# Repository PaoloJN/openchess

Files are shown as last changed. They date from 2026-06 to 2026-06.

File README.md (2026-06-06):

# OpenChess

A physical chess board with magnetic piece detection and corner-LED move
feedback. Plays online via Lichess and offline against Stockfish. ESP32-
powered, LiPo-battery / USB-C, with an SSD1306 OLED + 3 panel-mount
buttons for local UI.

**This is a one-off personal learning project, not a product.** The goal
is to learn through hands-on PCB design and build **one** chess board
that works first try. When it works on Paolo's desk, the project is done
— no v2, no scaling, no support burden. Design choices optimize for
first-build reliability and learning value over BOM cost, ergonomics for
volume, or production manufacturability.

This file is the project-level source of truth and entry point. For the
authoritative hardware design see [`hardware/DESIGN_NOTES.md`](hardware/DESIGN_NOTES.md);
for current progress see [`STATUS.md`](STATUS.md).

Last meaningful revision: **2026-06-06**.

---

## 1. What it does

| Capability | How |
|---|---|
| Detect pieces | 64× A3144 Hall sensors in an 8×8 grid under the playing surface; every piece carries a magnet |
| Indicate moves | 81× WS2812B RGB LEDs at the corners of the squares (9×9 grid) |
| Online play | Lichess Board API over WiFi |
| Offline play | Stockfish bot running on the ESP32 |
| Local UI | SSD1306 0.96" 128×64 OLED + 3 panel-mount buttons (POWER, MODE, SELECT) |
| Web UI | Captive-portal WiFi setup + web admin from the ESP32 (firmware feature) |
| Power | 1S LiPo (1500 mAh, protected) with USB-C charging via Seeed Lipo Rider Plus module |

---

## 2. System architecture

```
┌──────────────────────────────────────────────────────────────────┐
│                       MATRIX PCB (chessboard)                    │
│                                                                  │
│   front face:   64× A3144 Hall  +  81× WS2812B corner LEDs       │
│   back face:    J_CTRL (2×13 keyed socket)                       │
│                                                                  │
│                              ▲                                   │
│         board-to-board stack │  (no ribbon cable)                │
│                              ▼                                   │
│                                                                  │
│   ┌─────────────────────────────────────────────────────────┐    │
│   │                   CONTROLLER PCB                        │    │
│   │                                                         │    │
│   │   J_MAIN (2×13 keyed header)                            │    │
│   │   ESP32-DevKitC v4 socket                               │    │
│   │   M1 Seeed Lipo Rider Plus (USB-C + LiPo + 5V + 3V3)    │    │
│   │   U3 74AHCT125 level shifter                            │    │
│   │   U6 TBD62783A 8-ch column driver                       │    │
│   │   D2 SS14 Schottky (ESP32 power path)                   │    │
│   │   R1..R8 row pullups · R14/R15/C12 VBAT_MON divider     │    │
│   │   J3 (J_PANEL, JST XH 10-pin)                           │    │
│   └────────────────┬────────────────────────────┬───────────┘    │
│                    │                            │                │
│                    │ JST PH                     │ JST XH 10      │
│                    ▼                            ▼                │
│              ┌──────────┐         ┌─────────────────────────┐    │
│              │ LiPo 1S  │         │   PANEL COMPONENTS      │    │
│              │ 1500 mAh │         │   (flying leads, no PCB)│    │
│              │ protected│         │   OLED · POWER · MODE · │    │
│              └──────────┘         │   SELECT · USB-C        │    │
│                                   └─────────────────────────┘    │
│                                                                  │
└──────────────────────────────────────────────────────────────────┘
```

Two PCBs + one cable-mounted component group. The controller PCB
stacks directly underneath the matrix PCB via mating 2×13 connectors
(no ribbon cable); 4× M3 corner standoffs hold the stack at ~11 mm
spacing. The LiPo battery sits alongside the controller in the space
between the matrix back and the enclosure floor. Panel components are
panel-mount parts on flying leads, mounted in the enclosure side wall.

A visual rendering of the assembly lives at
[`docs/images/system-overview.html`](docs/images/system-overview.html).

---

## 3. Hardware

| Subsystem | Path | Summary |
|---|---|---|
| Matrix PCB | [`hardware/hardware-board/`](hardware/hardware-board/) | Passive: 64× A3144 + 81× WS2812B + per-LED caps + row bulk caps + entry cap + J_CTRL. 236 components. **Script-generated** schematic. |
| Controller PCB | [`hardware/hardware-controller/`](hardware/hardware-controller/) | Active: ESP32 socket, Lipo Rider Plus power module, 74AHCT125 level shifter, TBD62783A column driver, Schottky power-path diode, pullups, divider, connectors. **Hand-drawn** in KiCad GUI. |
| Panel components | (no PCB) | SSD1306 OLED module + 3× 12 mm panel-mount pushbuttons + USB-C panel-mount extension cable, on a flying-lead harness to the controller's J_PANEL. |

The **authoritative hardware design** lives in
[`hardware/DESIGN_NOTES.md`](hardware/DESIGN_NOTES.md). Highlights:

- **Connector contracts**: 2×13 keyed IDC for matrix↔controller, JST XH
  10-pin for controller↔panel — pin-by-pin tables in DESIGN_NOTES §3.
- **Power**: single Seeed Lipo Rider Plus module ($4) handles USB-C
  charging, 5V/2.4A boost, and 3V3/250mA — see DESIGN_NOTES §7.
- **GPIO map**: full table in [`docs/gpio-map.md`](docs/gpio-map.md).
- **BOM**: high-level in DESIGN_NOTES §9, prototype shopping list in
  [`docs/bom.md`](docs/bom.md).

---

## 4. Firmware

Forked from [joojoooo/OpenChess](https://github.com/joojoooo/OpenChess),
adapted for this board's 9×9 corner-LED layout and split-board IO. Runs
on the ESP32-DevKitC via PlatformIO.

What works unchanged upstream:

- Hall sensor matrix scan (rewired to our row/column nets)
- Lichess Board API client
- Stockfish bot
- WiFi captive portal + web admin
- OTA firmware updates
- Move history persistence to flash

What we adapt:

- LED count: 64 (squares) → 81 (corners), `board_driver.cpp`
- LED chain mapping: square-centered → corner-grid
- GPIO assignments: match [`docs/gpio-map.md`](docs/gpio-map.md)
- Display layer: 3 status LEDs → SSD1306 OLED via I²C
- Buttons: re-mapped to POWER / MODE / SELECT semantics
- Battery state-of-charge: ADC read on GPIO34 via the R14/R15 divider

See [`firmware/README.md`](firmware/README.md) for setup, build, and
adaptation notes.

---

## 5. Mechanical / enclosure

Enclosure CAD has not started — see [`mechanical/README.md`](mechanical/README.md)
for current state. Constraints from the hardware design:

- 4× M3 mounting holes per PCB; ~11 mm standoffs between matrix and
  controller.
- Side-wall cutouts: 1× transparent window for the OLED (~27×27 mm),
  3× 12 mm holes for the panel buttons, 1× rectangular cutout for a
  USB-C panel-mount jack (~10×8 mm), 1× pinhole or recessed access to
  the DevKitC's EN reset button, 1× cutout or removable panel for the
  DevKitC's micro-USB programming port.
- LiPo pouch (~50×35×6 mm for 1500 mAh) sits in the gap between the
  matrix back and the enclosure floor.

Magnet selection + chess piece assembly are open questions — to be
resolved with a 4×4 mini-matrix prototype before committing the full 8×8
fab.

---

## 6. Repository layout

```text
openchess/
├── README.md                  ← this file
├── STATUS.md                  ← current phase + next actions
├── CLAUDE.md                  ← durable project context for agents
├── WORKSPACE.md               ← workspace conventions
│
├── hardware/
│   ├── DESIGN_NOTES.md        ← authoritative hardware design
│   ├── README.md
│   ├── hardware-board/        ← matrix PCB (script-generated)
│   │   ├── SCHEMATIC_GUIDE.md
│   │   └── scripts/sch/
│   └── hardware-controller/   ← controller PCB (hand-drawn)
│       └── SCHEMATIC_GUIDE.md
│
├── firmware/
│   ├── README.md
│   ├── platformio.ini
│   └── src/
│
├── mechanical/
│   ├── README.md
│   ├── case/
│   ├── pieces/
│   └── fab/
│
├── docs/
│   ├── README.md
│   ├── assembly.md
│   ├── bom.md
│   ├── design-decisions.md
│   ├── gpio-map.md
│   ├── inter-board-connector.md
│   ├── kicad-routing-playbook.md
│   ├── images/
│   │   └── system-overview.html
│   └── archive/
│
└── references/                ← upstream projects + datasheets
```

---

## 7. Where to look

| If you want to… | Read this |
|---|---|
| See current progress + next actions | [`STATUS.md`](STATUS.md) |
| Understand the hardware design | [`hardware/DESIGN_NOTES.md`](hardware/DESIGN_NOTES.md) |
| Build the controller schematic | [`hardware/hardware-controller/SCHEMATIC_GUIDE.md`](hardware/hardware-controller/SCHEMATIC_GUIDE.md) |
| Reference matrix board components | [`hardware/hardware-board/SCHEMATIC_GUIDE.md`](hardware/hardware-board/SCHEMATIC_GUIDE.md) |
| Check connector pinouts | [`docs/inter-board-connector.md`](docs/inter-board-connector.md) |
| Check ESP32 pin assignments | [`docs/gpio-map.md`](docs/gpio-map.md) |
| Buy prototype parts | [`docs/bom.md`](docs/bom.md) |
| Read fixed design decisions | [`docs/design-decisions.md`](docs/design-decisions.md) |
| Layout / routing playbook | [`docs/kicad-routing-playbook.md`](docs/kicad-routing-playbook.md) |
| Build + assembly walkthrough | [`docs/assembly.md`](docs/assembly.md) |
| Visualize the assembly | [`docs/images/system-overview.html`](docs/images/system-overview.html) |
| Set up firmware build | [`firmware/README.md`](firmware/README.md) |
| Brief an agent session | [`CLAUDE.md`](CLAUDE.md) |

---

## 8. Build & assembly workflow

High level — full per-step instructions live in
[`docs/assembly.md`](docs/assembly.md).

1. **Source parts** — see DESIGN_NOTES §9. Long-lead items: Seeed Lipo
   Rider Plus, protected 1S LiPo, ESP32-DevKitC v4, A3144 (×64),
   WS2812B (×81), TBD62783A.
2. **Verify schematics ERC-clean** — matrix board via its scripts;
   controller hand-drawn in KiCad GUI.
3. **Lay out PCBs** — see [`docs/kicad-routing-playbook.md`](docs/kicad-routing-playbook.md).
   Consider panelizing the two PCBs onto one JLCPCB order to share fab
   cost.
4. **Fab + assemble** — JLCPCB SMD assembly for matrix components; hand-
   solder the Lipo Rider Plus module and DevKitC sockets on the
   controller (JLC doesn't assemble modules).
5. **Bring-up** — power the controller alone first, verify rails, then
   stack with the matrix. Smoke-test one matrix column before scanning
   the full 8×8.
6. **Flash firmware** — see [`firmware/README.md`](firmware/README.md).
   Adapt LED count + GPIO map.
7. **Validate** — 4×4 mini-matrix prototype first (open question, see
   STATUS.md) before committing the full 8×8 if magnet selection or
   scan timing is uncertain.

---

## 9. Status

For current phase, in-progress work, and next concrete actions, see
[`STATUS.md`](STATUS.md). For the design-affecting change log with
dates, see [`hardware/DESIGN_NOTES.md`](hardware/DESIGN_NOTES.md) §15.

---

## 10. Inspiration

- [Olivier Mercier's chessboard project](https://omerc.github.io/) — the
  physical smart-board concept this is loosely modeled on.
- [joojoooo/OpenChess](https://github.com/joojoooo/OpenChess) — firmware
  ancestor.

This redesign keeps the physical smart-board idea while using Hall
sensors, addressable LEDs, and a modular hardware split (matrix +
controller + flying-lead panel) to reduce PCB risk and make per-
subsystem testing easier.

---

## 11. License

Mixed license:
- Hardware (KiCad projects, schematics, board files): **CERN-OHL-S v2**
- Firmware: upstream's license (initially MIT from joojoooo/OpenChess)
- Documentation: **CC-BY-4.0**

See the `LICENSE-*` files at the repository root.

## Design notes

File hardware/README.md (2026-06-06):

# OpenChess Hardware

Clean split-board hardware workspace.

```text
hardware-board/      matrix board: Hall sensors, WS2812 LEDs, connector
hardware-controller/ controller board: ESP32, power, drivers, panel connector
hardware-control-panel/ physical side panel: buttons + status LEDs
```

The old top-level hardware projects were archived to
`../delete/old-hardware-2026-06-04/`.

Start with [DESIGN_NOTES.md](DESIGN_NOTES.md), then use each board's
`scripts/README.md` for generation steps.

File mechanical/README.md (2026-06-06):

# Mechanical

Mechanical work for the enclosure and magnetic chess pieces.

Current hardware is split into three boards:

- matrix board under the playing surface
- controller board in a serviceable enclosure area
- control panel mounted on the side by cable

Detailed CAD has not started. Use `hardware/DESIGN_NOTES.md` and the final PCB
layouts once available as the mechanical source of truth.

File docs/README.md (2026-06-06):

# OpenChess Docs

Active docs are for the current split-board hardware under `hardware/`.
Historical rev0.1 integrated-board notes live under `docs/archive/`.

## Active Docs

| File | Purpose |
|---|---|
| `../STATUS.md` | Current project state and next steps |
| `../hardware/DESIGN_NOTES.md` | Hardware decisions and board contracts |
| `inter-board-connector.md` | Matrix and control-panel connector pinouts |
| `gpio-map.md` | Provisional ESP32 GPIO plan |
| `bom.md` | Prototype BOM by board |
| `assembly.md` | Current expected build order |
| `design-decisions.md` | Why the design uses this architecture |
| `kicad-routing-playbook.md` | PCB layout/routing notes for the split boards |

## Archived Docs

`archive/rev0.1/` contains old single/integrated-board reviews and walkthroughs.
`archive/superpowers/` contains old generated plans and specs from prior directions.
Keep archived docs for history, but do not treat them as active implementation guidance.

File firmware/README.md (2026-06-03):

# Firmware

This directory will hold a fork of [joojoooo/OpenChess](https://github.com/joojoooo/OpenChess) adapted for the openchess PCB.

## Status

Not yet populated. See top-level `STATUS.md` for current project phase.

## Setup (when ready)

```bash
cd firmware/
git clone https://github.com/joojoooo/OpenChess.git .
# or, once forked:
# git submodule add https://github.com/<your-user>/OpenChess.git
```

## What needs adapting from upstream

joojoooo's `BoardDriver` assumes **64 LEDs under squares** (8×8). This board has **81 LEDs at corners** (9×9). Modify in `src/board_driver.h` and `src/board_driver.cpp`:

- `LED_PIN` → GPIO 32 (see `docs/gpio-map.md`)
- `NUM_ROWS`, `NUM_COLS` → 9, 9
- `LED_COUNT` → 81
- `ledIndexMap` / `DefaultRowColToLEDindexMap` → corner-grid mapping

Pin assignments are runtime-configurable via the web UI, so the GPIO map can be set after first boot rather than at compile time.

## What works upstream with no changes

- Hall sensor matrix scan via 74HC595 + PNP transistors
- Lichess Board API client (`chess_lichess.cpp`)
- Stockfish bot (`chess_bot.cpp`)
- ChessConnect for chess.com
- Move history persistence to flash (`move_history.cpp`)
- OTA firmware updates (`ota_updater.cpp`)
- WiFi captive portal + web UI (`wifi_manager_esp32.cpp` + `src/web/*.html`)

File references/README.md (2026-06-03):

# References

Read-only clones of upstream projects this build is derived from or compared against. Useful when working offline or for keeping the project self-contained.

**These are gitignored** — each clone has its own upstream remote and tracks its own history. They are not part of `chessboard-v2`'s git history.

## What's here

### `chessboard-v1-omercier/`

Olivier Mercier's original `Chessboard` project — the v1 design that inspired this rebuild. Reed switches + multiplexed LED matrix + separate controller box + touchscreen.

- Upstream: <https://github.com/omercier01/Chessboard>
- Useful for: the proven Lichess client firmware, the CAD reference (`Cad/circuit_ESP32.svg`, `Cad/notes.txt`), and understanding the design tradeoffs we changed in v2.

### `openchess-joojoooo/`

joojoooo's OpenChess — the firmware foundation that `firmware/` will fork from. Modern C++ codebase with persistence, OTA, web UI, full chess engine, Stockfish, ChessConnect.

- Upstream: <https://github.com/joojoooo/OpenChess>
- Useful for: reading current source while planning the 9×9 LED adaptation; cross-referencing pin assignments; checking what's runtime-configurable vs compile-time.

## Re-cloning

If `references/` is missing (fresh checkout) and you want it populated:

```bash
mkdir -p references && cd references
git clone https://github.com/omercier01/Chessboard.git chessboard-v1-omercier
git clone https://github.com/joojoooo/OpenChess.git  openchess-joojoooo
```

## Updating

These are static snapshots. To pull upstream changes:

```bash
cd references/openchess-joojoooo && git pull
cd references/chessboard-v1-omercier && git pull
```

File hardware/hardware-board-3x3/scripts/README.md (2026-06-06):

# hardware-board scripts

Scripted generators for the OpenChess **matrix board**.

This folder is also the template style for the later controller and control-panel
boards: keep board decisions in a small `config.py`, keep grid coordinates in
`geometry.py`, and put repeated KiCad S-expression mechanics in `parts.py`.

## Schematic generation

Run the schematic chunks in order:

```bash
for s in scripts/sch/[0-9][0-9]_*.py; do python3 "$s"; done
```

Each script writes one chunk to `build/sch/` and reassembles
`openchess-board.kicad_sch`.

| Script | Places |
|---|---|
| `01_skeleton.py` | Page setup, embedded symbols, functional boxes |
| `02_halls.py` | 64x A3144 Hall sensors, `U1..U64` |
| `03_leds.py` | 81x WS2812B LEDs, `D1..D81`, plus `C10..C90` decoupling |
| `04_bulks.py` | 9x row bulk caps, `C1..C9` |
| `05_j_ctrl.py` | Matrix/controller connector, `J1` |
| `06_led_decoup.py` | LED rail entry capacitor, `C91` |
| `07_test_mech.py` | Test pads, mounting holes, fiducials |
| `99_assemble.py` | Assembles existing chunks into the final schematic |

Matrix-board scope:

- Hall sensors
- Chess-square/corner LEDs
- LED decoupling and row bulk capacitance
- Matrix connector
- Test pads, mounting holes, fiducials

Not on this board:

- ESP32/controller logic
- Battery, charger, boost, switches, or controller-rail PWR_FLAGs
- Row pullups
- Status LEDs or user buttons

Those belong on the controller board or cable-mounted control-panel board.

## Shared modules

- `sch/config.py` is the electrical contract: nets, footprints, values, and
  `JCTRL_PIN_NETS`.
- `sch/geometry.py` is placement math only.
- `sch/parts.py` has reusable helpers for repeated schematic parts.
- `sch/_lib.py` is the low-level KiCad S-expression writer.

For a 4x4 prototype, make a variant by changing the matrix constants and
geometry in a copy of this structure. Do not edit generated `.sexp` chunks by
hand; change the scripts and regenerate.

## Conventions

- Close KiCad before running scripts.
- Reference designators are firmware/mechanical contracts.
- Nets connect by labels, not long schematic wires.
- Keep `+5V_LED` separate from controller logic rails.
- Matrix ERC uses schematic-only PWR_FLAGs on external `+5V_LED` and GND.
- Keep connector pinout changes in `config.JCTRL_PIN_NETS` first, then update
  controller-board scripts to match.

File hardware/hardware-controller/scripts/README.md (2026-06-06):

# hardware-controller scripts

Scripted schematic generator for the OpenChess controller board.

Run from `hardware/`:

```bash
for s in hardware-controller/scripts/sch/[0-9][0-9]_*.py; do python3 "$s"; done
```

Current generated chunks:

| Script | Places |
|---|---|
| `01_skeleton.py` | Page setup, embedded symbols, functional boxes |
| `02_j_main.py` | `J_MAIN` connector matching matrix `J_CTRL` |
| `03_row_pullups.py` | `R1..R8` 10k pullups from `S0..S7` to `+3V3` |
| `04_power_flags.py` | Schematic-only ERC flags for `+3V3`, `+5V_LED`, `GND` |
| `05_test_mech.py` | Testpoints, M3 holes, fiducials |

Pending chunks after part decisions:

- power input / charger / boost
- ESP32 module/devkit
- column drivers for `CA_PWR..CH_PWR`
- WS2812 data level shifter to `LED_DATA_5V`
- control-panel cable connector

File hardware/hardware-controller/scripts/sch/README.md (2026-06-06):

# DO NOT USE THIS DIRECTORY

These scripts are **archived and dangerous**. They use `99_assemble.py`
which **OVERWRITES** the hand-drawn `openchess-controller.kicad_sch`
file. Running any chunk script in here destroys your KiCad work.

The actual scripts are now under `../sch.DO_NOT_RUN.archived/` —
kept for reference but should never be executed.

For test-point/mounting-hole generation, use the **snippet generator**
under `../snippets/gen_test_mech.py` instead. That one generates a
separate `.kicad_sch` file you copy-paste from — it does NOT touch
the main controller schematic.

If you ever accidentally run an old chunk script:
1. The schematic is overwritten with just the chunk content
2. A backup is automatically saved to
   `openchess-controller.kicad_sch.backup_before_assemble`
3. Recover by:
   ```bash
   cp openchess-controller.kicad_sch.backup_before_assemble \
      openchess-controller.kicad_sch
   ```

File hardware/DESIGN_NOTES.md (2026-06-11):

# OpenChess Hardware Design Notes

**Source of truth.** This document captures the current, agreed-upon
design for the OpenChess hardware. Per-board build sheets live in each
board's `SCHEMATIC_GUIDE.md`; pin-level assignments live in
`docs/gpio-map.md`; cross-board cable contracts live in
`docs/inter-board-connector.md`. This file is the index and the
authoritative reference for the *design itself*.

Last meaningful revision: **2026-06-09** (paper-fit test surfaced three
issues that need addressing: 8×8 board oversized vs enclosure inner
frame, J_MAIN/J_CTRL pin-1 mirroring under board-flip, and ESP32
footprint mismatch — see §11 items 12–14).

---

## 1. What we're building

A physical chess board with magnetic piece detection and visual
feedback. Plays online via Lichess and offline against Stockfish.
Magnetic Hall sensors detect pieces; corner WS2812B LEDs indicate
moves. UI is an SSD1306 OLED + 3 panel-mount buttons. Powered by a
LiPo battery with USB-C charging.

**This is a one-off personal project**, not a product. The goal is:

- Learn through hands-on PCB design.
- Build **one** board that works first try.
- Optimize for first-build reliability over BOM cost.
- When it works on Paolo's desk, the project is done.

Design choices reflect this: we prefer well-tested daughterboard
modules over discrete switching regulators, accept higher unit cost in
exchange for lower risk, and skip "production" concerns like
manufacturability for volume, certification, or supply-chain
resilience.

**Core sensing**: 8×8 grid of DRV5032FC Hall-effect switches
(SOT-23, omnipolar) detects which squares have a magnet under them
(every chess piece carries one).

**Core display**: 9×9 grid of WS2812B RGB LEDs at the corners of the
squares; firmware lights them to indicate legal moves, threats, last
move, etc.

**Compute**: an ESP32-DevKitC v4 module (the off-the-shelf dev board)
plugged into the controller PCB via headers, runs WiFi/Bluetooth +
chess logic + UI.

---

## 2. Hardware split

**Two PCBs** + one cable-mounted component group:

```text
hardware/
├── hardware-board/         # passive matrix: 64 Halls + 81 WS2812 LEDs
└── hardware-controller/    # ESP32 socket, power, scan/driver ICs

(Panel components, no PCB)  # OLED + 3 panel-mount buttons on flying
                             # leads, mounted on the side of the enclosure
```

**Assembly layout** (decided 2026-06-05 from the user's mockup):

- Matrix PCB is the entire chessboard. Halls + LEDs on the **top face**;
  the back face is clean except for the J_CTRL stacking socket.
- Controller PCB **mounts inverted directly underneath the matrix board**
  via board-to-board stacking pin headers (J_MAIN ↔ J_CTRL). The
  controller's components (M1, U2 DevKit, U3, U6, etc.) face the
  enclosure floor; its **bare B.Cu back face faces up toward the
  matrix's B.Cu back face**. J_MAIN sits on the controller's B.Cu so
  its pins point up into the matrix's J_CTRL socket. No ribbon cable
  between them, and **no corner standoffs** — the controller hangs from
  the J_MAIN/J_CTRL mating alone, and the matrix's own mounting to the
  enclosure top frame carries the assembled weight.
- The LiPo battery sits **alongside the controller**, in the space
  between the matrix PCB's back and the enclosure floor.
- The panel components (OLED + 3 buttons + panel-mount USB-C) mount on
  **one side wall of the enclosure** via flying leads from J3 on the
  controller PCB.

**Why this split**:
- **Matrix board** is large (chess board sized) and has only passive
  parts → cheap 2-layer fab, optimized for sensor placement.
- **Controller board** has the active ICs (Lipo Rider Plus power module,
  level shifter, column driver IC, ESP32 socket) → small dense PCB.
- **Panel components live in the enclosure on flying leads** — the
  OLED module is mounted via standoffs or a 3D-printed bezel; the 3
  buttons are panel-mount pushbuttons through enclosure holes. All
  wired back to the controller's `J3` (J_PANEL) connector. No separate
  PCB.

The boards talk through two cable contracts (§3): a 26-wire ribbon
between matrix and controller, and a 10-wire harness from the
controller to the panel-mount components.

The original `hardware-control-panel/` PCB design was dropped on
2026-06-05 (panel components moved to flying leads) and archived to
`delete/hardware-control-panel-2026-06-05/`.

The older monolithic single-PCB design was archived to
`delete/old-hardware-2026-06-04/`. Do not reference that work.

---

## 3. Cross-board connector contracts

### 3.1 Matrix ↔ Controller — `J_CTRL` (matrix) ↔ `J_MAIN` (controller)

**Board-to-board stacking, 2×13 at 2.54 mm pitch. No ribbon cable.**
The controller PCB mounts **inverted** below the matrix PCB (components
facing the enclosure floor, bare B.Cu facing up). J_MAIN sits on the
controller's B.Cu, J_CTRL on the matrix's B.Cu, and they mate back-
to-back:

- **Controller side (`J_MAIN`)**: 2×13 **male pin header** on the
  controller PCB's **B.Cu (back)** face. When the controller is mounted
  upside-down under the matrix, those pins point up toward the matrix.
  Footprint: `Connector_PinHeader_2.54mm:PinHeader_2x13_P2.54mm_Vertical`
- **Matrix side (`J_CTRL`)**: 2×13 **female socket** on the matrix
  PCB's back face (B.Cu), pointing down toward the controller.
  Footprint: `Connector_PinSocket_2.54mm:PinSocket_2x13_P2.54mm_Vertical`

The two connectors mate naturally — different connector types prevent
mis-orientation. Still mark pin 1 with a silkscreen dot on both boards
for assembly clarity.

> **Matrix-side J1 pin numbering is mirrored relative to the controller's
> J1 contract.** The controller mounts **inverted** under the matrix
> (B.Cu-to-B.Cu mating), which mirrors each board's coordinate frame
> relative to the other. To keep electrical mating correct, the matrix's
> J1 footprint was manually mirrored in KiCad's PCB editor after the
> 3×3 layout script placed it (right-click J1 → Mirror → Mirror Around
> X Axis). The result: matrix J1's *pad numbers* are swapped within
> each odd-even pair vs the contract table below — e.g. matrix pin 2
> physically carries `+5V_LED`, matrix pin 1 carries `GND`, etc. The
> **nets at each physical pad position still mate correctly** with the
> controller's pin contract (controller pin 1 = `+5V_LED` after the
> flip lands on matrix pin 2 = `+5V_LED`, etc.).
>
> When reading the contract below, treat pin numbers as the controller's
> J_MAIN numbering. The matrix's J_CTRL pads carry the same nets but
> under swapped pin numbers; verify against the physical net at each
> pad in KiCad, not the pin number printed on the silkscreen.

Mechanical: **no mounting holes on either PCB and no corner standoffs**.
The board-to-board connector pair carries both signal and mechanical
load — the controller hangs from J_MAIN/J_CTRL alone. The matrix PCB
is what's actually bolted to the enclosure top frame; it supports the
controller's weight through the connector. This is acceptable because
the board pair is mated once and never unplugged in normal use, and
the controller weighs essentially nothing once the LiPo is moved
alongside it.

| Pin | Net | Direction |
|----:|-----|---|
| 1 | `+5V_LED` | controller → matrix |
| 2 | `GND` | both |
| 3 | `+5V_LED` | controller → matrix |
| 4 | `GND` | both |
| 5 | `+5V_LED` | controller → matrix |
| 6 | `GND` | both |
| 7 | `LED_DATA_5V` | controller → matrix |
| 8 | `GND` | both |
| 9 | `S0` | matrix → controller |
| 10 | `S1` | matrix → controller |
| 11 | `S2` | matrix → controller |
| 12 | `S3` | matrix → controller |
| 13 | `S4` | matrix → controller |
| 14 | `S5` | matrix → controller |
| 15 | `S6` | matrix → controller |
| 16 | `S7` | matrix → controller |
| 17 | `CA_PWR` | controller → matrix |
| 18 | `CB_PWR` | controller → matrix |
| 19 | `CC_PWR` | controller → matrix |
| 20 | `CD_PWR` | controller → matrix |
| 21 | `CE_PWR` | controller → matrix |
| 22 | `CF_PWR` | controller → matrix |
| 23 | `CG_PWR` | controller → matrix |
| 24 | `CH_PWR` | controller → matrix |
| 25 | `+5V_LED` | controller → matrix |
| 26 | `GND` | both |

Counts: 4× `+5V_LED`, 5× `GND`, 1× `LED_DATA_5V`, 8× row-sense,
8× column-power. Cable: 26-wire IDC ribbon, ≤ 20 cm preferred to limit
IR drop on `+5V_LED` and edge degradation on `LED_DATA_5V`.

### 3.2 Controller ↔ Panel components — `J_PANEL`

**1×10 polarized connector on the controller side** (recommended:
**JST XH 10-pin**). The other end of the cable terminates at the
discrete panel components (OLED module 4-wire pigtail, 3× panel-mount
button leads). There is no PCB on the panel side — see §6.

JST XH is the right pick because:
- Polarized (mechanically can't be plugged in backwards)
- Latching (won't pop out from cable flex)
- Crimp terminals for individual wires (flexible cable harness)
- Cheap (~$0.30 for the receptacle on the controller PCB)

| Pin | Net | Direction |
|----:|-----|---|
| 1 | `+3V3` | controller → panel (OLED + button pullup supply) |
| 2 | `GND` | both |
| 3 | `I2C_SDA` | bidirectional (ESP32 GPIO1 ↔ OLED) |
| 4 | `I2C_SCL` | controller → panel (ESP32 GPIO3) |
| 5 | `BTN_SELECT` | panel → controller (GPIO2, internal pullup) |
| 6 | `BTN_POWER` | panel → controller (GPIO36, external pullup on controller) |
| 7 | `BTN_MODE` | panel → controller (GPIO39, external pullup on controller) |
| 8 | `PANEL_SPARE` | reserved (was BTN_RESET — dropped) |
| 9 | `PANEL_SPARE2` | reserved |
| 10 | `GND` | both |

Buttons short their signal net to GND when pressed. `PANEL_SPARE*` pins
terminate at a single pin on the panel side — ERC will flag them as
single-pin nets; that's intentional (reserved for future expansion).

Reset is via the DevKitC's onboard EN button — no panel reset.

---

## 4. Matrix board (`hardware-board/`)

### 4.1 Scope (244 components total — 8×8; smaller scaled variant is 3×3)

| Group | Refdes range (8×8) | Refdes range (3×3) | Notes |
|---|---|---|---|
| Hall sensors | `U1..U64` | `U1..U9` | **DRV5032FC SOT-23** (TI, JLC Basic C527532). File-major: U1=A1, U_max=top-right corner. |
| WS2812B LEDs | `D1..D81` | `D1..D16` | Row-major top-down: D1=top-left, D_max=bottom-right |
| Per-LED decoupling caps (100 nF) | `C10..C90` | `C10..C25` | Number-matched to LEDs (D1↔C10, etc.) |
| Row bulk caps (47 µF) | `C1..C9` | `C1..C4` | One per row of LEDs, placed in **left margin** Y-aligned with each LED row |
| Matrix connector | `J1` (= J_CTRL) | `J1` | 2×13 female socket, board-to-board stacking on B.Cu; pin contract in §3.1 |
| Test points | `TP1..TP4` | `TP1..TP4` | `+5V_LED`, `GND`, `LED_DATA_5V`, `LED_DOUT_END` (manually placed) |
| Mounting holes | `MH1..MH4` | `MH1..MH4` | M3, four corners (manually placed) |
| Fiducials | `FID1..FID3` | `FID1..FID3` | Manually placed |

**C91 entry cap (470 µF) dropped 2026-06-08.** Row bulks provide enough capacitance — no more THT parts on the matrix board.

### 4.2 Board dimensions

`SQUARE_SIZE = 32 mm` (matches Paolo's folding chess board model — the
inner-frame cavity has 32 mm wood squares). `BOARD_MARGIN = 18 mm` from
the outermost chess-square corner to the PCB edge, intentionally 2 mm
under the model's 20 mm inner-frame margin so the PCB slides freely
inside the cavity with ~2 mm wiggle per side.

| Variant | Chess area | + 2× 18 mm margin | **Total PCB outline** | JLC tier |
|---|---|---|---|---|
| 3×3 test | 96 mm | + 36 mm | **132 × 132 mm** | ≤150×150 (~$10) |
| 8×8 full | 254 mm | + 28 mm | **282 × 282 mm** | ≤300×300 (~$30) |

The 10 mm outer fold/decorative edge of the folding board model is NOT
part of the PCB — the PCB sits inside the inner frame only.

### 4.3 Key decisions

- **DRV5032FC Hall switches** (TI, SOT-23, omnipolar, **open-drain**, 1.65–5.5 V):
  selected over the originally-planned A3144 because (a) omnipolar means
  the magnet orientation in chess pieces doesn't matter — either pole
  triggers the sensor; (b) SOT-23 is small and JLCPCBA-assembleable
  whereas A3144 in TO-92 is through-hole; (c) the pinout
  (1=VDD, 2=GND, 3=OUT) is identical to A3144, so the rest of the
  matrix routing is unchanged. The open-drain output mates correctly
  with the controller's R1..R8 pull-ups to +3V3 — sensor's 1 mA sink
  rating handles 3.3 V / 10 kΩ = 330 µA load.
- **WS2812B 5050 in row-major chain**: standard part, well-supported
  firmware libraries. Spec the exact variant (`WS2812B-2020` etc.)
  in the BOM — color order varies between sub-types (most are GRB).
- **Matrix board kept passive**: no power management, no logic. Every
  active part lives on the controller. Makes this PCB simple, robust,
  and unlikely to need revisions independent of the controller.
- **Mechanical mounting**: 4× M3 holes for chassis attach; 3× fiducials
  for assembly machine alignment if going JLCPCBA.

### 4.4 Layout conventions (PCB)

Set by `scripts/01_chess_grid.py`:

- **Hall sensors** (DRV5032FC SOT-23): at chess square centers (file × rank × 32 mm)
- **LEDs** (WS2812B): at the corners of the chess squares (LED_COLS × LED_ROWS grid)
- **LED decoupling caps** (100 nF 0805): 6 mm to the RIGHT of each LED's center (no overlap with the 5×5 mm WS2812B body)
- **Row bulks** (47 µF 1206): in the **LEFT margin**, 8 mm left of the chess area, Y-aligned with each LED row
- **J1 (J_CTRL)**: on **B.Cu** (back face), center of the bottom edge, rotated 90° (~33 mm wide × 5 mm tall), anchor shifted left by 15.24 mm so the BODY's geometric center lands at the board's X centerline

### 4.5 Maintenance approach

The matrix board's schematic is **script-generated** for halls + LEDs
+ LED decoupling caps only (see `hardware-board/scripts/sch/02_halls.py`
and `03_leds.py`). The `99_assemble.py` is a **merger** that preserves
manual additions (J1 connector, MH, FID, TP, PWR_FLAGs, row bulks) by
UUID prefix — so running scripts after editing in KiCad GUI is safe.
The PCB layout (`scripts/01_chess_grid.py`) positions halls, LEDs,
LED decoupling caps, row bulks, and J1; everything else stays where
the user dragged it.

The 3×3 test board (`hardware-board-3x3/`) is a parameterised clone
of the 8×8 with `MATRIX_COLS = MATRIX_ROWS = 3`. Use it as the
first-fab validation board before committing to the 8×8.

---

## 5. Controller board (`hardware-controller/`)

### 5.1 Scope

| Group | Refdes | Notes |
|---|---|---|
| ESP32 socket | `U2` | `Espressif_Official:ESP32-DevKitC` module symbol; mates to the 38-pin DevKitC v4 plugged into female headers |
| Matrix connector | `J1` (= J_MAIN) | 2×13 keyed IDC, mirrors J_CTRL |
| Row pullups (10 k) | `R1..R8` | `S0..S7` to `+3V3` |
| LED data series resistor (33 Ω) | `R11` | Damping on `LED_DATA_5V` output |
| Level shifter | `U3` | 74AHCT125 SOIC-14; gate A active, B/C/D tied off |
| 74AHCT125 decoupling | `C5` | 100 nF |
| Column driver IC | `U6` | **TBD62783A** 8-channel high-side P-MOSFET array, DIP-18 or SOIC-18W |
| Column driver bypass | `C11` | 100 nF |
| **Power module** | **M1** | **Seeed Lipo Rider Plus (Charger/Booster) — product 106990290** ($4 on DigiKey/Mouser). USB-C input, charges 1S LiPo, outputs 5V/2.4A and 3.3V/250mA simultaneously. Mounted as a daughterboard via 1×8 pin header on the controller PCB. Symbol: stock `Connector_Generic:Conn_01x08` with manually-labeled pin nets per the silkscreen (1=3V3, 2=EN, 3=GND, 4=5V, 5=GND, 6=BAT, 7=GND, 8=USB). Footprint: `LipoRiderPlus:MODULE_106990290` (SnapEDA model installed locally at `hardware-controller/lib/LipoRiderPlus.pretty/`). The SnapEDA symbol file is intentionally NOT installed because its pin-number-to-name mapping is reversed from the silkscreen. LiPo plugs into M1's onboard JST 2.0; USB-C charges via M1's USB-C jack. |
| ESP32 power path | `D2` | **Schottky diode (SS14)** in `D_SMA` between `+5V_LED` and DevKit pin 19 — lets the battery power the DevKit's onboard AMS1117 → ESP32 internal 3V3. Pad 2 (anode) on `+5V_LED`, pad 1 (cathode, stripe) on DevKit pin 19 (forward direction). Protects against backfeed when both USB-C and DevKit USB are plugged in simultaneously. |
| Battery monitor | `R14` (220 k), `R15` (100 k), `C12` (100 nF) | Voltage divider on M1 pin 6 (`BAT` raw battery pad). Junction at ~0.94 V (empty) to 1.31 V (full) → `VBAT_MON` → ESP32 GPIO34 (ADC1_CH6). |
| +5V_LED bulk caps | `C1, C2` | 10 µF each — at M1's 5V output entering our `+5V_LED` rail |
| Panel connector | `J3` (= J_PANEL) | 1×10 JST XH |
| Panel button pullups | `R36, R37` | 10 k for BTN_POWER, BTN_MODE (input-only GPIOs) |
| Test points | _(none placed)_ | Probe the controller's component pads or pin headers directly for bringup. M1 itself exposes 3V3/5V/GND/BAT/USB/EN on its silkscreen-labeled pads. |
| Fiducials | `FID1..FID3` | For JLCPCBA. **No mounting holes** — controller is held by J_MAIN/J_CTRL mating + matrix's enclosure mount; see §3.1 and §10.3. |

**Parts dropped** from earlier discrete power designs (BQ24074, TPS63060,
F1/D1/Q1, USB-C connector, LiPo connector, all their passives) AND from
the brief PowerBoost 1000C plan (M1 + the AP2112K LDO + C3 + C4): now
all consolidated into M1 (Lipo Rider Plus) + D2 (Schottky). Lipo Rider
Plus's 3V3 output replaces the AP2112K LDO entirely.

### 5.2 Maintenance approach

The controller schematic is being **hand-drawn in KiCad GUI**. Scripts
are archived under `scripts/sch.archived/`. Every component is
documented in `hardware-controller/SCHEMATIC_GUIDE.md` with exact
pin-by-pin connections.

---

## 6. Panel components (no PCB — flying leads)

The panel is **not a PCB**. It's three discrete components wired
directly back to the controller via the `J3` (J_PANEL) connector.
Each component is physically mounted in the enclosure wherever the
user-facing layout requires.

### 6.1 Bill of components (≈ 5 items)

| Component | Quantity | What | Mounting |
|---|---:|---|---|
| SSD1306 0.96" 128×64 I²C OLED module | 1 | Display (mode, battery, game state, menu) | M2 standoffs through the module's 4 mounting holes, OR a 3D-printed bezel with snap-fit, OR double-sided tape behind a transparent enclosure window |
| Panel-mount momentary pushbutton (12 mm tactile, e.g. PBS-110) | 3 | POWER, MODE/NAV, SELECT | Threaded shaft through a 12 mm hole in the enclosure; nut on the back. Solder leads to the two terminals on each. |
| 10-conductor stranded wire harness | 1 length (~30 cm) | Connects all panel components back to controller `J3` | Crimped JST XH receptacle on the controller end; bare leads tinned and soldered to OLED pads + button terminals on the panel end |
| JST XH 2.54 mm 10-pin housing + crimp pins | 1 set | Connector to plug into controller's `J3` | Already on hand — crimp tool not needed to buy |
| Optional: 4.7 kΩ I²C pullup resistors | 2 | If the OLED module's onboard pullups aren't enough for the 30 cm cable | Solder inline on the harness OR on the OLED's solder pads to `+3V3` |

### 6.2 Wiring map

| `J3` pin | Net | Wire goes to |
|---:|---|---|
| 1 | `+3V3` | OLED VCC pin |
| 2 | `GND` | OLED GND pin + button COM lead (if buttons share a common ground line) |
| 3 | `I2C_SDA` | OLED SDA pin |
| 4 | `I2C_SCL` | OLED SCL pin |
| 5 | `BTN_SELECT` | SW3 (SELECT) — one terminal |
| 6 | `BTN_POWER` | SW1 (POWER) — one terminal |
| 7 | `BTN_MODE` | SW2 (MODE) — one terminal |
| 8 | `PANEL_SPARE` | _(unused; leave wire unterminated or omit)_ |
| 9 | `PANEL_SPARE2` | _(unused; leave wire unterminated or omit)_ |
| 10 | `GND` | Button common (other terminal of each button shorts to this) |

In practice, each button is wired with one lead to its signal pin
(`BTN_*` on the harness) and the other lead to GND. You can chain
the GND lead between buttons or use individual GND wires; either
works.

### 6.3 UX direction

Three buttons + the OLED. The OLED shows:
- Current mode (Lichess / Stockfish / Solo / Demo)
- Game state (whose move, opponent name, clock if applicable)
- Battery state-of-charge percentage (from `VBAT_MON` ADC reading via M1 pin 6 → R14/R15 divider → GPIO34)
- WiFi / connection status
- Last move notation, menu items during navigation

Buttons:
- **POWER**: long-press toggles power state (firmware-defined)
- **MODE/NAV**: short-press cycles modes, long-press = back/cancel
- **SELECT**: confirms a menu choice

Reset is via the DevKitC's onboard EN button. The enclosure can expose
this as a recessed pinhole if needed.

### 6.4 Assembly notes

- The wire harness is the most labor-intensive part of the build —
  ~30 min to crimp 10 JST XH terminals, solder OLED pigtail, solder
  button leads. Worth it: no panel PCB to design or fab.
- Use **panel-mount buttons** (PBS-110 or similar 12 mm tactile with
  threaded shaft + nut), not SMD/THT tactile buttons. They're designed
  to mount through an enclosure hole with screw retention.
- The OLED module has a fixed pin order on its 4-pin header. **Verify
  the module's pin order before wiring** — cheap modules ship as
  `VCC/GND/SCL/SDA` or `GND/VCC/SCL/SDA`. A 1-minute multimeter check
  saves a debugging session.
- The two `PANEL_SPARE*` wires can be omitted from the harness if you
  want fewer wires; they were reserved for future expansion (rotary
  encoder, buzzer, haptic motor).

---

## 7. Power architecture

### 7.1 Block diagram

```
                                 ┌──────────────────────────────────────┐
USB-C  ──────→                    │                                      │
                                  │   Seeed Lipo Rider Plus (M1)         │
LiPo (JST 2.0) ←───→              │   ──────────────────────────────────  │
                                  │   - USB-C charger (up to 2 A)         │
                                  │   - 5V/2.4A boost out (USB-A + pad)   │
                                  │   - 3.3V/250 mA always-on rail        │
                                  │   - Slide switch: OFF / 5V / ON       │
                                  └─┬────────┬────────┬────────┬────────┬──────┘
                                    │        │        │        │        │
                                    ▼        ▼        ▼        ▼        ▼
                                 5V (4)  3V3 (1)   GND      BAT (6)  (other pads NC)
                                                              │
                                                              ▼
                                                         R14 (220k) ── R15 (100k) ── GND
                                                                    │
                                                                    └─→ VBAT_MON → ESP32 GPIO34 (ADC1_CH6)
                                    │        │
                                    │        ▼
                                    │      +3V3 → ESP32 (via DevKit), panel rail, pullups, OLED via cable
                                    │
                                    ▼
                                +5V_LED  (regulated ~5.1 V)
                                    │
              ┌─────────────────────┼─────────────────────┬───────────────┐
              │                     │                     │               │
              ▼                     ▼                     ▼               ▼
           C1, C2                D2 Schottky            TBD62783A      74AHCT125
         (10µF bulk)         (anode at +5V_LED,         (U6) VCC      (U3) VCC
                              cathode to DevKit pin 19)
                                    │
                                    ▼
                              DevKit pin 19 (5V input)
                                    │
                                    └─→ DevKit's onboard AMS1117 → ESP32 +3V3 (DevKit-internal only)
```

### 7.2 Behavior

- **USB-C plugged in**: M1 charges the LiPo (up to 2 A) AND sources the 5V/3V3 outputs simultaneously. Our `+5V_LED` rail sees ~5.1 V; `+3V3` net sees 3.3 V from M1's internal LDO.
- **USB-C unplugged**: M1 sources 5V and 3V3 from the LiPo via internal boost + LDO. Board runs from battery until M1's UVLO or the LiPo's BMS cuts off.
- **Battery dead, USB-C plugged in**: M1 powers all rails from USB while charging the battery in parallel. Board boots immediately.
- **5V output enable**: M1 has a physical OFF / 5V / ON slide switch + an EN pin in the header. We use the slide switch in the "ON" position and leave the EN pin floating. The 5V rail is on whenever the module has power (USB or battery).
- **ESP32 powering**: D2 (Schottky) connects `+5V_LED` to the DevKit's pin 19 (5V input). The DevKit's onboard AMS1117 regulator then produces 3V3 internally for the ESP32. D2 blocks backfeed when the DevKit's own USB micro-B is also plugged in (e.g. during programming).
- **Battery state-of-charge monitoring**: a 220 k / 100 k voltage divider taps M1's pin 6 (raw battery `BAT`) and feeds the scaled voltage to ESP32 GPIO34 (ADC1_CH6) as `VBAT_MON`. Firmware reads this with `esp_adc_cal_*` for accurate SOC and shows battery % on the OLED. (M1 also has a 4-segment LED indicator on the daughterboard itself for at-a-glance status, though it requires an enclosure cutout.)
- **Battery polarity**: M1's JST 2.0 connector is mechanically polarized; a reputable LiPo's pre-attached JST 2.0 cable will plug in correctly.

### 7.3 Current budget (estimated)

| Load | Typical | Peak |
|---|---:|---:|
| ESP32 with WiFi | 80 mA | 300 mA |
| 81 WS2812B LEDs (firmware-limited brightness) | 100–500 mA | 5 A (white-flood) — **do not allow in firmware** |
| 8 active Hall sensors per scan column | 50 mA | 80 mA |
| 74AHCT125 + TBD62783A logic | 10 mA | 30 mA |
| OLED panel | 15 mA | 25 mA |
| **Total** | **~250–700 mA** | **bounded by M1's 2.4 A boost output + USB-C input current** |

Firmware MUST cap simultaneous LED brightness. The Lipo Rider Plus is
rated for **5V/2.4A** continuous on its 5V output, which sets the
ceiling — comfortably above our worst case.

### 7.4 Protected battery requirement

The LiPo cell should be a **protected cell** (built-in BMS PCB attached
to the cell) for safety:

- The Lipo Rider Plus has internal UVLO that cuts off below ~3.0 V —
  this prevents over-discharge during normal operation.
- But a *protected* cell adds a hard BMS that also catches short-
  circuit conditions, over-charge if the module fails, and
  over-discharge below the module's UVLO if the cell self-discharges
  while disconnected.
- Cheap unprotected cells from AliExpress will work but carry a small
  risk of thermal runaway under fault. Pay the $2 extra for a
  protected pack.

**Battery format**: 1S LiPo, 1000–2000 mAh, with JST PH 2-pin cable
pre-attached. Available from Adafruit, SparkFun, Pimoroni, Pololu,
and reputable AliExpress sellers.

---

## 8. GPIO map (summary)

Full table is in `docs/gpio-map.md` — that file is also a source of
truth for pin assignments. Highlights:

| Function | ESP32 GPIO | DevKitC pin |
|---|---:|---:|
| WS2812 data (3V3, pre-level-shift) | 32 | 7 |
| Row sense `S0..S7` | 4, 16, 17, 18, 19, 21, 22, 23 | 26..37 |
| Column drive `COL_DRV_A..H` (to TBD62783A) | 13, 14, 27, 26, 25, 33, 5, 15 | 15..29 |
| I²C SDA (to OLED) | 1 (TX0 repurposed) | 35 |
| I²C SCL (to OLED) | 3 (RX0 repurposed) | 34 |
| BTN_SELECT | 2 | 24 |
| BTN_POWER (input-only) | 36 (SVP) | 3 |
| BTN_MODE (input-only) | 39 (SVN) | 4 |
| `VBAT_MON` (analog) | 34 (input-only, ADC1_CH6) | 5 |
| EN (reset, DevKit onboard button) | EN | 2 |
| Reserved | 35 (input-only, = PANEL_SPARE) | 6 |

> Note: `VBAT_MON` is the analog battery monitor signal. A voltage
> divider (R14 220k + R15 100k + C12 100nF filter) on M1's pin 6
> (raw `BAT` pad) feeds GPIO34. Firmware uses `esp_adc_cal_*` for
> accurate readings — multiply the calibrated ADC mV by 3.2 to recover
> battery voltage.

**Pin usage notes:**

- Flash pins (GPIO 6–11) are explicit `no_connect`.
- DevKitC pins 1 (3V3 out) and 19 (5V out) are `no_connect` to avoid
  LDO contention with our AP2112K.
- UART0 (GPIO1/3) is **sacrificed** for the I²C bus — no serial debug
  on the DevKitC's onboard USB-UART during normal operation. Flashing
  still works because the bootloader uses UART0 only during reset.
- Boot-strap pins in use: GPIO5, GPIO15 (column drives — must be HIGH
  at boot; brief boot HIGH harmlessly turns columns G/H on for ~10 ms
  before firmware runs), GPIO2 (BTN_SELECT — must be LOW or floating
  at boot; button released = floating high through internal pullup is
  fine), GPIO12 NC (must be LOW at boot — NC satisfies this).

---

## 9. Key BOM (controller-side highlights)

| Part | Purpose | Approx unit cost |
|---|---|---:|
| **Seeed Lipo Rider Plus (Charger/Booster)** | USB-C charging + 5V boost + 3V3 rail, all-in-one daughterboard | $4 (DigiKey) |
| Schottky diode (SS14 or BAT60A) | D2 — DevKit pin 19 ← +5V_LED protection | $0.10 |
| 74AHCT125 (SOIC-14) | WS2812 level shifter | $0.50 |
| TBD62783A (DIP-18 or SOIC-18W) | 8-ch column driver | $1.00 |
| SSD1306 0.96" OLED module | Panel display | $2.00 |
| Protected LiPo 1500 mAh | Battery | $6.00 |
| ESP32-DevKitC v4 | Main compute | $8.00 |
| DRV5032FC Hall × 64 (SOT-23, omnipolar) | Matrix sensing | $0.50 each, ~$32 total |
| WS2812B × 81 | Matrix display | $0.05 each, $4 total |
| Female headers (controller sockets + module sockets) | Module + DevKit mounting | ~$3 total |
| **USB-C panel-mount extension cable** | Routes M1's onboard USB-C jack to the enclosure wall — plug into M1, screw the panel-mount end into the enclosure | $3–8 (AliExpress/Amazon) |

The Lipo Rider Plus is hand-soldered onto the controller PCB via
through-hole headers — JLCPCB does NOT assemble modules, only
individual components. The controller PCB itself can still be
JLC-assembled for the components around the module.

Per-board fab on JLCPCB: ~$5/board × 3 designs × min 5 boards each =
~$75. Consider **panelizing the three designs onto one panel** to cut
fab cost.

---

## 10. Mechanical and cabling

### 10.1 Connectors

| Connector | Function | Pick |
|---|---|---|
| J1 (controller J_MAIN) | Board-to-board to matrix (placed on controller B.Cu; mating face points up because the controller mounts inverted) | 2×13 **male pin header**, vertical (`PinHeader_2x13_P2.54mm_Vertical`) |
| J1 (matrix J_CTRL) | Board-to-board to controller (back side of matrix, mating face down) | 2×13 **female socket**, vertical (`PinSocket_2x13_P2.54mm_Vertical`) |
| J3 (controller J_PANEL) | 10-wire harness to panel components | **JST XH 10-pin** receptacle |
| M1 (Lipo Rider Plus module header on controller) | Mounts the Seeed Lipo Rider Plus | 1×8 female header, 2.54 mm pitch (matches module's edge pads) |
| Battery → Lipo Rider Plus | LiPo cable | JST 2.0 2-pin (on the module itself; not on controller PCB) |
| USB-C charging access | Routes M1's onboard USB-C to enclosure wall | Panel-mount USB-C extension cable (~$5) |
| DevKitC sockets (controller) | ESP32 plug-in | 2× 1×19 female header, 25.4 mm row pitch |

USB-C, the LiPo JST 2.0 connector, and the 4-segment battery LED
indicator all live on the Lipo Rider Plus daughterboard (M1), not on
the controller PCB itself. The USB-C is routed to the enclosure wall
via the panel-mount extension cable.

### 10.2 Cables

- **No ribbon cable between matrix and controller** — they stack
  directly via mating pin header + socket. Zero IR drop on `+5V_LED`,
  zero signal-integrity issues on `LED_DATA_5V`.
- **Panel harness**: 10-wire stranded multi-conductor (24 AWG, ribbon
  or just bundled), ~15–20 cm. Twist the I²C pair with GND for noise
  immunity. The cable is the weak link for I²C reliability — keep
  speed at 100 kHz, not 400 kHz. Crimp JST XH receptacle on the
  controller end; bare leads solder to OLED + buttons on the panel
  end.
- **Battery cable**: pre-attached on protected LiPo packs; plugs into
  the Lipo Rider Plus module's JST 2.0 socket.
- **USB-C panel-mount cable**: ~15–30 cm internal, with male USB-C on
  one end (into M1's onboard USB-C jack) and panel-mount female USB-C
  on the other (into the enclosure wall).

### 10.3 Enclosure considerations

**Internal layout** (from the user's mockup, locked 2026-06-05):

- The matrix PCB is the chessboard top surface. The enclosure has a
  frame around the matrix PCB edges; the matrix PCB itself is exposed
  on the top face for the chess pieces to sit on.
- The controller PCB mounts **inverted** directly underneath the matrix
  (components facing the enclosure floor; bare B.Cu facing up toward
  the matrix's B.Cu), offset toward one edge (the same edge as the
  side panel). It is held in place **only** by the J_MAIN/J_CTRL
  stacking connector — no standoffs, no mounting holes. The matrix's
  enclosure-frame mount carries the assembled weight.
- The LiPo battery sits **alongside the controller** in the empty
  space between the matrix PCB's back and the enclosure floor. Reserve
  ~50 × 50 mm × 8 mm floor area, attached via double-sided tape or a
  3D-printed battery cradle. **Don't sandwich it between the matrix
  and controller PCBs** — heat dissipation + swelling-safety reasons.
- The user-facing panel mounts on one side wall of the enclosure (the
  same side as the controller's offset). The panel contains: OLED
  window, 3 button holes, USB-C panel-mount port.

**Enclosure cutouts and access**:

- DevKitC's onboard EN (reset) button needs to be accessible — leave
  a pinhole in the bottom of the enclosure aligned with the button.
- DevKitC's onboard USB micro-B is used for programming — needs a
  cutout or removable bottom panel. Easiest for a one-off build: a
  removable bottom plate so you can plug in for programming.
- **USB-C charging port**: routed from M1's onboard USB-C jack via
  the panel-mount extension cable to the side panel. Plan a ~10 mm ×
  8 mm rectangular cutout on the side panel for the cable's flange +
  2 small screw holes (~M2) to mount it.
- **OLED window**: module is ~27 × 27 mm; needs a transparent (or
  open) cutout in the side panel. Module mounts behind the cutout via
  M2 standoffs or a 3D-printed bezel.
- **3 button holes**: 12 mm clearance each (for the panel-mount
  pushbuttons' threaded shafts), evenly spaced on the side panel
  alongside the OLED.
- **Matrix PCB**: planned 4 M3 mounting holes at its corners attach to
  enclosure standoffs holding it flush with the enclosure top frame.
  _(Not yet present on the 3×3 prototype PCB; required on the full 8×8.)_
- **Controller PCB**: **no mounting holes by design**. It hangs from
  J_MAIN/J_CTRL onto the matrix's B.Cu side. The matrix is what's
  bolted to the enclosure; the controller comes along for the ride.

**Vertical stack from bottom to top of enclosure**:

```
Enclosure floor
    ↑ (any vertical space for cable routing)
LiPo battery (8 mm thick, alongside controller)
                                                       Controller PCB (inverted)
                                                       components face DOWN
                                                       bare B.Cu face UP
                                                            ↑
                                                       J_MAIN ↔ J_CTRL mating
                                                       (only point of contact)
                                                            ↑
                                                       Matrix PCB (chessboard)
                                                       components face UP
                                                            ↑
                                                       Enclosure top frame
                                                       (matrix bolts here)
```

---

## 11. Known issues and verification items

These are things we know about but haven't fully resolved. None block
fab, but they need attention during bring-up:

1. **DRV5032FC Hall settling delay**: After a column is energized, the
   sensor output needs a few µs to stabilize. Firmware must wait between
   "set column HIGH" and "read row" — ~10 µs is safe (DRV5032FC's
   typical output response time is ≤ 1 µs at 5 V; 10 µs gives slack
   for column-rail charging through the TBD62783A).
2. ~~A3144 unidirectional sensitivity~~ — **no longer an issue.**
   DRV5032FC is omnipolar, so chess pieces can carry either magnet
   pole and they trigger the same way. No need to spec piece magnet
   orientation.
3. **WS2812B variant**: BOM must say `WS2812B-2020` (or whichever
   exact part). Color order varies (most are GRB). Firmware must
   match.
4. **ESP32 ADC nonlinearity** at low voltages: battery monitor at 3.0 V
   gives 0.94 V at ADC — near the noisy end. Use `esp_adc_cal_*` APIs
   for calibrated readings (~50 mV accuracy instead of 200 mV).
5. **PowerBoost switching EMI**: the PowerBoost 1000C contains a
   synchronous boost converter (TPS61090) that switches at ~700 kHz.
   Generally well-filtered on the module itself, but if WiFi RX
   sensitivity is poor in testing, add a ferrite bead + cap on the
   `+5V_LED` line where it leaves the module.
6. **I²C over panel cable**: 30 cm flying lead with default 4.7 kΩ
   pullups may be slow. If OLED writes are unreliable, drop pullups
   to 2.2 kΩ on the panel board.
7. **SSD1306 module pinout variability**: cheap modules ship as
   `VCC/GND/SCL/SDA`, `GND/VCC/SCL/SDA`, or with SDA/SCL swapped.
   Buy 5 from one seller; verify with a multimeter before committing
   PCB.
8. **Inter-board cable IR drop**: at peak LED current the 26-wire
   ribbon to the matrix can drop 100–500 mV on the +5V_LED rail.
   Mitigation: short cable, firmware brightness limit. Already designed
   in but worth checking with the scope.
9. **BTN_SELECT held during reset**: GPIO2 must be LOW/floating at
   boot. Pressing SELECT during DevKitC EN-button reset could confuse
   the bootloader. Workaround: just don't hold SELECT during reset.
   Not a hardware fix.
10. **Lipo Rider Plus single-point-of-failure**: if M1 dies, charging,
    +5V_LED, and +3V3 all go away — board is dead. Mitigation: M1
    is a separate daughterboard, so replacing it is easy (desolder
    headers, swap in a new $4 board). Cheaper than diagnosing a
    discrete power chain.
11. **Boot-time column glitch**: GPIO5 and GPIO15 must be HIGH at boot
    (strapping). They drive `COL_DRV_G` / `COL_DRV_H` into TBD62783A
    → columns G/H are briefly powered ~10 ms during boot. Electrically
    harmless (no firmware scanning yet). Plan for a ~50 mA boot blip.

### Paper-fit test findings (2026-06-09)

Discovered when printing the controller, 3×3, and 8×8 PCBs at 1:1 on
paper and physically checking fit + alignment against real parts and
the target folding chess board.

12. ~~8×8 matrix doesn't fit the chess board's inner frame.~~
    **Resolved 2026-06-10.** Original `SQUARE_SIZE = 32 mm` +
    `BOARD_MARGIN = 18 mm` gave a 292 × 292 mm board that
    overhung the cavity. Paolo then measured the folding board's
    actual playing area: **10 in × 10 in = 254 × 254 mm**, so the
    chess squares are exactly **1.25 in = 31.75 mm** each.
    Updated to `SQUARE_SIZE = 31.75 mm` (matches the wood) and
    `BOARD_MARGIN = 14 mm` (trimmed from 18 to fit the inner-frame
    cavity with wiggle room). New 8×8 size: **282 × 282 mm**.
    Synced in `scripts/01_chess_grid.py` and `scripts/02_route.py`
    (constants are duplicated; both must stay at 31.75/14). 3×3 not
    changed — already fabricated.

13. ~~J_MAIN/J_CTRL pin-1 mirroring under board-flip.~~ **Resolved
    2026-06-09.** When the controller mounts inverted (B.Cu facing up)
    to mate with the matrix's B.Cu, each board's coordinate frame is
    mirrored relative to the other — pin 1 of the controller J1 lands
    on the opposite corner from pin 1 of the matrix J1, scrambling
    net assignments per physical pad. **Fix applied:** the matrix's
    J1 footprint was manually mirrored in KiCad PCB editor (select J1
    → right-click → Mirror → Mirror Around X Axis). This swaps the
    row assignment so each net flows to the physically-correct pad
    after the controller flip. Side effect: matrix J1 pad numbering
    is now swapped within each odd-even pair vs the contract in §3.1
    (matrix pin 1 = GND, matrix pin 2 = +5V_LED, etc.) — but nets at
    each physical pad position match the controller correctly.
    Documented in §3.1. Same fix must be re-applied to the 8×8 matrix
    after its layout script runs (the script doesn't auto-mirror J1).

14. **ESP32 footprint doesn't match the physical DevKitC on hand.**
    The `Espressif:ESP32-DevKitC` footprint used on the controller
    PCB does not line up with the actual ESP32 module Paolo bought.
    Two paths forward, neither great:
    - **(a) Buy a different ESP32-DevKitC** whose pinout/dimensions
      match the existing footprint. Cheap (~$8), no PCB rework.
    - **(b) Swap the footprint** in KiCad to one matching the
      module Paolo has. Free in BOM but **requires re-routing every
      trace into U2** — a lot of unwanted rework.
    **Preferred:** path (a). Document the exact DevKitC variant
    (manufacturer + version) that fits the current footprint in the
    controller's `SCHEMATIC_GUIDE.md` so a future order can't get it
    wrong again. Re-verify against the printed footprint before
    ordering.

15. **DRV5032FC SOT-23 package looks tiny — is that a problem?**
    Short answer: **no, not for sensing.** Hall-sensitivity is set
    by the silicon die's specified Bop/Brp thresholds (per the
    DRV5032FC datasheet), **not by the physical package size**. A
    SOT-23 with the same die as a larger package detects magnets
    the same way over the same range. The bigger A3144 TO-92 we
    originally specced wasn't more sensitive — just more
    hand-handleable.
    What the small package **does** mean in practice:
    - **Easy to lose / hard to place by hand.** Buy 2× the quantity
      you need (~$10 extra on AliExpress) so a dropped part isn't a
      blocker. Already on the 3×3 PCBA so JLC handles placement —
      this only matters for any future hand-builds.
    - **Tighter placement tolerance.** The sensor's active area is
      smaller than the chess square. If JLC's pick-and-place drifts
      by 1–2 mm relative to the silkscreen, the sensor still ends
      up well inside the square's footprint. Not a concern.
    - **The real sensing question** is whether the magnet you pick
      generates enough field at the board-to-piece distance to clear
      the DRV5032FC threshold. This is the open question in §13 —
      will be answered empirically once the 3×3 is in hand and Paolo
      can test magnets against actual sensors. **Don't pre-commit to
      a magnet size before that test.**

---

## 12. Firmware-side caveats (heads-up for the firmware author)

- **No serial debug on DevKitC USB**: UART0 (GPIO1/3) is now the I²C
  bus. Use JTAG, or pick alternative GPIOs for a separate UART, if
  you need printf-style debug.
- **Matrix scan timing**: ~5 µs Hall settling between column energize
  and row read. Don't scan faster than ~1 kHz.
- **Limit LED brightness**: at full white, 81 WS2812Bs draw ~5 A,
  blow the polyfuse, brown out the system. Hard-cap brightness in
  firmware (e.g., max 30% white or rate-limit total Watts).
- **Battery state-of-charge** is an analog ADC reading on GPIO34
  (`VBAT_MON` net). The R14/R15 divider scales raw battery voltage
  (3.0–4.2 V) to 0.94–1.31 V at the ADC. Use `esp_adc_cal_*` APIs
  to calibrate (eFuse-stored values give ~50 mV accuracy). Multiply
  the calibrated mV reading by 3.2 to recover battery voltage.
  Suggested firmware thresholds: warn at 3.5 V, force shutdown at 3.2 V.
  M1's internal UVLO catches things at ~3.0 V as a hardware backstop.
- **WS2812 color order**: spec the exact part variant in BOM; configure
  firmware accordingly (most likely GRB for WS2812B).
- **Boot strap awareness**: don't drive GPIO12 HIGH at boot; don't
  hold BTN_SELECT during reset; GPIO5/15 boot HIGH is expected and
  fine.
- **Battery low cut-off**: even though the protected LiPo's BMS will
  ultimately cut at ~3.0 V, firmware should warn the user via OLED
  at ~3.4 V and force a safe shutdown at ~3.2 V.

---

## 13. Open questions / future work

- **Production connectors**: 2.54 mm pin headers are rated for ~200
  mating cycles. Locking connectors (Molex Pico-Lock, JST GH) are
  better for a finished product.
- **Panelize the 3 board designs** on one JLCPCB panel to cut fab cost
  ~3×.
- **Replacing DevKitC with a bare ESP32-WROOM**: smaller board, no
  redundant USB connectors, but adds USB-UART + boot-button circuit
  to our PCB. Defer to a v2 revision.
- **Wireless firmware update**: OTA over WiFi after first flash. Frees
  us from needing DevKitC USB access in the final enclosure.
- **EMI testing**: scope WiFi RSSI vs LED activity. May need ferrite
  on `+5V_LED` cable.
- **Magnet selection**: pick a magnet strength that triggers DRV5032FC
  reliably across the full 8 mm board-to-piece distance. DRV5032FC
  typ. BOP ≈ 4.9 mT — neodymium discs in 3–6 mm dia × 1–2 mm thick
  range should comfortably clear that. Omnipolar means either pole
  works, so press-fit doesn't need orientation control. Test with the
  3×3 (or a small bench rig) before committing the full 8×8.
- **Chess piece assembly**: how do magnets attach to standard pieces?
  Drill, press-fit, glue? Affects the magnet form factor we should
  spec.
- **4×4 mini matrix prototype**: a smaller PCB that uses the same
  controller / panel / firmware to validate the scan + LED + sensor
  approach before paying for the full 8×8 fab.

---

## 14. Per-board guides and detailed references

- `hardware/hardware-board/SCHEMATIC_GUIDE.md` — matrix board build/reference
- `hardware/hardware-controller/SCHEMATIC_GUIDE.md` — controller hand-draw build sheet
- (No panel guide — panel components are off-the-shelf modules wired to the controller's `J3`. See §6 above for the wiring table.)
- `docs/inter-board-connector.md` — formal cable contracts
- `docs/gpio-map.md` — ESP32 pin assignments
- `STATUS.md` — chronological project status

---

## 15. Change log (design-affecting decisions)

| Date | Change |
|---|---|
| 2026-06-04 | Old single-PCB design archived. Split into 3 boards. |
| 2026-06-05 (early) | Locked initial controller decisions: USB-C only, AP2112K LDO, ESP32-DevKitC on sockets, 74AHCT125 level shifter, AO3401A+MMBT3904 column drivers, finalized GPIO map. |
| 2026-06-05 (mid) | Switched to battery-backed power: BQ24074 power-path + MT3608 boost + 1S LiPo via JST PH. Consolidated column drivers into a single TBD62783A 8-channel IC. Added `VBAT_MON` ADC monitor on GPIO34. Hand-drawing the controller in KiCad GUI; scripts archived. |
| 2026-06-05 (mid) | Redesigned control panel: SSD1306 OLED replaces 3 status LEDs. BTN_SELECT replaces BTN_RESET. J_PANEL pin contract reassigned (I²C on pins 3/4, BTN_SELECT on pin 5). GPIO1/3 (UART0) repurposed as I²C bus. |
| 2026-06-05 (late) | Pre-fab protection block added: F1 polyfuse on USB VBUS, D1 PRTR5V0U2X ESD array, Q1 reverse-polarity P-MOSFET on battery +. Swapped MT3608 pure-boost → TPS63060 buck-boost (handles 3–5 V SYS cleanly). Specced protected LiPo cell. Switched J_MAIN/J_CTRL footprint to shrouded/keyed IDC. |
| 2026-06-05 (latest) | **Power section consolidated to a daughterboard module.** Replaced the entire discrete power chain (BQ24074 + TPS63060 + F1/D1/Q1 + J2 USB-C + J4 LiPo + ~25 components) with one **Adafruit PowerBoost 1000 Charger** module (M1). M1 handles USB charging, LiPo management, and 5 V boost internally. Battery monitor changed from analog `VBAT_MON` divider (GPIO34 ADC) to digital `BATT_LOW` signal from M1's open-drain `LBO` output (still GPIO34, now digital). Rationale: one-shot build with no iteration; minimize risk and complexity by trusting a known-good $20 module instead of designing two new switchers from scratch. |
| 2026-06-05 (final) | **Dropped the control panel PCB.** Moved to discrete panel-mount components (OLED module + 3 panel-mount buttons) on flying leads. The `J3` connector on the controller stays (same 10-pin contract) but now plugs into a wire harness, not a panel PCB. `hardware-control-panel/` archived to `delete/hardware-control-panel-2026-06-05/`. Recommended controller-side connector changed from plain 1×10 pin header to **JST XH 10-pin** for polarity + latching. Rebrandled project intent in `CLAUDE.md` and §1 to reflect that this is a one-off learning project, not for sale. |
| 2026-06-05 (really final) | **Power module switched from Adafruit PowerBoost 1000C ($20, micro-USB) to Seeed Lipo Rider Plus ($4 on DigiKey, USB-C).** Also dropped the AP2112K LDO + C3 + C4 (–3 components) since the Lipo Rider Plus's 3V3/250mA pin header output covers our +3V3 load directly. Added D2 (SS14 Schottky) between `+5V_LED` and DevKit pin 19 to let the battery power the ESP32 via the DevKit's onboard AMS1117 (this also fixes a previously-missed bug where the ESP32 had no battery power path). |
| 2026-06-05 (post-cleanup) | Added analog battery monitor: R14 (220 k) + R15 (100 k) + C12 (100 nF) voltage divider on M1's pin 6 (raw `BAT` pad) → `VBAT_MON` → ESP32 GPIO34 (ADC1_CH6). Firmware reads battery voltage with `esp_adc_cal_*` and shows percentage on the OLED. Wired to M1 pin 6 instead of DevKit pin 19 because DevKit pin 19 is downstream of M1's boost (always ~5 V regardless of battery state) — only the raw battery pin gives real SOC. Cleaned up unused PowerBoost 1000C lib files from `hardware-controller/lib/` and removed the corresponding `sym-lib-table`/`fp-lib-table` entries. |
| 2026-06-05 (lib install) | Installed SnapEDA's Lipo Rider Plus **footprint only** at `hardware-controller/lib/LipoRiderPlus.pretty/MODULE_106990290.kicad_mod`. Created `fp-lib-table` registering the new library. **Intentionally did NOT install SnapEDA's symbol** (`106990290.kicad_sym`) — its pin-number-to-name mapping is reversed from the module's silkscreen, which would cause the wrong nets to be routed to the wrong physical pads. Schematic uses generic `Connector_Generic:Conn_01x08` with manually-labeled pin nets per the silkscreen instead. |
| 2026-06-05 (assembly layout) | **Switched J_MAIN ↔ J_CTRL from shrouded IDC + ribbon to board-to-board stacking** based on the user's enclosure mockup. Controller PCB now stacks directly underneath the matrix PCB via mating 2×13 pin header (controller J_MAIN, male, vertical) + 2×13 socket (matrix J_CTRL, female, vertical), with 4× M3 corner standoffs (~11 mm tall) for mechanical support. No ribbon cable. Battery sits alongside the controller PCB in the space between the matrix's back and the enclosure floor. Panel components (OLED + 3 buttons + USB-C panel-mount) mount on one side wall of the enclosure. Updated DESIGN_NOTES §2, §3.1, §10.1, §10.2, §10.3. |
| 2026-06-07 (Hall sensor swap) | **Replaced A3144 (TO-92, unipolar, open-collector) with DRV5032FC (SOT-23, omnipolar, push-pull).** Identical pinout (1=VDD, 2=GND, 3=OUT), so matrix routing is unchanged. Drivers: (a) omnipolar removes the magnet-orientation constraint in chess pieces; (b) SOT-23 is JLCPCBA-assembleable, A3144 TO-92 isn't. Controller-side row pullups (R1–R8) are now electrically redundant but kept as-is. The 3×3 prototype PCB is built around this part. Updated §4.1, §4.2, §9, §11, §13. |
| 2026-06-07 (inverted controller) | **Controller PCB mounts inverted under the matrix.** J_MAIN is on the controller's **B.Cu** face, not F.Cu — components (M1, U2, U3, U6, J3, etc.) face the enclosure floor, the bare B.Cu face mates with the matrix's B.Cu. No mounting holes on the controller and no corner standoffs: the J_MAIN/J_CTRL connector pair is the only mechanical join, with the matrix's enclosure-frame mount carrying the assembled weight. Test points on the controller schematic were also dropped (probe component pads/pin headers directly during bringup). Updated §2, §3.1, §5.1, §10.1, §10.3. |
| 2026-06-09 (paper-fit test) | Printed all three PCBs at 1:1 and physically checked fit. Four observations logged in §11 items 12–15: **(12)** 8×8 outline at 292 × 292 mm overhangs Paolo's folding board's inner cavity — needs SQUARE_SIZE / BOARD_MARGIN re-derivation before fab. 3×3 (132 × 132 mm) is unaffected. **(13)** J_MAIN/J_CTRL pin-1 mirrors across the board-flip — pins line up mechanically but nets don't match per-pin between the two boards as soldered. Fix by rotating/renumbering J1 on one side before the 8×8 fab. **(14)** ESP32 footprint on the controller PCB doesn't match Paolo's physical DevKitC — preferred fix is to buy a matching DevKitC variant rather than re-route U2. **(15)** DRV5032FC SOT-23 visually small — verified not a sensing concern (die threshold sets sensitivity, not package), only a handling concern. None of the four blocks the **3×3 + controller** order that's already in flight. |
| 2026-06-09 (J1 mirror fix) | **Resolved §11 item 13** (J_MAIN/J_CTRL pin-1 mirror under board-flip). The matrix's J1 footprint was manually mirrored in KiCad's PCB editor (select J1 → right-click → Mirror → Mirror Around X Axis). Rows swap, nets at each physical pad position now match the controller's flipped pin contract. Side effect: matrix J1 pad numbering is now swapped within each odd-even pair vs the §3.1 contract table (matrix pin 1 = GND, pin 2 = +5V_LED, etc.) — see the callout in §3.1 explaining how to read the contract correctly. Same mirror needs to be re-applied to the 8×8 matrix J1 after its layout script runs. |
| 2026-06-10 (8×8 dimensions trimmed) | **Resolved §11 item 12** (8×8 doesn't fit folding board cavity). Paolo measured the folding board's playing area at **10 × 10 in = 254 × 254 mm** → squares are exactly **1.25 in = 31.75 mm** each. Updated `SQUARE_SIZE = 32 → 31.75 mm` and `BOARD_MARGIN = 18 → 14 mm`. New 8×8 size: **282 × 282 mm** (was 292). Synced in both `hardware-board/scripts/01_chess_grid.py` and `02_route.py`. 8×8 still fits the ≤300 mm JLC pricing tier and tiles cleanly onto 2 A4 sheets (with a 285 mm KiCad drawing-sheet setting). 3×3 not changed — already at JLC. |
| 2026-06-08 (matrix board dimensions) | **Matrix board outline sized to fit Paolo's folding chess board model.** `SQUARE_SIZE = 32 mm` (matches the model's chess squares); `BOARD_MARGIN = 18 mm` from outermost chess square corner to PCB edge. Total PCB outlines: **3×3 = 132×132 mm**, **8×8 = 292×292 mm**. The physical model has a 20 mm inner-frame margin (the notation A–H / 1–8 strip), so 18 mm leaves ~2 mm wiggle per side for the PCB to slide inside the cavity. Both PCBs sit INSIDE the folding board's inner frame (not replacing the wood); the model's 10 mm outer fold/decorative edge is not part of the PCB. 8×8 stays comfortably in JLC's ≤300 mm pricing tier. |
| 2026-06-08 (DRV5032FC swap finalized) | **Swapped A3144 (TO-92, hand-solder) → DRV5032FC (SOT-23, JLC Basic Part C527532) in both matrix boards' schematic generators.** Open-drain output (compatible with controller R1..R8 pull-ups to +3V3 — sensor's 1 mA sink rating handles 3.3 V / 10 kΩ = 330 µA), omnipolar (no magnet orientation worries), VCC 1.65–5.5 V (works at 5 V or 3.3 V), B_OP threshold ±4.8 mT (proven safe for 32 mm chess pitch with N35 magnets). `openchess:A3144` symbol kept by name for backwards compatibility (pin 1=VCC, 2=GND, 3=OUT is identical between A3144 and DRV5032FC). 64× hall instances in 8×8 and 9× in 3×3 now use the SMD footprint — both boards fully JLC-PCBA-assemblable. Controller schematic unchanged (R1..R8 pull-ups still match the new sensor's open-drain output). |
| 2026-06-08 (C91 entry cap dropped) | **Removed C91 (470 µF THT polarized electrolytic).** Distributed row bulks (9× 47 µF in 8×8, 4× 47 µF in 3×3) provide 423 µF and 188 µF respectively — comfortably enough for the +5V_LED rail. C91 was the only through-hole part on the matrix board; removing it makes both boards fully JLC-SMT-assemblable. |
| 2026-06-08 (3×3 test board created) | **New `hardware-board-3x3/` directory** with full schematic + PCB layout pipeline, cloned from `hardware-board/` and parameterised for `MATRIX_COLS = MATRIX_ROWS = 3`. Identical design to the 8×8 (DRV5032FC, WS2812B, same connectors/bulks/decoupling); only the matrix dimensions are scaled. Purpose: validate the entire design — power flow, level shifter, column driver, hall scan, LED chain, J_CTRL/J_MAIN mating — on a cheap 132×132 mm board (~$15 JLC fab) before paying for the 292×292 mm 8×8 fab + PCBA. Supersedes the previously-planned 4×4 prototype. |
| 2026-06-08 (script architecture: merger not replacer) | **`scripts/sch/99_assemble.py` rewritten as a MERGER, not a REPLACER.** It now reads the existing `.kicad_sch`, removes only top-level items whose UUID prefix matches a script-owned prefix (`ba11` halls, `1ed0` LEDs, `1ed5` LED decoupling caps), then inserts fresh chunk content. Everything else — user-added components (J1 connector, MH, FID, TP, row bulks, PWR_FLAGs), manual wires/labels, decorative items — is preserved untouched. Previously the assembler overwrote the whole schematic on every run and wiped manual edits. Side effect: the chunk set was trimmed to only `02_halls.py` + `03_leds.py`; `01_skeleton.py` and `04_bulks.py` were archived under `scripts/sch/_archived/` because the user prefers to add the skeleton box and row bulks by hand in KiCad. |
| 2026-06-08 (matrix PCB layout: bulks left, J1 bottom) | **Updated `scripts/01_chess_grid.py` placement rules** to match user's chosen topology: row bulk caps (47 µF) live in the **LEFT margin**, Y-aligned with each LED row (so each bulk physically sits next to the row it decouples) — 8 mm left of `CHESS_X_LEFT`, all at the same X. The **J_CTRL connector (J1)** is placed at the **center of the bottom edge on B.Cu**, rotated 90° (long axis along X, ~33 mm wide × 5 mm tall), with the anchor shifted left by half the body length (15.24 mm) so the geometric center of the connector body — not pin 1 — sits at the board's X centerline. Both placements are mirrored between the 3×3 and 8×8 scripts so the design stays test→production identical. |

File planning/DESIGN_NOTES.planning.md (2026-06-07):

# OpenChess Hardware Design — Spec Sheet

Authoritative current-state spec for the OpenChess hardware. Per-board
build sheets are in each board's `SCHEMATIC_GUIDE.md`; cross-board cable
contracts in §3.

---

## 1. What the system is

Physical chess board with magnetic piece detection and visual feedback.
Plays online via Lichess and offline against Stockfish.

- **Sensing**: 8×8 grid of A3144 Hall sensors (each chess piece carries a magnet)
- **Display**: 9×9 grid of WS2812B RGB LEDs at square corners
- **Compute**: ESP32-DevKitC v4 module on socketed headers
- **UI**: SSD1306 0.96" I²C OLED + 3 panel-mount pushbuttons
- **Power**: 1S protected LiPo, USB-C charging, all via Seeed Lipo Rider Plus daughterboard

One-off, hand-soldered + JLC SMT-assembled, no v2 planned.

---

## 2. Hardware split

```
hardware/
├── hardware-board/         Matrix PCB: 64 Halls + 81 WS2812 LEDs (passive only)
└── hardware-controller/    Controller PCB: ESP32 socket, power module, ICs

(No panel PCB — OLED + 3 buttons on a flying-lead harness from controller J3)
```

**Assembly stack** (top → bottom):

```
   Matrix PCB              ← chessboard top surface, halls + LEDs on F.Cu
   J_CTRL female socket    ← back face of matrix, 2×13 vertical
       ↕ mates
   J_MAIN male pin header  ← top face of controller, 2×13 vertical
   Controller PCB
   4× M3 corner standoffs (~11 mm tall)
   LiPo battery (alongside controller)
   Enclosure floor
```

- No ribbon cable between matrix and controller.
- Battery sits **alongside** the controller, not sandwiched between PCBs.
- Panel components (OLED + buttons + USB-C) mount on one side wall of the enclosure on flying leads from controller J3.

---

## 3. Cross-board connector contracts

### 3.1 J_MAIN (controller) ↔ J_CTRL (matrix) — 2×13 board-to-board

| Side | Ref | Footprint |
|---|---|---|
| Controller | `J1` (J_MAIN) | `Connector_PinHeader_2.54mm:PinHeader_2x13_P2.54mm_Vertical` (male, top face) |
| Matrix | `J1` (J_CTRL) | `Connector_PinSocket_2.54mm:PinSocket_2x13_P2.54mm_Vertical` (female, back face) |

Pin 1 marked with silkscreen dot on both sides.

**Pinout (both sides identical by pin number):**

| Pin | Net | Direction |
|----:|-----|---|
| 1 | `+5V_LED` | controller → matrix |
| 2 | `GND` | both |
| 3 | `+5V_LED` | controller → matrix |
| 4 | `GND` | both |
| 5 | `+5V_LED` | controller → matrix |
| 6 | `GND` | both |
| 7 | `LED_DATA_5V` | controller → matrix |
| 8 | `GND` | both |
| 9 | `S0` | matrix → controller |
| 10 | `S1` | matrix → controller |
| 11 | `S2` | matrix → controller |
| 12 | `S3` | matrix → controller |
| 13 | `S4` | matrix → controller |
| 14 | `S5` | matrix → controller |
| 15 | `S6` | matrix → controller |
| 16 | `S7` | matrix → controller |
| 17 | `CA_PWR` | controller → matrix |
| 18 | `CB_PWR` | controller → matrix |
| 19 | `CC_PWR` | controller → matrix |
| 20 | `CD_PWR` | controller → matrix |
| 21 | `CE_PWR` | controller → matrix |
| 22 | `CF_PWR` | controller → matrix |
| 23 | `CG_PWR` | controller → matrix |
| 24 | `CH_PWR` | controller → matrix |
| 25 | `+5V_LED` | controller → matrix |
| 26 | `GND` | both |

Counts: 4× `+5V_LED`, 5× `GND`, 1× `LED_DATA_5V`, 8× row-sense, 8× column-power.

### 3.2 J_PANEL — JST XH 10-pin (controller J3 → panel harness)

Ref `J3` on the controller. Footprint: `Connector_JST:JST_XH_B10B-XH-A_1x10_P2.50mm_Vertical`.

| Pin | Net | Direction |
|----:|-----|---|
| 1 | `+3V3` | controller → panel (OLED VCC + button-pullup supply) |
| 2 | `GND` | both |
| 3 | `I2C_SDA` | bidirectional (ESP32 GPIO1 ↔ OLED) |
| 4 | `I2C_SCL` | controller → panel (ESP32 GPIO3) |
| 5 | `BTN_SELECT` | panel → controller (GPIO2, internal pullup) |
| 6 | `BTN_POWER` | panel → controller (GPIO36, external pullup `R36` on controller) |
| 7 | `BTN_MODE` | panel → controller (GPIO39, external pullup `R37` on controller) |
| 8 | `PANEL_SPARE` | reserved (single-pin net) |
| 9 | `PANEL_SPARE2` | reserved (single-pin net) |
| 10 | `GND` | both |

Buttons short their signal net to GND when pressed. `PANEL_SPARE*` are intentionally single-pin nets — ERC warning expected.

Reset is the DevKitC's onboard EN button. No panel reset.

---

## 4. Matrix board BOM (`hardware-board/`)

**236 components total, all passive. F.Cu has halls + LEDs. B.Cu has J_CTRL socket + GND pour.**

| Group | Refdes range | Count | Symbol | Footprint | Value |
|---|---|---:|---|---|---|
| Hall sensors | `U1..U64` | 64 | `openchess:A3144` | `Package_TO_SOT_THT:TO-92_Inline` | A3144 |
| WS2812B LEDs | `D1..D81` | 81 | `LED:WS2812B` | `LED_SMD:LED_WS2812B_PLCC4_5.0x5.0mm_P3.2mm` | WS2812B |
| Per-LED decoupling | `C10..C90` | 81 | `Device:C` | `Capacitor_SMD:C_0805_2012Metric_Pad1.18x1.45mm_HandSolder` | 100nF |
| Row bulk caps | `C1..C9` | 9 | `Device:C` | `Capacitor_SMD:C_1206_3216Metric` | 47µF |
| Entry cap | `C91` | 1 | `Device:C_Polarized` | `Capacitor_THT:CP_Radial_D10.0mm_P5.00mm` | 470µF |
| Matrix connector | `J1` (J_CTRL) | 1 | `Connector_Generic:Conn_02x13_Odd_Even` | `Connector_PinSocket_2.54mm:PinSocket_2x13_P2.54mm_Vertical` | — |
| Test points | `TP1..TP4` | 4 | `Connector:TestPoint` | `TestPoint:TestPoint_Pad_D1.5mm` | rails + data nets |
| Mounting holes | `MH1..MH4` | 4 | `Mechanical:MountingHole` | `MountingHole:MountingHole_3.2mm_M3` | M3 |
| Fiducials | `FID1..FID3` | 3 | `Mechanical:Fiducial` | `Fiducial:Fiducial_1mm_Mask2mm` | — |

**Ref mapping rules** (firmware contract):
- Hall: `U{1 + file_idx * 8 + rank_idx}`. `U1 = A1`, `U64 = H8`. File 0..7 = A..H, rank 0..7 = 1..8.
- LED: row-major. `D1 = top-left`, `D9 = top-right`, `D10..D18 = row 2`, …, `D81 = bottom-right`.
- Per-LED cap: `C{led_idx + 9}`. `C10` pairs with `D1`, `C90` pairs with `D81`.

**Nets used (every label):** `+5V_LED`, `GND`, `LED_DATA_5V`, `LED_DOUT_END` (TP only), `S0..S7`, `CA_PWR..CH_PWR`.

**Per-component pin → net rules:**
- A3144 Pin 1 (VCC) → `C{file}_PWR`; Pin 2 (GND) → `GND`; Pin 3 (OUT) → `S{rank}`.
- WS2812B Pin 1 (VDD) → `+5V_LED`; Pin 2 (DOUT) → next LED Pin 4 (DIN), or `LED_DOUT_END` for D81; Pin 3 (VSS) → `GND`; Pin 4 (DIN) → previous LED Pin 2 (DOUT), or `LED_DATA_5V` for D1.
- 100nF/47µF/470µF caps → Pin 1 to `+5V_LED`, Pin 2 to `GND`. C91 is polarized: Pin 1 = + (anode).

PWR_FLAG required on `+5V_LED` and `GND` (this board only consumes; ERC needs the source flag).

---

## 5. Controller board BOM (`hardware-controller/`)

| Group | Refdes | Symbol | Footprint | Value |
|---|---|---|---|---|
| ESP32 socket (left strip) | `J3` | `Connector_Generic:Conn_01x19` | `Connector_PinSocket_2.54mm:PinSocket_1x19_P2.54mm_Vertical` | DevKitC left |
| ESP32 socket (right strip) | `J4` | `Connector_Generic:Conn_01x19` | `Connector_PinSocket_2.54mm:PinSocket_1x19_P2.54mm_Vertical` | DevKitC right |
| Matrix connector | `J1` (J_MAIN) | `Connector_Generic:Conn_02x13_Odd_Even` | `PinHeader_2x13_P2.54mm_Vertical` | 2×13 male, top face |
| Panel connector | `J3` (J_PANEL — *separate from DevKit J3*, distinct net) | `Connector_Generic:Conn_01x10` | `JST_XH_B10B-XH-A_1x10_P2.50mm_Vertical` | JST XH 10-pin |
| Power module | `M1` | `Connector_Generic:Conn_01x08` | `LipoRiderPlus:MODULE_106990290` | Seeed Lipo Rider Plus |
| Schottky diode | `D2` | `Device:D_Schottky` | `Diode_SMD:D_SMA` | SS14 or BAT60A |
| Level shifter | `U3` | `74xx:74AHCT125` | `Package_SO:SOIC-14_3.9x8.7mm_P1.27mm` | 74AHCT125 |
| Column driver | `U6` | `Transistor_Array:TBD62783A` | `Package_DIP:DIP-18_W7.62mm` *or* `Package_SO:SOIC-18W_7.5x11.55mm_P1.27mm` | TBD62783A |
| Row pullups | `R1..R8` | `Device:R` | `Resistor_SMD:R_0805_2012Metric` | 10k |
| LED data series | `R11` | `Device:R` | `Resistor_SMD:R_0603_1608Metric` | 33Ω |
| Battery monitor (top) | `R14` | `Device:R` | `Resistor_SMD:R_0603_1608Metric` | 220k |
| Battery monitor (bottom) | `R15` | `Device:R` | `Resistor_SMD:R_0603_1608Metric` | 100k |
| Button pullups | `R36, R37` | `Device:R` | `Resistor_SMD:R_0603_1608Metric` | 10k |
| +5V_LED bulk | `C1, C2` | `Device:C` | `Capacitor_SMD:C_0805_2012Metric` | 10µF |
| U3 decoupling | `C5` | `Device:C` | `Capacitor_SMD:C_0603_1608Metric` | 100nF |
| U6 decoupling | `C11` | `Device:C` | `Capacitor_SMD:C_0603_1608Metric` | 100nF |
| ADC filter | `C12` | `Device:C` | `Capacitor_SMD:C_0603_1608Metric` | 100nF |
| Test points | `TP1..TP3` | `Connector:TestPoint` | `TestPoint:TestPoint_Pad_D1.5mm` | rails only |
| Mounting holes | `MH1..MH4` | `Mechanical:MountingHole` | `MountingHole_3.2mm_M3` | M3 corners |
| Fiducials | `FID1, FID2` | `Mechanical:Fiducial` | `Fiducial_1mm_Mask2mm` | — |

**Notes on M1 (Lipo Rider Plus):**
- Footprint installed locally at `lib/LipoRiderPlus.pretty/MODULE_106990290.kicad_mod` (SnapEDA model).
- **Symbol uses generic `Conn_01x08`, NOT SnapEDA's `106990290.kicad_sym`** — SnapEDA's symbol has reversed pin-number-to-name mapping vs. the module silkscreen. Using the generic connector with manual pin labels matches the silkscreen.
- M1 pin mapping (matches silkscreen, left-to-right with JST side first): 1=`3V3` out, 2=`EN` (NC), 3=`GND`, 4=`5V` out, 5=`GND`, 6=`BAT` raw, 7=`GND`, 8=`USB` VBUS test pad (NC).

**No on-PCB LDO.** `+3V3` comes directly from M1 pin 1.

---

## 6. Panel components (no PCB)

| Component | Qty | Notes |
|---|---:|---|
| SSD1306 0.96" 128×64 I²C OLED module | 1 | Pinout varies by vendor — verify with multimeter before wiring. |
| Panel-mount 12 mm tactile pushbutton | 3 | POWER, MODE/NAV, SELECT. Threaded shaft + nut. |
| 10-conductor stranded harness (~30 cm) | 1 | JST XH receptacle on controller end, bare leads on panel end |
| 4.7 kΩ I²C pullups (optional) | 2 | Add inline if OLED's onboard pullups don't reach across the 30 cm cable |

Wiring per J_PANEL pinout in §3.2. Buttons short signal-pin → GND when pressed.

---

## 7. Power architecture

```
USB-C   ────────→ ┌──────────────────────┐
                  │  M1 Lipo Rider Plus  │
LiPo ────────→ ───┤                      │
                  │  - USB-C charger     │
                  │  - 5V/2.4A boost     │
                  │  - 3.3V/250mA LDO    │
                  │  - OFF/5V/ON switch  │
                  └─┬───┬───┬───┬───┬────┘
                    │   │   │   │   │
                Pin 4   1   3,5,7  6 (8=NC)
                  5V  3V3  GND   BAT-raw
                    │   │         │
                    │   │      R14(220k)
                    │   │         │
                    │   │      ┌──┴──┐
                    │   │      R15  C12   → VBAT_MON → GPIO34 (ADC1_CH6)
                    │   │      (100k)(100nF)
                    │   │         │
                    │   │        GND
                    │   │
                    │   └→ +3V3 rail → ESP32, R1..R8, R36, R37, OLED via J_PANEL
                    │
                    └→ +5V_LED rail
                        ├→ C1, C2 (10µF bulk)
                        ├→ U3 VCC (74AHCT125)
                        ├→ U6 VCC (TBD62783A)
                        ├→ J1 pins 1, 3, 5, 25 → matrix
                        └→ D2 anode → DevKit pin 19 (ESP32 5V in)
                                       │
                                       └→ DevKit's onboard AMS1117 → ESP32 internal 3V3
```

**Behavior:**
- USB-C plugged: M1 charges LiPo (up to 2A) AND powers both rails.
- USB-C unplugged: M1 boosts from LiPo until UVLO (~3.0V) or BMS cuts.
- DevKit's USB micro-B also plugged: D2 blocks backfeed between USB sources.
- M1's slide switch MUST be set to "ON" (5V output enabled).

**Current budget:**

| Load | Typical | Peak |
|---|---:|---:|
| ESP32 + WiFi | 80 mA | 300 mA |
| 81 WS2812B (firmware-limited) | 100–500 mA | 5 A unbounded — **firmware MUST cap** |
| 8 active Hall sensors per scan column | 50 mA | 80 mA |
| U3 + U6 logic | 10 mA | 30 mA |
| OLED | 15 mA | 25 mA |
| **Total** | **~250–700 mA** | bounded by M1's **2.4 A** ceiling |

**Battery monitor math:** VBAT_MON = BAT × 100k / (220k + 100k) = BAT × 0.3125. At 4.2V → 1.31V at ADC. At 3.0V → 0.94V at ADC. Firmware multiplies calibrated ADC mV by 3.2 to recover BAT voltage.

---

## 8. GPIO map

Full table in `docs/gpio-map.md`. Key assignments:

| Function | ESP32 GPIO | DevKitC pin | Net |
|---|---:|---:|---|
| WS2812 data (3V3 pre-shift) | 32 | 7 | `LED_DATA` |
| Row sense | 4, 16, 17, 18, 19, 21, 22, 23 | 26..37 | `S0..S7` |
| Column drive | 13, 14, 27, 26, 25, 33, 5, 15 | 15..29 | `COL_DRV_A..H` |
| I²C SDA | 1 (TX0 repurposed) | 35 | `I2C_SDA` |
| I²C SCL | 3 (RX0 repurposed) | 34 | `I2C_SCL` |
| BTN_SELECT | 2 | 24 | `BTN_SELECT` |
| BTN_POWER | 36 (input-only) | 3 | `BTN_POWER` |
| BTN_MODE | 39 (input-only) | 4 | `BTN_MODE` |
| VBAT_MON (analog) | 34 (input-only, ADC1_CH6) | 5 | `VBAT_MON` |
| Reserved | 35 (input-only) | 6 | `PANEL_SPARE` |

**Pin constraints:**
- Flash pins (GPIO 6–11) → no-connect on DevKit socket.
- DevKit pin 1 (3V3) → no-connect (M1 sources 3V3).
- DevKit pin 19 (5V) → cathode of D2.
- UART0 (GPIO1/3) repurposed as I²C → no serial debug on DevKit USB during normal operation.
- Boot-strap pins: GPIO5/15 driven HIGH at boot (acceptable: columns G/H briefly on); GPIO2 floating/LOW at boot; GPIO12 NC at boot.

---

## 9. Mechanical & enclosure constraints

### 9.1 Stack

- Matrix PCB mounting holes (MH1..MH4) align with controller PCB mounting holes (MH1..MH4) — when the boards stack, M3 standoffs thread through both.
- Standoff height: **~11 mm** (matches the mating depth of the 2×13 pin header + socket combo).
- M1 (Lipo Rider Plus) is the tallest component on the controller. **Confirm M1 + 1.6 mm PCB thickness ≤ 11 mm headroom** before locking standoff length.

### 9.2 Controller PCB layout zones

| Zone | What |
|---|---|
| Top edge | M1 (USB-C jack + slide switch face the enclosure side wall) |
| Bottom edge | J1 (J_MAIN) — top face male pin header for stacking |
| One side edge | J3 (J_PANEL) — JST XH facing the panel side of the enclosure |
| Center | U2 (ESP32 socket) |
| Between U2 and J1 | U3 (level shifter), U6 (column driver), R11 (LED series), C5, C11 |
| Near M1 | C1, C2 (bulk), R14, R15, C12 (battery monitor) |
| Near U2 GPIOs | R1..R8 (row pullups), R36, R37 (button pullups), D2 (Schottky) |
| All 4 corners | MH1..MH4 (M3 mounting, must align with matrix MH1..MH4) |

### 9.3 Enclosure cutouts

| Cutout | Location | Size |
|---|---|---|
| OLED window | Side panel | ~27 × 27 mm |
| 3× button holes | Side panel (alongside OLED) | 12 mm diameter each |
| USB-C panel-mount | Side panel | ~10 × 8 mm rectangular + 2× M2 screw holes |
| DevKit EN button pinhole | Bottom | ~3 mm |
| DevKit micro-B access | Bottom (removable plate ideal) | enough to reach USB-B |

USB-C from M1 is routed to the side panel via a USB-C panel-mount extension cable (~$5, hand-soldered). The M1 module itself sits inside the enclosure, not at the wall.

### 9.4 Cables

- **No ribbon** between matrix and controller (board-to-board stack).
- **Panel harness**: 10-wire, ~15–20 cm. Twist I²C pair with GND if possible. Use 100 kHz I²C, not 400 kHz.
- **Battery**: pre-attached on a protected LiPo with JST 2.0 — plugs into M1's onboard JST.
- **USB-C panel cable**: ~15–30 cm, male USB-C into M1, female panel-mount on the enclosure wall.

---

## 10. First-build verification checklist

These are the things most likely to brick the build. Verify before fab.

1. **DevKitC socket pitch**: `Conn_01x19` × 2 strips at 25.4 mm row pitch. Most DevKitC modules are 2×15, not 2×19 — confirm the exact module variant before locking footprint.
2. **M1 footprint vs module**: 8 pads at 2.54 mm pitch + 4 corner M2 mounting holes (3 mm drill). Verify against the actual Seeed Lipo Rider Plus you'll receive.
3. **TBD62783A package**: pick DIP-18 *or* SOIC-18W *before* fab — both share the same KiCad symbol.
4. **WS2812B variant**: BOM must say `WS2812B-2020` or equivalent 5050 PLCC4. Color order varies (most are GRB) — firmware must match.
5. **A3144 pinout**: Pin 1 = VCC, Pin 2 = GND, Pin 3 = OUT. Order varies between datasheet sources — verify against the specific part you'll buy.
6. **J_MAIN ↔ J_CTRL alignment**: when the boards stack, controller pin 1 must mate with matrix pin 1. Mark with silkscreen dots on both.
7. **11 mm standoff clearance**: M1 height + 1.6 mm PCB ≤ 11 mm.
8. **Polarity**: C91 (+) toward `+5V_LED`; D2 anode = `+5V_LED`, cathode = DevKit pin 19; LiPo JST 2.0 (mechanically keyed).
9. **M1 slide switch in ON position** when board is assembled.
10. **3V3 budget**: M1 supplies only 250 mA on 3V3. Sum ESP32 (~150 mA burst) + OLED (~20 mA) + R1..R8 + R36/R37 pullups → fits but verify.
11. **No serial debug on DevKit USB during normal op** — UART0 is the I²C bus. Plan bring-up around the OLED first.

---

## 11. Known issues to confirm during bring-up

1. **A3144 settling**: ~5 µs after column energize before reading rows. Firmware must wait. Scan ≤ 1 kHz.
2. **A3144 polarity sensitivity**: senses one magnet polarity only. Spec piece magnet orientation.
3. **ESP32 ADC nonlinearity at low V**: VBAT_MON @ 3.0V → 0.94V ADC = noisy end. Use `esp_adc_cal_*` APIs.
4. **I²C over 30 cm panel cable**: stay at 100 kHz; if writes unreliable, drop pullups to 2.2 kΩ.
5. **Stacking-connector IR drop on +5V_LED**: at peak LED current the 2×13 stack can drop 100–500 mV. Mitigation: firmware brightness cap. Already designed in.
6. **Boot-time column glitch**: GPIO5/15 (`COL_DRV_G/H`) HIGH at boot strap → columns G/H briefly on for ~10 ms. Electrically harmless.
7. **BTN_SELECT held during reset**: GPIO2 must be LOW/floating at boot. Don't hold SELECT during EN-reset.
8. **M1 single-point-of-failure**: if M1 dies, all rails dead. Mitigation: M1 is a swappable $4 daughterboard.

---

## 12. Per-board guides

- `hardware-board/SCHEMATIC_GUIDE.md` — matrix board build sheet
- `hardware-controller/SCHEMATIC_GUIDE.md` — controller build sheet
- `hardware-controller/PCB_LAYOUT_GUIDE.md` — controller layout spec
- `docs/inter-board-connector.md` — cable contracts (matches §3 above)
- `docs/gpio-map.md` — full ESP32 pin assignments

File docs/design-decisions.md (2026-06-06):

# Design Decisions

Why the current OpenChess hardware looks this way.

## Split The Hardware Into Three Boards

The old integrated-board direction put the matrix, controller, power, status
LEDs, and controls onto one large PCB. The current design separates them:

- `hardware-board`: passive matrix with Hall sensors and LEDs
- `hardware-controller`: ESP32, power, scan drivers, connector logic
- `hardware-control-panel`: side-mounted buttons and status LEDs

This reduces layout risk, makes testing cheaper, and lets the control panel be
mounted wherever the enclosure needs it.

## Keep A3144 TO-92 Hall Sensors For The First Prototype

A3144 sensors are cheap, available in bulk, hand-solderable, and known to work
in similar chess-board projects. SMD Hall sensors may be cleaner later, but TO-92
is lower risk for the first physical prototype.

## Keep WS2812B 5050 LEDs

WS2812B LEDs reduce LED wiring to one data chain and give per-corner RGB state.
The 9x9 corner layout is part of the desired visual style. The schematic now
uses 81 LEDs, 100nF per LED, row bulk caps, and a `+5V_LED` entry cap.

## Move Row Pullups To The Controller

A3144 outputs are open-collector. Pulling `S0..S7` up to `+3V3` on the
controller keeps ESP32 GPIOs safe and keeps the matrix board passive.

## Use A Dedicated Control Panel Board

Status LEDs and buttons should not live on the matrix board. A small cable panel
is easier to mount on the enclosure side and can change mechanically without
forcing a matrix-board respin.

## Keep Schematic Generation Scripted

Repetitive schematic content is generated by scripts. Each board follows the
same pattern: `config.py`, `geometry.py`, `parts.py`, chunk scripts, and
`99_assemble.py`. This makes the design easier to regenerate, review, and later
variant for a 4x4 prototype.

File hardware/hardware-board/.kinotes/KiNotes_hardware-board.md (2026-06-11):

# **hardware-board - Design Notes**

## **Overview**
<!-- Brief description of the PCB project -->

## **Schematic Notes**
<!-- Key circuit blocks, design rationale -->

## **Layout Considerations**
<!-- Layer stackup, impedance, keep-outs -->

## **Component Notes**
<!-- Click on designators like R1, C5, U3 to highlight on PCB -->

## **Power Distribution**
<!-- Power rails, decoupling strategy -->

## **Signal Integrity**
<!-- Critical nets, routing constraints -->

## **References**
<!-- Datasheets, application notes, calculations -->

---
*KiNotes - PCBtools.xyz*

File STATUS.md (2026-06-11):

# Project Status

A snapshot of where the project is right now. **For design details,
the source of truth is `hardware/DESIGN_NOTES.md`.** This file tracks
progress, not decisions.

This is a **one-off personal learning project**, not for sale. Goal:
build one board that works first try. When it works on Paolo's desk,
the project is done.

Last updated: 2026-06-08

## Canonical references

| Document | What lives there |
|---|---|
| `hardware/DESIGN_NOTES.md` | **Source of truth** — full design, connector contracts, BOM, known issues, change log |
| `hardware/hardware-board/SCHEMATIC_GUIDE.md` | Matrix board build sheet (8×8) |
| `hardware/hardware-board-3x3/` | 3×3 test board (cloned from 8×8 with `MATRIX_COLS=MATRIX_ROWS=3`) |
| `hardware/hardware-controller/SCHEMATIC_GUIDE.md` | Controller hand-draw build sheet |
| `docs/gpio-map.md` | ESP32 GPIO assignments |
| `docs/inter-board-connector.md` | Formal cable contracts |
| `CLAUDE.md` | Project intent + durable context |

## Current state

| Subsystem | Schematic | PCB layout | Notes |
|---|---|---|---|
| `hardware-board-3x3` (3×3 test) | Script-generated halls + LEDs + caps; J1/MH/FID/TP manual | **132×132 mm**, layout script run | DRV5032FC SOT-23, fully JLC-assemblable. Built to validate before ordering 8×8. |
| `hardware-board` (8×8 full matrix) | Script-generated halls + LEDs + caps; J1/MH/FID/TP manual | **282×282 mm**, layout script ready | DRV5032FC SOT-23, fully JLC-assemblable. Order AFTER 3×3 validates. |
| `hardware-controller` | Hand-drawn, complete | Hand-routed power; autoroute + GND pour done | DRC clean (only cosmetic silk warnings). PCBA BOM (`assembly/openchess-controller-jlc-*.csv`) ready for JLC. |
| Panel components (no PCB) | N/A — discrete OLED + 3 panel-mount buttons on flying leads | N/A | Plugged into controller `J3` via JST XH 10-pin harness. See DESIGN_NOTES §6. |

## Matrix board dimensions (matches Paolo's folding chess board model)

- **`SQUARE_SIZE = 32 mm`** (matches model's wood squares)
- **`BOARD_MARGIN = 18 mm`** (model has 20 mm inner-frame cavity; 18 mm leaves ~2 mm wiggle per side)
- **3×3 = 132×132 mm** (≤150 mm tier at JLC, ~$10 fab)
- **8×8 = 282×282 mm** (≤300 mm tier at JLC, ~$30 fab)
- The folding board's 10 mm outer fold/decorative edge is NOT part of the PCB

## Next actions

1. **Order the 3×3 test board first** — JLC PCBA on `hardware-board-3x3`,
   ~$15-25, validates the entire design (DRV5032FC sensing, WS2812 chain,
   J_CTRL stack mating with controller) before paying for the 8×8 fab.
2. **Order the controller PCB** alongside the 3×3 (same JLC order, one
   shipping fee). PCBA includes everything except the modules (M1, ESP32-DevKitC).
3. **Source the modules from DigiKey** (minimum verification list):
   - Seeed Lipo Rider Plus (M1)
   - ESP32-DevKitC v4 (U2)
   - 2× 1×19 female sockets for ESP32 mount
   - 5 N35 magnets for sensor testing
   - Total ~$20.
4. **Bench-test the 3×3 + controller**: power-up, OLED hello, WS2812 chain,
   magnet detection on a single Hall, full matrix scan. If clean → order
   the 8×8 fab. If broken → spin a controller v2 without losing the 8×8
   fab cost.
5. **Build the panel harness** (OLED + 3 buttons + USB-C extension cable)
   once the 3×3 validates the controller.

## Schematic script architecture (matrix boards)

Updated 2026-06-08 to be a **merger, not a replacer** — the assembler
preserves anything the user adds in KiCad GUI:

- Active chunk scripts: `02_halls.py`, `03_leds.py`
- Archived (user does these by hand): `01_skeleton.py`, `04_bulks.py` → `scripts/sch/_archived/`
- `99_assemble.py` reads the existing `.kicad_sch`, removes only items
  whose UUID prefix matches a script-owned prefix (`ba11` halls, `1ed0`
  LEDs, `1ed5` LED decoupling), then inserts fresh chunk content.
  Manual additions (J1 connector, MH, FID, TP, row bulks, PWR_FLAGs)
  are preserved untouched.
- PCB layout script (`01_chess_grid.py`) positions halls, LEDs, LED caps,
  row bulks, AND J1 on B.Cu at the center of the bottom edge (with
  anchor offset for body centering).

## Firmware status

Firmware Phase A foundations exist from earlier work, but pin
assignments and LED indexing need to be re-verified against the
current `docs/gpio-map.md` and the matrix board chain order before any
real-board validation.

Firmware-author heads-up items (no UART debug, Hall settling timing,
LED brightness limits, battery-state visual indicator on the Lipo Rider
Plus, etc.) are documented in `hardware/DESIGN_NOTES.md` §12.

## Open questions

- Magnet form factor and orientation for chess pieces (need to test on
  the 4×4 prototype before committing).
- Panelize the matrix + controller PCBs into one JLCPCB order to save
  fab cost?
- Enclosure design — material (3D printed vs laser cut vs CNC),
  cable routing for the matrix ribbon, OLED window, button hole
  positions.

## Recent activity

For the full change log (design-affecting decisions with dates), see
`hardware/DESIGN_NOTES.md` §15.

### 2026-06-08 (matrix boards finalised for fab)

- **Board dimensions locked to Paolo's folding chess board model**:
  SQUARE_SIZE = 32 mm, BOARD_MARGIN = 18 mm. 3×3 = 132×132 mm, 8×8 = 292×292 mm.
- **DRV5032FC SOT-23** confirmed as the Hall sensor across both matrix
  schematics — JLC Basic Part C527532, omnipolar, open-drain, compatible
  with the controller's R1..R8 pull-ups. A3144 (TO-92) fully retired.
- **C91 (470 µF entry cap) dropped.** Row bulks (47 µF × N) cover the rail.
  Matrix boards are now fully JLC-SMT-assemblable — no through-hole parts.
- **3×3 test board** (`hardware-board-3x3/`) created with full schematic +
  PCB pipeline. Identical design to 8×8, just scaled. Purpose: fab the
  3×3 first (~$15) to validate before committing to the 8×8 (~$30+).
- **Script architecture overhaul**: `99_assemble.py` is now a merger —
  preserves user-added components by UUID prefix instead of overwriting
  the whole schematic on every run. `01_skeleton.py` and `04_bulks.py`
  archived; only halls + LEDs regenerated by scripts now.
- **PCB layout script updated**: row bulks placed in the LEFT margin
  Y-aligned with each LED row; J1 (J_CTRL) placed at center bottom edge
  on B.Cu, rotated 90°, with anchor shifted left 15.24 mm so the
  connector BODY (not pin 1) is centered.

### 2026-06-05

The TL;DR of 2026-06-05:

- Switched from monolithic single-PCB to a 2-PCB + flying-leads layout
  (matrix board + controller; panel components in the enclosure).
- Consolidated 40 discrete column-driver parts into one TBD62783A.
- Replaced 3 panel status LEDs with an SSD1306 I²C OLED.
- Replaced the entire discrete power chain (~25 parts: BQ24074 +
  TPS63060 + protection block) with one daughterboard module —
  initially the Adafruit PowerBoost 1000C, later switched to the
  **Seeed Lipo Rider Plus** ($4 on DigiKey, USB-C, 5V/2.4A boost +
  3V3/250mA output) because it's cheaper, USB-C, and lets us drop
  the AP2112K LDO too. Added a Schottky diode (SS14) between +5V_LED
  and DevKit pin 19 so the ESP32 can run on battery.
- Added analog battery state-of-charge monitor: R14/R15 voltage divider
  on M1's raw BAT pad (pin 6) → VBAT_MON → ESP32 GPIO34 ADC. Firmware
  shows battery percentage on the OLED. Cleaned up the leftover
  PowerBoost 1000C lib files from `hardware-controller/lib/`.
- **Locked the assembly layout** based on the user's enclosure mockup:
  controller PCB mounts **inverted** directly underneath the matrix PCB
  (components face the enclosure floor, bare B.Cu face up). J_MAIN
  (controller B.Cu, male) mates back-to-back with J_CTRL (matrix B.Cu,
  female). **No standoffs, no controller-side mounting holes, no ribbon
  cable** — the connector pair is the only mechanical join, and the
  matrix's bolting to the enclosure top frame carries the weight.
  LiPo battery sits alongside the controller PCB in the space between
  the matrix back and the enclosure floor. Side-mounted panel (OLED +
  3 buttons + USB-C panel-mount) on one wall of the enclosure.
- **Dropped the panel PCB entirely** — OLED + 3 panel-mount buttons
  on flying leads to the controller's `J3` (JST XH 10-pin).
- Kept the shrouded/keyed IDC footprint for the matrix cable.
- Rebrandled the project intent: this is a one-off learning project,
  not a product.

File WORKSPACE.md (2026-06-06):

# Workspace Guide

How to work on OpenChess without mixing old and new hardware assumptions.

## Active Sessions

| Session | cwd | Purpose |
|---|---|---|
| Hardware | `hardware/` | KiCad projects, schematic scripts, PCB layout planning |
| Planning | repo root | Design decisions, docs, task planning |
| Firmware | `firmware/` | ESP32 firmware and web UI |
| Mechanical | `mechanical/` | Case, panel mounting, pieces |

## Hardware Projects

Open these KiCad projects directly:

- `hardware/hardware-board/openchess-board.kicad_pro`
- `hardware/hardware-controller/openchess-controller.kicad_pro`
- `hardware/hardware-control-panel/openchess-control-panel.kicad_pro`

Close KiCad before running schematic scripts. KiCad lock files are real; stale
locks may remain after crashes, but check with `lsof` before removing them.

## Scripted Schematic Workflow

From `hardware/`:

```bash
for s in hardware-board/scripts/sch/[0-9][0-9]_*.py; do python3 "$s"; done
for s in hardware-controller/scripts/sch/[0-9][0-9]_*.py; do python3 "$s"; done
for s in hardware-control-panel/scripts/sch/[0-9][0-9]_*.py; do python3 "$s"; done
```

Run ERC after generation:

```bash
/Applications/KiCad/KiCad.app/Contents/MacOS/kicad-cli sch erc --severity-all hardware-board/openchess-board.kicad_sch
/Applications/KiCad/KiCad.app/Contents/MacOS/kicad-cli sch erc --severity-all hardware-controller/openchess-controller.kicad_sch
/Applications/KiCad/KiCad.app/Contents/MacOS/kicad-cli sch erc --severity-all hardware-control-panel/openchess-control-panel.kicad_sch
```

## Current Hardware Priorities

1. Keep pinout contracts in `docs/inter-board-connector.md` and `hardware/DESIGN_NOTES.md` aligned with script `config.py` files.
2. Finish controller schematic chunks before PCB layout.
3. Build a 4x4 matrix prototype before ordering a full 8x8 matrix board.
4. Treat archived rev0.1 docs as historical only.

## KiCad Shortcuts

### Schematic

| Key | Action |
|---|---|
| `A` | Add symbol |
| `P` | Add power port |
| `L` | Add label |
| `W` | Draw wire |
| `Q` | Add no-connect flag |
| `M` | Move |
| `G` | Drag while preserving connections |
| `R` | Rotate |
| `E` | Edit properties |
| `Cmd+F` | Find reference |

### PCB

| Key | Action |
|---|---|
| `M` | Move |
| `G` | Drag |
| `R` | Rotate |
| `F` | Flip side |
| `X` | Route track |
| `B` | Refill zones |
| `Home` | Zoom to fit |

## Do Not Use As Active Guidance

These are historical or stale unless explicitly re-reviewed:

- `docs/archive/rev0.1/`
- old integrated-board files in `delete/old-hardware-2026-06-04/`
- old references to `hardware/openchess.kicad_sch` or `led_chain.kicad_sch`

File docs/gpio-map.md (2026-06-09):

# ESP32 GPIO Map

This is a provisional controller-board GPIO plan. It must be finalized when the
ESP32 footprint and column-driver approach are chosen, then kept in sync with
firmware and controller schematic scripts.

Last updated: 2026-06-07.

## Current Nets To Support

| Group | Nets | Notes |
|---|---|---|
| Matrix row sense | `S0..S7` | ESP32 inputs. Row pullups (R1–R8, 10 k to `+3.3V`) on the controller are kept for safety, but DRV5032FC Halls have push-pull outputs so the pullups are electrically redundant. |
| Column drive (internal) | `COL_DRV_A..COL_DRV_H` | ESP32 active-high inputs to TBD62783A 8-ch high-side driver IC |
| Matrix columns (connector) | `CA_PWR..CH_PWR` | TBD62783A outputs — switched 5V column rails |
| LEDs | `LED_DATA` (3V3), `LED_DATA_5V` (post-shift) | ESP32 data level-shifted to 5V via 74AHCT125 |
| Control panel display | `I2C_SDA`, `I2C_SCL` | SSD1306 OLED on panel (replaces status LEDs) |
| Control panel buttons | `BTN_POWER`, `BTN_MODE`, `BTN_SELECT` | POWER + MODE (input-only, ext pullups); SELECT on GPIO2 (internal pullup) |
| Battery monitor | `VBAT_MON` (analog) | R14/R15 voltage divider on Lipo Rider Plus M1 pin 6 (raw BAT pad) → GPIO34 (ADC1_CH6). Firmware reads battery voltage via `esp_adc_cal_*`. |
| Spare panel GPIO | `PANEL_SPARE`, `PANEL_SPARE2` | Reserved at J_PANEL pins 8 and 9 |
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

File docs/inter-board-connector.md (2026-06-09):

# Board Connector Contracts

Current hardware has three boards:

- `hardware-board`: matrix board
- `hardware-controller`: controller/power/driver board
- `hardware-control-panel`: cable-mounted controls/status board

## Matrix Connector: `J_CTRL` / `J_MAIN`

The matrix board connector is `J_CTRL`; the controller-side mate is `J_MAIN`.
Both share the same 2×13 pinout below, but use different **footprints**
because the boards stack directly (no ribbon cable). The controller
mounts **inverted** under the matrix — components face the enclosure
floor and the bare B.Cu side faces up toward the matrix's B.Cu, so
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

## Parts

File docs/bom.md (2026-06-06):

# Prototype BOM

This is a human-readable planning BOM for the current split-board prototype.
The schematic remains the source of truth for exact refs and machine exports.

Last refreshed: 2026-06-05.

## Matrix Board (`hardware-board`)

| Part | Qty | Refs / Notes |
|---|---:|---|
| A3144 Hall sensor, TO-92 | 64 | `U1..U64`; cheap prototype choice |
| WS2812B 5050 LED | 81 | `D1..D81`; PCBA strongly preferred |
| 100nF capacitor, 0805 | 81 | `C10..C90`; one per WS2812B |
| 47uF capacitor, 1206 | 9 | `C1..C9`; one per LED row |
| 470uF electrolytic, 10V | 1 | `C91`; `+5V_LED` entry cap |
| 2x13 connector | 1 | `J_CTRL`; mates to controller `J_MAIN` |
| Test pads, fiducials, M3 holes | as scripted | For bring-up, assembly, mounting |

## Controller Board (`hardware-controller`)

Already scripted:

| Part | Qty | Refs / Notes |
|---|---:|---|
| 2x13 connector | 1 | `J_MAIN`; matrix connector |
| 10k resistor, 0805 | 8 | `R1..R8`; row pullups to `+3V3` |
| Test pads, fiducials, M3 holes | as scripted | Current schematic chunk |

Still to decide/script:

| Block | Likely Parts |
|---|---|
| ESP32 | Devkit/socket for prototype, or bare ESP32-WROOM module |
| Power | USB/5V input first, or LiPo charger/boost immediately |
| Column drivers | Direct GPIOs if possible, or 74HC595 + transistor switches |
| LED data level shifter | Single-channel 3.3V -> 5V shifter preferred |
| Control-panel connector | Matching `J_PANEL` connector |

## Control Panel (`hardware-control-panel`)

| Part | Qty | Refs / Notes |
|---|---:|---|
| 1x10 connector | 1 | `J_PANEL`; cable to controller |
| Normal LED, 0805 | 3 | `D1..D3`: PWR, CONN, BATT |
| 1k resistor, 0805 | 3 | `R1..R3`; LED current limit |
| Momentary pushbutton | 3 | `SW1..SW3`: POWER, MODE, RESET |
| Test pads, fiducials, M3 holes | as scripted | Bring-up and mounting |

## Buying Notes

- Buy 100 A3144 sensors if using AliExpress; test a sample before soldering all 64.
- Buy WS2812B from LCSC/Worldsemi or another reputable source for the real board.
- Use JLCPCB/LCSC basic passives where possible for PCBA.
- Keep through-hole A3144 hand-soldered for the first prototype.
- Use PCBA for WS2812B LEDs, LED caps, and small passives where practical.

## Not Current

Old BOM lines for `BATT_LED1`, `D2..D82`, `led_chain.kicad_sch`, TP4056/MT3608
module headers, and one integrated PCB belong to the archived rev0.1 design and
should not be used as current ordering guidance.

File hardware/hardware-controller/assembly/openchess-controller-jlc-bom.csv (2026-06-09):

Comment | Designator | Footprint | JLCPCB Part #
10uF | C1,C2 | 0805
100nF | C5 | 0805
100nF | C11,C12 | 0603
SS14 | D2 | SMA
10k | R1,R2,R3,R4,R5,R6,R7,R8 | 0805
33R | R11 | 0603
220k | R14 | 0603
100k | R15 | 0603
10k | R36,R37 | 0603
74AHCT125 | U3 | SOIC-14_3.9x8.7mm_P1.27mm

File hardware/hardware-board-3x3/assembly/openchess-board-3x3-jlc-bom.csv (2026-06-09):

Comment | Designator | Footprint | JLCPCB Part #
47uF | C1,C2,C3,C4 | 1206
100nF | C10,C11,C12,C13,C14,C15,C16,C17,C18,C19,C20,C21,C22,C23,C24,C25 | 0805
WS2812B | D1,D2,D3,D4,D5,D6,D7,D8,D9,D10,D11,D12,D13,D14,D15,D16 | LED-WS2812B_5050
DRV5032FC | U1,U2,U3,U4,U5,U6,U7,U8,U9 | SOT-23

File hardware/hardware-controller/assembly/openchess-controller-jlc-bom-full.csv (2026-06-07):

Comment | Designator | Footprint | JLCPCB Part #
10uF | C1,C2 | 0805
100nF | C5 | 0805
100nF | C11,C12 | 0603
SS14 | D2 | SMA
10k | R1,R2,R3,R4,R5,R6,R7,R8 | 0805
33 | R11 | 0603
220k | R14 | 0603
100k | R15 | 0603
10k | R36,R37 | 0603
74AHCT125 | U3 | SOIC-14
TBD62783APG | U6 | DIP-18
Header-Female-1x8-2.54mm | M1 | Header-Female-1x8-2.54mm-Vertical
Header-Male-2x13-2.54mm | J1 | Header-Male-2x13-2.54mm-Vertical
JST-XH-1x10-2.5mm | J3 | JST-XH-B10B-XH-A

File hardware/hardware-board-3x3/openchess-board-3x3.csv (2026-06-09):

Id | Designator | Footprint | Quantity | Designation | Supplier and ref
1 | C1, C2, C3, C4 | C_1206_3216Metric | 4 | 47uF
2 | C10, C11, C12, C13, C14, C15, C16, C17, C18, C19, C20, C21, C22, C23, C24, C25 | C_0805_2012Metric_Pad1.18x1.45mm_HandSolder | 16 | 100nF
3 | D1, D2, D3, D4, D5, D6, D7, D8, D9, D10, D11, D12, D13, D14, D15, D16 | LED_WS2812B_PLCC4_5.0x5.0mm_P3.2mm | 16 | WS2812B
4 | J1 | PinSocket_2x13_P2.54mm_Vertical | 1 | Conn_02x13
5 | U1, U2, U3, U4, U5, U6, U7, U8, U9 | SOT-23 | 9 | DRV5032FC

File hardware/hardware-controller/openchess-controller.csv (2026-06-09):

Id | Designator | Footprint | Quantity | Designation | Supplier and ref
1 | C1, C2 | C_0805_2012Metric | 2 | 10µF
2 | C5 | C_0805_2012Metric | 1 | 100nF
3 | C11, C12 | C_0603_1608Metric | 2 | 100nF
4 | D2 | D_SMA | 1 | SS14 (or BAT60A)
5 | FID1, FID2, FID3 | Fiducial_1mm_Mask2mm | 3 | Fiducial
6 | J1 | PinHeader_2x13_P2.54mm_Vertical | 1 | Conn_02x13
7 | J3 | PinHeader_1x10_P2.54mm_Vertical | 1 | J_PANEL XH-10
8 | M1 | PinSocket_1x08_P2.54mm_Vertical | 1 | Lipo Rider Plus
9 | R1, R2, R3, R4, R5, R6, R7, R8 | R_0805_2012Metric | 8 | 10k
10 | R11 | R_0603_1608Metric | 1 | 33Ω
11 | R14 | R_0603_1608Metric | 1 | 220k
12 | R15 | R_0603_1608Metric | 1 | 100k
13 | R36, R37 | R_0603_1608Metric | 2 | 10k
14 | U2 | ESP32-DevKitC | 1 | ESP32-DevKitC
15 | U3 | SOIC-14_3.9x8.7mm_P1.27mm | 1 | 74AHCT125
16 | U6 | DIP-18_W7.62mm | 1 | TBD62783A

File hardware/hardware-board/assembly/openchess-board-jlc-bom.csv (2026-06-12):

Comment | Designator | Footprint | JLCPCB Part #
47uF | C1,C2,C3,C4,C5,C6,C7,C8,C9 | 1206 | C96123
100nF | C10,C11,C12,C13,C14,C15,C16,C17,C18,C19,C20,C21,C22,C23,C24,C25,C26,C27,C28,C29,C30,C31,C32,C33,C34,C35,C36,C37,C38,C39,C40,C41,C42,C43,C44,C45,C46,C47,C48,C49,C50,C51,C52,C53,C54,C55,C56,C57,C58,C59,C60,C61,C62,C63,C64,C65,C66,C67,C68,C69,C70,C71,C72,C73,C74,C75,C76,C77,C78,C79,C80,C81,C82,C83,C84,C85,C86,C87,C88,C89,C90 | 0805 | C49678
WS2812B | D1,D2,D3,D4,D5,D6,D7,D8,D9,D10,D11,D12,D13,D14,D15,D16,D17,D18,D19,D20,D21,D22,D23,D24,D25,D26,D27,D28,D29,D30,D31,D32,D33,D34,D35,D36,D37,D38,D39,D40,D41,D42,D43,D44,D45,D46,D47,D48,D49,D50,D51,D52,D53,D54,D55,D56,D57,D58,D59,D60,D61,D62,D63,D64,D65,D66,D67,D68,D69,D70,D71,D72,D73,D74,D75,D76,D77,D78,D79,D80,D81 | LED-WS2812B_5050 | C2761795
DRV5032FC | U1,U2,U3,U4,U5,U6,U7,U8,U9,U10,U11,U12,U13,U14,U15,U16,U17,U18,U19,U20,U21,U22,U23,U24,U25,U26,U27,U28,U29,U30,U31,U32,U33,U34,U35,U36,U37,U38,U39,U40,U41,U42,U43,U44,U45,U46,U47,U48,U49,U50,U51,U52,U53,U54,U55,U56,U57,U58,U59,U60,U61,U62,U63,U64 | SOT-23 | C527532

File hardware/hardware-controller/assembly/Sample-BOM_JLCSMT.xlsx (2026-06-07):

Comment | Designator | Footprint | JLCPCB Part #（optional）
100uF | C1 | CAP-SMD_L3.5-W2.8 | C16133
15K | R5,R6 | R0603 | C22809
DC-005-20A_C136744 | DC1 | DC-IN-TH_DC-005-20A | C136744
Header-Female-2.54_1x8 | P2,P3 | HDR-TH_8P-P2.54-V | C27438
K2-1102DP-C4SW-04 | SW1 | KEY-TH_4P-L6.0-W6.0-P4.50-LS6.5 | C110153
ATMEGA328P-PU | U1 | DIP-28_L34.6-W7.3-P2.54-LS10.2-BL | C33901
670688000 | USB1 | USB-B-TH_67068-8000 | C114097

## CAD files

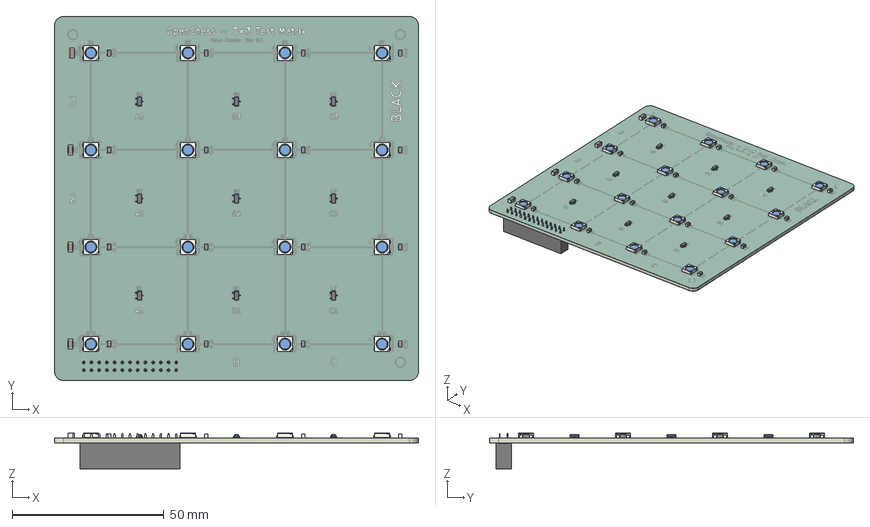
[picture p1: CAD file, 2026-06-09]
hardware/hardware-board-3x3/openchess-board-3x3.step
120.0 x 120.0 x 11.8 mm
LED_WS2812B_PLCC4_50x50mm_P32mm x 16
C_0805_2012Metric x 16
SOT-23 x 9
C_1206_3216Metric x 4
PinSocket_2x13_P2.54mm_Vertical
openchess-board-3x3_silkscreen x 2
openchess-board-3x3_soldermask x 2
openchess-board-3x3_PCB

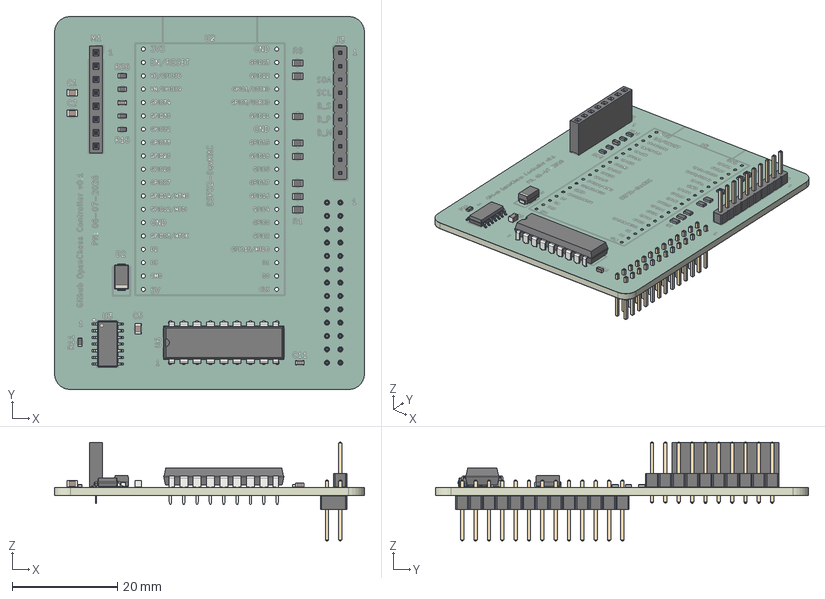
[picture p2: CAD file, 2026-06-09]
hardware/hardware-controller/openchess-board-3x3.step
59.0 x 71.0 x 18.8 mm
R_0603_1608Metric x 5
PinSocket_1x08_P2.54mm_Vertical
R_0805_2012Metric x 8
D_SMA
C_0805_2012Metric x 3
DIP-18_W7.62mm
PinHeader_1x10_P254mm_Vertical
C_0603_1608Metric x 2
SOIC-14_3.9x8.7mm_P1.27mm
PinHeader_2x13_P254mm_Vertical
openchess-controller_silkscreen x 2
openchess-controller_soldermask x 2
openchess-controller_PCB

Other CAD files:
hardware/hardware-controller/openchess-controller.step

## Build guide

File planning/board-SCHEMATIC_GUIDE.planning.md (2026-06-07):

# Matrix Board Schematic — Spec

Build sheet for the OpenChess matrix PCB. Documents every component, every pin, and every net.

236 components total, all passive:
- 64× A3144 Hall sensors
- 81× WS2812B LEDs (daisy-chained, row-major)
- 81× 100 nF per-LED decoupling caps
- 9× 47 µF row bulk caps
- 1× 470 µF entry cap
- 1× J_CTRL 2×13 stacking socket
- 4× test points, 4× M3 mounting holes, 3× fiducials

The schematic is **script-generated** at `scripts/sch/` (ERC clean).

---

## 1. Net list (every label on this board)

**Power & data:**
- `+5V_LED` — 5 V supplied by controller through J1 (consume only — needs PWR_FLAG)
- `GND` — ground (consume only — needs PWR_FLAG)
- `LED_DATA_5V` — WS2812 chain input at D1 (from controller, level-shifted)
- `LED_DOUT_END` — last WS2812 DOUT, exposed as TP4

**Matrix interface (to J_CTRL):**
- `S0..S7` — row sense, one per chess rank
- `CA_PWR..CH_PWR` — column power, one per chess file

Any other label is a typo.

---

## 2. Custom symbol

| lib_id | Description | Location |
|---|---|---|
| `openchess:A3144` | A3144 Hall sensor (TO-92, 3-pin) | `hardware-board/lib/openchess.kicad_sym` |

Other symbols are stock KiCad: `LED:WS2812B`, `Device:C`, `Device:C_Polarized`, `Connector_Generic:Conn_02x13_Odd_Even`, `Connector:TestPoint`, `Mechanical:MountingHole`, `Mechanical:Fiducial`, `power:PWR_FLAG`.

---

## 3. Section A — Hall sensor grid (`U1..U64`)

### A.1 Component template

| Field | Value |
|---|---|
| Symbol | `openchess:A3144` |
| Value | `A3144` |
| Footprint | `Package_TO_SOT_THT:TO-92_Inline` |

Pin map: 1=VCC, 2=GND, 3=OUT (open-collector).

### A.2 Ref scheme

```
ref(file_idx, rank_idx) = U{1 + file_idx * 8 + rank_idx}
   file_idx = 0..7 (files A..H)
   rank_idx = 0..7 (ranks 1..8)

U1=A1, U2=A2, …, U8=A8, U9=B1, U10=B2, …, U64=H8
```

### A.3 Per-sensor wiring

For Hall at file `F` (A..H) and rank `R` (1..8):

| Pin | Net |
|---|---|
| 1 (VCC) | Net label `C{F}_PWR` (e.g. `CA_PWR` for file A) |
| 2 (GND) | `GND` |
| 3 (OUT) | Net label `S{R-1}` (e.g. `S0` for rank 1) |

All 8 sensors in file A share `CA_PWR`. All 8 sensors in rank 1 share `S0`. Open-collector pull-down — pullups live on the controller (`R1..R8`).

---

## 4. Section B — WS2812B LED grid (`D1..D81`)

### B.1 Component template

| Field | Value |
|---|---|
| Symbol | `LED:WS2812B` |
| Value | `WS2812B` |
| Footprint | `LED_SMD:LED_WS2812B_PLCC4_5.0x5.0mm_P3.2mm` |

Pin map: 1=VDD, 2=DOUT, 3=VSS, 4=DIN.

### B.2 Ref scheme (row-major)

`D1` = top-left corner. `D9` = top-right of row 1. `D10..D18` = row 2 (left to right). … `D81` = bottom-right.

```
D1  D2  D3  D4  D5  D6  D7  D8  D9
D10 D11 D12 D13 D14 D15 D16 D17 D18
...
D73 D74 D75 D76 D77 D78 D79 D80 D81
```

### B.3 Chain wiring

| Pin | Net |
|---|---|
| 1 (VDD) | `+5V_LED` |
| 2 (DOUT) | Wire to next LED's Pin 4 (DIN); for `D81` → `LED_DOUT_END` |
| 3 (VSS) | `GND` |
| 4 (DIN) | Wire from previous LED's Pin 2 (DOUT); for `D1` → `LED_DATA_5V` |

Chain entry: `D1` Pin 4 = `LED_DATA_5V`.
Chain exit: `D81` Pin 2 = `LED_DOUT_END` (TP only).

The actual chain order between row-major and serpentine doesn't affect electrical correctness — only firmware indexing. Schematic chain follows raster row-major (D1→D2→…→D81 in linear order).

---

## 5. Section C — Per-LED decoupling (`C10..C90`)

One 100 nF cap per WS2812, placed adjacent on the PCB.

### C.1 Component template

| Field | Value |
|---|---|
| Symbol | `Device:C` |
| Value | `100nF` |
| Footprint | `Capacitor_SMD:C_0805_2012Metric_Pad1.18x1.45mm_HandSolder` |

### C.2 Ref pairing

`C{k+9}` pairs with `D{k}`. So `C10 ↔ D1`, `C11 ↔ D2`, …, `C90 ↔ D81`.

### C.3 Wiring (all 81 identical)

| Pin | Net |
|---|---|
| 1 | `+5V_LED` |
| 2 | `GND` |

PCB placement: within 3 mm of the paired LED's VDD pin.

---

## 6. Section D — Row bulk caps (`C1..C9`)

One bulk cap per row of the LED grid.

### D.1 Component template

| Field | Value |
|---|---|
| Symbol | `Device:C` |
| Value | `47uF` |
| Footprint | `Capacitor_SMD:C_1206_3216Metric` |

### D.2 Ref → row pairing

| Ref | LED row |
|---|---|
| C1 | D1..D9 (row 1) |
| C2 | D10..D18 (row 2) |
| C3 | D19..D27 |
| C4 | D28..D36 |
| C5 | D37..D45 |
| C6 | D46..D54 |
| C7 | D55..D63 |
| C8 | D64..D72 |
| C9 | D73..D81 (row 9) |

### D.3 Wiring (all 9 identical)

| Pin | Net |
|---|---|
| 1 | `+5V_LED` |
| 2 | `GND` |

---

## 7. Section E — Entry cap (`C91`)

Single 470 µF electrolytic at the J_CTRL entry to smooth the rail at its board entry point.

### E.1 Component

| Ref | Symbol | Value | Footprint |
|---|---|---|---|
| C91 | `Device:C_Polarized` | `470uF` | `Capacitor_THT:CP_Radial_D10.0mm_P5.00mm` |

### E.2 Wiring (polarity matters)

| Pin | Net |
|---|---|
| 1 (+, anode) | `+5V_LED` |
| 2 (−, cathode) | `GND` |

PCB placement: within ~10 mm of J1.

---

## 8. Section F — Matrix connector (`J1` = J_CTRL)

### F.1 Component

| Ref | Symbol | Value | Footprint |
|---|---|---|---|
| J1 | `Connector_Generic:Conn_02x13_Odd_Even` | `J_CTRL 2x13` | `Connector_PinSocket_2.54mm:PinSocket_2x13_P2.54mm_Vertical` |

**Female socket on the matrix PCB's BACK face.** Mates with controller J_MAIN's 2×13 male pin header on the controller's top face when the boards stack.

Mark Pin 1 with silkscreen dot.

### F.2 Pin-by-pin

| Pin | Net |
|----:|-----|
| 1 | `+5V_LED` |
| 2 | `GND` |
| 3 | `+5V_LED` |
| 4 | `GND` |
| 5 | `+5V_LED` |
| 6 | `GND` |
| 7 | `LED_DATA_5V` |
| 8 | `GND` |
| 9 | `S0` |
| 10 | `S1` |
| 11 | `S2` |
| 12 | `S3` |
| 13 | `S4` |
| 14 | `S5` |
| 15 | `S6` |
| 16 | `S7` |
| 17 | `CA_PWR` |
| 18 | `CB_PWR` |
| 19 | `CC_PWR` |
| 20 | `CD_PWR` |
| 21 | `CE_PWR` |
| 22 | `CF_PWR` |
| 23 | `CG_PWR` |
| 24 | `CH_PWR` |
| 25 | `+5V_LED` |
| 26 | `GND` |

Must mirror the controller's J_MAIN pinout exactly.

---

## 9. Section G — Test points, mounting, fiducials

### G.1 Test points

| Ref | Net |
|---|---|
| TP1 | `+5V_LED` |
| TP2 | `GND` |
| TP3 | `LED_DATA_5V` |
| TP4 | `LED_DOUT_END` |

Symbol `Connector:TestPoint`, footprint `TestPoint:TestPoint_Pad_D1.5mm`.

### G.2 Mechanical (no electrical connection)

| Ref | Symbol | Footprint |
|---|---|---|
| MH1..MH4 | `Mechanical:MountingHole` | `MountingHole:MountingHole_3.2mm_M3` |
| FID1..FID3 | `Mechanical:Fiducial` | `Fiducial:Fiducial_1mm_Mask2mm` |

MH1..MH4 must align with the controller PCB's MH1..MH4 so M3 standoffs thread through both boards.

### G.3 PWR_FLAGs

The matrix board only **consumes** `+5V_LED` and `GND`. Add `power:PWR_FLAG` symbols on both rails to satisfy ERC:

- One `PWR_FLAG` on `+5V_LED`
- One `PWR_FLAG` on `GND`

---

## 10. Validation rules

- Every Hall sensor `U{1 + file*8 + rank}` has VCC = `C{file_letter}_PWR` matching its file.
- Every Hall sensor has OUT = `S{rank}` matching its rank.
- Every WS2812 except `D1` has its DIN wired from the previous LED's DOUT.
- Every WS2812 except `D81` has its DOUT wired to the next LED's DIN.
- `D1` DIN = `LED_DATA_5V`. `D81` DOUT = `LED_DOUT_END`.
- Every `C{k+9}` pairs with `D{k}` — both on `+5V_LED` / `GND`.
- Every `C1..C9` on `+5V_LED` / `GND`.
- `C91` Pin 1 (+) on `+5V_LED`, Pin 2 (−) on `GND`.
- J1 pinout matches §8.2 exactly.
- PWR_FLAGs on `+5V_LED` and `GND`.

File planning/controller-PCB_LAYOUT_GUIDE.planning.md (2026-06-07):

# Controller PCB Layout — Spec

PCB layout constraints for the OpenChess controller. Companion to `controller-SCHEMATIC_GUIDE.planning.md`.

---

## 1. Board outline

- **Outline**: 2-layer rectangle, ~80 × 90 mm starting size (shrink to fit after placement).
- **Layer stack**: F.Cu (top) + B.Cu (bottom). Standard FR-4, 1.6 mm thick.
- **Edge.Cuts**: clean rectangle, drill origin at one corner.
- **Component side**: F.Cu (all SMD + module pads on top). B.Cu reserved for the GND pour and a few escape traces.

---

## 2. Mounting holes

| Ref | Position | Drill | Required |
|---|---|---|---|
| MH1 | Top-left corner, ~5 mm inset | 3.2 mm M3 | Yes |
| MH2 | Top-right corner, ~5 mm inset | 3.2 mm M3 | Yes |
| MH3 | Bottom-left corner, ~5 mm inset | 3.2 mm M3 | Yes |
| MH4 | Bottom-right corner, ~5 mm inset | 3.2 mm M3 | Yes |

**Critical constraint:** MH1..MH4 must align with the matrix PCB's MH1..MH4 so M3 standoffs (~11 mm tall) thread through both boards. Coordinate exact X/Y positions with the matrix PCB outline.

---

## 3. Component placement zones

Zones are arranged so the natural signal flow is **left → right → bottom**, with the connector edge at the bottom for clean stacking with the matrix.

| Zone | Components | Edge / position |
|---|---|---|
| **Top edge** | `M1` (Lipo Rider Plus), oriented so its USB-C jack and slide switch face the side wall of the enclosure | Top of board |
| **Near M1 (top area)** | `C1`, `C2` (10 µF bulk on `+5V_LED`) within 5 mm of M1 pin 4; `R14`, `R15` within 15 mm of M1 pin 6 | Adjacent to M1 |
| **Left half (center)** | `U2` ESP32-DevKitC socket (drawn as `J3` left + `J4` right sockets, 25.4 mm row pitch). Orient so USB-B faces the enclosure access edge (typically top or bottom). | Left center |
| **Right edge of U2** | `R1..R8` (row pullups), stacked vertically next to the matrix-scan GPIO pins (S0..S7 on the J4-side socket) | Right side of U2 |
| **Above U2 pin 19** | `D2` Schottky; anode toward M1's `+5V_LED` zone, cathode at DevKit pin 19 | Adjacent to U2 right side |
| **Near U2 GPIO34** | `C12` (ADC filter, 100 nF), within 5 mm of DevKit pin 5 (GPIO34) | Right side of U2 |
| **Between U2 and J1 (center-bottom)** | `U6` TBD62783A, rotated so outputs (O1..O8 / `CA_PWR..CH_PWR`) face J1. `C11` (100 nF) within 3 mm of U6 VCC pin. | Center-bottom |
| **Between U2 and J1 (next to U6)** | `U3` 74AHCT125 with `C5` (100 nF) within 3 mm of U3 pin 14. `R11` (33 Ω) immediately at U3 pin 3 output, in series toward J1 pin 7. | Center-bottom |
| **Bottom edge** | `J1` (J_MAIN), 2×13 male pin header, horizontal across the bottom edge; pin 1 marked with silkscreen dot | Bottom edge |
| **Side edge** | `J3` (J_PANEL JST XH 10-pin), polarized notch facing the enclosure panel side | One side edge |
| **Near J_PANEL pins 6, 7** | `R36`, `R37` (button pullups), within 10 mm of J_PANEL pins 6 and 7 *or* alternatively within 5 mm of DevKit GPIO36/39 pins — pick the location with the shorter signal trace | Near J_PANEL or U2 |
| **Anywhere on F.SilkS** | `TP1` (+5V_LED), `TP2` (+3V3), `TP3` (GND); `FID1`, `FID2` non-collinear on F.Cu, ≥5 mm from edge | Free placement |

### 3.1 Orientation rules

- **M1**: USB-C jack and slide switch must face the **enclosure side wall** (so they're accessible without disassembly). The 8-pin header points away from the wall.
- **U6**: rotate so its **output pins (O1..O8) face J1**, not away. This puts `CA_PWR..CH_PWR` on the J1 side of the chip and removes the rats-nest crossing.
- **U3**: input (pin 2 = `LED_DATA`) faces U2 (ESP32); output (pin 3) faces J1 with R11 inline.
- **J1**: pin 1 should be at the end closest to `U6` output O1 (`CA_PWR`) — minimizes the column bus length.

---

## 4. Net classes

| Net class | Members | Track width | Clearance |
|---|---|---|---|
| `Power_5V` | `+5V_LED` | **1.0 mm** | 0.15 mm |
| `Power_3V3` | `+3V3` | **0.5 mm** | 0.15 mm |
| `GND` | `GND` | **1.0 mm** for any trace (mostly a B.Cu pour) | 0.15 mm |
| `Default` | All signals (`S0..S7`, `CA_PWR..CH_PWR`, `LED_DATA`, `LED_DATA_5V`, `COL_DRV_*`, `BTN_*`, `I2C_*`, `VBAT_MON`, `BAT`) | 0.25 mm | 0.15 mm |

JLCPCB minimums (do not violate):
- Minimum track width: 0.15 mm
- Minimum clearance: 0.15 mm
- Minimum annular ring: 0.15 mm
- Minimum hole: 0.3 mm

---

## 5. Routing priority (hand-route in this order)

Hand-route the critical nets first. Auto-route everything else.

### 5.1 Power (route first, on F.Cu, fat traces)

1. **`+5V_LED`** trunk: M1 pin 4 → C1 → C2 → branch to U6 pin 9, U3 pin 14, D2 anode, J1 pins 1/3/5/25. Star from M1 if possible; 1.0 mm width.
2. **`+3V3`** trunk: M1 pin 1 → DevKit 3V3-consuming pin (NOT DevKit pin 1, which is NC) → branch to R1..R8 top pins, R36, R37, J_PANEL pin 1. 0.5 mm width.

### 5.2 High-speed signal integrity

3. **`LED_DATA`**: DevKit GPIO32 → U3 pin 2 (short, direct, no vias if possible).
4. **`LED_DATA_5V`**: U3 pin 3 → R11 → J1 pin 7 (short, no GND-plane breaks under this trace).

### 5.3 Sensitive analog

5. **`BAT` + `VBAT_MON`**: M1 pin 6 → R14 → junction (R15, C12, GPIO34). Keep `VBAT_MON` away from `LED_DATA*` and U6 outputs. Place `C12` next to GPIO34.

### 5.4 D2 path

6. **`+5V_LED` → D2 → DevKit pin 19**: 0.5 mm trace; carries ~150 mA when running on battery.

### 5.5 Column drive bus (8 parallel)

7. **`COL_DRV_A..H`**: 8 parallel traces from DevKit GPIOs to U6 inputs (I1..I8). Route as a horizontal bus.
8. **`CA_PWR..CH_PWR`**: 8 parallel traces from U6 outputs (O1..O8) to J1 column pins. Short and direct since U6 was rotated to face J1.

### 5.6 Row scan + panel

9. **`S0..S7`**: 8 traces from J1 row pins → R1..R8 pin 2 → DevKit GPIOs (R1..R8 each act as a tap point).
10. **`I2C_SDA`, `I2C_SCL`**: DevKit GPIO1/3 → J_PANEL pins 3/4. Route **around** M1 (do not pass under the module).
11. **`BTN_SELECT`, `BTN_POWER`, `BTN_MODE`**: J_PANEL pins 5/6/7 → DevKit GPIOs.

### 5.7 GND pour (last)

12. Fill `GND` zone on **B.Cu** covering the entire board outline. Thermal-relief connections to all GND pads. Verify continuity at every GND pad after fill.

---

## 6. GND pour spec

- **Layer**: B.Cu only (don't pour `GND` on F.Cu — leaves room for top-side signal escape).
- **Net**: `GND`.
- **Pad connection**: Thermal reliefs on all GND-net pads.
- **Outline**: follows the board's Edge.Cuts outline at 0.5 mm clearance.
- **Re-fill** after any move/route change.

If a GND pad shows an unrouted ratsnest line after pouring, place a via from F.Cu to B.Cu near that pad to bridge.

---

## 7. Silkscreen

| Item | Layer | Notes |
|---|---|---|
| Component refs | F.SilkS | Auto-placed, then nudged off pads. Keep readable orientation. |
| Pin 1 dot on J1 | F.SilkS | Required for assembly + matrix-board mating verification |
| Pin 1 indicator on M1 | F.SilkS | Required (matches module silkscreen) |
| Pin 1 indicator on U3, U6 | F.SilkS | Standard IC pin 1 marker |
| `+5V_LED`, `+3V3`, `GND` labels at TP1..TP3 | F.SilkS | Required for probing |
| Project title + rev | F.SilkS | "OpenChess Controller rev 0.1" in a corner |
| Net labels on key traces | F.SilkS (optional) | Useful if Flux is shown a render |

---

## 8. DRC rules

- **0 errors required** before fab.
- **Warnings acceptable** if intentional (e.g. single-pin `PANEL_SPARE*` nets that touch J_PANEL only — won't pass an "unconnected" check but is by design).

Common violations to expect during iteration:
- `Unconnected items` — net has unrouted ratsnest, finish the trace.
- `Clearance violation` — move two features apart.
- `Silkscreen overlapping pad` — reposition the silk text.

---

## 9. Mechanical verification

After placement and routing:

1. **3D view** check: M1 + 1.6 mm PCB ≤ 11 mm headroom (matches standoff height to matrix).
2. M1's USB-C jack faces a board edge (so the panel-mount USB-C extension cable can reach).
3. J1 (J_MAIN) and the matrix's J_CTRL pin-1 positions align when boards stack.
4. All 4 MH align with matrix MH positions.
5. J_PANEL connector points outward toward the panel edge of the enclosure.
6. No components extend past the board outline.

---

## 10. Fab output checklist

| File | Layer / contents |
|---|---|
| F.Cu, B.Cu | Copper |
| F.Mask, B.Mask | Solder mask |
| F.Silks, B.Silks | Silkscreen |
| Edge.Cuts | Board outline |
| `.drl` | Drill file (mm units, drill/place origin) |
| `BOM.csv` | Reference, value, footprint, LCSC part number (if JLC assembly) |
| `CPL.csv` | Component placement, mm, separate front/back |

JLCPCB defaults: FR-4, 2 layers, 1.6 mm thick, HASL or ENIG, green or matte black mask.

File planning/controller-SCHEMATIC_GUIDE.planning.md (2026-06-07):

# Controller Schematic — Spec

Build sheet for the OpenChess controller PCB. Every component, every pin, every net.

The cross-board contracts (J_MAIN ↔ matrix J_CTRL, J_PANEL → harness) live in `DESIGN_NOTES.planning.md` §3 and `docs/inter-board-connector.md`.

---

## 1. Reference designator map

| Ref | What |
|---|---|
| `M1` | Seeed Lipo Rider Plus (USB-C charging + 5V/2.4A boost + 3V3/250mA) |
| `D2` | Schottky diode (SS14 or BAT60A) — `+5V_LED` → DevKit pin 19 |
| `U2` | ESP32-DevKitC v4 module (drawn as two 1×19 sockets, `J3` left + `J4` right) |
| `U3` | 74AHCT125 LED data level shifter (3.3V→5V) |
| `U6` | TBD62783A 8-channel high-side column driver |
| `J1` | J_MAIN — 2×13 male pin header, board-to-board stacking to matrix (mates with matrix J_CTRL female socket on the matrix's back face) |
| `J3` (panel) | J_PANEL — JST XH 10-pin, plugs into the panel flying-lead harness *(separate from DevKit socket `J3` — distinct refs that must be deconflicted at annotation)* |
| `R1..R8` | Matrix row pullups (10 kΩ, `S0..S7` → `+3V3`) |
| `R11` | LED data series resistor (33 Ω, U3 output → J1) |
| `R14, R15` | Battery monitor divider (220 k top / 100 k bottom) |
| `R36, R37` | Panel button pullups (10 kΩ on `BTN_POWER`, `BTN_MODE`) |
| `C1, C2` | `+5V_LED` bulk caps (10 µF each, at M1's 5V output) |
| `C5` | 74AHCT125 decoupling (100 nF) |
| `C11` | TBD62783A decoupling (100 nF) |
| `C12` | VBAT_MON ADC filter (100 nF) |
| `BT1` | LiPo cell — documentation symbol only, `(in_bom no)` |
| `TP1..TP3` | Test points: `+5V_LED`, `+3V3`, `GND` |
| `MH1..MH4` | M3 mounting holes (4 corners; must align with matrix MH1..MH4) |
| `FID1, FID2` | Fiducials |

---

## 2. Net list (every label on this board)

**Power rails:**
- `+5V_LED` — 5V from M1 pin 4; powers WS2812 chain (via J1), U3 VCC, U6 VCC, D2 anode
- `+3V3` — direct from M1 pin 1 (no LDO on this PCB); powers ESP32 (DevKit), pullups, OLED via J_PANEL
- `GND` — ground
- `BAT` — raw battery from M1 pin 6, only goes to R14 (battery monitor)

**Matrix interface (to J1 = J_MAIN):**
- `S0..S7` — row sense, ESP32 inputs (pulled up by R1..R8)
- `CA_PWR..CH_PWR` — column power, from U6 outputs
- `LED_DATA_5V` — WS2812 chain data input (post U3 + R11)

**Controller-internal:**
- `LED_DATA` — 3.3V WS2812 data from ESP32 GPIO32 to U3 input
- `COL_DRV_A..COL_DRV_H` — 3.3V column-drive signals from ESP32 to U6 inputs
- `VBAT_MON` — analog battery voltage at the R14/R15/C12 junction → ESP32 GPIO34 ADC

**Panel interface (to J_PANEL):**
- `I2C_SDA` — ESP32 GPIO1 ↔ OLED
- `I2C_SCL` — ESP32 GPIO3 → OLED
- `BTN_SELECT` — ESP32 GPIO2 ← panel SELECT button
- `BTN_POWER` — ESP32 GPIO36 ← panel POWER button (pullup R36)
- `BTN_MODE` — ESP32 GPIO39 ← panel MODE button (pullup R37)
- `PANEL_SPARE`, `PANEL_SPARE2` — reserved (single-pin nets, ERC warning expected)

Any other label is a typo.

---

## 3. Section A — Power

### A.1 Components

| Ref | Symbol | Value | Footprint |
|---|---|---|---|
| M1 | `Connector_Generic:Conn_01x08` | Lipo Rider Plus | `LipoRiderPlus:MODULE_106990290` |
| D2 | `Device:D_Schottky` | SS14 or BAT60A | `Diode_SMD:D_SMA` |
| C1 | `Device:C` | 10µF | `Capacitor_SMD:C_0805_2012Metric` |
| C2 | `Device:C` | 10µF | `Capacitor_SMD:C_0805_2012Metric` |
| R14 | `Device:R` | 220k | `Resistor_SMD:R_0603_1608Metric` |
| R15 | `Device:R` | 100k | `Resistor_SMD:R_0603_1608Metric` |
| C12 | `Device:C` | 100nF | `Capacitor_SMD:C_0603_1608Metric` |
| BT1 | `Device:Battery_Cell` | LiPo 1S 3.7V (protected) | — *(off-board, `(in_bom no)`)* |

**Important M1 footprint/symbol note:** the symbol is a **generic** `Conn_01x08`, **not** SnapEDA's `106990290.kicad_sym`. SnapEDA's symbol has reversed pin-number-to-name mapping vs. the silkscreen; using the generic with manual pin labels is required to keep the schematic and PCB matched to the physical module.

### A.2 M1 pin-by-pin

M1 has 8 labeled solder pads in a single row. Pin numbers match the silkscreen (left-to-right, JST side first).

| M1 pin | Module pad | Net | Notes |
|---:|---|---|---|
| 1 | `3V3` | `+3V3` | Always-on 250 mA; this is the board's `+3V3` source. |
| 2 | `EN` | NC | We use M1's onboard slide switch instead; leave EN floating with a no-connect flag. |
| 3 | `GND` | `GND` | |
| 4 | `5V` | `+5V_LED` | Regulated 5V/2.4A boost output. |
| 5 | `GND` | `GND` | |
| 6 | `BAT` | wire to R14 pin 1 | Raw battery (3.0–4.2 V). Goes only to the battery monitor divider. |
| 7 | `GND` | `GND` | |
| 8 | `USB` | NC | Raw USB-C VBUS test pad. No-connect flag. |

M1's onboard slide switch must be in the **ON** position during assembly.

### A.3 D2 — Schottky for ESP32 power path

| Pin | Net |
|---|---|
| Anode | `+5V_LED` |
| Cathode | Wire to DevKit pin 19 (U2 module pin labeled `5V`) |

Allows current `+5V_LED → DevKit pin 19` (forward, ~0.3 V drop → ~4.8 V → DevKit's AMS1117 → ESP32 internal 3V3). Blocks backfeed when DevKit USB and M1 USB-C are both plugged.

### A.4 Battery monitor (R14, R15, C12)

| Component | Pin 1 | Pin 2 |
|---|---|---|
| R14 (220k) | wire from M1 pin 6 (`BAT`) | junction `VBAT_MON` |
| R15 (100k) | junction `VBAT_MON` | `GND` |
| C12 (100nF) | junction `VBAT_MON` | `GND` |

Net label `VBAT_MON` at the 3-way junction → ESP32 module pin 5 (DevKit physical pin 5 = GPIO34, ADC1_CH6).

Divider math: `VBAT_MON = BAT × 0.3125`. Range: 0.94 V (empty) to 1.31 V (full).

**Place C12 physically next to GPIO34** (the ADC input), not next to R14/R15 — C12 is the filter at the ADC, not at the divider.

### A.5 +5V_LED bulk caps (C1, C2)

| Pin | Net |
|---|---|
| 1 | `+5V_LED` |
| 2 | `GND` |

Place C1 within 5 mm of M1 pin 4. Place C2 downstream where `+5V_LED` enters the U3/U6/J1 zone.

---

## 4. Section B — J_MAIN (`J1`) — to matrix

### B.1 Component

| Ref | Symbol | Value | Footprint |
|---|---|---|---|
| J1 | `Connector_Generic:Conn_02x13_Odd_Even` | J_MAIN 2x13 | `Connector_PinHeader_2.54mm:PinHeader_2x13_P2.54mm_Vertical` |

**2×13 male pin header on the controller PCB's top face, board-to-board stacking.** Mates with the matrix board's 2×13 female socket (J_CTRL) on the matrix's back face. No ribbon cable. Mark Pin 1 with silkscreen dot.

The mating depth of the pin+socket combo sets the standoff height (~11 mm).

### B.2 Pin-by-pin

| Pin | Net |
|----:|-----|
| 1 | `+5V_LED` |
| 2 | `GND` |
| 3 | `+5V_LED` |
| 4 | `GND` |
| 5 | `+5V_LED` |
| 6 | `GND` |
| 7 | `LED_DATA_5V` |
| 8 | `GND` |
| 9 | `S0` |
| 10 | `S1` |
| 11 | `S2` |
| 12 | `S3` |
| 13 | `S4` |
| 14 | `S5` |
| 15 | `S6` |
| 16 | `S7` |
| 17 | `CA_PWR` |
| 18 | `CB_PWR` |
| 19 | `CC_PWR` |
| 20 | `CD_PWR` |
| 21 | `CE_PWR` |
| 22 | `CF_PWR` |
| 23 | `CG_PWR` |
| 24 | `CH_PWR` |
| 25 | `+5V_LED` |
| 26 | `GND` |

Must mirror the matrix's J_CTRL pinout exactly (matrix PCB documents the same table in its own guide).

---

## 5. Section C — Row pullups (`R1..R8`)

### C.1 Components (all 8 identical)

| Ref | Symbol | Value | Footprint |
|---|---|---|---|
| R1..R8 | `Device:R` | 10k | `Resistor_SMD:R_0805_2012Metric` |

### C.2 Wiring

For each `R{k}` (k = 1..8):

| Pin | Net |
|---|---|
| 1 | `+3V3` |
| 2 | `S{k-1}` (so R1→S0, R2→S1, …, R8→S7) |

These hold the open-collector matrix row outputs HIGH by default.

PCB placement: within ~5 mm of the corresponding ESP32 GPIO that reads `S0..S7`.

---

## 6. Section D — ESP32-DevKitC sockets (`J3`, `J4`)

U2 represents the ESP32-DevKitC v4 module plugged into two 1×19 female sockets at 25.4 mm row pitch. The schematic draws them as two separate symbols.

### D.1 Components

| Ref | Symbol | Value | Footprint |
|---|---|---|---|
| J3 (DevKit left) | `Connector_Generic:Conn_01x19` | DevKit left strip | `Connector_PinSocket_2.54mm:PinSocket_1x19_P2.54mm_Vertical` |
| J4 (DevKit right) | `Connector_Generic:Conn_01x19` | DevKit right strip | `Connector_PinSocket_2.54mm:PinSocket_1x19_P2.54mm_Vertical` |

J3 pins 1..19 correspond to DevKit physical pins 1..19. J4 pins 1..19 correspond to DevKit physical pins 20..38.

> Note: this `J3` (DevKit left socket) and the **panel `J3` (J_PANEL)** in §8 are two distinct components that happen to share the same human-facing name during the hand-draw. Annotate uniquely (e.g. rename DevKit socket to `J5`) before generating netlist.

### D.2 J3 (left strip, DevKit pins 1–19)

| J3 pin | DevKit | GPIO / function | Net or flag |
|---:|---:|---|---|
| 1 | 1 | 3V3 out (DevKit onboard LDO) | **NC** (we source +3V3 from M1, not from here) |
| 2 | 2 | EN / CHIP_PU | NC |
| 3 | 3 | GPIO36 / SVP (input-only) | `BTN_POWER` |
| 4 | 4 | GPIO39 / SVN (input-only) | `BTN_MODE` |
| 5 | 5 | GPIO34 / ADC1_CH6 (input-only) | `VBAT_MON` |
| 6 | 6 | GPIO35 (input-only) | `PANEL_SPARE` |
| 7 | 7 | GPIO32 | `LED_DATA` |
| 8 | 8 | GPIO33 | `COL_DRV_F` |
| 9 | 9 | GPIO25 | `COL_DRV_E` |
| 10 | 10 | GPIO26 | `COL_DRV_D` |
| 11 | 11 | GPIO27 | `COL_DRV_C` |
| 12 | 12 | GPIO14 | `COL_DRV_B` |
| 13 | 13 | GPIO12 (MTDI strap — avoid HIGH at boot) | NC |
| 14 | 14 | GND | `GND` |
| 15 | 15 | GPIO13 | `COL_DRV_A` |
| 16 | 16 | GPIO9 / SD2 (flash) | NC |
| 17 | 17 | GPIO10 / SD3 (flash) | NC |
| 18 | 18 | GPIO11 / CMD (flash) | NC |
| 19 | 19 | 5V (DevKit USB VBUS input) | **D2 cathode** (from `+5V_LED` via D2) |

### D.3 J4 (right strip, DevKit pins 20–38)

| J4 pin | DevKit | GPIO / function | Net or flag |
|---:|---:|---|---|
| 1 | 20 | GPIO6 / CLK (flash) | NC |
| 2 | 21 | GPIO7 / SD0 (flash) | NC |
| 3 | 22 | GPIO8 / SD1 (flash) | NC |
| 4 | 23 | GPIO15 (boot strap HIGH) | `COL_DRV_H` |
| 5 | 24 | GPIO2 (boot strap LOW) | `BTN_SELECT` |
| 6 | 25 | GPIO0 (boot strap HIGH) | NC |
| 7 | 26 | GPIO4 | `S0` |
| 8 | 27 | GPIO16 | `S1` |
| 9 | 28 | GPIO17 | `S2` |
| 10 | 29 | GPIO5 (boot strap HIGH) | `COL_DRV_G` |
| 11 | 30 | GPIO18 | `S3` |
| 12 | 31 | GPIO19 | `S4` |
| 13 | 32 | GND | `GND` |
| 14 | 33 | GPIO21 | `S5` |
| 15 | 34 | GPIO3 / RXD0 (repurposed) | `I2C_SCL` |
| 16 | 35 | GPIO1 / TXD0 (repurposed) | `I2C_SDA` |
| 17 | 36 | GPIO22 | `S6` |
| 18 | 37 | GPIO23 | `S7` |
| 19 | 38 | GND | `GND` |

**UART0 (GPIO1/3) is repurposed as the I²C bus.** No serial debug on DevKit USB during normal operation.

---

## 7. Section E — LED level shifter (`U3` 74AHCT125)

74AHCT125 is a quad bus buffer. KiCad represents it as **5 units** (4 gates + 1 power unit) — all part of one physical chip.

### E.1 Components

| Ref | Symbol | Value | Footprint |
|---|---|---|---|
| U3 | `74xx:74AHCT125` | 74AHCT125 | `Package_SO:SOIC-14_3.9x8.7mm_P1.27mm` |
| R11 | `Device:R` | 33Ω | `Resistor_SMD:R_0603_1608Metric` |
| C5 | `Device:C` | 100nF | `Capacitor_SMD:C_0603_1608Metric` |

### E.2 U3 unit-by-unit

| Unit | Pin | Function | Net or flag |
|---|---:|---|---|
| A (live) | 1 | ~OE | `GND` (enable always on) |
| A (live) | 2 | A (input) | `LED_DATA` |
| A (live) | 3 | Y (output) | wire to R11 pin 1 |
| B (unused) | 4 | ~OE | `GND` |
| B (unused) | 5 | A | `GND` |
| B (unused) | 6 | Y | NC |
| C (unused) | 8 | Y | NC |
| C (unused) | 9 | A | `GND` |
| C (unused) | 10 | ~OE | `GND` |
| D (unused) | 11 | Y | NC |
| D (unused) | 12 | A | `GND` |
| D (unused) | 13 | ~OE | `GND` |
| E (power) | 7 | GND | `GND` |
| E (power) | 14 | VCC | `+5V_LED` |

### E.3 R11 (series damping)

| Pin | Net |
|---|---|
| 1 | wire from U3 pin 3 |
| 2 | `LED_DATA_5V` |

Place R11 immediately at U3's output pin.

### E.4 C5 (decoupling)

| Pin | Net |
|---|---|
| 1 | `+5V_LED` |
| 2 | `GND` |

Place within 3 mm of U3 pin 14 (VCC).

---

## 8. Section F — Column driver (`U6` TBD62783A)

8-channel high-side switch. Active-high inputs: ESP32 drives `COL_DRV_X` HIGH → internal PMOS connects output `CX_PWR` to `+5V_LED`.

### F.1 Components

| Ref | Symbol | Value | Footprint |
|---|---|---|---|
| U6 | `Transistor_Array:TBD62783A` | TBD62783A | `Package_DIP:DIP-18_W7.62mm` *or* `Package_SO:SOIC-18W_7.5x11.55mm_P1.27mm` |
| C11 | `Device:C` | 100nF | `Capacitor_SMD:C_0603_1608Metric` |

Pick DIP or SOIC variant before fab; same KiCad symbol works for both.

### F.2 U6 pin-by-pin (DIP-18 numbering)

| Pin | Name | Net |
|---:|---|---|
| 1 | I1 | `COL_DRV_A` |
| 2 | I2 | `COL_DRV_B` |
| 3 | I3 | `COL_DRV_C` |
| 4 | I4 | `COL_DRV_D` |
| 5 | I5 | `COL_DRV_E` |
| 6 | I6 | `COL_DRV_F` |
| 7 | I7 | `COL_DRV_G` |
| 8 | I8 | `COL_DRV_H` |
| 9 | VCC | `+5V_LED` |
| 10 | GND | `GND` |
| 11 | O8 | `CH_PWR` |
| 12 | O7 | `CG_PWR` |
| 13 | O6 | `CF_PWR` |
| 14 | O5 | `CE_PWR` |
| 15 | O4 | `CD_PWR` |
| 16 | O3 | `CC_PWR` |
| 17 | O2 | `CB_PWR` |
| 18 | O1 | `CA_PWR` |

### F.3 C11 (decoupling)

| Pin | Net |
|---|---|
| 1 | `+5V_LED` |
| 2 | `GND` |

Place within 3 mm of U6 pin 9 (VCC).

---

## 9. Section G — J_PANEL + button pullups

### G.1 Components

| Ref | Symbol | Value | Footprint |
|---|---|---|---|
| J3 (panel) | `Connector_Generic:Conn_01x10` | J_PANEL XH-10 | `Connector_JST:JST_XH_B10B-XH-A_1x10_P2.50mm_Vertical` |
| R36 | `Device:R` | 10k | `Resistor_SMD:R_0603_1608Metric` |
| R37 | `Device:R` | 10k | `Resistor_SMD:R_0603_1608Metric` |

(Disambiguate from DevKit socket `J3` during annotation.)

### G.2 J_PANEL pin-by-pin

| Pin | Net | ESP32 GPIO |
|---:|---|---|
| 1 | `+3V3` | — (powers OLED + R36/R37) |
| 2 | `GND` | — |
| 3 | `I2C_SDA` | GPIO1 |
| 4 | `I2C_SCL` | GPIO3 |
| 5 | `BTN_SELECT` | GPIO2 |
| 6 | `BTN_POWER` | GPIO36 (input-only) |
| 7 | `BTN_MODE` | GPIO39 (input-only) |
| 8 | `PANEL_SPARE` | (reserved, GPIO35) |
| 9 | `PANEL_SPARE2` | (reserved) |
| 10 | `GND` | — |

`PANEL_SPARE` / `PANEL_SPARE2` terminate at a single pin here → ERC single-pin-net warning is intentional.

### G.3 R36, R37 (button pullups)

| Ref | Pin 1 | Pin 2 |
|---|---|---|
| R36 | `+3V3` | `BTN_POWER` |
| R37 | `+3V3` | `BTN_MODE` |

`BTN_SELECT` is on GPIO2 which has an internal pullup (firmware-enabled); no external pullup needed.

PCB placement: R36/R37 within ~5 mm of the ESP32 GPIO36/39 pins on the DevKit socket.

---

## 10. Section H — Test points, mounting, fiducials

### H.1 Test points (rails only — minimum useful set)

| Ref | Net |
|---|---|
| TP1 | `+5V_LED` |
| TP2 | `+3V3` |
| TP3 | `GND` |

Symbol `Connector:TestPoint`, footprint `TestPoint:TestPoint_Pad_D1.5mm`. Other signals are accessible at chip pads or connector pins.

### H.2 Mechanical (no electrical connection)

| Ref | Symbol | Footprint |
|---|---|---|
| MH1..MH4 | `Mechanical:MountingHole` | `MountingHole:MountingHole_3.2mm_M3` |
| FID1, FID2 | `Mechanical:Fiducial` | `Fiducial:Fiducial_1mm_Mask2mm` |

MH1..MH4 must align with the matrix PCB's MH1..MH4 — M3 standoffs thread through both boards.

### H.3 PWR_FLAGs

Add `power:PWR_FLAG` on these nets so ERC sees a driver:
- `+5V_LED` (sourced externally by M1's boost — PWR_FLAG required)
- `+3V3` (sourced externally by M1's LDO — PWR_FLAG required)
- `GND`

---

## 11. Schematic validation rules

These should all hold after wiring. Useful for review.

1. Every `+3V3` consumer (R1..R8, R36, R37, J_PANEL pin 1, ESP32 socket 3V3 pin) is on the net sourced **only** from M1 pin 1. **DevKit's own 3V3 out (J3 pin 1) is NC**.
2. Every `+5V_LED` consumer (U3 VCC, U6 VCC, D2 anode, C1/C2, J1 pins 1/3/5/25) is on the net sourced **only** from M1 pin 4.
3. `BAT` net touches **only** M1 pin 6 and R14 pin 1. No other consumer.
4. `VBAT_MON` is a 3-way junction: R14 pin 2 + R15 pin 1 + C12 pin 1 + (wire to) DevKit pin 5 (GPIO34).
5. `LED_DATA` (3.3V) touches ESP32 GPIO32 and U3 unit A pin 2 (only).
6. `LED_DATA_5V` touches R11 pin 2 and J1 pin 7 (only).
7. `R11` sits in series between U3 unit A pin 3 (output) and J1 pin 7.
8. `D2` anode is on `+5V_LED`; cathode is wired **directly** to DevKit pin 19 (no shared net beyond that one wire).
9. Each `COL_DRV_X` net touches **exactly** one ESP32 GPIO pin and **exactly** one U6 input pin (I1..I8).
10. Each `CX_PWR` net touches **exactly** one U6 output pin (O1..O8) and **exactly** one J1 column-power pin.
11. Each `S0..S7` net touches **exactly** one ESP32 GPIO, **exactly** one row pullup (R1..R8) pin 2, and **exactly** one J1 row pin.
12. `BTN_POWER`, `BTN_MODE` each touch their ESP32 GPIO, their pullup (R36 or R37) pin 2, and J_PANEL pin 6 or 7.
13. `BTN_SELECT` touches DevKit GPIO2 pin and J_PANEL pin 5 only — no external pullup.
14. `I2C_SDA` touches DevKit GPIO1 pin and J_PANEL pin 3 only.
15. `I2C_SCL` touches DevKit GPIO3 pin and J_PANEL pin 4 only.
16. All flash pins (DevKit pins 16, 17, 18 on J3-left and pins 1, 2, 3 on J4-right) carry no-connect flags.
17. Both DevKit J3-left pin 1 (3V3 out) and pin 2 (EN) carry no-connect flags.
18. `PWR_FLAG` symbols exist on `+5V_LED`, `+3V3`, `GND`.
19. Two separate connectors share the human-name "J3" — DevKit socket and panel JST. Annotation must rename one (recommend DevKit socket → `J5`).

If any of the above fails, the schematic has an error.

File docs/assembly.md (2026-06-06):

# Assembly Guide

Status: early prototype guide. Update after the 4x4 and full-board prototypes
are physically built.

## Build Order

1. Generate and review schematics for all active boards.
2. Build a 4x4 matrix prototype variant before ordering the full 8x8 matrix.
3. Confirm Hall sensor orientation, magnet strength, LED chain behavior, and
   connector pinout on the small prototype.
4. Layout/order the full matrix board.
5. Layout/order the controller board.
6. Layout/order or hand-build the control panel.
7. Integrate firmware against real hardware.
8. Design the enclosure around the boards and cable exits.

## Matrix Board Notes

- Hand-solder A3144 TO-92 sensors for prototype boards.
- Prefer PCBA for WS2812B LEDs and their 100nF caps.
- Test LED continuity by row; one bad WS2812B can break all downstream LEDs.
- Confirm `+5V_LED`, `GND`, `LED_DATA_5V`, `S0..S7`, and `CA_PWR..CH_PWR` at
  `J_CTRL` before connecting the controller.

## Controller Board Notes

- Do not connect to the matrix until `J_MAIN` pinout has been checked against
  `docs/inter-board-connector.md`.
- Verify row pullups are to `+3V3`, not `+5V_LED`.
- Verify LED data is level-shifted before it leaves the controller.
- Power approach is still pending, so power-on steps must be updated once that
  circuit is chosen.

## Control Panel Notes

- LEDs are active-low: controller sinks `LED_*_N` nets.
- Buttons short `BTN_*` nets to `GND`; controller provides pullups.
- Cable orientation matters; mark pin 1 clearly on PCB and enclosure.

## Firmware Bring-Up

1. Flash ESP32 with a minimal board-test firmware.
2. Verify control-panel buttons and LEDs first.
3. Verify row sense pullups and column drive sequencing without the full matrix.
4. Connect the 4x4 matrix prototype.
5. Only then test the full 8x8 matrix.

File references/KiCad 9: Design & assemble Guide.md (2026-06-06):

---
title: "KiCad 9: Design & assemble an ESP32 IoT 4-layer PCB loaded with goodies **A Complete Guide**"
source: "https://www.youtube.com/watch?v=LO9AO0XTX3M"
author:
  - "[[Tech Explorations]]"
published: 2025-02-21
created: 2026-06-03
description: "In this comprehensive video, Peter from Tech Explorations takes you through the entire process of designing a custom IoT PCB using KiCad 9. From schematic cr..."
tags:
  - "clippings"
---


## Transcript

### Introduction

**0:00** · P here from Tech Explorations and welcome to this video where I'll guide you through the design of a custom PCP using Kad 9 I'll start by showing you what the final PCB of this work is going to look like and I um using the 3D

### Overview of the IoT PCB Design

**0:17** · viewer here in kick up 9 to show you I've already exported and sent this PCB out to next PCB uh the manufacturer that I've selected for this project who is also the sponsor of this video and I thank them for that so I'm expecting to get this manufactured PCB from next PCB

**0:36** · very soon so I can just do some Hands-On testing but until that happens I can show you what the 3D representation of this PCB looks like and just have a look at the various components that are on the PCB so let's say that this is a medium complexity PCB it's four layers in it it's got a bunch of integrated circuits on it it's powered by an ESP 32

**1:03** · uh C3 S2 as you can see up here the location of the components matters of course the location of things such as capacitors and connectors and so on is also important this is one of the things that I'll be going through in this video so this is what the PCB looks like eventually as you can see it's packed with a bunch of great features it's an iot development board designed from

**1:28** · scratch and I'm going to show you you how to design this from the very beginning which has to do for example with selecting appropriate components here's the bill of materials for the components a number of components here that are I guess non-trivial to include into a PCB like this we need to go through data sheets and figure out how to do the connections what kind of circuitry is required to provide Power grounding um this Thal concerns to look

**2:00** · into as well signal Integrity all those very interesting bits and pieces that are required to consider when you're designing a non-trivial PCB so we're going to do all that we're going to continue then with the schematic design going to go into a little bit more detail about what's happening here in the next segment of this video so there schematic design and then there is the layout here now one thing that I should

**2:26** · point out is that designing a board like this in real time takes time so I designed like this and assuming that I know what I'm doing but I don't have full knowledge of all the components that I'm working with some of those components I might be working for the first time ever meaning that I would have to do a bit of research about them read the data sheet understand how they work and then make them work with the rest of the components I'd say would take about 1 to two days for an experienced engineer of course don't

**2:56** · worry because in this video I have com pressed the entire process to make it fastpaced and engaging for you without skipping though any of the important steps that matter for learning how to design a medium complexity PCB like this one another thing to point out is that I am recording this video in kiab 9 rc1 so

**3:19** · that's release candidate one that became available in early January 2025 I'm expecting to see Ki out Version 9 the version published sometime in late February to early March but I don't expect any significant or even small changes really between the uh final version of kick at 9 the release version and the release candidate that I'm using

**3:47** · for this recording so you don't have to worry about any differences or changes between what you see in this video and what you will be seeing in kickout 9 okay so having said that let's have a look at at what this board contains just to get an idea of the complexity that's involved so I'll start from the right side and then move to the left so on the right side you see here the esp32 C3 S2

### Component Placement and Design Challenges

**4:13** · system on a chip just below it I've got an SD card this is remember an iot development board so you may want to use an SD card to do things such as data logging then I've got a flash memory also that can be used to store data from the various environmental measurements up here I've got the BME 280 environment

**4:37** · sensor you can use the sensor to capture temperature humidity and atmospheric pressure right here is an ambient light sensor so you can capture information about the light intensity up here there's a microphone for capturing sound

**4:58** · intensity right here I've got a USBC connector we'll be using this USBC connector for power and for data there's a couple of buttons on the right side enable and boot just to operate with the esp32 I've got integrated circuits here for the serial Communications so this chip here helps to manage the USB and the serial Communications of the board in this block here I've Got The Power regulator circuitry down here I've got

**5:29** · the battery management circuitry this a battery connector for a lipo battery plus its integrated circuit for managing charging of the battery and then finally I've got a couple of headers here you can connect those headers to things such as an O LED display or external components so this is a four layer PCB again kind of have a look inside see what's going on in the 3D representation

**6:00** · so four layer PCB I'm going to talk more about the details of the design of the PCB in the next segment of this video will cover everything from the design guidelines and the parts selection to creating the schematic routing the PCB and preparing it for manufacturing and I'll also show you how to order your board and get it assembled through next BCB who as I said earlier is the PCB

### Design Guidelines and Workflow Overview

**6:24** · manufacturer and assembler that are partnered with for this project and again I want to thank them for sponsoring this video now the goal here is to show you the complete workflow in a way that's both educational and fun and by the end of this video you'll have a better understanding of how to design your own intermediate level pcbs using

**6:45** · kick at 9 and then how to bring your designs to life with a manufacturer so grab your coffee or other beverage of choice fire up your copy of kiad and let's get started let's take a closer look at the I to develop a board with a better design I want to give you a sense of the high level design challenges and the decisions I've made along the way to ensure that this board meets its performance goals and is ready for manufacturing as you already know the board is powered by an esp32

### Operational Requirements and Component Selection

**7:17** · c302 system on a chip right here and of course there's a bunch of other components around it such as sensors and power circuitry Etc all these have to work together so one of the key decisions involved is signal conditioning to ensure clean and stable signals AED things such as decoupling capacitors as you can see right here this is one example at the input a power

**7:43** · input of the esp32 we place those capacitors near the power pins of each integrated circuit and these capacitors help to filter out noise and stabilized power supply additionally there are things such as pull up and pull down is this let me just find an example I'm just going to go to let's go to sensors where I know that

**8:07** · I had to use one of those yep so here's the um sensor for the BME 280 integrated circuit and there's a couple of pullup resistors for the and the SDA lines the I quid C interface so these ensure reliable communication and startup Behavior as well I've also included multiple capacitor sizes of course uh again the Capac sizes here's one example

**8:32** · here's another example this is for the SD card module there's a variation of values and we'll find the actual values in data sheets for the various devices but these capacitors both ceramic and talom are used to handle high frequency noise as well as low frequency fluctuations and the placement of these capacitors is critical especially near components like the esp32 uh an example

**8:59** · of this just going to make some room show you the two windows side by side you can see here is the capacitor just clicked on this is C8 which is very very close to the esp32 right on top of it

**9:16** · pretty much because that's what the specification and the data sheet requires and the role of this capacitor requires its position to be this close to the esp32 another thing that is important is finding appropriate components and just to manage my project

**9:35** · better I've sourced most of the components through Snap magic so here's one example for the buttons that I use and here's another example for the USBC connector so to save time and maintain accuracy even though some of those components are available from the KY out Library I decided at least for the most important ones not so much for the simple components such as the resistance but for the most important ones I decided to have a look at snap magic or

**10:06** · some other online distributor of Parts because the point here is not simply to design the board but also to ensure that it can be manufactured by a manufacturer such as next PCB so I've done my research mostly in snap magic and you can see here that this particular component that I've chosen is in stock which means that next PCB or your own manufacturer of choice will be able to also find it and include it in the bom you can see that in my bom this is

**10:39** · component let's go back to okay so here is the USB component you can see it's a click on it Kat uh PCB editor focuses to on the component and here is the component this is component J1 I go back to the bill of materials you can see the J1 is right here this is the information that I have included for the manufacturer and I also include information about the sourcing

**11:12** · of that material so that they can find it and order it and assemble the board although this is not strictly required I also decided to include reasonably representative 3D models for all of the components on the board and usually I can get those 3D models from the same

**11:30** · place where I Source my parts from again in this case is snap magic but there's many other places as well so for example when I look at the J1 USBC receptable which is this one here you can see if I double click on it I just need to actually get the filter to allow me to select a component you can see in the 3D models I've set the 3D model for this particular component to this so that when I bring up the 3D representation or

**12:03** · the model of the PCB that particular component is model I can see how it's placed on the board so aside from the satisfaction of visualizing and aesthetically pleasing PCB I can also visually confirm that there are no physical fit issues so now let's have a

**12:25** · look at some of the other details that I want to show you is just as we getting warmed up up for this project the first thing is in the schematic editor I've got a multi-page design approach because there quite a lot of components that are involved I didn't want to put them in the same page they would end up the project having a gigantic single page that would be very difficult to follow so I opted for a multi-page approach so

**12:53** · I've got the root page here uh which contains power management and battery charging circuits then I've got the second page down which contains the esp32 and uh SD card module USB module here in the flash memory another page is dedicated to the sensors and then finally the user interface where I've got things such as the OLED display connector break out for

**13:21** · a few unused gpios just so they not wasted I can connect them to external devices if I want to and then the reset and the boot buttons that's pretty much what you have in in this last user interface page when it comes to the layout let's have a look at the layout editor here I've opted for a four layer

**13:43** · PCB so you can see I've got four copper layers the top copper layer is used for signals so most of the signals and the signal routes are routed on the top side you can see additional signal routes in the bottom and then the first inner copper layer I've used it mostly for ground so I've got a a large ground Zone

**14:06** · you can see it here this border line you can see going around the board represents a ground Zone just going to double click on it so you can take a closer look so this one is ground and then I've got a bunch of other zones in the second inner copper layer which is uh the 3.3 volt layer I've got a actually in here you can see this one is 3.3 but Ki 9 also has a Zone

**14:38** · Manager which allows you to quickly inspect the various zones that have been created and you can see where they are as well in the various layers and you can quickly edit the

**14:53** · various characteristics and even give them a name so you can search for them later so I'll show you how to do all that as well last thing to comment before we move on to the next segment is that another thing that I've taken a lot of care to do is to select the appropriate widths for the various tracks and the V and those decisions are governed by the use of that particular track so for example you can see here this track uh is quite wide because it

**15:22** · conveys power essentially it feeds power to the entire board where other traces like this one here much smaller because they convey signals not power so they don't need to be as wide and something similar happens with things such as vs and also the decision to create things such as copper zones like this one here for example in order to enable better power transfer and improve the thermal

**15:51** · aspects of the design so that's an overview of the project and some of the key decisions that went into the design and it's really worth the time spent at the start of the project to plan and choose appropriate and available components reading the data sheets to

**16:07** · understand the signal conditioning and placement requirements and other requirements and managing the layout with proper use of layers and copper zones and all this will help to build a high quality PCB that will be economical to manufacture and of course fit for purpose designing an iot board involves balancing technical capabilities with real world constraint so in this segment of the video I'll talk a little bit about the operational requirements that guided the development of this custom esp32 board these are the things that I want to achieve by designing the board

**16:40** · and influence me in the various decisions that I had to make so after that I'll show you some of the sources that are used for things such as data sheets the actual physical components that will end up on the manufactured board and sources for the symbols Footprints and 3D models because I like to do all that as much as possible for

**16:59** · starting the actual design work in kiat there are two plus one top level requirements at gued my decision- making process the first one is that I wanted to create a board that would give me the opportunity to record this video the topic of the video as you know is to demonstrate the use of K at 9 in the design of a medium complexity PCB with

**17:21** · that in mind the second top level requirement was that this board should contain a modern microcontroller with wireless capabilities and lots of processing power that is connected to a reasonably complete array of components that would require the employment of at least four layers on this particular PCB

**17:44** · and the use of typical design techniques for epcp of this complexity and capabilities and the plus one top level requirement following the previous two is that at the end of the process I'd be able to manufacture this board in a modern manufacturing facility and in my

### Researching and Sourcing Components

**18:02** · case that's next PCP who is also sponsoring the video and you can see that the PCB right now is being manufactured so I should have it maybe in one or two weeks we'll see how that goes and I'll report on that later in this video with all that in mind you already know that the PCB that uh I'm designing in this video is built around the esp32 and I selected this MCU due to

**18:27** · its high processing power and integrated wireless communication it's got a dual core architecture and this ensures lots of available data processing power making it suitable for handling multiple sensor inputs and Performing realtime data analysis and I I also want to use this board once it's ready and manufactured to play around with esp32

**18:52** · artificial intelligence capabilities of course being familiar with his MCU is an added bonus this is hardware that I am familiar with I also wanted this board to be a fully fidget iot board Internet of Things board which would be a good PCB design example for this video so I've added a bunch of sensors as you already know there is the BME 280

**19:16** · there's a microphone sensor and there is a light sensor as well and these sensors are supported by their own dedicated support circuitry the board also has power management so I've designed the board to support two power sources one is directly through the usb3 port and another one is through a battery that can connect via this connector here and they both have their own supporting circuitry then since this is an iot board I wanted to offer a couple of

**19:50** · different ways for recording data the first one is through the SD card right here so the SD card RM module is uh used for local data storage and it allows a system to log large amounts of data independently without the need for the esp32 to be connected to the cloud and

**20:10** · this is particularly useful in remote or offline scenarios so when you want to use the data stored on the SD card simply remove it from the module and copy the files on the computer and to complement the SD card module this board also includes a flash memory integral

**20:28** · circuit right here it's onboard flash memory chip which provides fast nonvolatile storage for data and firmware and that ensures that any important data remains intact even after a power cycle the flash memory can store

**20:44** · things such as configuration files and sensor calibration data and even firmware updates where the SD card can store data from the sensors that you may want to be able to quickly copy across to a computer uh so that the two are complementary of each other the other thing to mention here has to do with the

**21:04** · dimensions and the layout of the PCB so designed the layout to keep the board compact while ensuring that any recommendations from the component manufacturers are adhere to so the most important component on the board is the esp32 Chip And that's mostly because of

**21:20** · the integrated antenna and essentially I started the design of the project as you'll see later when we get to the layout part of the video around this component especially if have a look at the documentation for the data sheet you see that what I'm looking at here is the data sheet for the esp32 from Express if systems you can see that the data sheet offers a few positioning ideas or

**21:47** · locations that are approved and correct by the manufacturer so I studied this document and I concluded that probably the best way to put the as32 on the board would be to combine something like

**22:03** · this so position number three in this positioning example with something like this so I ended up with a design that combines the two I didn't like the idea of having the antenna poking out too much because I didn't want it to be damaged I envisioned this PCB eventually

**22:21** · going inside a project box I didn't want this antenna to be out too far but I also needed to make sure that any components around that would not interfere with the radio capabilities of the board so I looked at the documentation and came up with this positioning again I'm going to talk more about this later on in this video when we start working on the layout aside from the esp32 my positioning uh choices

**22:48** · had to do with the user interface requirements so you can see for example the buttons here the connectors tend to be around the edges of the board and another consideration would be to keep components that are part of the same group together so you can see the components that have to do with the enable and the boot Button are together close in proximity the components that are used to implement the flash memory and it supporting bits and pieces are all together and so on again we'll talk

**23:20** · more about all these later in this video as much as possible I tried to collect all the bits and pieces that I need for the project ahead of time so that my actual design work is as smooth as possible what that means is that I do

**23:38** · quite a bit of research and spend a bit of time on this to find the components that I need and then collect all these components both the sources of the actual physical components that will end up on the board plus information such as data sheets and the library that I will need to import into kard having said

**23:59** · that there's always times where I make a decision of a particular component that ends up being the wrong decision and then I have to just fix the problem on the Fly that happened in a couple of times with the USB connector uh I'm made

**24:14** · choices about the USB connector a couple of times prior to settling to this particular connector that after going through with a design pretty much completing the board I realized that the original decisions were incorrect for whatever reason usually it has to do with things such as the availability of the components of being out of stock or some other technical issue like for example making it fit on the board alongside the other components so these are a few things to keep in mind so what

**24:45** · I want to show you here in this segment are some of the sources that I used to do my research to find the components that are needed so again I started with the main comp component the esp32 and then I worked my way down to other components such as integrated circuits connectors USB plugs buttons the SD card

**25:10** · module and things of that sort and I used online resources such as snap magic and snap.com most of the components that I found come from snap magic and I also used snap magic to collect the majority of the footprints symbols and 3D models

**25:33** · I'm going to show you more about this in a moment aside from snap magic there's also lots of other places and just as an indication just for your information I'll just mention component search engine right here I used that for a few of the components there is uh ket.com dig key bu views usb.

**25:51** · RG I use this site to better understand how the USB module Works uh there's on semi for some of the components spark fun Texas Instruments silicon labs std.com and a few more as I'm going through this research I always make sure that I record everything in

**26:18** · Kad itself because I see kiad as the center of my project so in kads schematic editor you can go to simple Fields table and you can see here that each one of the components have made some notes so for example I'm just going to move over so you can see here for example I've just enabled comments so you can see that I've made a note of the

**26:46** · source of the particular component here so this would be the LED so you can see I click on it in the fields table the item in the schematic diagram

**27:02** · appears so here's a fuse for example you can see that I got this fuse from this particular location so I can always go back and I can also share this information with manufacturer so that they have my notes it just improves Communications so that's one example going ahead ahead of time of course because obviously I have completed this project but most of the work that you see here in the files that I have included in the project directory I've

**27:31** · done all that as well before I actually started the design process so I didn't have all of these symbols but I had most of the symbols collected ahead of time um as I went through the project I realized that I've made a few mistakes or a few things were missing so I went back to resources such as snapa to fill

**27:53** · in the missing bits and pieces another thing that I also collected in parall are the data sheets much of the work that goes into designing a PCB has to do with reading data sheets because the manufacturers provides information on how to do the wiring for this particular component so as long as you understand what you're seeing here you you can literally copy the recommendation from the manufacturer into the design so the

**28:21** · design that you see here in the data sheet is basically what I have followed I'm just going to show you really quickly let's go to the root is what I followed right here so the component that you see here the laaa integrated circuit which is U1 is this component here and I simply followed the recommendation from the manufacturer so spend a bit of time both collecting the

**28:45** · data sheets for the components that you'll be using and also looking at them and reading them and understanding how to do the wiring as per the recommendations of the manufacturer again most of the work for doing that I did in uh snapa so if I go back to snapa

**29:04** · I'm just going to show you really quickly let's say that I'm looking for one of those components this is the bomb EXO shade that I'll be sharing as well let's have a look so here's one see Napa this is the USB receptable so I'm just going to search for this connector just going to go for the package actually search for this in snapa and here it is

**29:32** · Click through and here snap magic gives you both a data sheet PDF which I always save that in the project directory so that everything is together so I store that file on my computer and keep it in the project

**29:52** · directory I do the exact same thing then for the symbol in the footprint so I go go for kick at 6 or later so allow the download so here are the three files that uh I just downloaded and I've already stored them so here's a 3D model here is the footprint and here is the symbol I'm going to show you later how to import these symbols into kiad uh

**30:21** · so that we can use them for now I'm just storing them into my project directory so I do all that and once I'm confident that I've got prettyy much everything that I need or at least most of what I need I begin with the project what I've got here is kick at 9 I've got the release candidate version I just up updated this morning the latest available version and I'm just going to show you where I got it from I'm running my Coos so this is the location where I downloaded this particular file here and

### Setting Up KiCad 9 for the Project

**30:55** · then installed it and on my computer I'm just going to show you one more thing I'm running two versions of Kad this one is Kad 8 which is the official version stable version that it's available at the time I'm recording this video and of course in parallel I'm running kickout 9 for the requirements of this particular video recording you can run these two versions or as many versions as you like really in parallel no problem at all as

**31:20** · to how you organize your kick it instances all right so as we've learned already in the previous few segments of this video I've already taken a bit of time through research and uh preparation for this project and worked out my bill

**31:38** · of materials and in a realistic situation where you're just starting fresh with a new project this bom is probably not going to be the final one you'll be working through the details as you're working through the project but in my case uh since I've already rehearsed this video and of pretty much completed the entire process a couple of times prior to actually recording this video I have a pretty good idea of the

**32:05** · components that are going to be in it and so I've got the benefit of the build of material being pretty much finalized just keep in mind in real life if you were working on this project for the very first time just like I did when I went through it for the very first time I only had a partial set of components here I had the major components such as of course the integrated circuits and the microcontroller unit the esp32 had a good idea of the rest of the

**32:34** · components such as the the diodes and the buttons and then I went with more generic options for things such as the resistors and the capacitors in previous segments of the video I explained that as part of my preparation I went ahead used various online resources mostly

**32:54** · snapa but a few other resources that are also available aailable in order to find download and make available especially the footprints and the symbols but also the data sheets I've spent a lot of time reading through data sheets before I even started drawing anything in kiat

**33:11** · and that's Again part of your preparation I estimate that when I add all the time that I put in to prepare for the project the total amount of time spent would be about five to six good working hours to collect all of these files okay so let's get started with Kad

**33:29** · I've already started the application and I'm going to go into a new project and I'm going to save this new project in this directory that I've already started and because the directory already exists I'm just going to uncheck this option to create yet a new folder so I just want Kat to store all of its files in the directory that I've just selected so I give it a name Kat 9 esp32 demo project

**33:56** · and save yeah the selected folder is not empty I'm fully aware that there's content in this directory and yes I want to continue so there the new files just created as part of this new project the next thing I want to do is to do some basic setup I'll do that under Key Cat

**34:15** · settings there a few things I want to check things such as the high quality analizing just makes everything look better in the schematic and the drawings going to jump into the schematic editor and have a look at a few things here such as the display options I tend to go with the defaults there now and the grids there's a couple of things I want to double check as well I've got the 150 25 and 10 ms which is good and then for the fast switching I've got 50 Ms and 25

**34:48** · Ms for that and all the grid overrides as well look good all right so that's okay again all this is really personal preference tends to work better for me and I'm going to go to the editing options and have a look inside here all this looks okay annotation options also

**35:11** · look good just going to skip the rest I'm just going to accept the defaults for everything else and go into the PCB editor and have a look around here all this again looks fine as it is and just notice I'm going for four window crosshairs makes it easier to align things together when I'm using full window crosshairs and the same thing happens with the schematic editor then for the grids these are the grids that I've already selected and created your

**35:38** · list of grids is probably going to be much smaller if your Ki installation is new uh but in my case I've Ed a few additional grids and these are my grid overrides origin access and editing options defaults work fine click okay

**35:54** · next up have a look at the plugins I'm just going to go into the plugins and content manager by the button here just want to show you the plugins that I've got installed so in this project I'm only going to be using a couple of these plug I have a new Fresh installation of kard I tend to install these plugins

**36:14** · which I tend to use from time to time so there's interactive HTML bomb PCB action tools round tracks works really nice free routing and the HQ dfm which I'll be using at the very end of this project to test my board before submitting it for manufacturing and I've got a few other plugins here as well out of this entire list I recommend that you install at the very least the free routing plug-in and the HQ dfm so next up let's go into

**36:44** · preferences and install the symbol and the footprint libraries remember that I've already collected those libraries here and stored inside the same project directory so I'll start with the footprints notice that I've got an option here to import those libraries

**37:01** · globally so for all future projects or for the project specifically and I like to have a better control of the libraries for each project then I tend to go for the Project Specific libraries option unless there is a library that I'm installing that I know I'll be using across multiple projects in this case

**37:21** · most of the components I'll be using will be specific to this project so I'm opting for the Project Specific libraries here so then I'm going to use this option here to select a kick at folder with kick at mod files so click on this button then I'm already in the

**37:37** · project folder go into libraries select Footprints just set the folder level and click on open and that's it just going to change the name here I'm going to call that esp32 project libraries this nickname will make it easier for me to recognize that I'm selecting a footprint from inside this particular project Footprints library and click okay let's

### Creating the Schematic

**38:05** · do the same for the symbols so I for the same reason I'm going to go for the Project Specific libraries click on the folder button and then go into symbols unfortunately I can't select all of the library files in this directory I have to select them either one by one and click on open or do a multi select that's what I'll do so I select the first item in the list hold the shift button on my keyboard and scroll down

**38:38** · and while I'm holding the shift key click on the last item to highlight everything and then click on open and you can see that now all of these symbols and the symbol libraries have been selected and they are under the Project Specific libraries and click okay and now I'm ready to get started with the schematic here's the blank schematic editor and the plan here is that I'm going to have a total of four pages in the first page I'll have the

**39:09** · USB and power related components then in the second page I'll have the esp32 the module plus the usbt converter and a couple of LEDs then I'm going to have another page for the sensors and finally uh another page for the user interface so I'll be creating these Pages as I go and then providing Connections in between the pages let's start dropping some components start with the uh sheet

**39:38** · page settings I just want to uh add my date here I give it a the title so this going to be ESP 32 sensor board you can add more details there as you wish all right so you can see that information that text appears down the bottom let's begin with the USB receptacle so I'm just going to either click on this button right here on the top right toolbar Place symbols or use the a hot key to bring up the symbol Chooser so

**40:10** · remember that here I'm using or I want to use the SS 52400 receptable that I downloaded earlier from snap magic so I'm just going to search for that SS there you go came up that's the one that I want I can either double click on the item or just click on okay and I'll place that around here going to rearrange my symbols a bit later the next major component is the lipo charger

**40:40** · and I'm looking at my bill of materials and the item that I'm looking for is this one here the mCP 7387 the AK to bring up the Chooser and I'm now going to search for MC

**40:57** · P \[Music\] 7387 and it's this component here so click okay and I'll place it around there next up I've got the voltage regulator so again click anywhere in the sheet and looking at my bomb the regulator is this item right here the lm1117 so search for that

**41:22** · lm1117 click okay and I'll place it around here so I'm already starting to create areas where all related components will be going together so this part here is going to be where all the USBC related components are going to be this area here is going to be where all the ball charger components will be here is the

**41:46** · regulator move that up a little and I also have the battery connector so I'm going to add that as well so the battery connector that I want to use is the jst T connector looks like that click okay and place that right there for each one of those components I need of course the supporting components for the circuitry I'm going to drop all the resistors that I need on this sheet and then I'll continue with capacitors and LEDs so

**42:14** · let's start with the resistors I'm going to hit the a key on my keyboard here in the Chooser I'll select R already done it but I'll select R double click on it and I'm going to start with say here I'm going to draw this resistor right there where it's going to be eventually connected and then double click on it to change its value so this going to be a 10 kilm resistor this going to be a pull down resistor I need one more of them so

**42:43** · I'm going to type command D on my keyboard to create a duplicate and I'll drop it right here and just I'm going to move the designator and the value a little just so that there's no overlap in this one is also going to be 10 kohms so that's fine as it is so next up let's have a look at the resistance array on J1 so I'm just going to type a bring up

**43:07** · this resistor I'm going to place it around here this going to be another pull down for the C2 line and the value for this resistor is 5.1k I'm Mark it down as 5k1 I could have done it something like this for example 5.1 K but I find that the dot

**43:30** · sometimes is not easy to see and therefore can be misread whereas if I do something like 5k1 it's much easier to get the information correctly that this is a 5.1 kiloohm resistor also if you're

**43:46** · wondering where I get the value for the particular resistor I'm just going to connect it right now just to make it a bit more clear so this supp pull down resistor for the CC two line then the answer is the USB data sheet and I'm going to have another similar resistor on the other side for CC1 is just going to be another 5.1k resistor that will go right there course to draw a line which represents a wire I simply click on the pin and the

**44:18** · drawing tool will automatically start drawing a wire to stop drawing and just double click or if you want to cancel the drawing operation just hit the Escape key all right I haven't finished the wiring here I'm going to add the ground symbols a bit later so also if

**44:35** · you want to move things around you can just place your cursor on the thing that you want to move and then just type the m key on the keyboard or you can just click with your mouse and drag notice that when you do that the wire that I've already drawn it

**44:51** · gets interrupted and then I have to redraw it alternatively you can see if you do a right click to bring up the context menu there is the drag option which you can use the G shortcut to activate and that ensures that any wiring you've already done is not being cut or removed and then click again to finish the drawing okay so I've got R1 R2 R3 R4 going to go back to my U1

**45:19** · component so I'm going to add a couple of additional pull down resistors so just the a key again the r it's going to be one here and I'm just going to duplicate this one here another one they've got different values so the R5 will be 2K and the R6 is going to be

**45:44** · 20ks and while I'm at it I'm just going to do the drawing as well here's a yre for Te negative and the THM and these two we'll go to ground I'll do the ground now so don't forget so for some reason my Chooser power symbol Chooser is not coming up properly formatted and this pen on the side is just folded anyway it's not hard to expanded so here I'm

**46:14** · going to pick up the ground I can just search for gnd this is just another symbol but he could provides a separate menu item here on the side to make it easier to find so there a ground and all draw a line to connect it to R1 and R2 so these two are pull down resistors and I've got the same thing down the bottom for R5 and R six duplicate that ground

**46:41** · symbol connect the two resists together and finish the connection like that and the R5 goes to prog one and R six goes to prog three now if you're wondering again how I know how to do the wiring here again the answer is the data shade so this is the mCP 73871 and you can see in the data sheet

**47:12** · there are example typical applications and I'm simply following the example that's given to me by the manufacturer nothing fancy here and I'm not making things these up this is what the manufacturer suggests on the other side of of this U1 component I've got some indicator LEDs so I'll bring up a few more resistors first to protect the LEDs from overcurrents so this going to be our seven and this is going to be

**47:43** · 470 ohms so duplicate it a couple of times R8 and R9 and these go to these three pins so R9 will go to PG r R8 will go to SDA 1 and R7 will go to SDA 2 these

**48:06** · indicate that the battery is either charging or it is already charged for the LEDs I found the computer I want to use from snapa and as per my bomb you can see I've got three different types I've got our red a green and a blue I've already imported those to kard so I'm just going to sech search first for the red one which is the ltst red this one right here so import

**48:35** · that into my schematic Orient appropriately and that's done I want one more I'm not going to duplicate this because the next one I want is a green one so back to the Chooser and this one is a green okay like that just going to make a little bit of room between those and I've got one more this the last one is going to be the

**49:06** · blue right there I can type the m key on my keyboard to move things around all right and then finish with the connections one goes there there and there the bottoms of the LEDs

**49:22** · or the anodes of the LEDs are connected to the same place which doesn't yet exist is that's a net that I'm going to call 5V USB which doesn't exist yet as I said I'm going to connect it in a minute so I'm just going to leave these wires unconnected for the time being I'm just going to add a couple of grounds I'm just going to duplicate this ground and move it over here and finish this wiring

**49:48** · here do one more and finish that wiring right there a couple of other grounds that I'll connect while I'm at it is is this so gnd D just duplicate and connect a12 which is gnd D A2 to ground there's also one more ground I'm just going to go straight there instead of introducing new symbols so these two pins also go to ground this one will ground up \[Music\] here like that move that down a bit and

**50:22** · of course one more on the other side right there done I'll continue my work with the USB connector before I move to the other components I think at this point I've got enough already set up here to allow me to complete one part

**50:38** · of the schematic before I move to the other parts I'm just going to make a little bit of room to the part of the schematic that I'll be working for the next few minutes and that is the connector on the connector I also want to include a couple of things especially the polyfuse to help protect my board from over current so that polyfuse is connected right there on the vbus B1 pin

**51:02** · I've already selected the fuse to use so it's this one right here so I'm just going to search for B fuse and the component should already be available there search for B fuse yes it's right here so that's the one I want to use so click okay I'll place it right here I want to have a straight line so I'm just going to make a little change going to remove that line actually I'm going to remove all of this and move the ground a little bit closer to the pin and connect

**51:33** · it in like that now for the fuse that gets connected to this pin right there that's where power goes into from the USB bus and then on the other side again that's the USB bus that comes from the power ciruit next I'm going to add a capacitor that will act as an input filtering capacitor add a new component

**51:59** · it's going to be a just a regular capacitor nothing fancy I'm going to place that say around here where there is space and the value for this capacitor is 0.1 U or micro farat I use G to move

**52:19** · that a little more okay here is a good place to connect it to the polyfuse just like that and going going to duplicate the ground symbol and connect it right there just going to make a little bit of room select all these together type G and move everything a little bit to the right so I think that's it with J1 and

**52:40** · wirings I'm going to connect the remaining pins to particular Nets or I will mark them as unconnected to Mark a pin as unconnected I'm going to use this button here uh place no connect flags and that allows me to just click on a pen that I want to tell Kik that it's not going to be connected to anything so that that will suppress any error messages later on like that so sb1 will

**53:07** · also be unconnected and then up the top got these two that will be left unconnected on the other side is B2 and B3 B9 sorry B8 and then B10 and 11 so let's save at this point speaking of save if you go to kick at setting have a look at this area here in common project backup automatically backup projects so actually I want to make sure that I don't lose any work so I'm going to have

**53:40** · lots of backups let's say 10 per day every 5 minutes you don't want to lose any work and since I'm working with a release candidate version of Ky out I'd rather be safe than sorry I've got my J1 almost finished the next thing that I want to do is to start creating some Nets so I'm I'm going to use the net label tool right here you can use the L shortcut for label and with that you can

**54:05** · start creating labels I'm going to have a net named bus just type the I key to rotate it and Orient it appropriately and this going to be vbus dp1 and N D1 uh so DP for positive

**54:22** · n for negative this is going to be a differential pair for the data pinch of the USB connector so click here to bring up the label properties and this going to be USB DP or data positive so it goes in here and I'm just going to duplicate that hit Escape select the label I want to duplicate and type command or control b d click that to connect it to A7 and

**54:52** · then double click again to bring up the properties and make that P and n for negative so I've got DP and DN then the letters here at the very end of the two labels is important because p and N indicate to kick it that this is a differential pair and we are going to use this feature to do the wiring later on in the layout there is also one more

**55:17** · VBS I'm just going to duplicate that and connect another vbus wire right there so vbus A2 and vbus A1 connected to the same net on the other side I've got two more differential pairs for data these are short circuited they're physically connected in the connector so that's why the part of the same net so I'm going to duplicate DP flip it over on that side and it's going to be a p right there and then the

**55:46** · N or the negative of the differential pair right there another vbus label right there duplicate done this is going to be vbus 2 and finally I need to mark this wire as a

**56:06** · member of the vbus net so this going to be vbus B1 there's one more net to create just going to use the L key for that and this is going to be the plus 5V USB net which goes

**56:23** · there using the G key to move move everything a little bit further in okay that's it this is the USB connector I'm going to do another check a little later but I think for now that's enough works I'm just going to draw a little box around it and give it a label just to make it easy to see when I'm quickly looking at the schematic diagram that this is a block of components that

**56:47** · belong together and they play a particular role so this is a USB connector like that going to continue now with this part of the first page of the schematic now that I have the vbus 5 Vol vbus I'm just going to duplicate it and finish up the wiring of the LEDs so these go like that and just going to mark that here as the V bus now I'm going to continue to

**57:15** · implement the wiring for the lipo charger integrated ciruit just by following the recommendations of the data sheet from microchip technology the manufacturer of this particular integrated circuit so I'm just going to continue essentially copying what I see in the data sheet so I've got one more 5 Vol USB pin PR two I need to bring that up to 5 Vols for vibat sense just going

**57:42** · to short that with vbat and then Mark this net with a name so type the L key and this is going to be the vbat net mark it like that or out this is the reason for the existence of this particular chip is whatever comes out of this pin and I'm going to create a new named net with the name + 5 volts so

**58:12** · that's what comes out of this particular chip so on vsss I'm going to connect this to ground you can see that's what the data sheet is telling us to do so this is going to go to ground just going to duplicate ground symbol oriented like

**58:30** · that and Mark it like this now one thing to keep in mind I'm just going to bring up the symbol and have a look having a look at the vsss you can see that that is marked as a power input so if I leave my schematic like this so vsss directly connected to gnd D I'm going to get an error message from Kad later on want to do the ERC check so to prevent that from happening I'm going to go back to the power symbol Chooser and search for a

**59:04** · flag this power flag here and attach this flag to V SS and that will suppress that error message from kard and indicate to kard that yes I do know that this is a Power Pin and I've already taken care of that don't worry about it let's go down to the bottom pin 18 is in and that's where where we apply the 5V USB power it's coming out of here the PCC that's connected right there and

**59:37** · going to copy the flag and plug that into here so basically pin two and pin 18 are connected to the 5V USB input power here I also need the filter capacitor so I'm just going to bring another capacitor and drop it in there this one is going to be just one U and

**59:59** · I'm going to change the reference to C6 just to keep in sync with my notes Here CU I'm going to have a few other capacitors with different IDs I want to be a little bit more in control of the designators so normally I will allow kyat to come up with whichever designator it wants for new components that I'm dropping on the schematic shade but in this case I want to have a little bit more control as I said so I'm going to go ahead and rename this AA 2 C6 then

**1:00:28** · we'll connect that to ground done with that let's have a look anything else I've got yep I've got C up here which also needs to go to 5 Vols USB I think this part of the schematic is done so hit Escape select the whole thing and move it down a little and then put a box around it to indicate to the reader or

**1:00:52** · myself in this case and you that this is a set of components that belong together and I'm going to put a label here as well and this is going to be the lipo charger done the next thing is the low Dropout voltage regulator I'm going to follow the instructions from the data sheet and in particular I'll Implement A variation of this recommendation here for a fixed output regulator on the the inside I need two capacitors one of them

**1:01:22** · is going to be ceramic and the other one is going to be talum so so this one is the ceramic capacitor I'll place it right there double click to get its properties and this is going to be a 0.1 U capacitor and this is C2 that's

**1:01:40** · correct again just sking in sync with my notes I also need a talum capacitor so a key again talum is basically an electrolytic capacitor I'm just going to search for C and this a polarized I'm going to use this polarized capacitor symbol for tandum and place it right

**1:02:01** · there double click change the value to 10 microfarads like that and I'll have the exact same thing on the other side as well so I'm going to select these two and duplicate them and move the group of

**1:02:18** · the two capacitors to the other side just going to change the names I want this to be C5 and this to be C4 so I'm going to have C5 which is going to be 0.1 just going move it on the other side just keep a note here the placing of the capacitors is important so I just flipped the ceramic with the electrolytic capacitor because I want the electrolytic capacitor tandum in my case to be closer to the pins on the

**1:02:49** · integrated circuit that it will be connected to in this case is going to be the 2v out pins in other words the proximity of components to other components is important in the schematic just as it is in the layout when I see that C4 is close to V out 2 and V out 4

**1:03:09** · I know that I need to place C4 very close to those two pin in the layout as well VN goes there so I've got the two filters and I've got the ground just going to duplicate the ground symbol place it

**1:03:28** · right there and finish the connection on that side and then there's a label I'm going to place this label is going to be plus 5 Vol so 5 Vols goes into this regulator and 3.3 Vol comes out on the

**1:03:46** · other side I'm going to use a power symbol for the output so on the output I have 3.3 volts and there is a symbol for that so I'm going to use that instead of creating my own custom label so it's going to be this symbol right there all right so V out 2 and V out 4 go to the same place we've got 3.3 volts coming out of this voltage regulator and for the filtering part we also have these two capacitors as I said C4

**1:04:20** · I'll be connecting it very close to those two pin to improve the performance of the filtering and just like I did up here with a power flag I'm going to use the same power flag here to tell Kat that I'm aware

**1:04:36** · that this particular component we have a look if you have a look in the simple editor you'll see these two pins are power inputs I'm telling kard that I know about that fact and it doesn't need to worry about bringing up an error message when I do the ERC check later on because it's been taken care of and I've got the ground component as well for

**1:05:01** · these capacitors and there's one more ground I'm just going to give this one its own ground actually just duplicate just for clarity I could have connected this ground pin straight here and share the same ground symbol as the capacitors but I want it to be a little bit independent in this case I think it looks better as well so I'm just going to leave it like that now one thing I'm going to improve here is I just realized that I've got a 5V label here and a 3.3

**1:05:29** · Vol symbol label on the other side just want to be consistent so I'm going to remove that manual or custom label and replace it with an actual 5V label from Kad actually I'm going to use one of those so 5 V I'm going to use this label

**1:05:50** · like that just rotate it okay that's better select all these type G just to move things in a bit and I think this block of components is now complete just going to move it all up a little like that and put a box around it this going to be the low Dropout or ldo insured

**1:06:13** · voltage regulator uh I also have the battery connector that's going to be quick to connect and I'm also going to add a power indicator LED in a moment so let's have a look at this component the battery connector I'm going to rotate that so that the pins face inwards and on one side I want to add a vbat label

**1:06:38** · same label that I used here in the little battery charge integrated circuit so I'm just going to copy that duplicate it and connect it there and the other one of course is going to be the ground level done so let's put that in the Box

**1:06:55** · and give it a name next up I want a indicator for power so I'm going to grab a copy of the red LED and its current limiting resistor I'm just going to duplicate these two rotate like that and place it say around here and the idea here is that when there is power then 3.3 volts is going to come out of the regulator into this LED and then of course into ground and the LED will let us know that

**1:07:29** · power has been applied to the Circuit at a label here even though this is not really necessary but Power LED I'm just going to give it a named net so I can see this particular net in the layout easier later on so done with that first page is pretty much done the only next thing that I want to do is to add a hierarchical shade symbol so that I can

**1:08:00** · then connect this shade to the next one up in the hierarchy so I'll select this tool click on it and then just draw a little box here do that again yep like that I'm going to give this sheet a name and what this sheet is going to contain is the esp32 and related Hardware so I'm just going to put in here esp32

**1:08:25** · \[Music\] c302 that's the main component that's going to be in that sheet and I'm going to change the name for the sheet file as well ESP 32 C3 02 so I'll be able to see

**1:08:40** · that file in the file system in a moment and I know what it is about so save then have a look you can see I go back one level I've got my new sheet just right there along the rest of the sheets that make up the project you skip a couple of times to exit the tool so now I've got the second shade you can see that it also appeared here the second sheade is blank before I go over to work on the esp32 sheet I just notice a couple of things are to fix that has to do with the LEDs and the colors of the LEDs and

**1:09:11** · the pins to which each of these is connected to and I also want to introduce a couple of labels as well just to make it easier to see and understand the role of each of these wires when I'm working on the layout editor first thing to do is just notice that this red LED is connected to stat 2 stat 2 is the pin that indicates charging however I want the red LED to

**1:09:38** · indicate that charging power is good I can either do that by rearranging those wires or just moving the LEDs around actually that's what I'll do I'm just going to remove those wires to release the LEDs and move those around so I want the blue LED to be connected to stat 2 and stat 2 indicates charging of the battery so blue LED means charging the green LED indicates charged

**1:10:11** · and it's connected to Stat one so that is fine as it is should not have removed those wires so let's place that here and rewire everything now the other thing that I want to do is I said earlier is to use use labels to Mark the functionality of these wires and that makes it easier later on in the layout to know what wire I'm dealing with so this one is going to be charging power good I'm just going to

**1:10:40** · double click because a is missing all right second one is going to be charged and the last one is going to be charging so that's done as well now I've got one more label that is missing this one here actually just noticed this should be 5 Vols I'm just going to copy that duplicate it and that is going to be a 5V label and I just notied one more

### Designing the ESP32 Circuitry

**1:11:09** · thing I don't have a value for R6 so let's do that now so R6 should be 20K I'm pretty confident that this is correct now I haven't forgotten anything so we can continue now with the second sheet let's continue with the second sheet which will contain the various circuitry relating to the es32 and

**1:11:30** · things such as the USB module flash memory in the SD card module I'll put all those in the second sheet so you can get to the second sheet either by clicking here in the schematic herc just a second sheet you can reveal that window by clicking on this button here in the left toolbar HC Navigator or you can double click on the hierarchy symbol in the first sheet just double click and all get you there and another thing that you can do that I always like to do is to go into the symbols property and just

**1:12:03** · change the fill color so that it's a little bit easier to see I'm just going to make it something like this with a bit of opacity so kind of look a little bit like this a bit more interesting and and striking later on you'll see that I'm going to attach labels to this box

**1:12:21** · in order to enable Communications between the two sheets so let's go ahead second sheet and just like before I'm going to start by dropping the major components onto the sheet and to make it a little bit easier for us to know what those components are I've gone to the bomb and I have highlighted with yellow the main components that are part of this sheet so we have the memory card connector it's the SD card connector the esp32 chip the

**1:12:51** · cp2102 which is a usb2 uart bridge got another chip that acts as an ESD suppressor that will be working alongside the USB to UI Bridge I'll talk a little bit more about this in a moment and finally the flash memory chip uh let's start with the USB module I'll hit the a key and I'll search for GSD

**1:13:15** · 0900 and there it is I'll place that somewhere here I'll continue just you can see what I'm doing I'll continue with the the next item in my list which is the esp32 u3 component so I'm just going to search for that see3 the one that I want is this one okay and drop that there next up in my list I've got the USB to U bridge

**1:13:46** · cp2102 and I'm looking for the G qfn 20 package so I'd go 20 this one here place that here one more is the flash memory so that is this item down here

**1:14:06** · actually sorry I skipped one u5 that's the ESD suppressor so let's look for that first I've got a few options there the one that I want is this one right there the differences have to do with the packaging not with the schematic itself you can see the first two have got six pins out it's just the packaging is slightly different so the one that I'm going to go for is the 2s C6 and then finally I've got the U6

**1:14:36** · component which is The Flash SBI flash chip so that's W2 5 q this one here there's a few options but that's the one that I'm looking for double click and I'll place it say here before I continue I'm going to review the designators for the components just to make sure that they match with the ones I'm using in my notes because if I don't there's a high chance I'm going to make mistakes later on so the USD

**1:15:05** · suppressor chip I'm going to rename that to u5 the USB to serial bridge that is going to be u4 the ESP 32 Chip is going to be

**1:15:20** · u3 the SD card module is j3 that's correct and then finally the flash memory that is going to be U6 I suggest you do that as well if you want to keep track of what I'm doing because I'll be referring to these components by the designators and all I'm trying to do here is to make sure that the notes and the designators in my notes with the various components match with what I have in the actual schematic so that's all I'm doing here now let's talk a little bit about these components

**1:15:52** · this integrated circuit you 4 is a usb2 uard bridge and it enables Communications between a computer and the esp32 C3 module via a USB connection so it converts USB signals to serial U signals making it possible to program and debug the esp32 C3 directly from the computer while handling USB power delivery to the board so that's the purpose of this chip now alongside this chip is our smaller chip this u5 USB

**1:16:23** · lc6 and this is is a ESD suppressor chip this chip here protects the bridge the USB serial Bridge from electrostatic discharge events which can occur during handling or when plugging in USB connections so it clamps high voltage spikes to safe levels preventing damage to the chip while maintaining signal Integrity for Reliable data communication so I'm also going to follow the information in the data

**1:16:52** · sheets for all of the wiring that you're about to see so for example I've got the documentation for the esp32 chip I showed you some of this a little earlier actually a better place to look for that information is the development kit schematic diagram so for example here you can see how expressive themselves have wired the esp32 module to power and

**1:17:17** · to ground and I'll be following this example as well in particular be implementing the reset and boot Button functionality following this exact schematic so that's one place to look for another thing to show you is the cp2102 chip this is the USB 2 serial

**1:17:40** · bridge and there's a lot of information here on how to do the wiring I'm not going to go through it because it's a lot of detail it will take a while but if you are interested in learning the details and understanding why I did what I did the way I did it have a look at these data sheets as well here's a data sheet for the SD card module this is

**1:18:01** · mostly mechanical there's not much else going on so I've looked at this just to get a better understanding of the mechanical attributes of this connector and finally I've got here the data sheet for the flush memory this is NBI interface flush memory it doesn't have specific information on how to do their wiring but I'm using conventions for

**1:18:21** · wiring integrated circuits that communicate with with a host using High data rates and high frequencies let's begin I'm going to start with the top left side of my schematic and work my way to the other components so since I've got the ESD protective circuit I'm

**1:18:40** · just going to move these two bits to the side for the time being at least okay I'm just going to reorient this component to make wiring easier pin two goes to ground I'm just going to grab a ground pin from here \[Music\] place that there so that's going to be ground going to leave pin five alone for a second because I need a couple of resistors for that it's a voltage ladder next three just going to flip this

**1:19:11** · component across so select it and just click on this button up here to mirror vertically because I want pin three to be up on the top side just makes wiring easier so pin 3 will go to to pin 4 on the USB to serial bridge and pin one will go to Five pins four and six

**1:19:36** · need to be connected to pins in the root page so to do that I'm going to use this button here to create hierarchical labels so the first label is USB DN so USB DN and for negative I do have flexibility on to where to connect it but I'm going to connect that to six to pin six to begin with and I'm going to create a duplicate of this

**1:20:06** · label double click on the duplicate and change this end to P for the positive side of this differential pair so I've got USB DP connected to pin 4 and USB DN

**1:20:22** · connected to pin 6 now in the root page I'm going to use the place sheet pins tool to expose their two uh sheet labels I just created in the rout so click on that click here and you can see some clicking and then click again to commit um bringing across the two labels the two hierarchical labels that are created in the second sheet so these two and now

**1:20:49** · exposed to the first sheet right here and I can actually finish the connection of those two sheets by connecting you can see there's pins here that I can connect to something else so I'm going to grab the two labels that I've already created these two create a duplicate then bring them down here to finish the connection so I've got the DN that needs to go right there I'm just going to use Y is for that and DP that goes there use

**1:21:19** · wires to finish the connection the two pages now the two sheets are now able to communicate let's go back to the second sheet and I'm going to finish this work for this particular component by adding the two resistors to form a resistor ladder so there's the first one just R there's one here and another one here it's going to be R12 and the value for R12 is 22.1

**1:21:54** · K or I'm going to call it 22 K1 the second one its designator is 13 and its value 47.5 KMS these two form a voltage ladder for VBS like this just move it down a bit and then the other side of r13 goes to

**1:22:21** · ground like that on the top side we've got vbus so vbus of course is coming into this shade from the rude shade so I'm going to create one more hierarchical label called vbus and connect that here and go back to the rout and expose it like that and from here I need to find a vbus label to bring across

**1:22:56** · done back to the second sheet one thing to notice is that these labels have got shapes so depending on what shape you use you can see that the shape of the label itself changes as well these are really just visual so I'm going to keep them as inputs here and the VB is also an input next I'm going to take a wire from pin five and connect it to vbus so

**1:23:22** · that's how this chip is being powered or if you don't like the label you can just use vbus I'll do that actually just to minimize the number of wires that I'm using all right now while I'm at it I'm going to create a few local and named nits so the first one is going to be USB data plus so I'm going to connect that to the P right there and the other

**1:23:52** · one is going to be the minus again this is going to be a differential pair so I'm using plus and minus so that later on when I go to the layout editor and I start doing the drawing of the tracers Kart will be able to tell that these two wires belong to the same differential pair because they've got the minus and the plus signs in their net names now as

**1:24:17** · per the specifications for this device in the data sheet I also need a capacitor just a regular capacitor will do going to place it here connect the other side to ground just move that a bit further down like this and that goes up here and this capacitor is going to be C11 and its value is going to be 1 micro

**1:24:47** · farad and let's continue going to have one more ground down \[Music\] here and up on the top side actually I need to move everything down a bit because I have a few components to connect up on the top side so I'm going to start with a resistor oriented like this this resistor will be R11 and it's going to be

**1:25:20** · 1K that will be connected between the reset pin and pin seven which is the voltage regulation in and I'm going to connect vdd in there as well to the same pin then I've got two bypass capacitors one of them is going to be a regular capacitor and the other one is going to be electrolytic or

**1:25:49** · polarized oriented like that let's set the values so the one in the bottom is going to be C10 and its value 0.1 microfarads and the polarized one is going to be C9 and its value is

**1:26:11** · 4.7 U it goes there and then these two go to ground

**1:26:26** · like that and on the top side I'm going to have a 3.3 volt symbol so that side is done uh on the right side I'm just going to Mark a few pins that I won't be using first do not connect that and that and the suspend

**1:26:50** · pins we don't need wake up either after that that I want to have two LEDs to indicate traffic so you can see txt and RTX so I'll connect two pins here to show when there is traffic so I'm going to copy this block of components blue and a red LED along with the resistors

**1:27:14** · so command C go back to the working shet and paste those here this saves time just Orient like that so I'm going to put the uh green LED day actually on the top side again this is totally arbitrary of

**1:27:31** · course but in order to do myself the courtesy of not making a mistake and diverging from my notes I'm just uh making sure that what I'm drawing here reflects what I have in my notes all right and these two then will go to the 3.3 volt just going to copy this symbol and place it right here here I've got txt rxt and the RTS and CTS and

**1:28:03** · instead of wiring them using actual wires I'm just going to use labels here so this one the first one is going to be TX RX and that goes here and the second one duplicate is going to be rxtx goes there next

**1:28:26** · RTS and finally we have I'll call this one DTS okay I think this is complete so I'm going to put this in a box move it down a little and give it a name this is the USB module okay looks okay I'm going to have another look at it later on before I commit let's work on the ESP 32 module

**1:28:53** · so I'm going to laser in here because I'm going to have more components on the right side I just noticed that this resistor should be 18 R 18 so let's begin here I'm going to start by dropping a new resistor place it here next to I6 and this is a small 50 Ohm

**1:29:21** · resistor all right so that goes to I6 and on the other side we'll connect the to S CK net after that I've got several net labels to create and attach to these pins right here and down the bottom right there so start with the ones that I've already created so I can just duplicate them so first I'm just going to copy these two create duplicates and move them over to this side and rotate and just connect them to

**1:29:55** · pins 12 and 11 and that's good next up I've got a bunch of net labels to create so I'm going to use the L key for that so the first one for up here pin two this is going to be en n for enable done next one it's going to be cscore SD that's going to go to

**1:30:19** · io0 so they're all for all those pins just by the way if if you are a little bit confused right now we'll find all that information in the data sheet right here so there is a table here right here that tells you about the roles of each one of the pins so that you know what label to create in order to connect that pain to a particular net so next up is io1 which is going to be connected to

**1:30:48** · the sensor I've connected that to the photo sensor so this is a purpose Pinn you can do whatever you want with it of course but I've decided to connect this particular one to the photo sensor next I've got the SBI interface so I'll create a a new label called misso do for data output and that goes to io2 then there is SC for the I squid C

**1:31:17** · interface and SDA and for I5 there another general purpose input output uh and I've connected it to the microphone so I'm using the MC out net to convey signal

**1:31:34** · from the microphone or from the sound sensor so the left side is done let's go over to the other side now I'll continue with some more labels since I've started that process this going to be uh gp19 so that goes there I'm going to connect this particular net to one of the headers that's gp18 next one up is going to be CS or chip select for the SBI interface and

**1:32:05** · that's going to be Boot and gp8 this one is going to be connected to the boot Button just like uh this one here goes to the enable button three pins remaining I'm going to duplicate the ground symbol so that I can connect it to the ground pin right there then I've got io7 for io7 I

**1:32:29** · need a resistor so add a resistor oriented like this so This resistor is 50 ohms and it goes to Mossy so there's another label start a input for the SP interface this is going to be R15 this R15 and I need to correct this one here this is R 20 and finally the power for this esp32

**1:33:03** · module as per the specifications I'm going to connect this power to 3.3 volts that but I also need a couple of capacitors for bypass and for or just signal conditioning so I'm going to have

**1:33:22** · two capacitors there one polarized and one unpolarized or ceramic so there's the ceramic one and let's put one more polarized I'll place that there like this I'm just going to switch the names so C7 should really be C8 to remain consistent with my notes that's going to be 0.1 U or 0.1 microfarads

**1:33:54** · okay and the other one is going to be C7 and its value is 10 microfarads connect these to ground and on the top side just going to use the W key to start drawing just going to draw it like that actually I think makes more sense if I draw it like this yeah I'm going to move all this down a bit so because just to CH the number of angles that appear

**1:34:27** · so like this G key just to make it look a little nicer I think this is good as it is put a box around it and give it a name done let's continue with the SD card module so this is a SBI device so

**1:34:45** · it it communicates with the esp32 using SPI so start with connecting the SPI and then uh there's a couple of capacitors in resistance as well for Signal conditioning I'm going to grab the mossy and miso and clock there's clock and the

**1:35:04** · select I just noticed a mistake actually I'll unclick everything this is the select signal for the SD card so it should be SC for select SD for SD card all right so let's try again so that that clock and that duplicate them and bring them all say around here so I can attach them to the SD card reader module so Mossy goes on this side

**1:35:35** · here clock goes here the chip select goes here but I will need to add a

**1:35:52** · resistor this is just a pull up resistor I'll just place it here and set it up so this is r19 and the value of this resistor is \[Music\] 10K and as I said this is a pull up resistor so I'll just draw it like this pulls up to 3.3

**1:36:17** · volts I can just make this a little bit more economical with space and just connect it straight like that G to make it look better okay and then finally I've got the Miso and that eventually goes here just going to move this out of the way for a moment okay that goes to that zero pin but I need a

**1:36:40** · resistor a small resistor again signal conditioning right there that is going to be R16 and just 50 ohms make sure because I hit Escape so it didn't commit so R16 50 ohms and that goes there are done just move these two out a bit using the G key that one and Dot two along with the

**1:37:14** · pins down here all go to ground so I'm just going to get a ground component place it there rearrange a few things actually I don't really need this long wire I'm just going to move this simple databit rotate and connect straight like that all right next I've got that one

**1:37:39** · goes to ground that two goes to ground move these two labels up there and also I've got actually I'll be yeah I'll be economical with space and yse I'm just going to do one more ground there and all these go to ground

**1:37:59** · then I'm going to Mark these pins on the left as do not connect and then I've got one pin remaining which is the power input for this module so for that I need a couple of capacitors uh just like with the other examples earlier and it's so happens that these capacitors are the same values as those are used up here in

**1:38:23** · the 32 so I'm just going to copy those and duplicate and I've got C12 is meant to be the electrolytic so I'm just going to change the designations so this is going to be 12 at 10 microfarads and this is going to be 13 at 0.1 and that goes right there and

**1:38:45** · finally I've got the 3.3 volt to power the module I'll bring the grounds down here so that kind of the at the same level looks a bit better and that is it with a module

**1:39:03** · for the SD card put it in a box give it a name one more thing to mention here is that the dot 2 pin on the micro SD card is typically used in 4bit SD mode as one of the four data lines we've got data line 0 1 2 and

**1:39:23** · three four data lines in total however in SPI mode which is commonly used in microcontroller applications like the ones that we are building here the dot two pin is not required and it can be left floating or better connected to ground which is what we're doing here so in SPI mode which is the mode that we are again using here only the following pins are actively used we've got data zero you see I've connected that to miso data out CMD which is connected to miso

**1:39:58** · data in clock right here and CS right here the cheap select and then againt 2 and one are not used in SBI mode one more thing to do and that's to connect and wire up the flash memory so the flash memory is also using the SBI interface so I'm going to duplicate some

**1:40:22** · of the relevant pins so these four going to move them over here there is one more for the chip select I'm using this one here duplicate that and move it over across to this side let's do the wiring so CS goes here clock goes here

**1:40:44** · Mossy goes here data input di di miso data output goes there do okay data out put actually I need to do conditioning here so let's just remove that out of the way and I need another small resistor just going to copy the one from here this one duplicate it and move it over this side so this is 50 ohms and this should be

**1:41:13** · R22 actually I'll move all that a little bit to the left because I need to do something with pin number three right there so pin three along with hold will go to 3.3 volts so we're going to be holding those high at a high level that goes there and that goes there better

**1:41:37** · and on the other side I need just a single capacitor so bypass capacitor to connect ground to ground and on the other side VCC will go

**1:41:52** · to 3.3 volts it's going to be c14 and 0.1 micro farads is sufficient so move that a bit closer and we're done all right let's put this in a box and this is going to be the flash memory almost done with this page from this page that contains the esp32 we are going to Branch out to two other pages

**1:42:22** · one is going to contain the hardware for the sensors and the other one for the user interface so just like earlier I'm going to create the hierarchical sheets for those two additional pages and I'll start with the shade for the sensus I'll call that sensus and the shade file will

**1:42:45** · be sensus and I'll give it a color let's make it sign in and the second one is going to be for the user interface so that's user interface and for the sheet name I'll just a user interface and I'll use uh Fu color I'm going to make that orange okay let's try again with a sensors let's go to the

**1:43:21** · properties I clicked on the B water instead of the fuel s in all right that's better okay so we're going to add bits and pieces in those boxes later when we uh start work on the sensors and the user interface so save just going to do one last cross check before I leave this sheet alone for now

**1:43:46** · oh yeah one thing that I haven't done was to fill the the data in the legend down here so let's do that so this is going to the esp32 C3 USB and um flash

**1:44:03** · memory okay that's good save just going to take a moment to check everything here's one thing that I forget I'm just going to do it now before we continue what I want to do is to have a few test points in the final PCB so these are pads on the board that I'll be able to attach test instruments just to check on

**1:44:26** · the operation of the board without having to tap onto pins so I'm going to add a few test points here to do that I'm going to move these two blocks a bit to the right just to make a bit of room and I'm going to add the test points right here so tap the a key search for test points you can see there's a test Point here I'm going to go for the just simple test point looks like this Orient them like this or like this doesn't

**1:44:58** · really matter so this first one is going to be Mossy just going to duplicate them I want to have five of those I want to be able to test the SP interface so 1 2 3 4 One More five so I want to have

**1:45:18** · Mossy miso clock and the two select p duplicate those just put them up here for now so the first test point is going to be Mossy place that right there second one is going to be misso then I'll have the clock and then I'll have the chip select signals so for the SD card and for the flash memory I

**1:45:44** · change the name so this going to be test I use lowcase test Mossy test miso test s k o clock test CS SD and

**1:46:07** · finally test CS give a bit of space before I move to the next sheet just notice one thing here I'd really like to have this capacitor on the left side so that it's closer to vdd so the way to do this really quickly and easily is to just select the two and then use this button up here mirror horizontally or just type X and it will flip it across and I use G just move the bundle

**1:46:40** · of components together to the one side do the same thing again down here so that everything is nice and symmetrical so I'm going to save and then continue with the next sheet which is the sensus shet let's continue with the next shet in line which is the sensus shet so in here I am going to create a circuitry for these main components the microphone preamplifier the BME 280 environment

**1:47:11** · sensor it's the ambient light sensor and the microphone already collected of course the data sheets for these components you can see here is's a data sheet for the um microphone preamplifier fairly straightforward I'll be implementing this circuitry right here

**1:47:29** · here is the ambient light sensor fairly straightforward to implement the microphone that works with the preamplifier and the data sheet for the bme280 also fairly straightforward to implement there's nothing to it really uses the r s c interface and we can just follow the general gu lines for any i s c interface device to connected as always I'm going to start by dropping the main components onto my designer that's the BME 280 start with that next I'll add the

**1:48:03** · microphone and the preamplifier CMC 50 that's one I downloaded from snapa a bit earlier so that goes there and I also need to get the preamplifier which is model number Max 446 6 exk that one right there so place that

**1:48:27** · right here and uh then there's also the photo sensor so I'll put that up the top so there's going to be T Mt right there I'm just making use of my previous research here so that I can search by the various model numbers or other keywords obviously I don't remember those things by heart I'm going to start with the BME 280 and um set up

**1:48:53** · the supporting circuitry it's pretty simple so this is just an i s c device so I only need a couple of resistors for the pullup for the two lines for the clock and for the data line so add a resistor here this is going to be a 4.7 KMS resistor 4. 7K or better 4K 7 and

**1:49:22** · I'm going to call this r24 and I need two of those because I've got two lines that I need to pull up so there going to be the same value but it's going to be r25 okay done and I'm going to get a 3.3
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

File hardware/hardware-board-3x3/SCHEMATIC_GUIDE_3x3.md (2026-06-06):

# Matrix Board Schematic — Hand-Drawing Guide / Reference

This is the build sheet for the OpenChess matrix board. It documents
every component, every pin, and every net so you can either:

1. **Use it as reference** for the existing scripted schematic (which is
   already ERC-clean), or
2. **Use it as a build sheet** to hand-redraw the schematic in the
   KiCad GUI.

## ⚠️ Honest warning about going hand-drawn on this board

The matrix board has **236 electrical components**:

- 64 A3144 Hall sensors
- 81 WS2812B LEDs
- 81 100 nF LED decoupling caps
- 9 47 µF row bulk caps
- 1 470 µF entry cap
- 1 J_CTRL 2x13 connector
- Plus test points, mounting holes, fiducials

The 81 LEDs are wired in a **single daisy-chained data line** (DIN of
LED N+1 connects to DOUT of LED N) — drawing 80 of those wires by hand
is tedious and error-prone. The scripted version snaps every pin to
grid and gets ERC-clean automatically; hand-drawn versions almost
always pick up at least one stray wire that ERC then complains about.

**Recommendation: keep the scripts running this board.** They work,
they're already ERC-clean, and the matrix board is exactly the kind of
repetitive component-on-a-grid layout where scripts shine. If you want
to update placement, edit `scripts/sch/geometry.py` and re-run the
chunks — it's faster than redrawing 236 components.

If you've made the decision anyway and want to hand-draw it: this guide
gives you the full build sheet. Allocate a few hours and brew coffee.

---

## 0. Setup

### Backup before doing anything destructive

```bash
cd /Users/paolonessim/Projects/openchess/hardware/hardware-board
cp openchess-board.kicad_sch openchess-board.kicad_sch.scripted_backup
```

### Two paths

**Path A — Keep scripts as-is (recommended).** Use this guide as a
read-only reference. Nothing to change.

**Path B — Switch to hand-drawn.** Open the schematic, Edit → Select All
→ Delete (keeps page + title block + lib_symbols). Then archive the
scripts so nothing wipes your work:

```bash
mv scripts/sch scripts/sch.archived
mkdir -p scripts/sch
echo "Scripts archived 2026-06-05 — matrix board maintained by hand in KiCad GUI." > scripts/sch/README.md
```

---

## 1. Conventions used in this guide

### Power vs net labels

- **Power port** (`P`) → `GND` only. The 5 V rail is named `+5V_LED`
  (a custom name), so use a **net label** for it everywhere.
- **Net label** (`L`) → `+5V_LED`, `LED_DATA_5V`, `LED_DOUT_END`,
  `S0..S7`, `CA_PWR..CH_PWR`, and the per-LED DIN/DOUT mid-nets if you
  choose to name them.
- **No-Connection flag** (`Q`) → none needed on this board.

### KiCad shortcuts

| Key | Action |
|---|---|
| `A` | Add symbol |
| `W` | Wire |
| `L` | Net label |
| `P` | Power port |
| `R` | Rotate |
| `M` | Move |
| `G` | Drag with wires |
| `E` | Edit properties |
| `Ctrl+D` | Duplicate (great for placing 64 of something) |

### Reference designators

| Range | Section |
|---|---|
| U1..U64 | A3144 Hall sensors, **file-major**: U1=A1, U2=A2, …, U8=A8, U9=B1, …, U64=H8 |
| D1..D81 | WS2812B LEDs, **row-major top-down**: D1=top-left corner, D9=top-right, D10=row-2-left, …, D81=bottom-right |
| C1..C9 | Row bulk caps (47 µF), one per row of the LED grid |
| C10..C90 | Per-LED 100 nF decoupling caps (one per WS2812). Number-matched with LED: D1↔C10, D2↔C11, …, D81↔C90 |
| C91 | 470 µF entry cap on `+5V_LED` |
| J1 | J_CTRL 2x13 connector to the controller |
| TP1..TP4 | Test points (one per rail/data net) |
| MH1..MH4 | M3 mounting holes |
| FID1..FID3 | Fiducials |

### Custom symbol

| lib_id | What | Where it lives |
|---|---|---|
| `openchess:A3144` | A3144 Hall sensor (TO-92, 3-pin) | `hardware-board/lib/openchess.kicad_sym` |

The other symbols are stock KiCad: `LED:WS2812B`, `Device:C`,
`Device:C_Polarized`, `Connector_Generic:Conn_02x13_Odd_Even`,
`Connector:TestPoint`, `Mechanical:MountingHole`, `Mechanical:Fiducial`,
`power:PWR_FLAG`.

### Board nets summary (every net used)

**Power & data:**
- `+5V_LED` — 5 V supplied by controller through J_CTRL
- `GND` — ground
- `LED_DATA_5V` — WS2812 chain input (from controller, level-shifted)
- `LED_DOUT_END` — last WS2812 DOUT, exposed only as a test point

**Matrix interface (to J_CTRL):**
- `S0..S7` — row sense nets, one per chess rank
- `CA_PWR..CH_PWR` — column power rails, one per chess file

If your schematic has any other label, it's a typo.

### Page layout

The chunk-01 skeleton gives you four boxes:

```
A2 page, top-left origin (rough coordinates from the script)

   ┌─────────────────────────────────────────────────┐
   │   Box: 8x8 HALL GRID                            │
   │     U1..U64, A3144 sensors                      │
   │     file-major (U1=A1, U64=H8)                  │
   └─────────────────────────────────────────────────┘
   ┌─────────────────────────────────────────────────┐
   │   Box: 9x9 LED GRID                             │
   │     D1..D81 WS2812B + C10..C90 100 nF caps      │
   │     daisy-chained DIN/DOUT                      │
   └─────────────────────────────────────────────────┘
   ┌──────────────────┐ ┌─────────────────────────────┐
   │  Box: BULK CAPS  │ │  Box: J_CTRL + TEST + MECH  │
   │  C1..C9 (47µF)   │ │  J1 + C91 + TP1..TP4 + MH   │
   │  one per row     │ │                             │
   └──────────────────┘ └─────────────────────────────┘
```

Exact box coordinates are in `scripts/sch/01_skeleton.py` — if you
re-run only that script (Path B above), you'll get the boxes back as
visual guides.

---

## Section A — 8×8 Hall Sensor Grid (64 sensors)

The chess board has 8 files (A–H, left to right) and 8 ranks (1–8, bottom
to top in chess convention but you can flip on the PCB). Each square
gets one A3144 Hall sensor.

### A.1 Component template (1 of 64)

| Field | Value |
|---|---|
| Symbol | `openchess:A3144` |
| Value | A3144 |
| Footprint | `Package_TO_SOT_THT:TO-92_Inline` |

Pin map:
- Pin 1 = VCC
- Pin 2 = GND
- Pin 3 = OUT (open-collector)

### A.2 Refdes scheme

```
ref(file, rank) = U(1 + file_idx * 8 + rank_idx)
                  where file_idx = 0..7 for files A..H
                        rank_idx = 0..7 for ranks 1..8

U1  = A1   U9  = B1   U17 = C1   ...   U57 = H1
U2  = A2   U10 = B2                    U58 = H2
...                                    ...
U8  = A8   U16 = B8                    U64 = H8
```

### A.3 Wiring per sensor

For Hall sensor at file F (A..H) and rank R (1..8):

| Pin | Net |
|---|---|
| 1 (VCC) | Net label `C{F}_PWR` — e.g. `CA_PWR` for file A, `CH_PWR` for file H |
| 2 (GND) | `GND` power port |
| 3 (OUT) | Net label `S{R-1}` — e.g. `S0` for rank 1, `S7` for rank 8 |

So all 8 sensors in **file A** share `CA_PWR` on their VCC pins, and all
8 sensors in **rank 1** share `S0` on their OUT pins. The matrix is
formed entirely by net labels — no wiring between sensors is needed
beyond the per-pin stubs to labels.

### A.4 Practical placement workflow

1. Place **one** A3144 at the A1 position (bottom-left of the grid)
   with the three net labels on its pins (`CA_PWR`, `GND`, `S0`).
2. `Ctrl+D` to duplicate it 7 times vertically (file A, ranks 1..8) and
   update the OUT label to `S0..S7` accordingly. Update refs to U1..U8.
3. Select the column, copy, paste 7 times to the right (one paste per
   file B..H). Update VCC labels to `CB_PWR..CH_PWR` per file. Update
   refs.

Total: 64 sensors × 3 labels each = 192 label updates. Real talk: this
is the moment to reconsider keeping the script.

---

## Section B — 9×9 WS2812B LED Grid (81 LEDs)

LEDs sit at the **corners** of the chess squares, so the grid is 9×9 (one
more than 8×8). The chain enters at the top-left, snakes through, and
exits at the bottom-right.

### B.1 Component template (1 of 81)

| Field | Value |
|---|---|
| Symbol | `LED:WS2812B` |
| Value | WS2812B |
| Footprint | `LED_SMD:LED_WS2812B_PLCC4_5.0x5.0mm_P3.2mm` |

Pin map:
- Pin 1 = VDD
- Pin 2 = DOUT
- Pin 3 = VSS (GND)
- Pin 4 = DIN

### B.2 Refdes + chain order

Row-major top-down: D1 is the top-left, D9 is the top-right of row 1,
D10 is the leftmost of row 2, etc., D81 is the bottom-right.

```
D1  D2  D3  D4  D5  D6  D7  D8  D9
D10 D11 D12 D13 D14 D15 D16 D17 D18
...
D73 D74 D75 D76 D77 D78 D79 D80 D81
```

Chain direction depends on the script's chosen serpentine pattern. The
simplest hand-drawable choice: **left-to-right then snake back**:

```
D1 → D2 → D3 → ... → D9
                     ↓
D18 ← D17 ← D16 ← ... ← D10
↓
D19 → D20 → ... → D27
                     ↓
...
```

You can match the existing script's order by reading
`scripts/sch/03_leds.py` — but for the schematic to be electrically
correct, **the chain order only matters for firmware indexing, not for
the schematic itself.** As long as you connect DIN of each LED to DOUT
of one specific other LED, the chain is valid.

### B.3 Wiring per LED

For LED `Dk` (1 ≤ k ≤ 81):

| Pin | Net |
|---|---|
| 1 (VDD) | Net label `+5V_LED` |
| 2 (DOUT) | Wire to **next LED's pin 4 (DIN)** — except for D81 which goes to net label `LED_DOUT_END` |
| 3 (VSS) | `GND` power port |
| 4 (DIN) | Wire from **previous LED's pin 2 (DOUT)** — except for D1 which gets net label `LED_DATA_5V` |

So:
- **D1 pin 4 (DIN)** = `LED_DATA_5V` (chain entry)
- **D1 pin 2 (DOUT)** → wire to **D2 pin 4 (DIN)**
- **D2 pin 2 (DOUT)** → wire to **D3 pin 4 (DIN)**
- … (continue along your chosen chain order) …
- **D80 pin 2 (DOUT)** → wire to **D81 pin 4 (DIN)**
- **D81 pin 2 (DOUT)** = `LED_DOUT_END` (chain exit / test point)

### B.4 Practical placement workflow

1. Place **one** WS2812 (D1) in the top-left.
2. `Ctrl+D` to duplicate. Repeat for D2..D9 across the top row.
3. Wire each DOUT → next DIN.
4. Once you have one row wired correctly, copy the whole row to row 2,
   relabel D10..D18, fix the wrap-around wire from D9 DOUT → D10 DIN (or
   D9 DOUT → D18 DIN if snaking).
5. Repeat 7 more times.

Reality check: a copy-paste row of 9 LEDs takes about 5 minutes per row
once you have the first one. 9 rows × 5 min = 45 min. Plus another hour
fixing wiring mistakes.

---

## Section C — Per-LED Decoupling Caps (81 × 100 nF)

One 100 nF cap across VDD/VSS of each WS2812, placed physically as close
to the LED as the layout allows.

### C.1 Component template

| Field | Value |
|---|---|
| Symbol | `Device:C` |
| Value | 100nF |
| Footprint | `Capacitor_SMD:C_0805_2012Metric_Pad1.18x1.45mm_HandSolder` |

### C.2 Refdes

`Ck` is the decoupling cap for `D(k - 9)` (because C10 pairs with D1,
C11 with D2, …, C90 with D81).

| Cap | Pairs with LED |
|---|---|
| C10 | D1 |
| C11 | D2 |
| … | … |
| C90 | D81 |

### C.3 Wiring per cap

| Pin | Net |
|---|---|
| 1 (top) | Net label `+5V_LED` |
| 2 (bottom) | `GND` power port |

No wires between cap and LED needed — the connection is by label
(`+5V_LED` and `GND` are shared with the LED's VDD and VSS).

### C.4 Practical placement workflow

Place one cap next to D1 with both labels. Select the cap + its labels,
`Ctrl+D` 80 times, updating the ref each time. Or: place all 81 caps
without labels first, then mass-edit labels in the schematic editor
(KiCad supports "edit value of all selected" which can save time).

---

## Section D — Row Bulk Caps (9 × 47 µF)

One bulk cap per row of the LED grid, between `+5V_LED` and `GND`. These
absorb the current spikes when many LEDs simultaneously update.

### D.1 Component template

| Field | Value |
|---|---|
| Symbol | `Device:C` |
| Value | 47uF |
| Footprint | `Capacitor_SMD:C_1206_3216Metric` |

### D.2 Refdes + placement

| Ref | Position |
|---|---|
| C1 | Near row 1 (D1..D9) |
| C2 | Near row 2 (D10..D18) |
| C3 | Near row 3 |
| C4 | Row 4 |
| C5 | Row 5 |
| C6 | Row 6 |
| C7 | Row 7 |
| C8 | Row 8 |
| C9 | Row 9 (D73..D81) |

### D.3 Wiring per cap

| Pin | Net |
|---|---|
| 1 (top) | Net label `+5V_LED` |
| 2 (bottom) | `GND` power port |

Same labels for all 9 — they all parallel the same rail.

---

## Section E — `+5V_LED` Entry Bulk Cap (1 × 470 µF)

One large electrolytic at the J_CTRL entry to smooth the rail at its
source on the board.

### E.1 Component

| Ref | Symbol | Value | Footprint |
|---|---|---|---|
| C91 | `Device:C_Polarized` | 470uF | `Capacitor_THT:CP_Radial_D10.0mm_P5.00mm` |

> **Polarity matters** — pin 1 is the **+** (anode), pin 2 is the **−**
> (cathode). Make sure pin 1 connects to `+5V_LED`, not GND, or the cap
> will pop.

### E.2 Wiring

| Pin | Net |
|---|---|
| 1 (+) | Net label `+5V_LED` |
| 2 (−) | `GND` power port |

Place near J1 (J_CTRL).

---

## Section F — J_CTRL Connector

The 26-pin board-to-board connector to the controller PCB. This is the
contract side — pins must match the controller's J_MAIN exactly (see
`docs/inter-board-connector.md`).

> **Revised 2026-06-05.** Switched from shrouded-IDC + ribbon cable to
> a **board-to-board stacking female socket**. The controller PCB
> mounts directly underneath the matrix PCB; J_CTRL's female socket on
> the matrix's BACK face mates with J_MAIN's male pin header on the
> controller's top face. No ribbon cable; ~11 mm M3 standoffs hold the
> stack rigid.

### F.1 Component

| Ref | Symbol | Value | Footprint |
|---|---|---|---|
| J1 | `Connector_Generic:Conn_02x13_Odd_Even` | J_CTRL 2x13 | `Connector_PinSocket_2.54mm:PinSocket_2x13_P2.54mm_Vertical` (female socket, on the **back side** of the matrix PCB) |

**Footprint placement**: J_CTRL must sit on the matrix PCB's **back
face** (the face away from the chess pieces / LEDs), at a position
that matches where the controller PCB will sit. From the user's
layout mockup, this is offset to one edge of the matrix board (the
same edge as the side panel), not centered. Coordinate this with the
controller PCB layout.

Mark **pin 1 with a silkscreen dot** for assembly. Add 4 M3 mounting
holes near the connector position so M3 standoffs can thread from the
matrix's back to the controller's top.

### F.2 Pin-by-pin

| Pin | Net | How |
|---:|---|---|
| 1 | `+5V_LED` | Net label |
| 2 | GND | Power port |
| 3 | `+5V_LED` | Net label |
| 4 | GND | Power port |
| 5 | `+5V_LED` | Net label |
| 6 | GND | Power port |
| 7 | `LED_DATA_5V` | Net label |
| 8 | GND | Power port |
| 9 | `S0` | Net label |
| 10 | `S1` | Net label |
| 11 | `S2` | Net label |
| 12 | `S3` | Net label |
| 13 | `S4` | Net label |
| 14 | `S5` | Net label |
| 15 | `S6` | Net label |
| 16 | `S7` | Net label |
| 17 | `CA_PWR` | Net label |
| 18 | `CB_PWR` | Net label |
| 19 | `CC_PWR` | Net label |
| 20 | `CD_PWR` | Net label |
| 21 | `CE_PWR` | Net label |
| 22 | `CF_PWR` | Net label |
| 23 | `CG_PWR` | Net label |
| 24 | `CH_PWR` | Net label |
| 25 | `+5V_LED` | Net label |
| 26 | GND | Power port |

---

## Section G — Test Points, Mounting Holes, Fiducials

### G.1 Recommended test points

Minimal — just the four nets that aren't already accessible through
labels at the connector:

| TP | Net |
|---|---|
| TP1 | `+5V_LED` |
| TP2 | `GND` |
| TP3 | `LED_DATA_5V` |
| TP4 | `LED_DOUT_END` |

Symbol `Connector:TestPoint`, footprint
`TestPoint:TestPoint_Pad_D1.5mm`. Wire the pin to a net label /
power port.

> Don't bother test-pointing every `S0..S7` or `CA_PWR..CH_PWR` — those
> are all accessible at J1's pin pads with a scope probe.

### G.2 Mechanical

| Ref | Symbol | Footprint |
|---|---|---|
| MH1..MH4 | `Mechanical:MountingHole` | `MountingHole:MountingHole_3.2mm_M3` |
| FID1..FID3 | `Mechanical:Fiducial` | `Fiducial:Fiducial_1mm_Mask2mm` |

### G.3 PWR_FLAG symbols

The matrix board **consumes** `+5V_LED` and `GND` from the controller
through J1. ERC can't see the controller, so drop a `power:PWR_FLAG` on
both rails to silence the "no driver" warnings:

- `PWR_FLAG` on `+5V_LED`
- `PWR_FLAG` on `GND`

---

## Section H — Final Checks

### H.1 ERC

Inspect → **Electrical Rules Checker**. Expected: 0 violations.

Likely issues on a hand-drawn version of this board:

- **One stray DIN/DOUT in the LED chain** — if you skipped a connection
  between two LEDs, you'll see "pin not driven" on one DIN. Trace the
  chain to find the gap.
- **Mislabeled column or row net** — for example, a Hall sensor with
  `CA_PWR` on its VCC but it's physically in file C (should be
  `CC_PWR`). Check by selecting one sensor at a time and verifying its
  refdes (Uk where k = 1 + file*8 + rank) matches its file/rank labels.
- **Missing PWR_FLAG** — adds the "no driver" warnings on `+5V_LED` and
  `GND`. Easy fix.
- **Polarity error on C91** — won't be caught by ERC but will smoke at
  power-on. Double-check before assembly.

### H.2 Annotate

Tools → **Annotate Schematic**. For a 236-component board this matters
— make sure refs are sequential without gaps.

### H.3 Commit

```bash
git add openchess-board.kicad_sch
git commit -m "matrix board schematic: hand-drawn rev0.1 — 8x8 halls + 9x9 LEDs + J_CTRL"
```

---

## Quick-reference: every net on this board

For sanity-checking labels.

**Power:**
- `+5V_LED` — from controller via J1
- `GND` — ground

**Data:**
- `LED_DATA_5V` — WS2812 chain input at D1
- `LED_DOUT_END` — WS2812 chain exit at D81 (test point)

**Matrix:**
- `S0..S7` — 8 row sense lines (one per rank); pullups on controller
- `CA_PWR..CH_PWR` — 8 column power lines (one per file)

If your schematic has a label not in this list, it's a typo.

---
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

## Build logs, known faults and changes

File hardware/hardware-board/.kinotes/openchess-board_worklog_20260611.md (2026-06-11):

# Work Log — openchess-board
**Total: 0h 0m**

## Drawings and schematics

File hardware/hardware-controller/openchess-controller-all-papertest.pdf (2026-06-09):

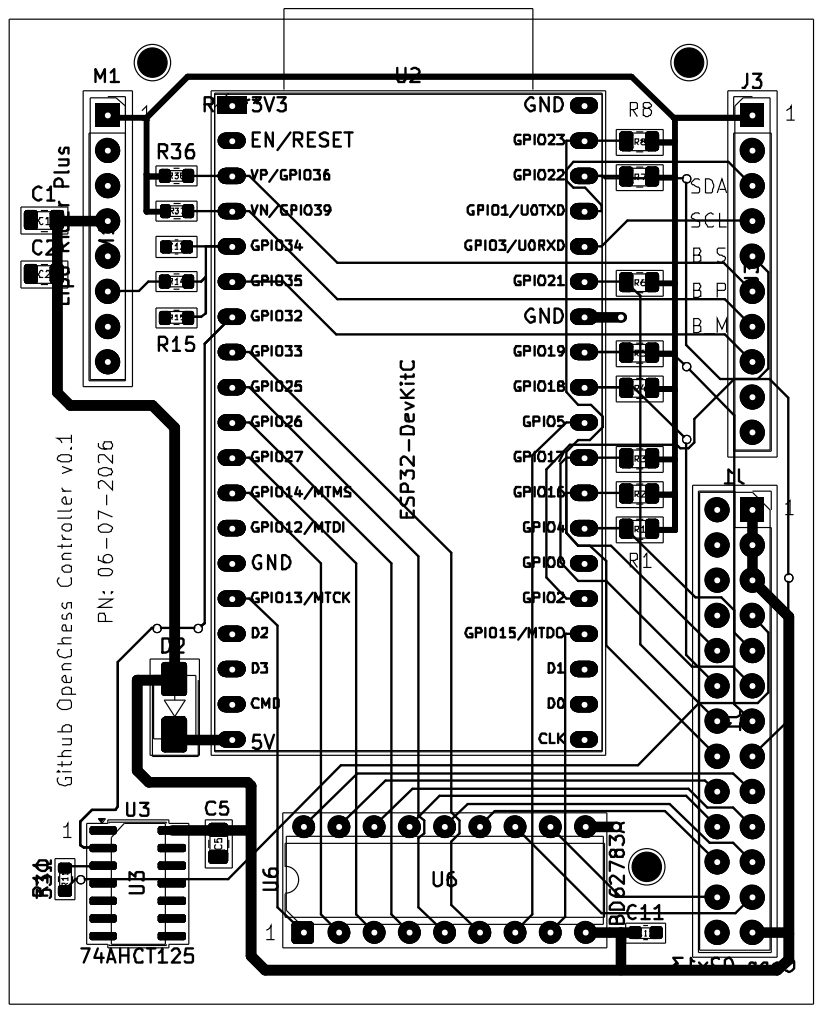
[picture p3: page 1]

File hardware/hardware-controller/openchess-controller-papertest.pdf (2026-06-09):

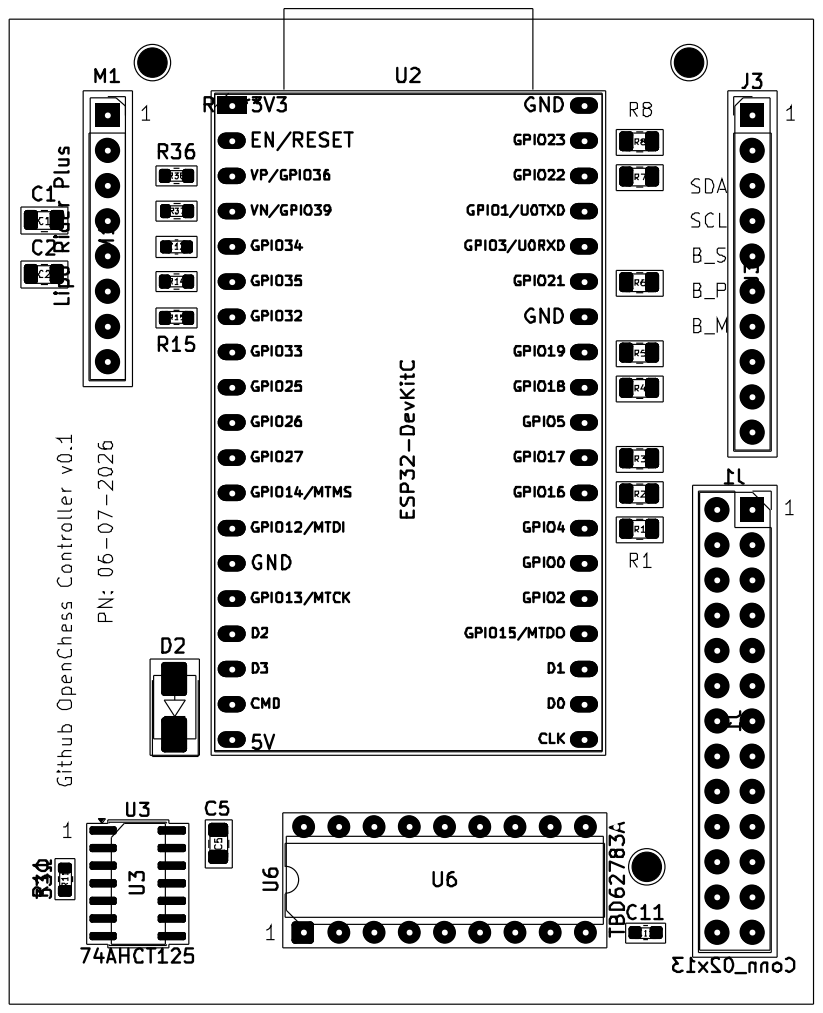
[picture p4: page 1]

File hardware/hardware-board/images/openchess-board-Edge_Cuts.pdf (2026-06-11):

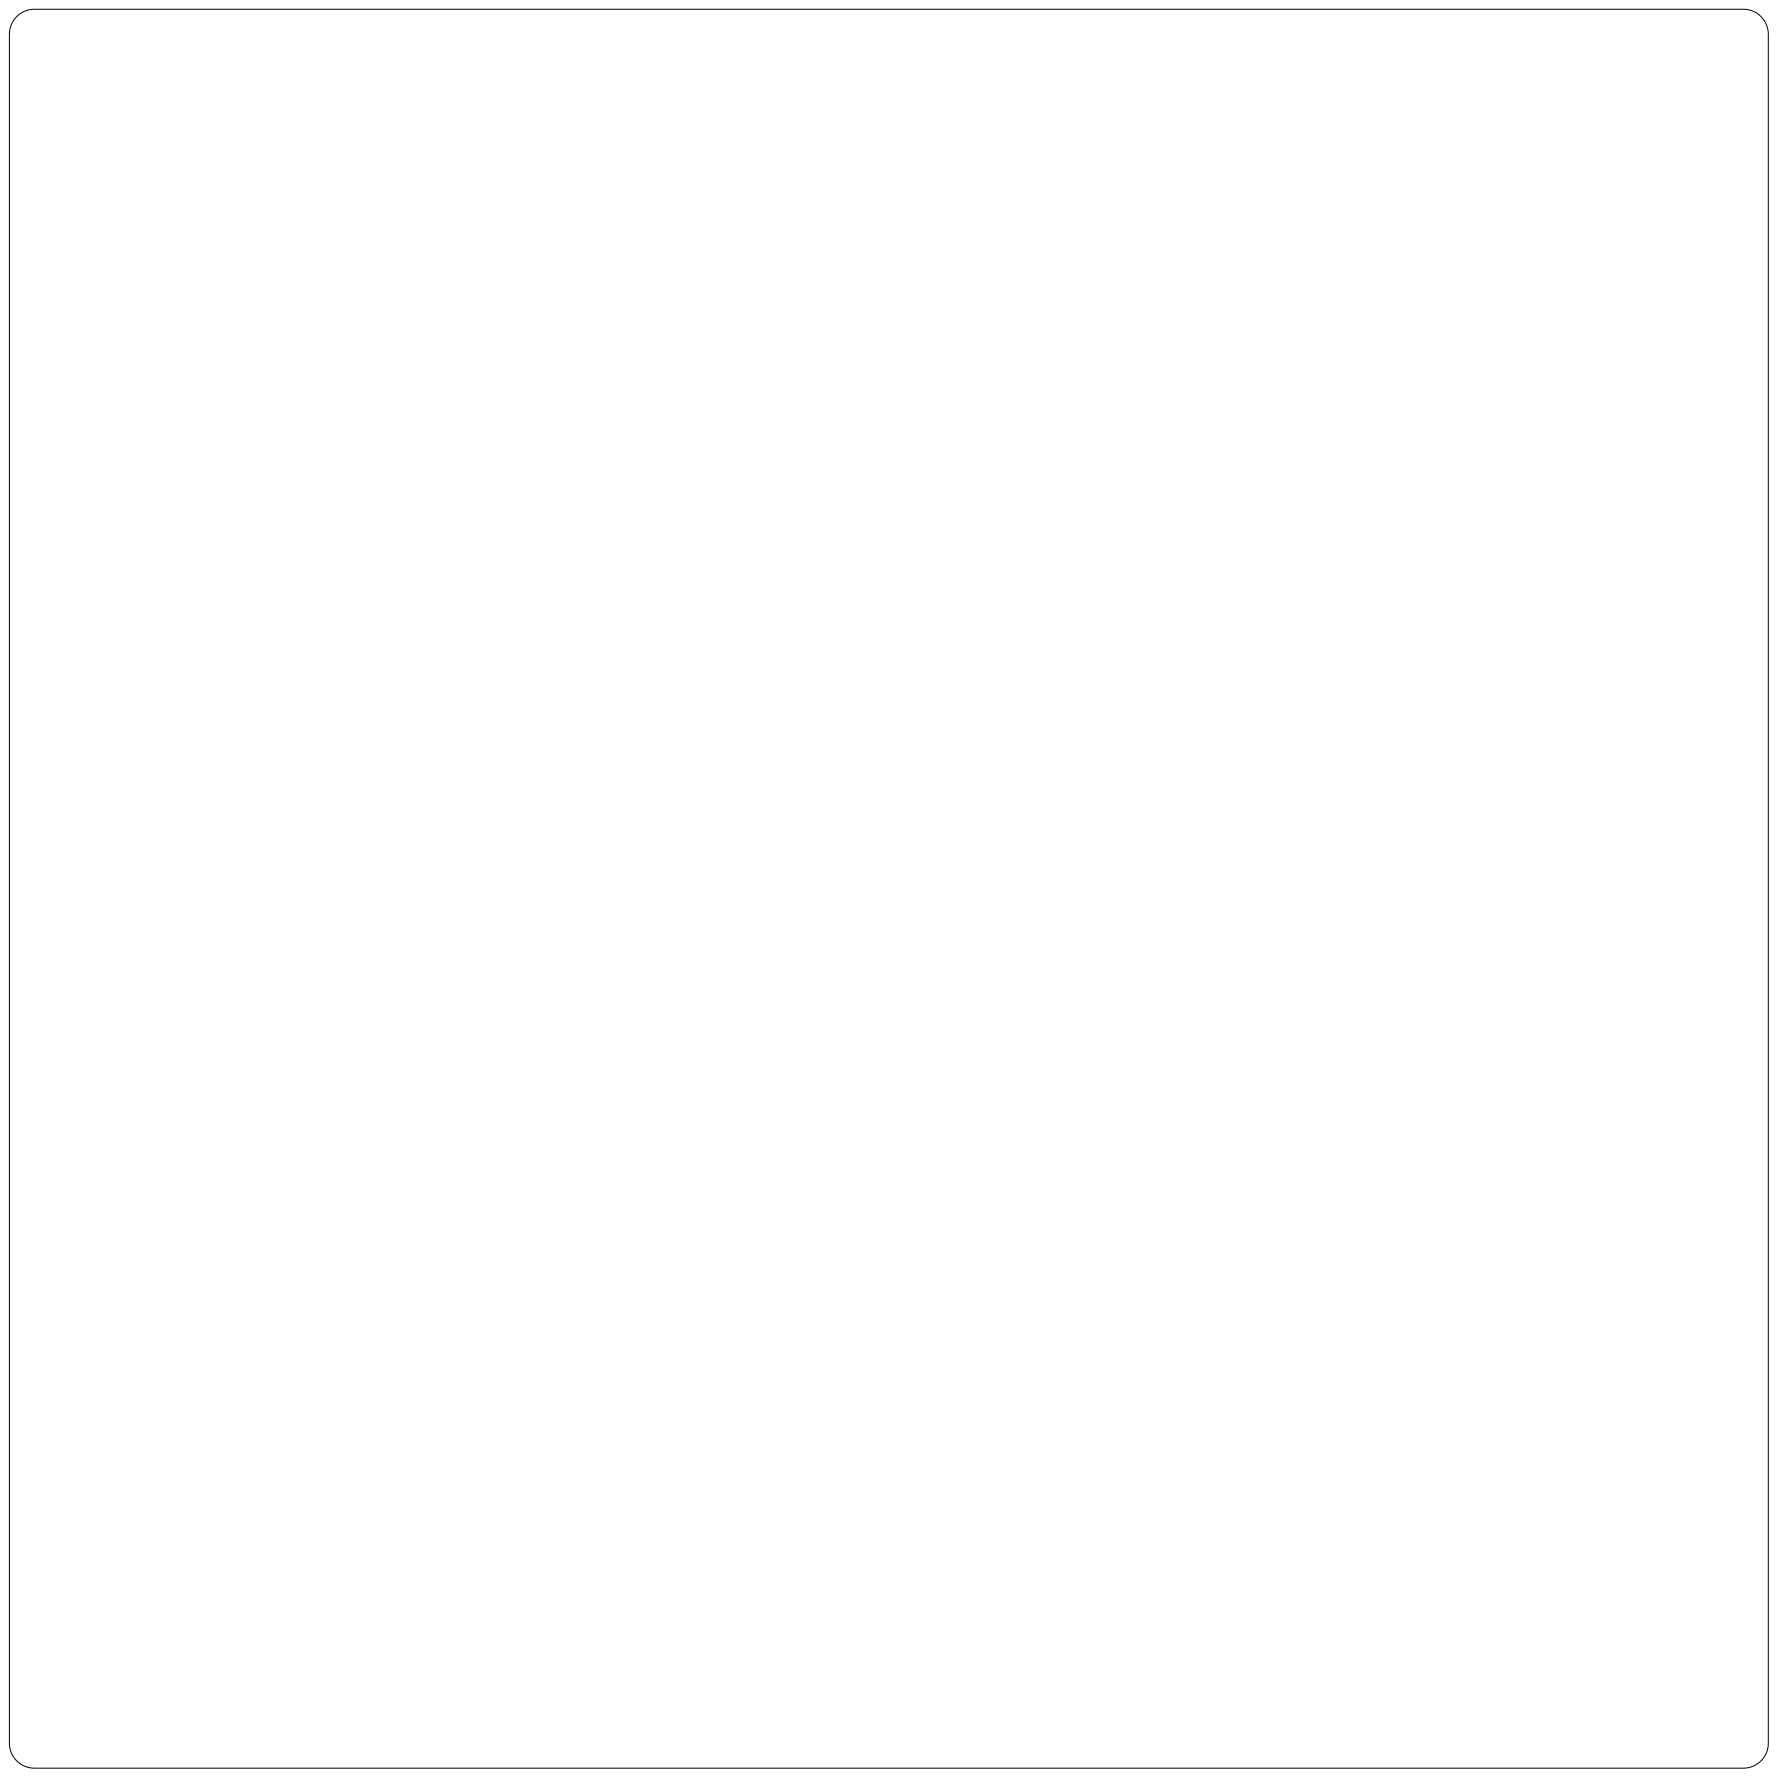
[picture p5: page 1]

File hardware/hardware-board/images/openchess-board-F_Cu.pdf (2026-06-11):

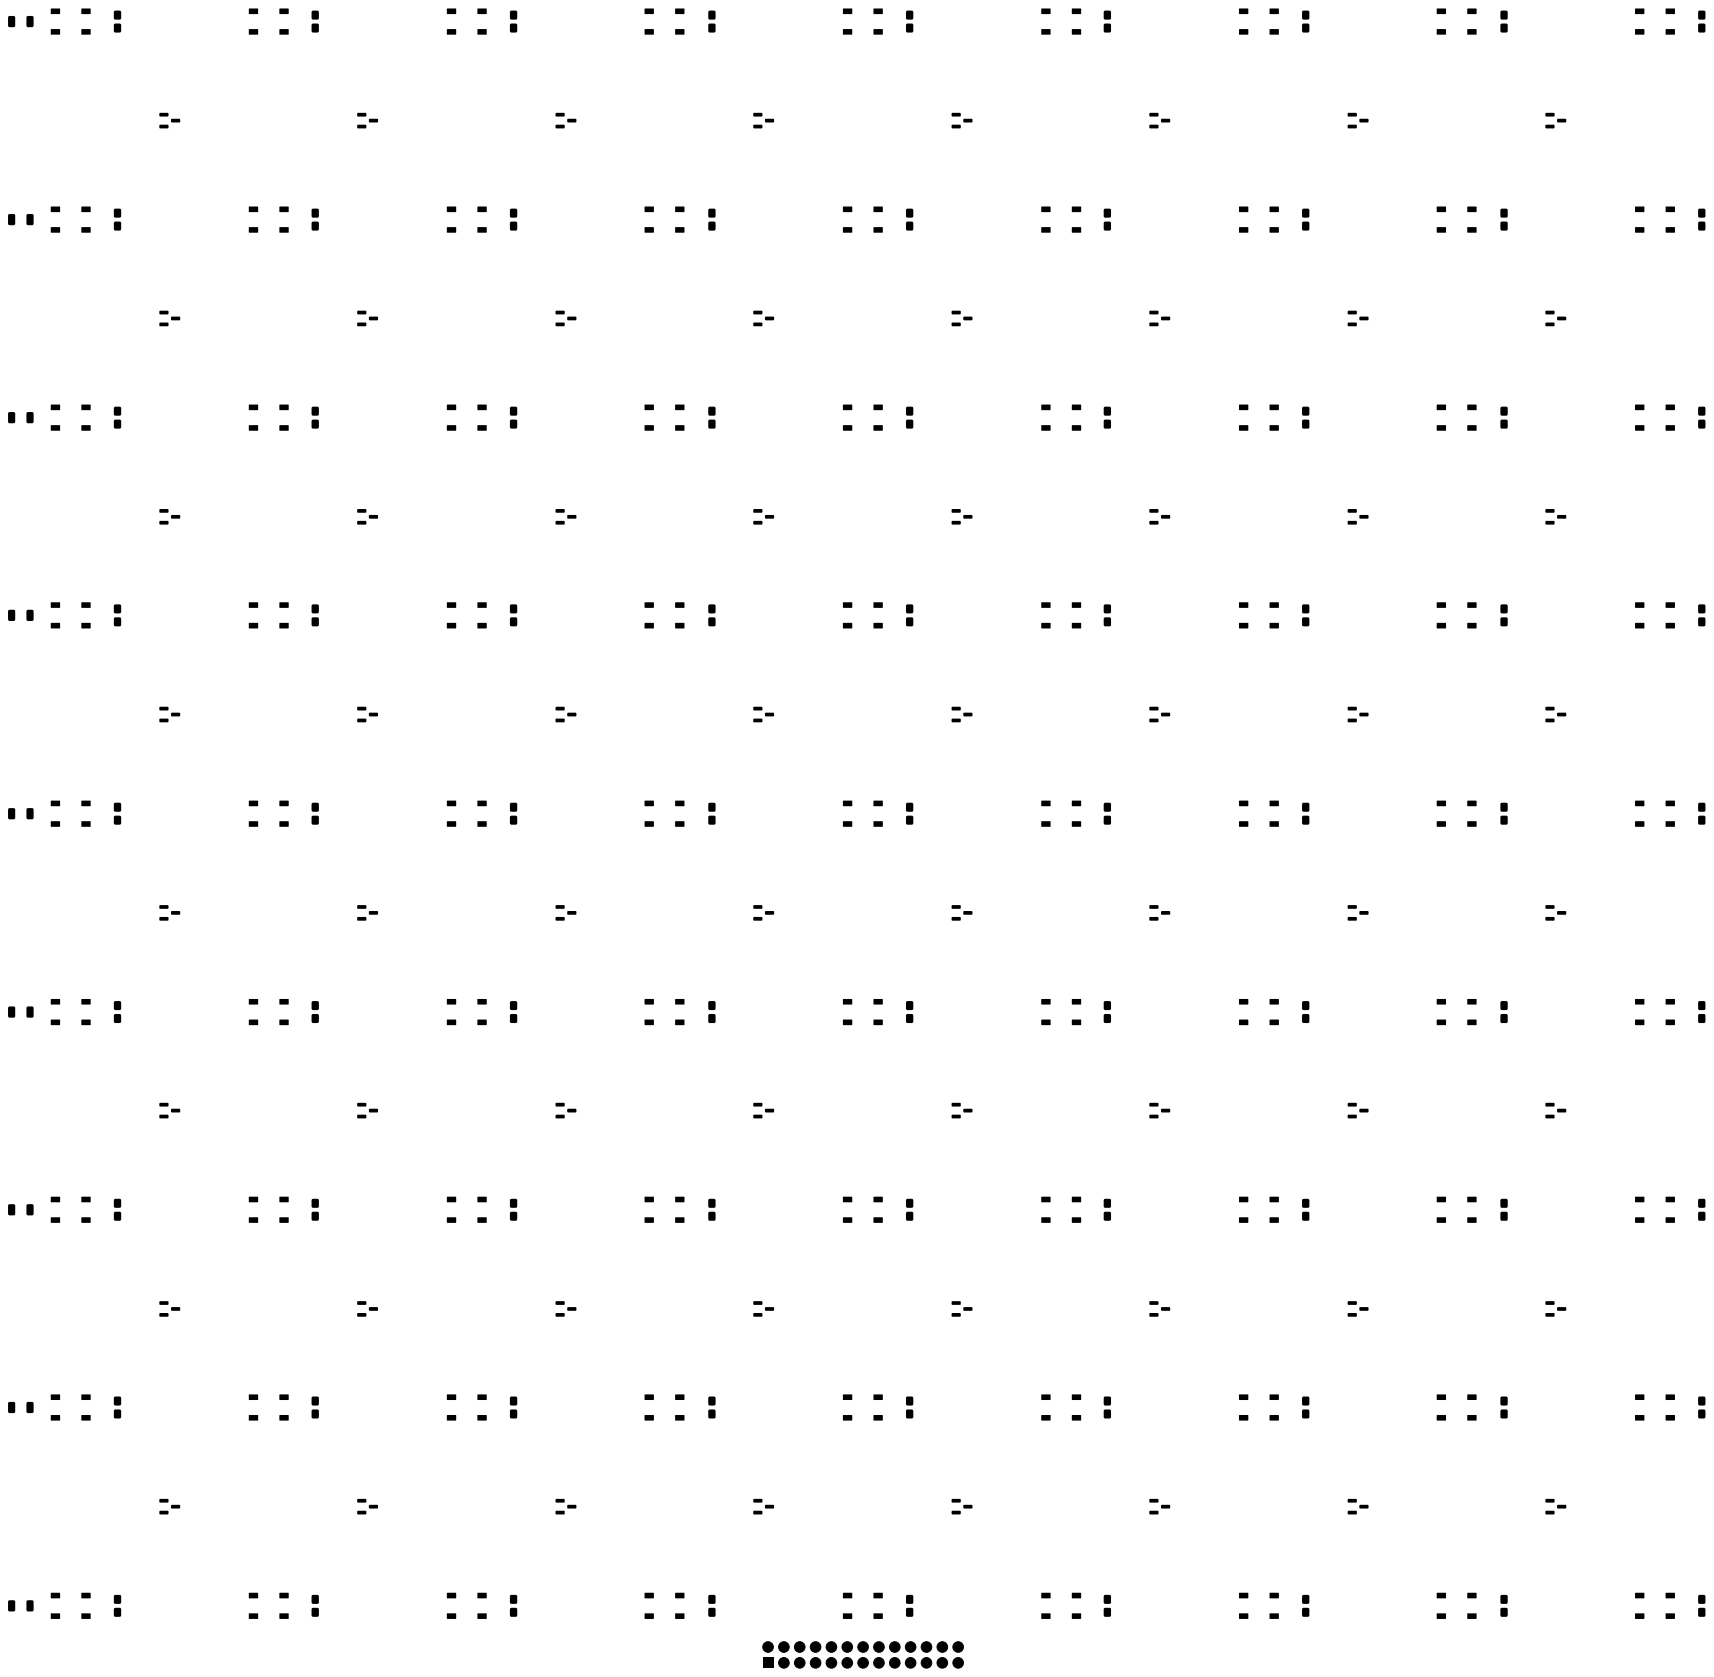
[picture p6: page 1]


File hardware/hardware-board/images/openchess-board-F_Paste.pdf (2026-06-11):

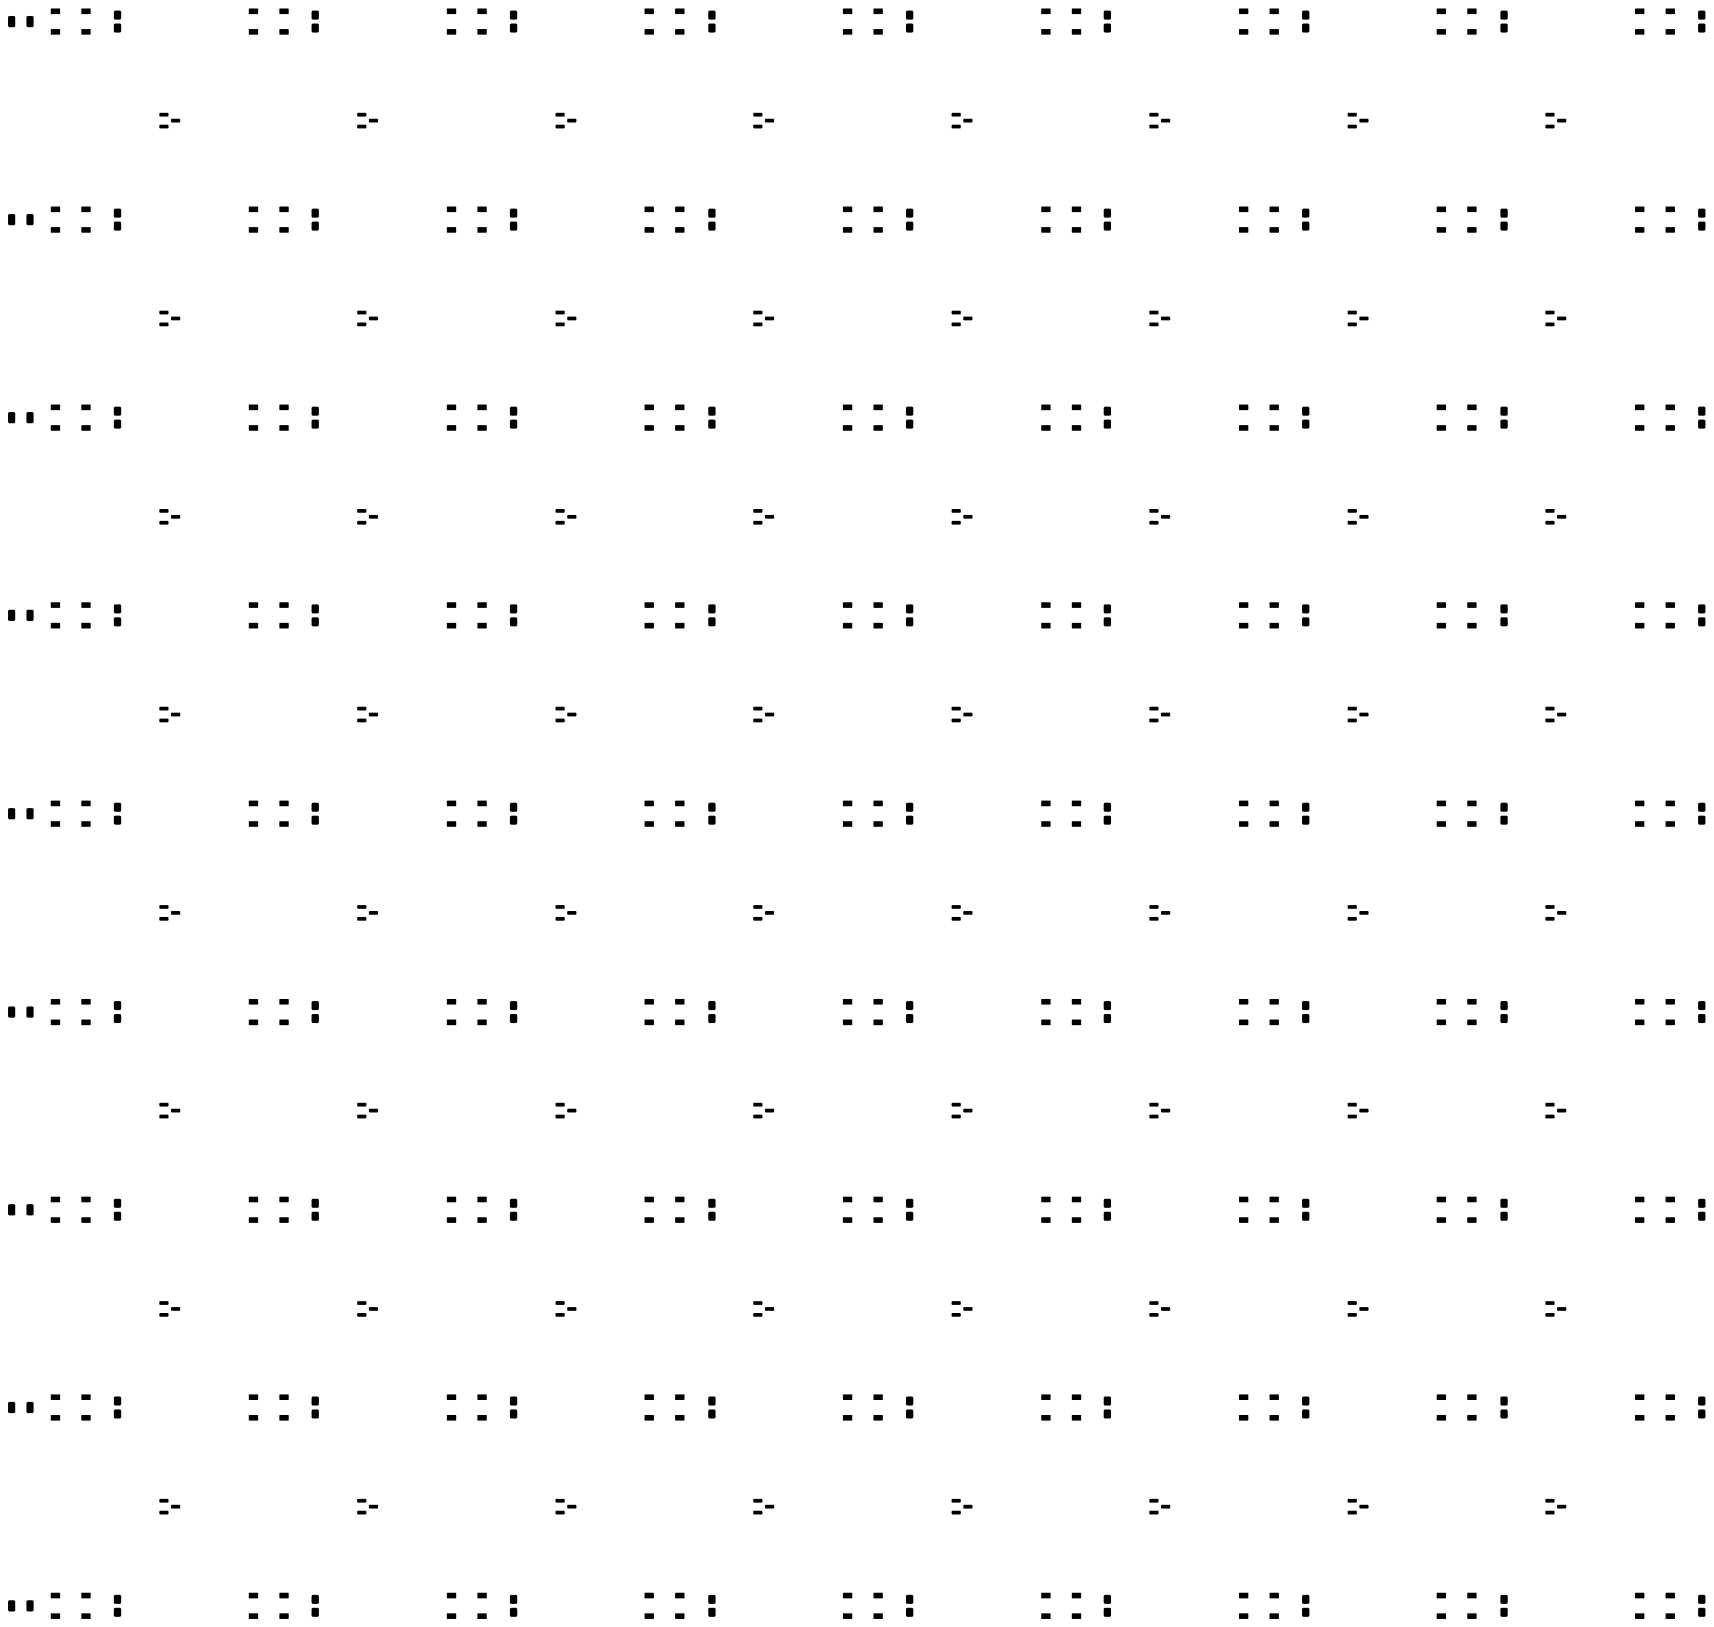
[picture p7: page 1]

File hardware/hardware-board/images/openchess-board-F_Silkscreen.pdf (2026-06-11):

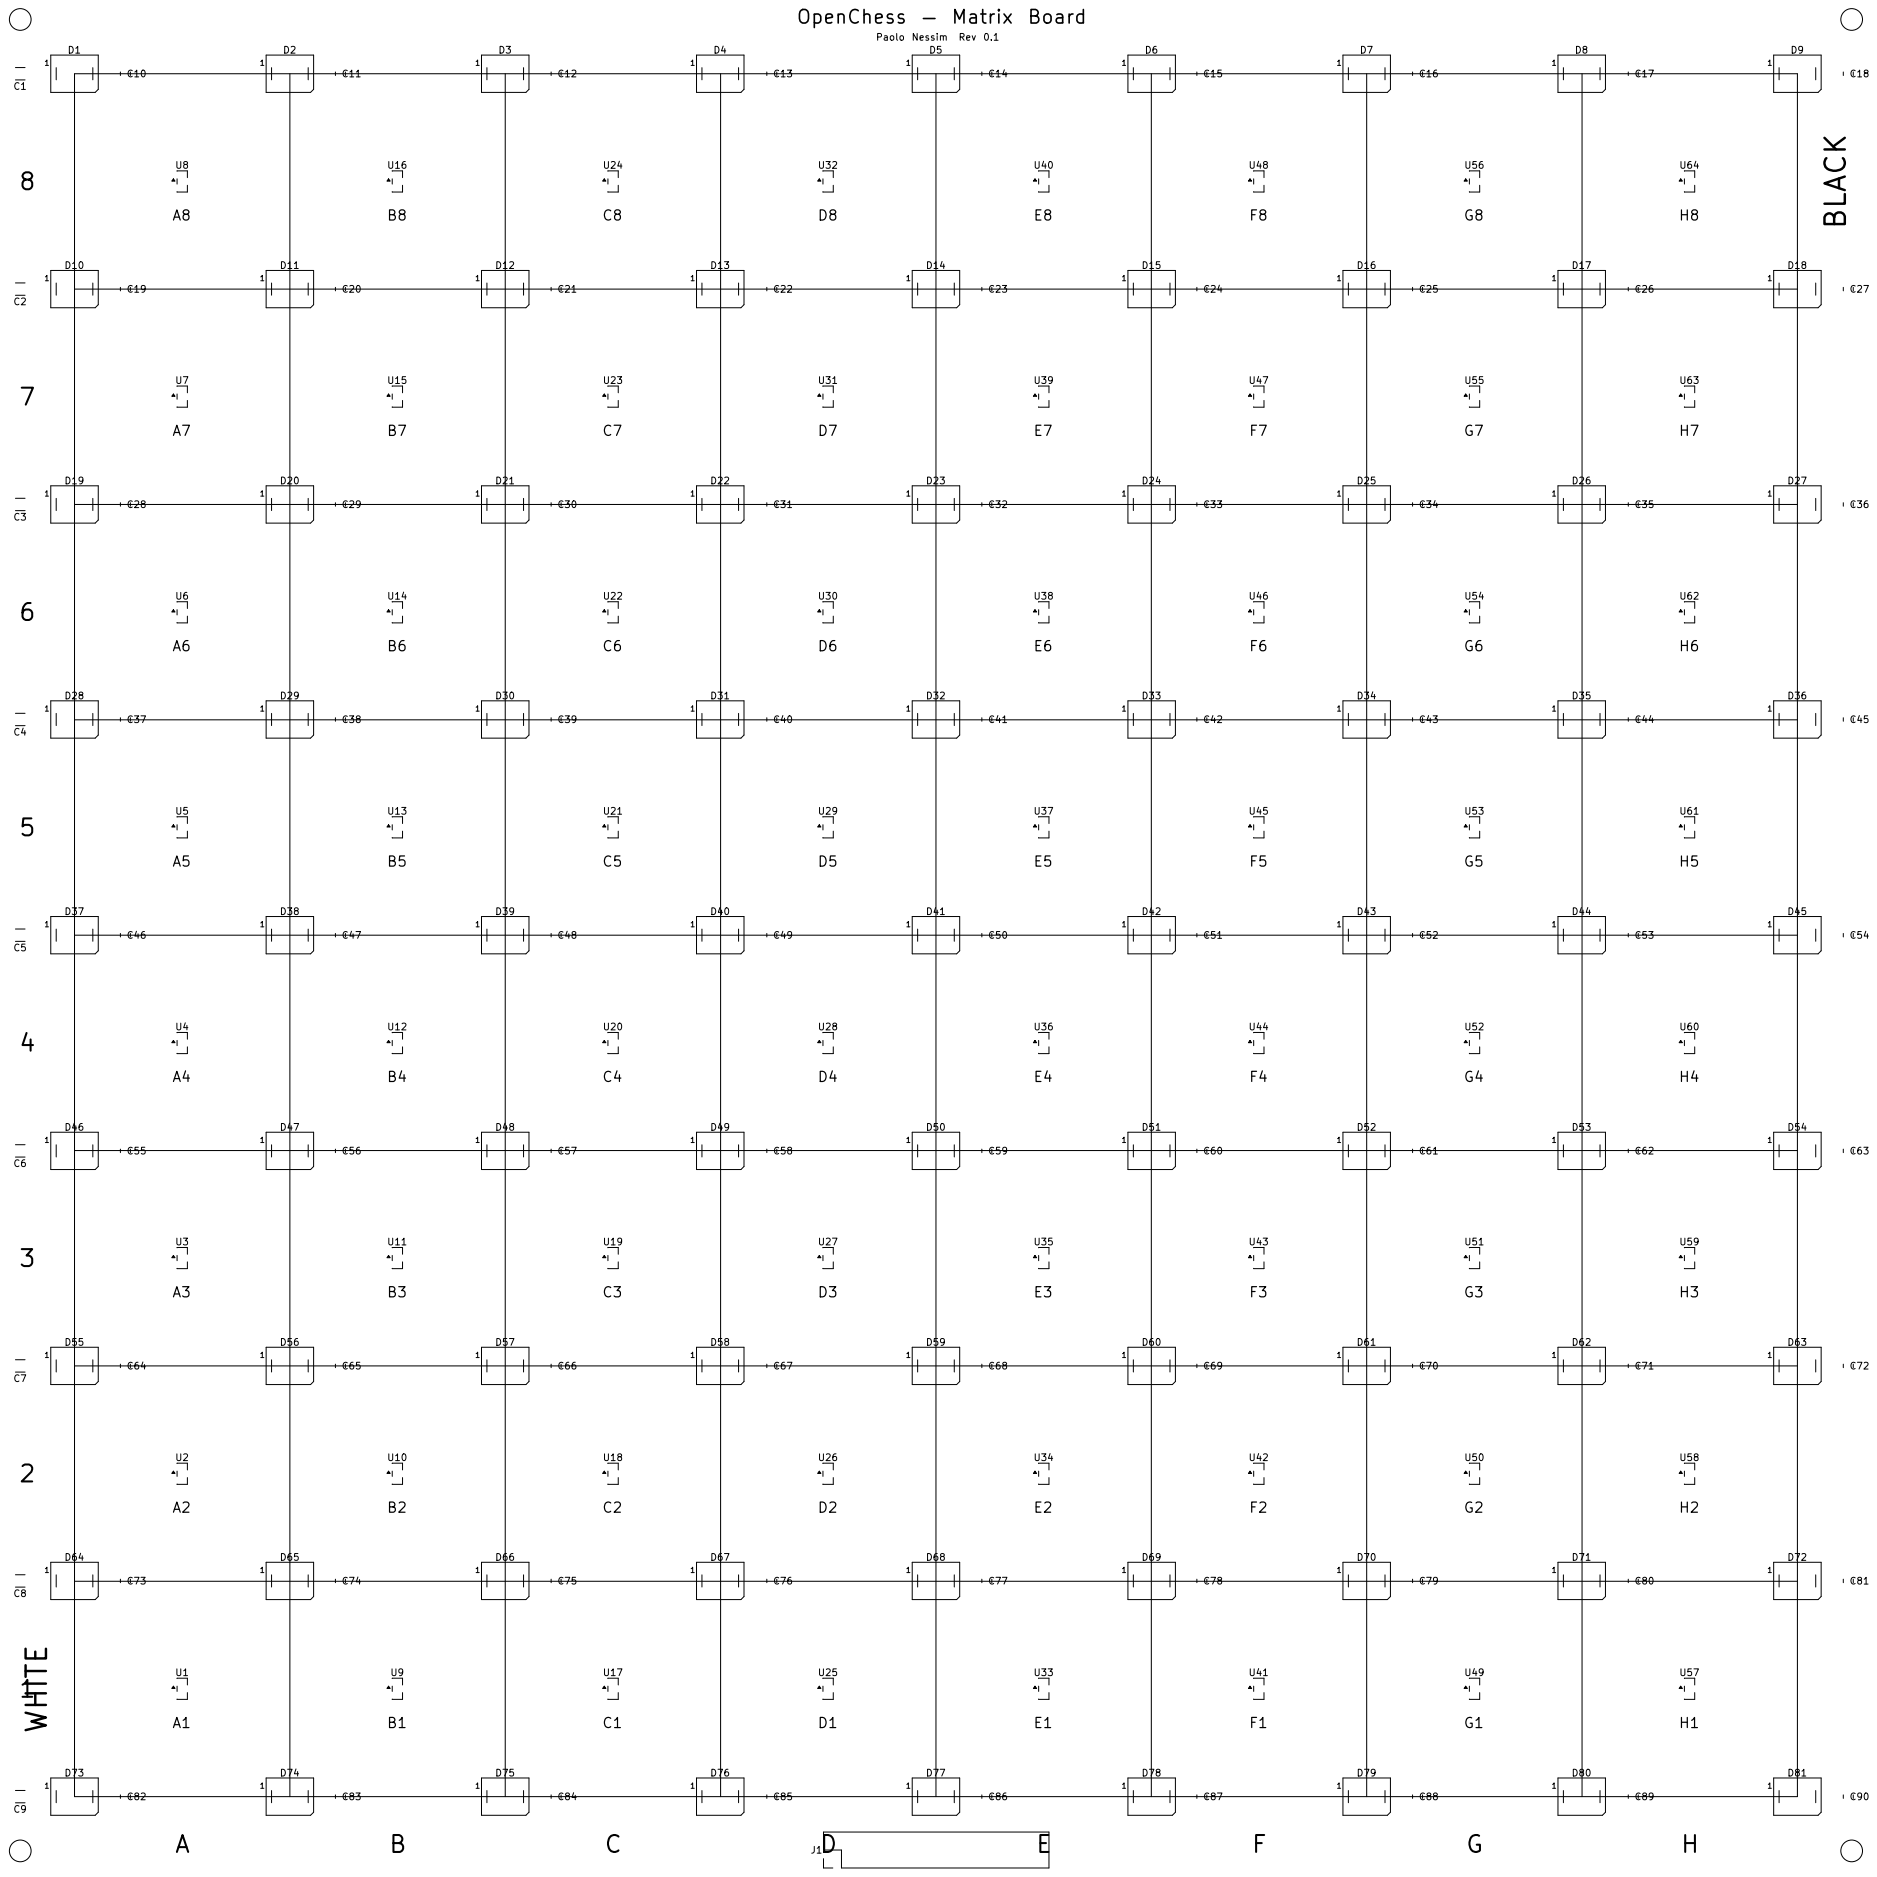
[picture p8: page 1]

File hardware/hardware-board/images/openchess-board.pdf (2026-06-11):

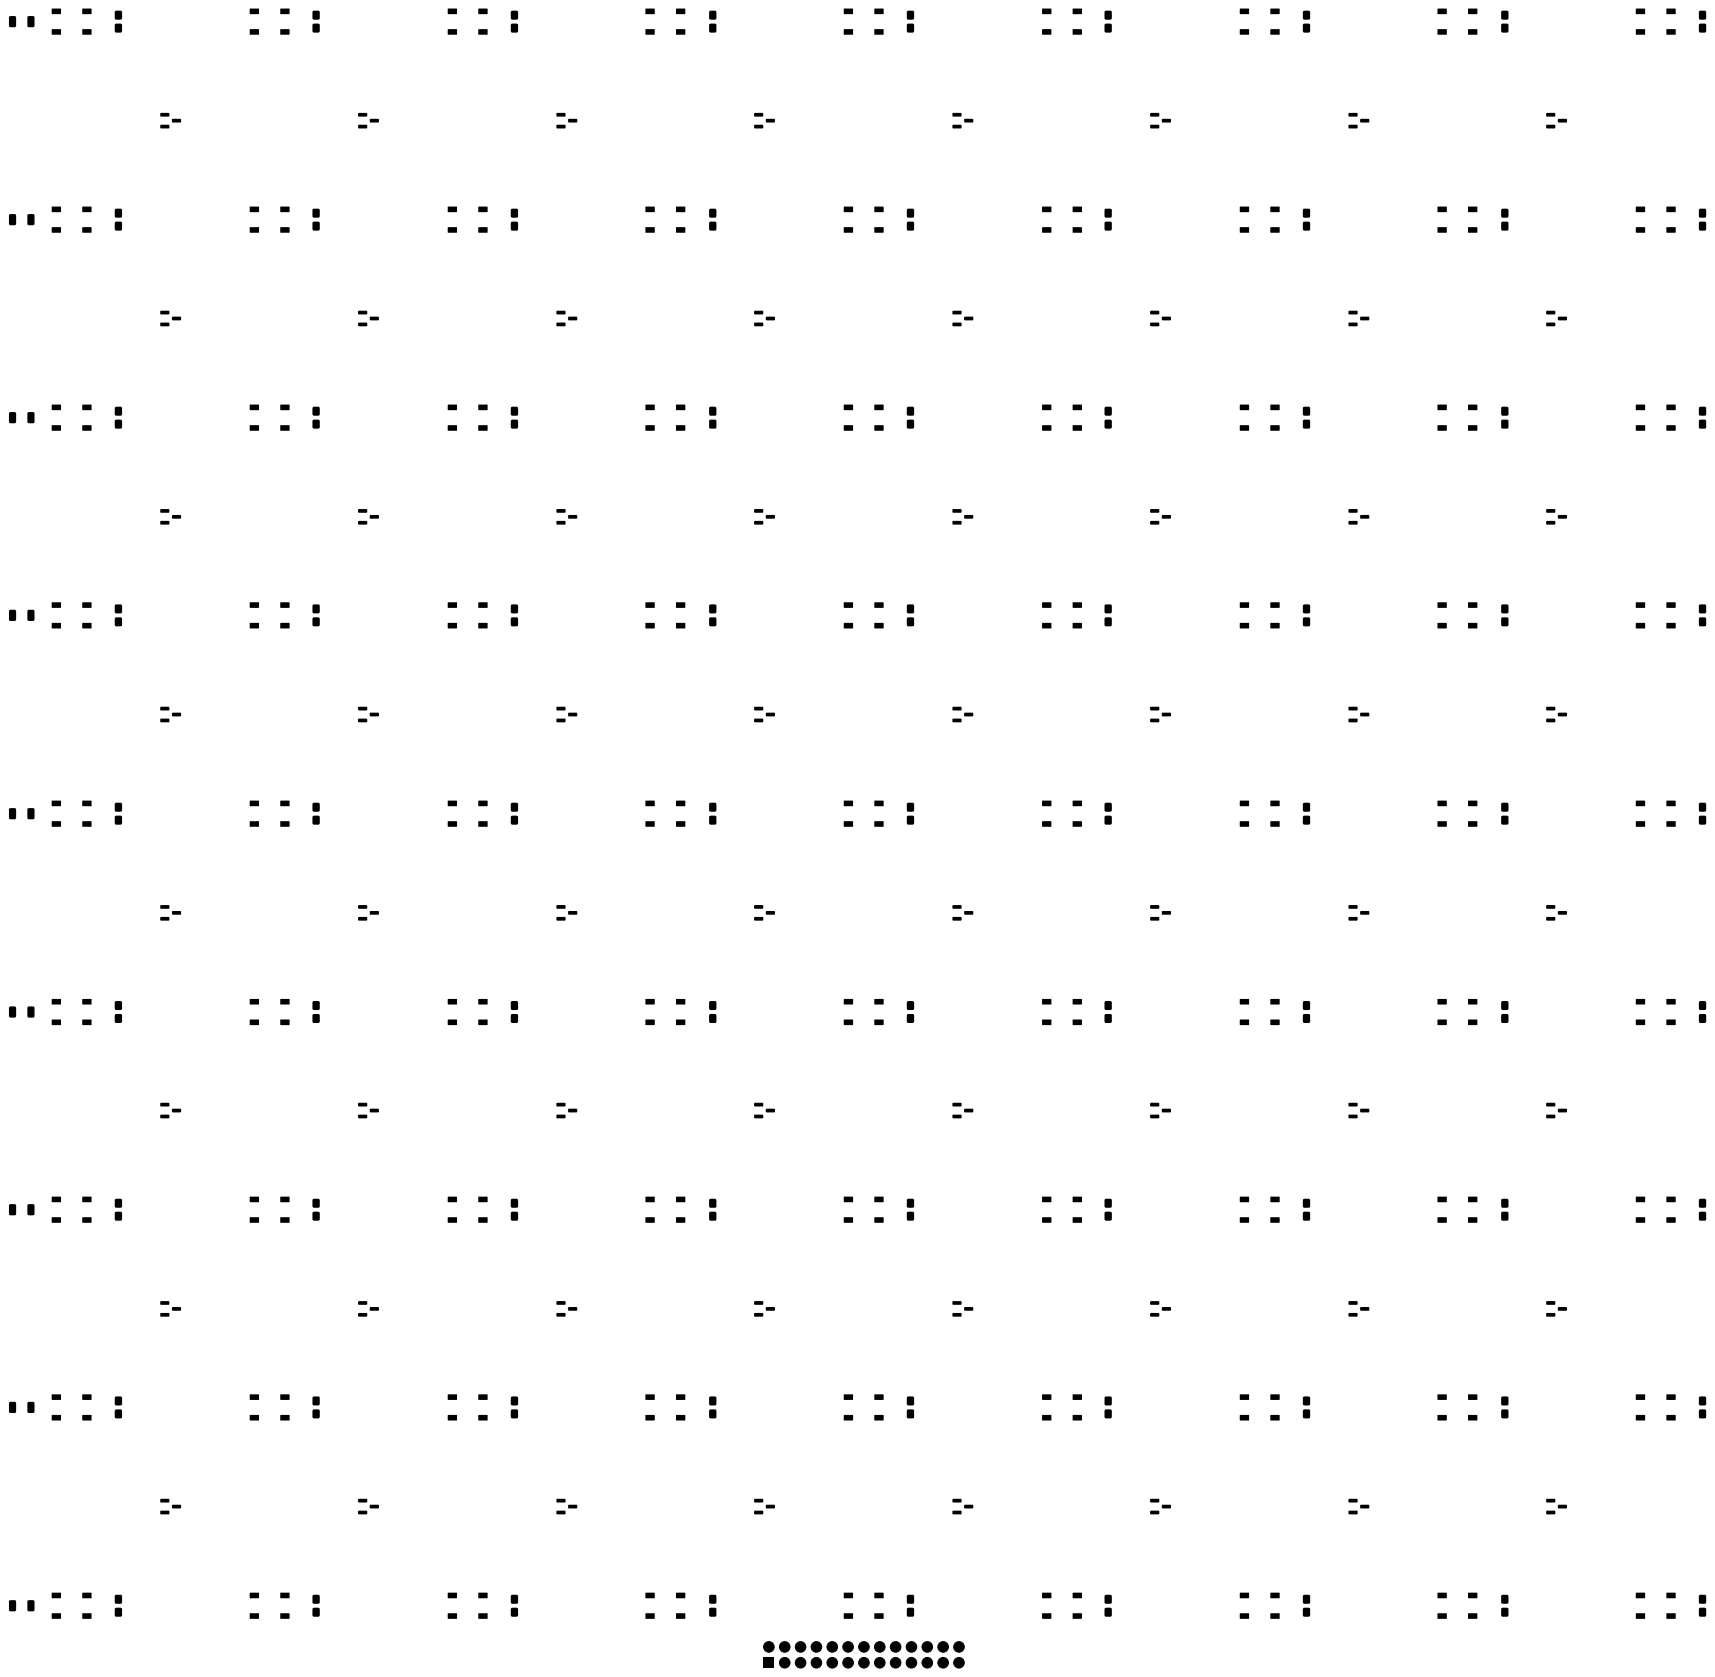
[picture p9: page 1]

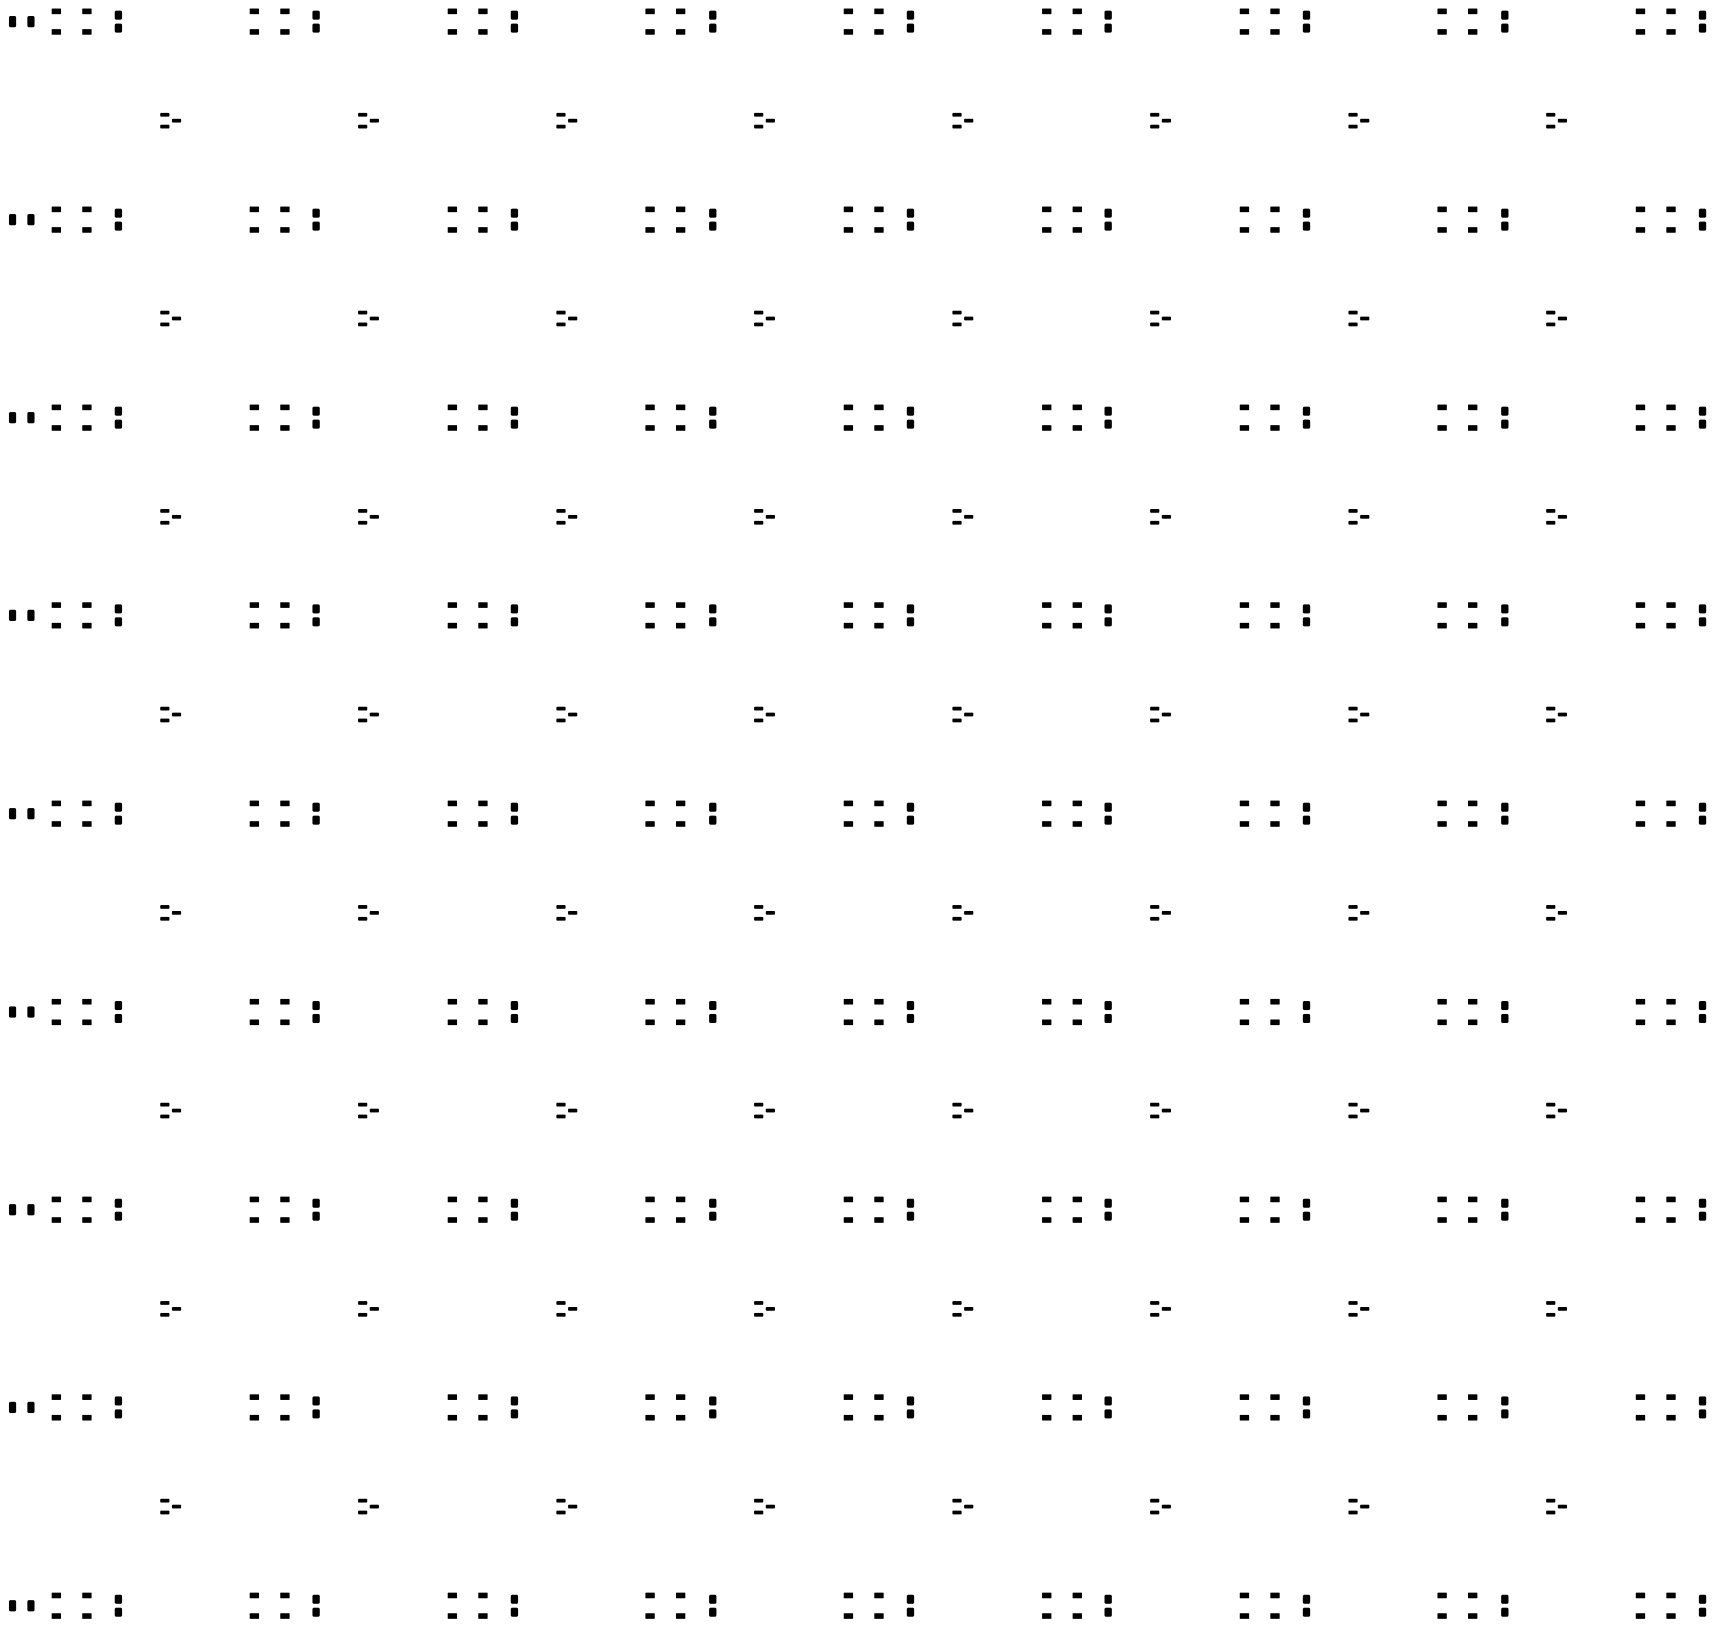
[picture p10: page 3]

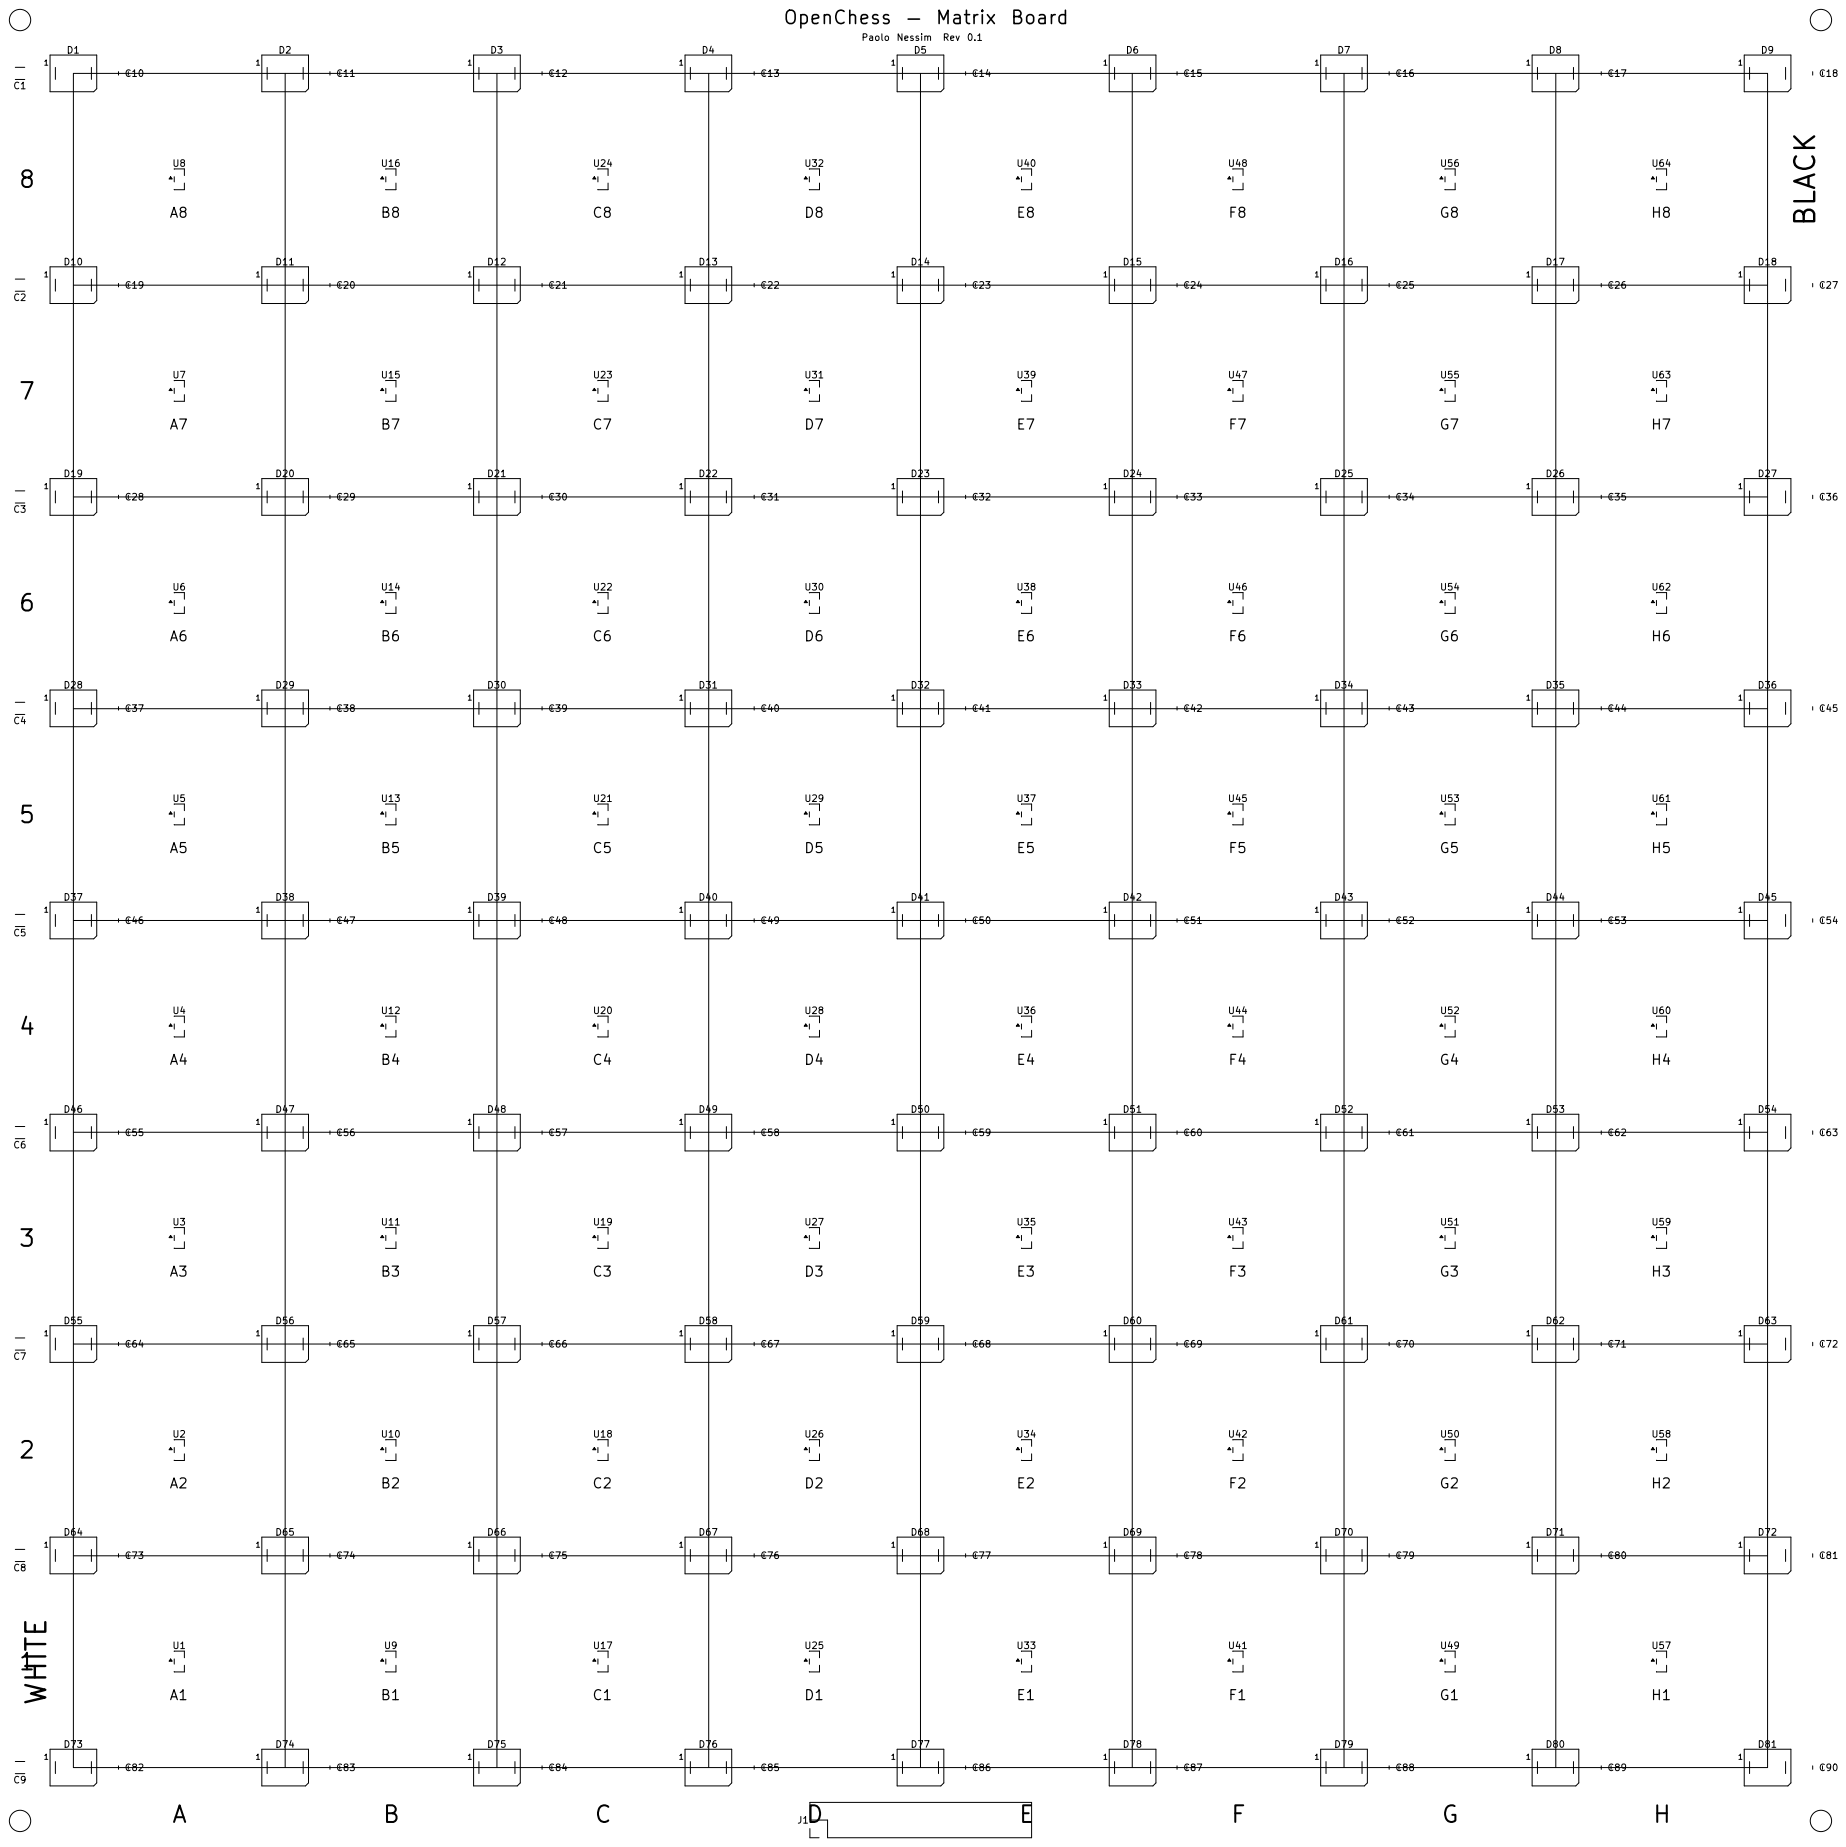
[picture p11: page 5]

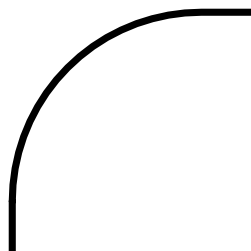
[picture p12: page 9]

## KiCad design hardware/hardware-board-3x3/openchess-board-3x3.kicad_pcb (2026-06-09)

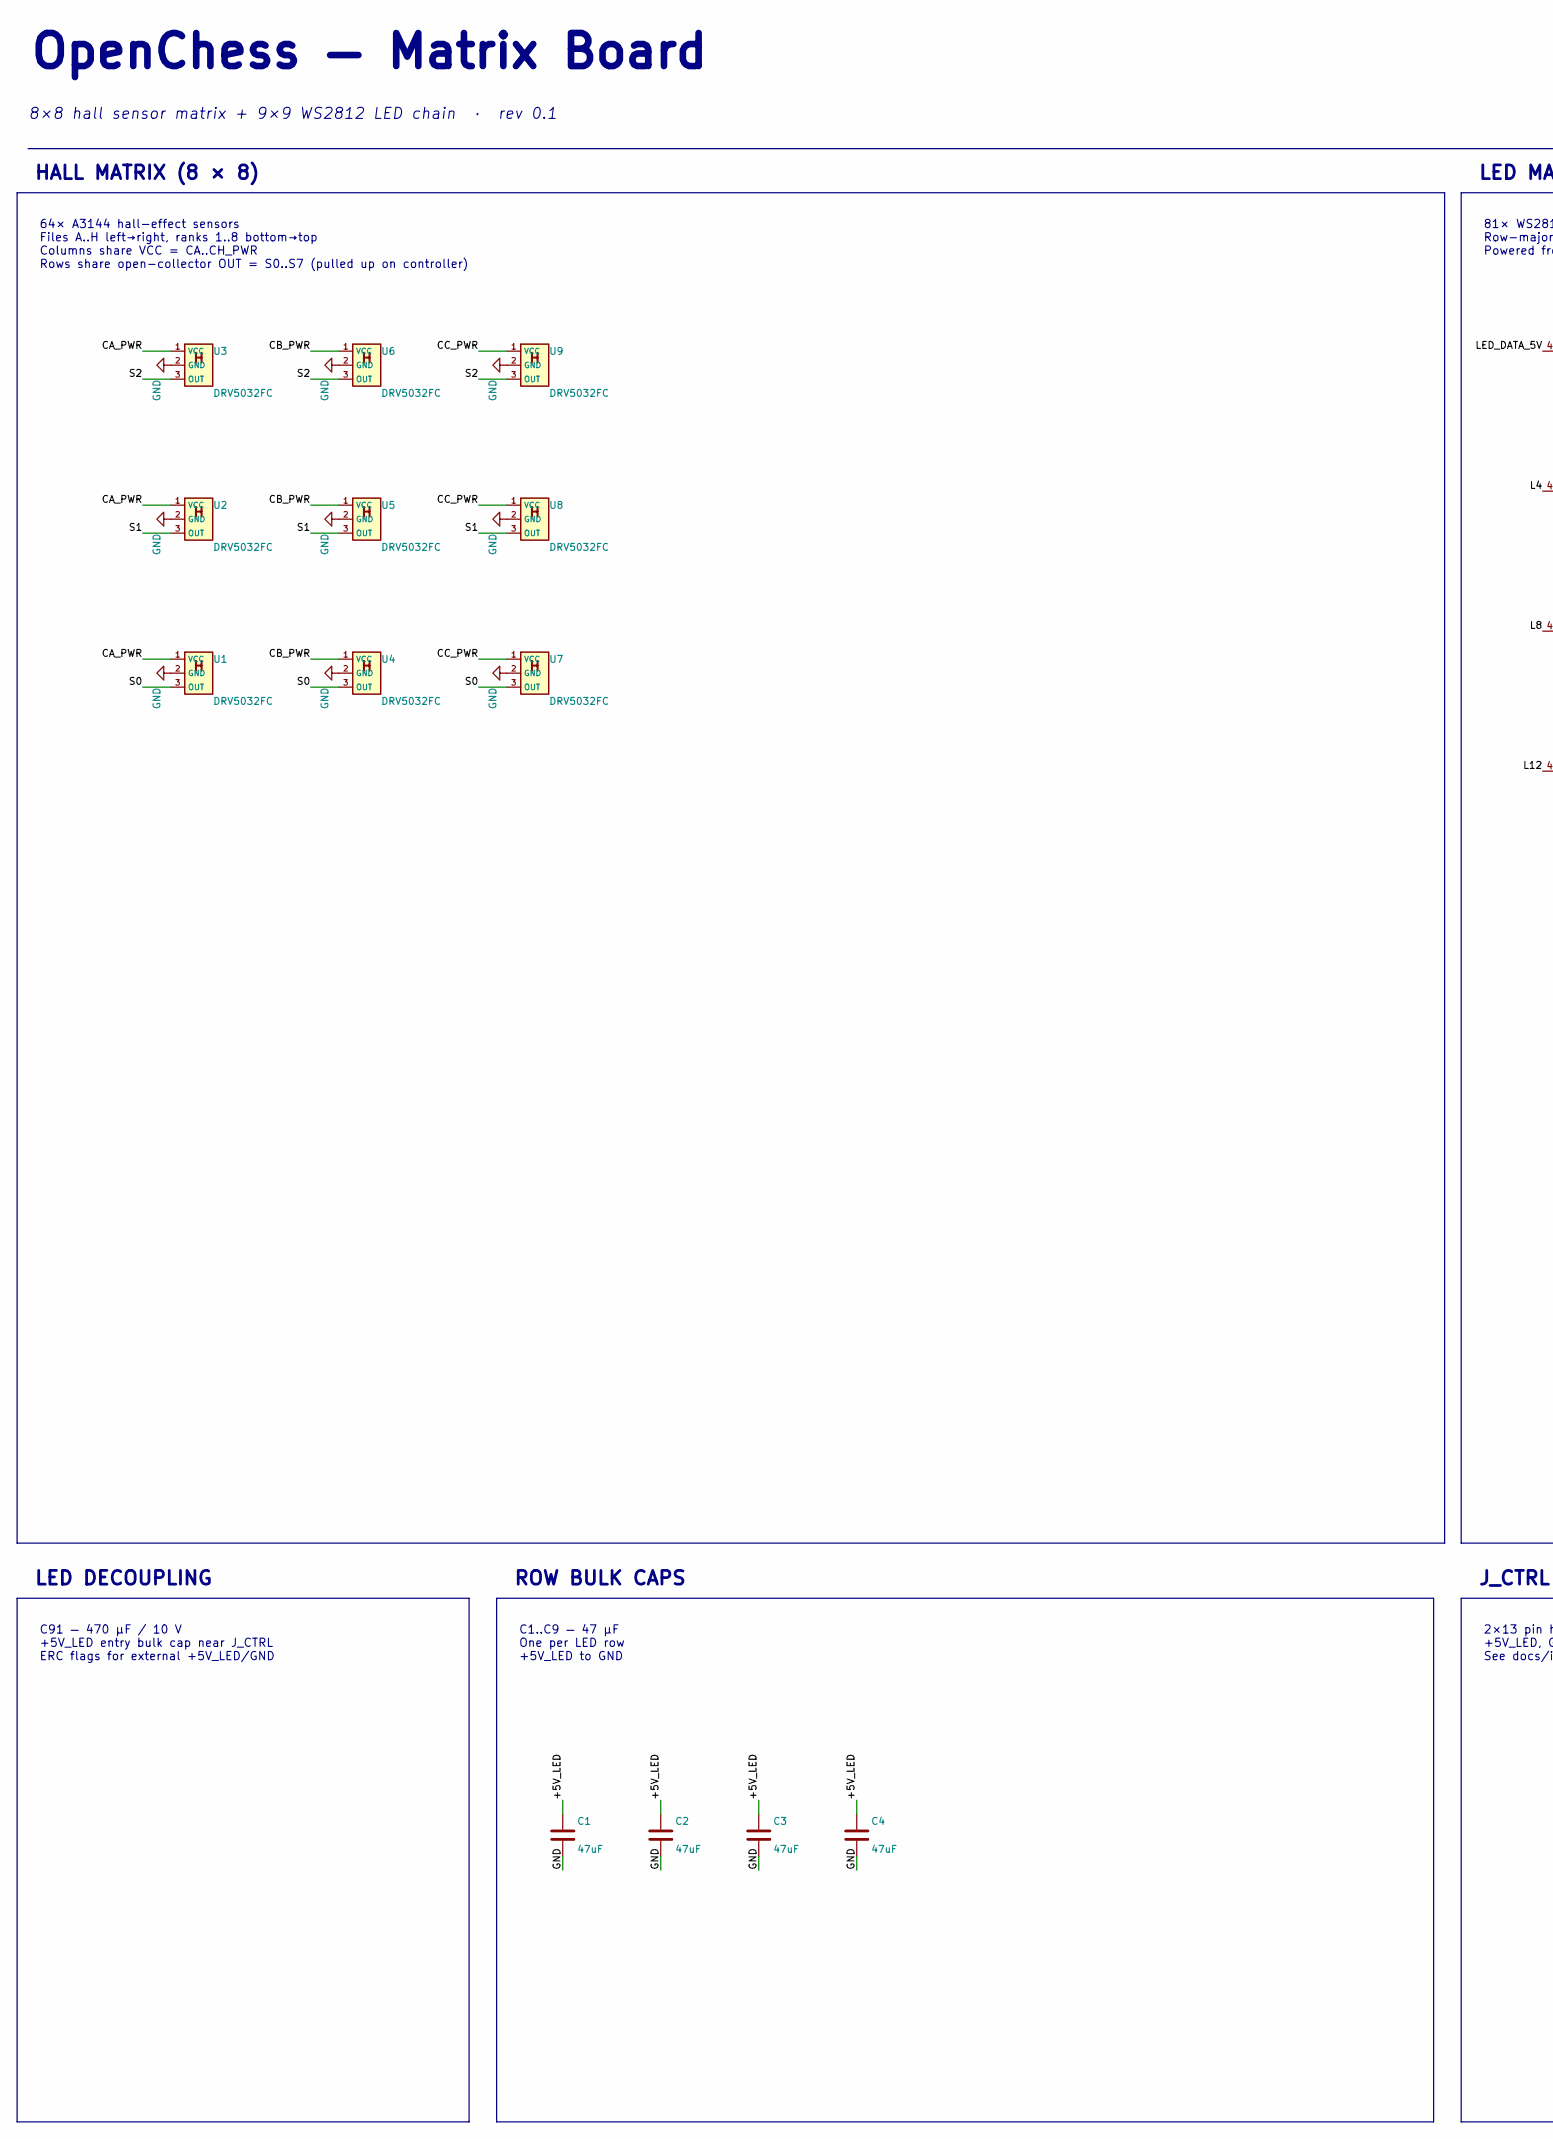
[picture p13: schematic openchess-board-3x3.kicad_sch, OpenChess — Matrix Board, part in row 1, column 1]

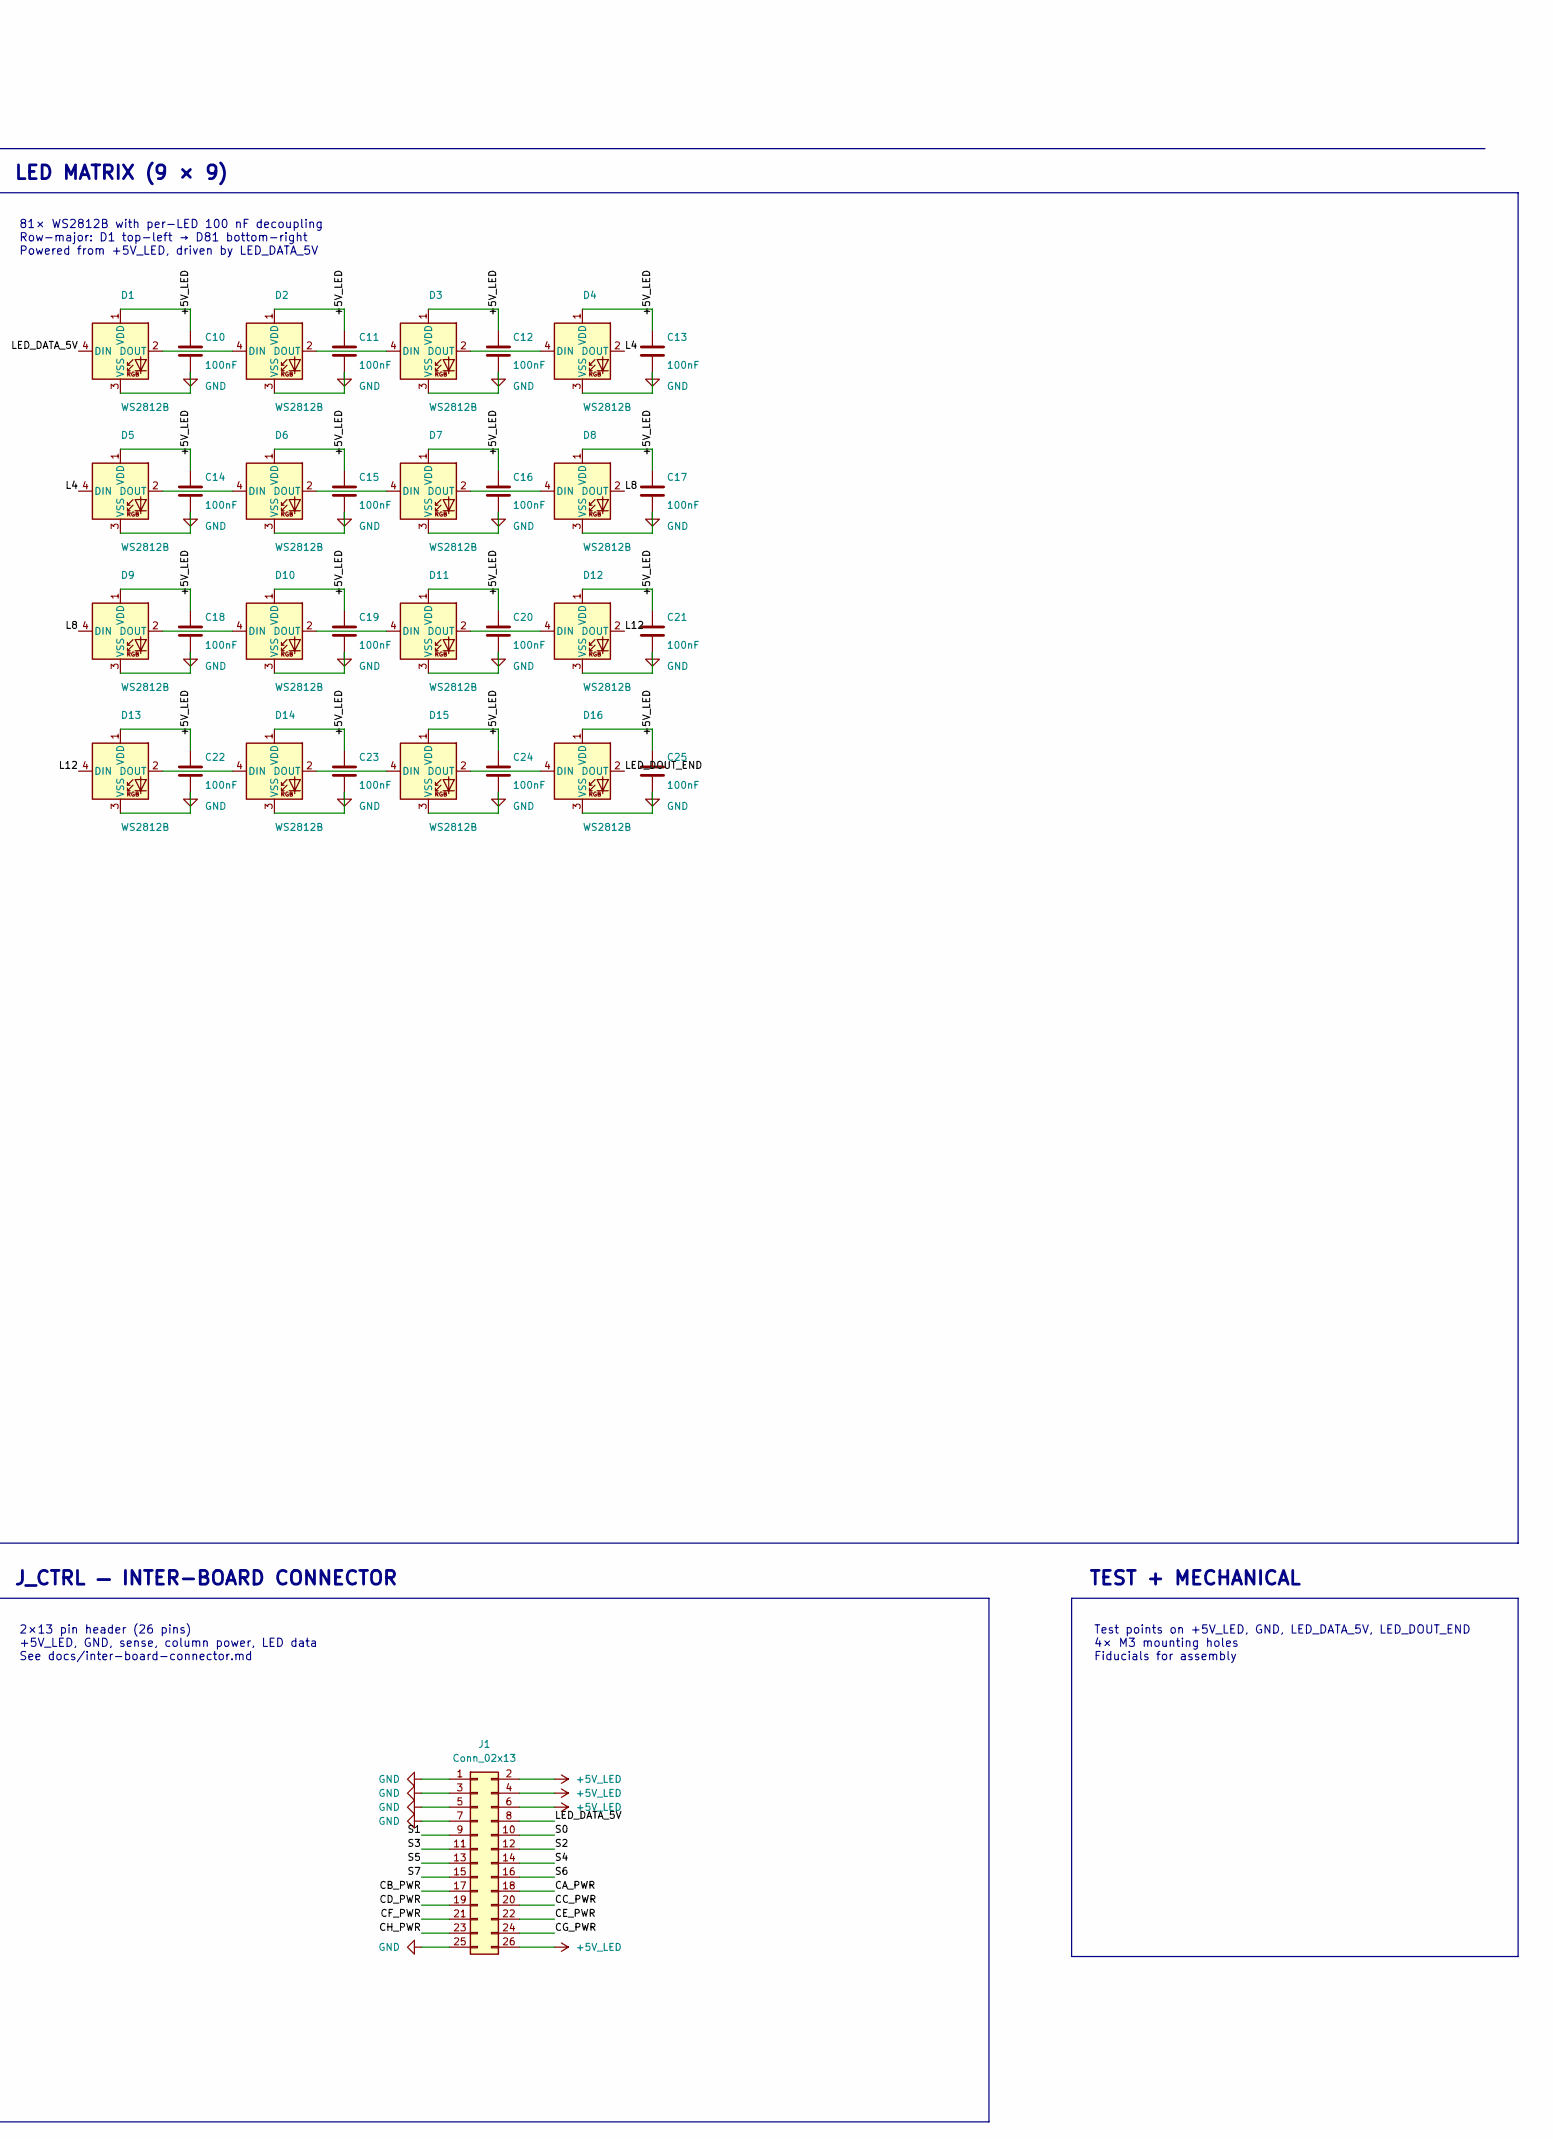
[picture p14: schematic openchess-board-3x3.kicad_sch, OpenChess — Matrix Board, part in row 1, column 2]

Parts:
C1, C2, C3, C4: 47uF; C_1206_3216Metric
C10, C11, C12, C13, C14, C15, C16, C17, C18, C19, C20, C21, C22, C23, C24, C25: 100nF; C_0805_2012Metric_Pad1.18x1.45mm_HandSolder
D1, D2, D3, D4, D5, D6, D7, D8, D9, D10, D11, D12, D13, D14, D15, D16: WS2812B; LED_WS2812B_PLCC4_5.0x5.0mm_P3.2mm
J1: Conn_02x13; PinSocket_2x13_P2.54mm_Vertical
U1, U2, U3, U4, U5, U6, U7, U8, U9: DRV5032FC; SOT-23

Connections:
+5V_LED: C1.1, C2.1, C3.1, C4.1, C10.1, C11.1, C12.1, C13.1, C14.1, C15.1, C16.1, C17.1, C18.1, C19.1, C20.1, C21.1, C22.1, C23.1, C24.1, C25.1, D1.1 (VDD), D2.1 (VDD), D3.1 (VDD), D4.1 (VDD), D5.1 (VDD), D6.1 (VDD), D7.1 (VDD), D8.1 (VDD), D9.1 (VDD), D10.1 (VDD), D11.1 (VDD), D12.1 (VDD), D13.1 (VDD), D14.1 (VDD), D15.1 (VDD), D16.1 (VDD), J1.2, J1.4, J1.6, J1.26
/CA_PWR: J1.18, U1.1 (VCC), U2.1 (VCC), U3.1 (VCC)
/CB_PWR: J1.17, U4.1 (VCC), U5.1 (VCC), U6.1 (VCC)
/CC_PWR: J1.20, U7.1 (VCC), U8.1 (VCC), U9.1 (VCC)
/CD_PWR: J1.19
/CE_PWR: J1.22
/CF_PWR: J1.21
/CG_PWR: J1.24
/CH_PWR: J1.23
/L4: D4.2 (DOUT), D5.4 (DIN)
/L8: D8.2 (DOUT), D9.4 (DIN)
/L12: D12.2 (DOUT), D13.4 (DIN)
/LED_DATA_5V: D1.4 (DIN), J1.8
/LED_DOUT_END: D16.2 (DOUT)
/S0: J1.10, U1.3 (OUT), U4.3 (OUT), U7.3 (OUT)
/S1: J1.9, U2.3 (OUT), U5.3 (OUT), U8.3 (OUT)
/S2: J1.12, U3.3 (OUT), U6.3 (OUT), U9.3 (OUT)
/S3: J1.11
/S4: J1.14
/S5: J1.13
/S6: J1.16
/S7: J1.15
GND: C1.2, C2.2, C3.2, C4.2, C10.2, C11.2, C12.2, C13.2, C14.2, C15.2, C16.2, C17.2, C18.2, C19.2, C20.2, C21.2, C22.2, C23.2, C24.2, C25.2, D1.3 (VSS), D2.3 (VSS), D3.3 (VSS), D4.3 (VSS), D5.3 (VSS), D6.3 (VSS), D7.3 (VSS), D8.3 (VSS), D9.3 (VSS), D10.3 (VSS), D11.3 (VSS), D12.3 (VSS), D13.3 (VSS), D14.3 (VSS), D15.3 (VSS), D16.3 (VSS), J1.1, J1.3, J1.5, J1.7, J1.25, U1.2 (GND), U2.2 (GND), U3.2 (GND), U4.2 (GND), U5.2 (GND), U6.2 (GND), U7.2 (GND), U8.2 (GND), U9.2 (GND)
unnamed: D1.2 (DOUT), D2.4 (DIN)
unnamed: D2.2 (DOUT), D3.4 (DIN)
unnamed: D3.2 (DOUT), D4.4 (DIN)
unnamed: D5.2 (DOUT), D6.4 (DIN)
unnamed: D6.2 (DOUT), D7.4 (DIN)
unnamed: D7.2 (DOUT), D8.4 (DIN)
unnamed: D9.2 (DOUT), D10.4 (DIN)
unnamed: D10.2 (DOUT), D11.4 (DIN)
unnamed: D11.2 (DOUT), D12.4 (DIN)
unnamed: D13.2 (DOUT), D14.4 (DIN)
unnamed: D14.2 (DOUT), D15.4 (DIN)
unnamed: D15.2 (DOUT), D16.4 (DIN)

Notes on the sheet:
C91 — 470 µF / 10 V +5V_LED entry bulk cap near J_CTRL ERC flags for external +5V_LED/GND
C1..C9 — 47 µF One per LED row +5V_LED to GND
2×13 pin header (26 pins) +5V_LED, GND, sense, column power, LED data See docs/inter-board-connector.md
ROW BULK CAPS
J_CTRL — INTER-BOARD CONNECTOR
LED DECOUPLING
OpenChess — Matrix Board
8×8 hall sensor matrix + 9×9 WS2812 LED chain · rev 0.1
HALL MATRIX (8 × 8)
64× A3144 hall-effect sensors Files A..H left→right, ranks 1..8 bottom→top Columns share VCC = CA..CH_PWR Rows share open-collector OUT = S0..S7 (pulled up on controller)
LED MATRIX (9 × 9)
81× WS2812B with per-LED 100 nF decoupling Row-major: D1 top-left → D81 bottom-right Powered from +5V_LED, driven by LED_DATA_5V
TEST + MECHANICAL
Test points on +5V_LED, GND, LED_DATA_5V, LED_DOUT_END 4× M3 mounting holes Fiducials for assembly

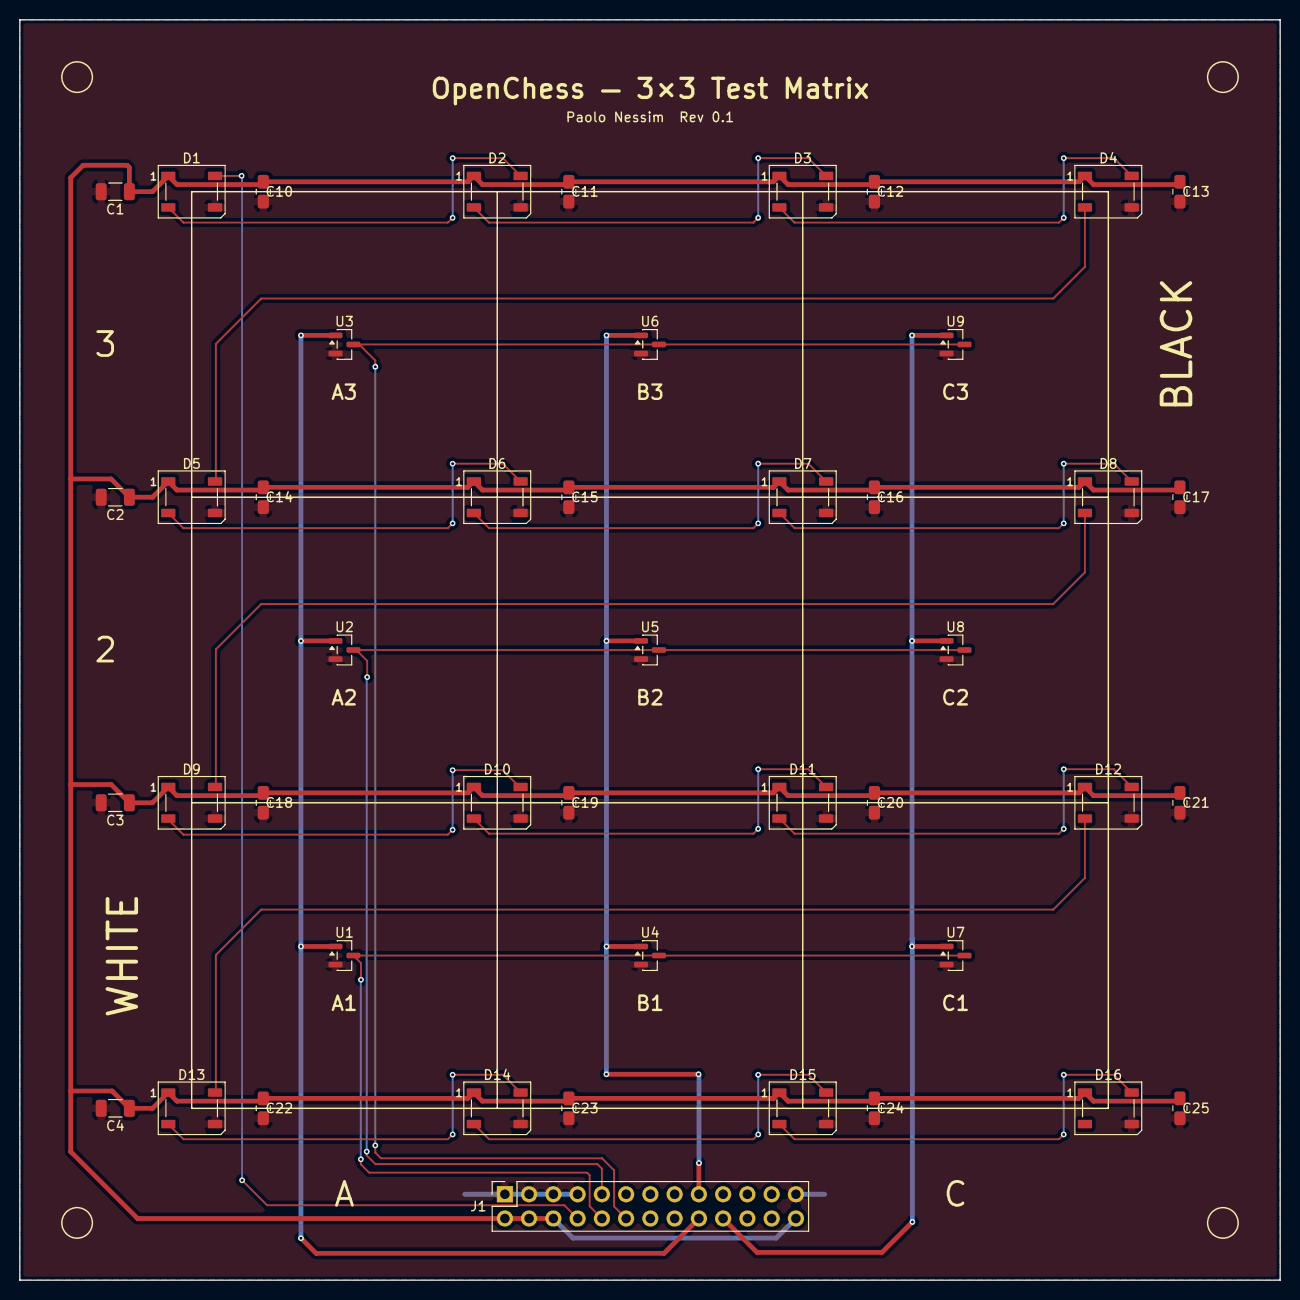
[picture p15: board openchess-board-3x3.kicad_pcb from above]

Board: 2 copper layers, 132.0 x 132.0 mm, 46 parts (1 on the bottom side), 24 nets.

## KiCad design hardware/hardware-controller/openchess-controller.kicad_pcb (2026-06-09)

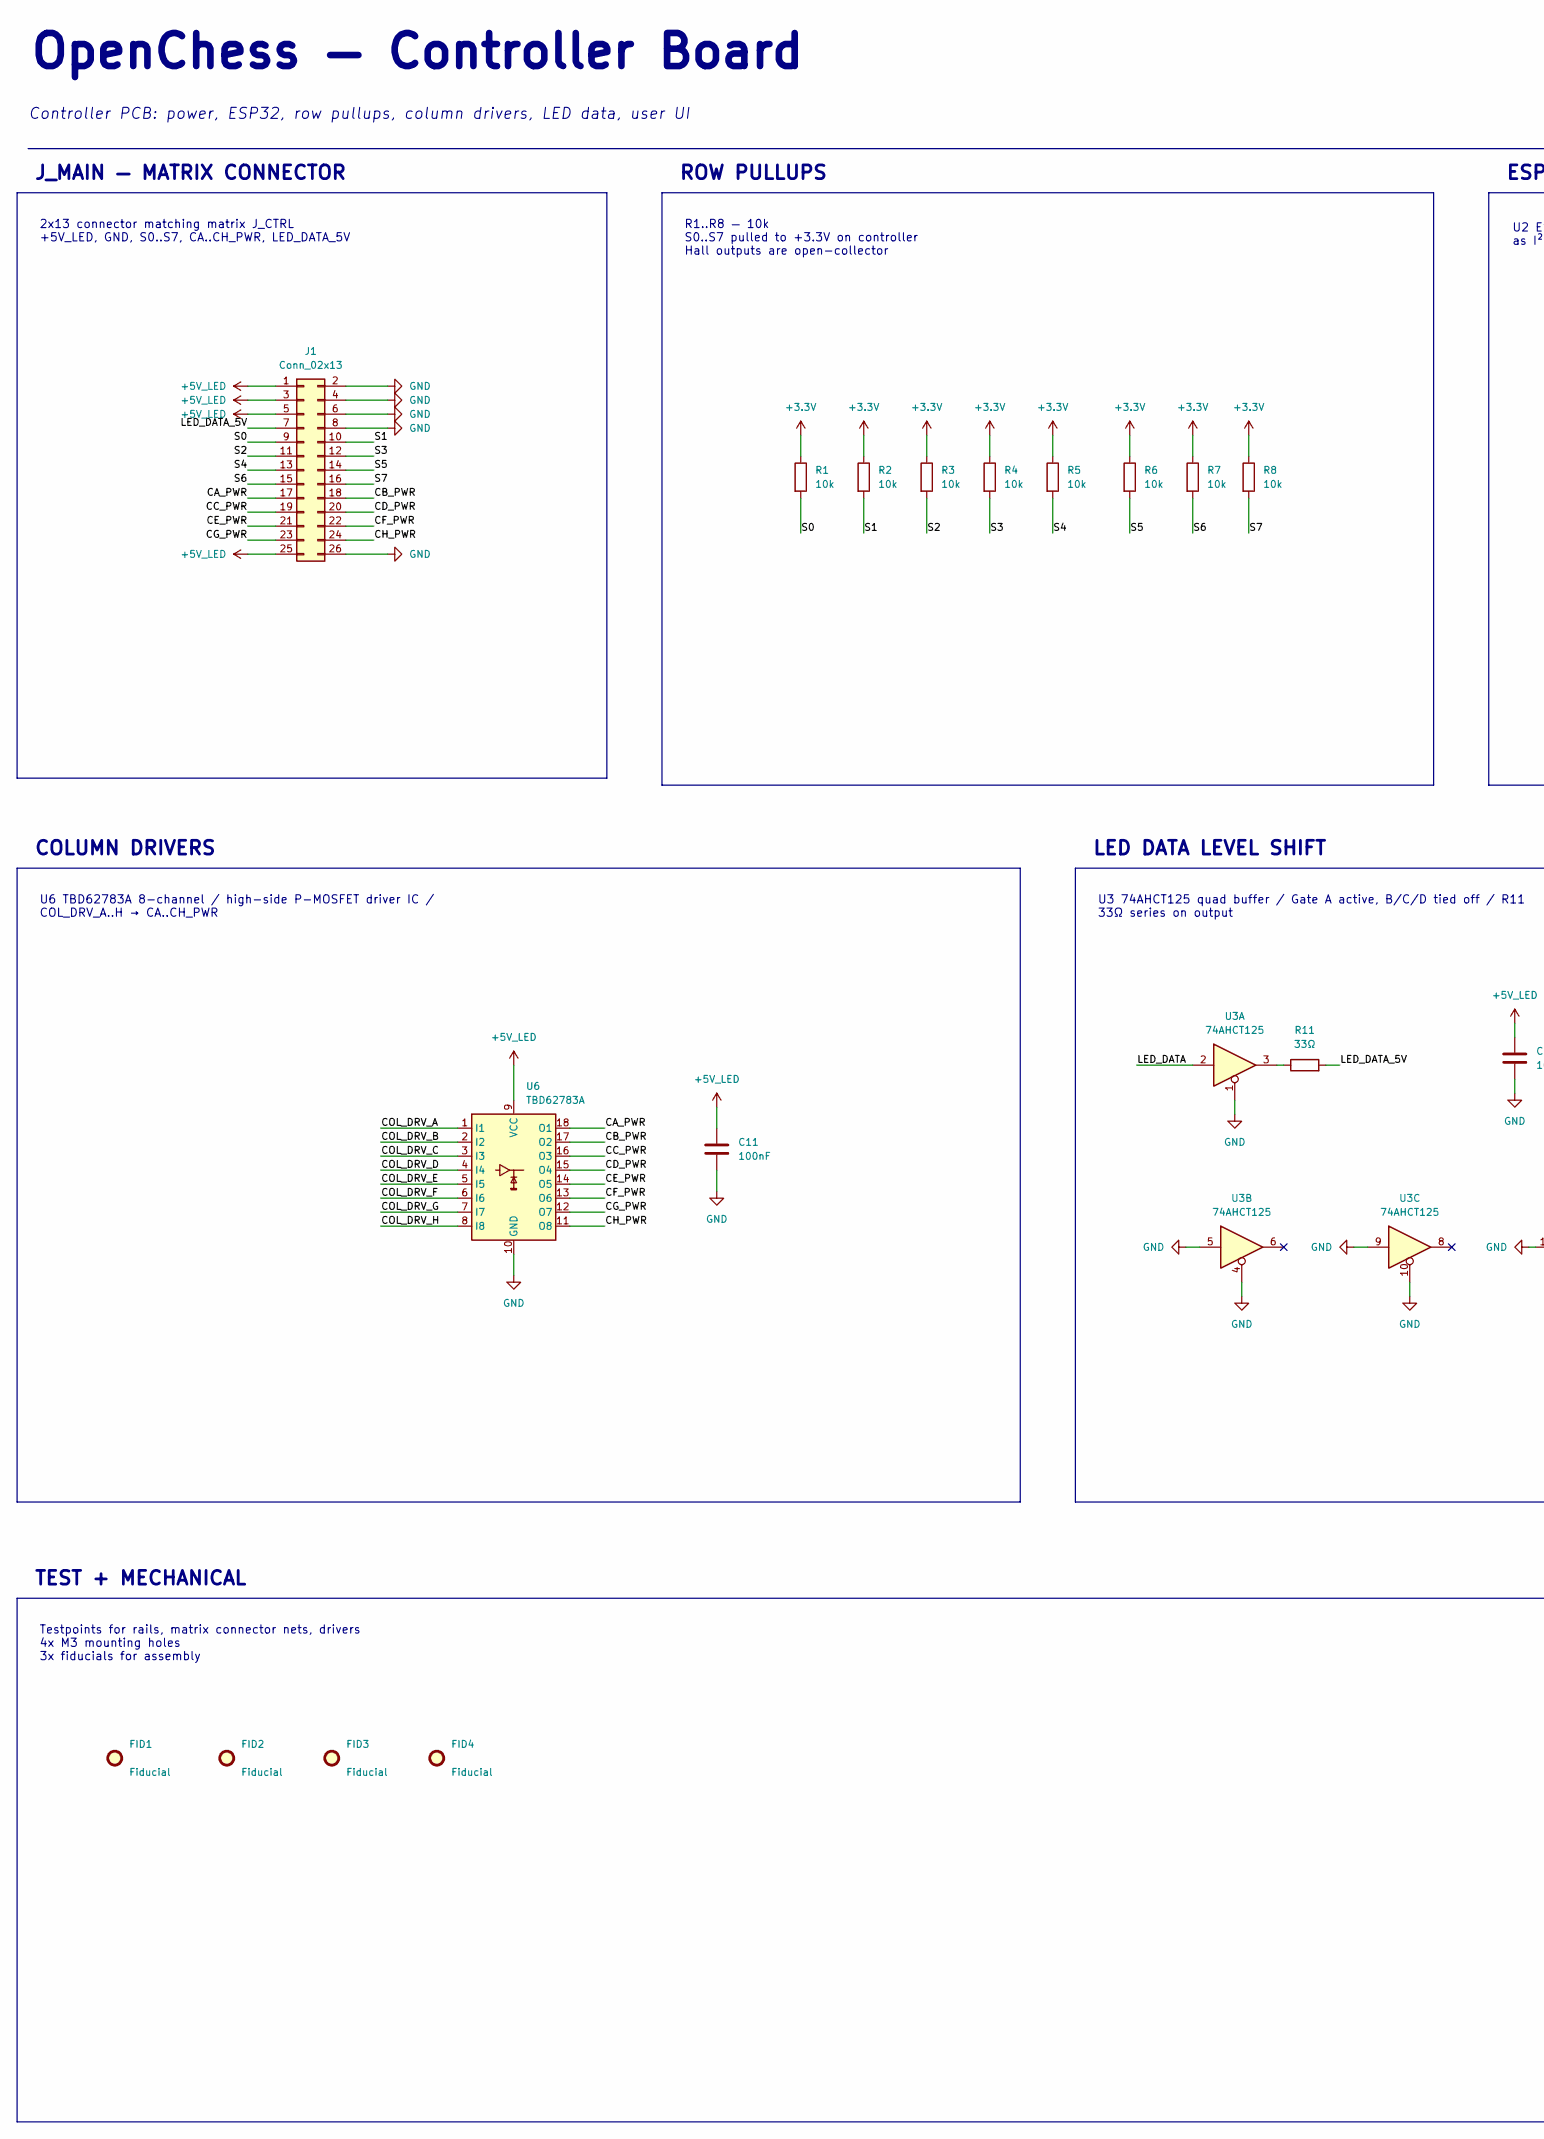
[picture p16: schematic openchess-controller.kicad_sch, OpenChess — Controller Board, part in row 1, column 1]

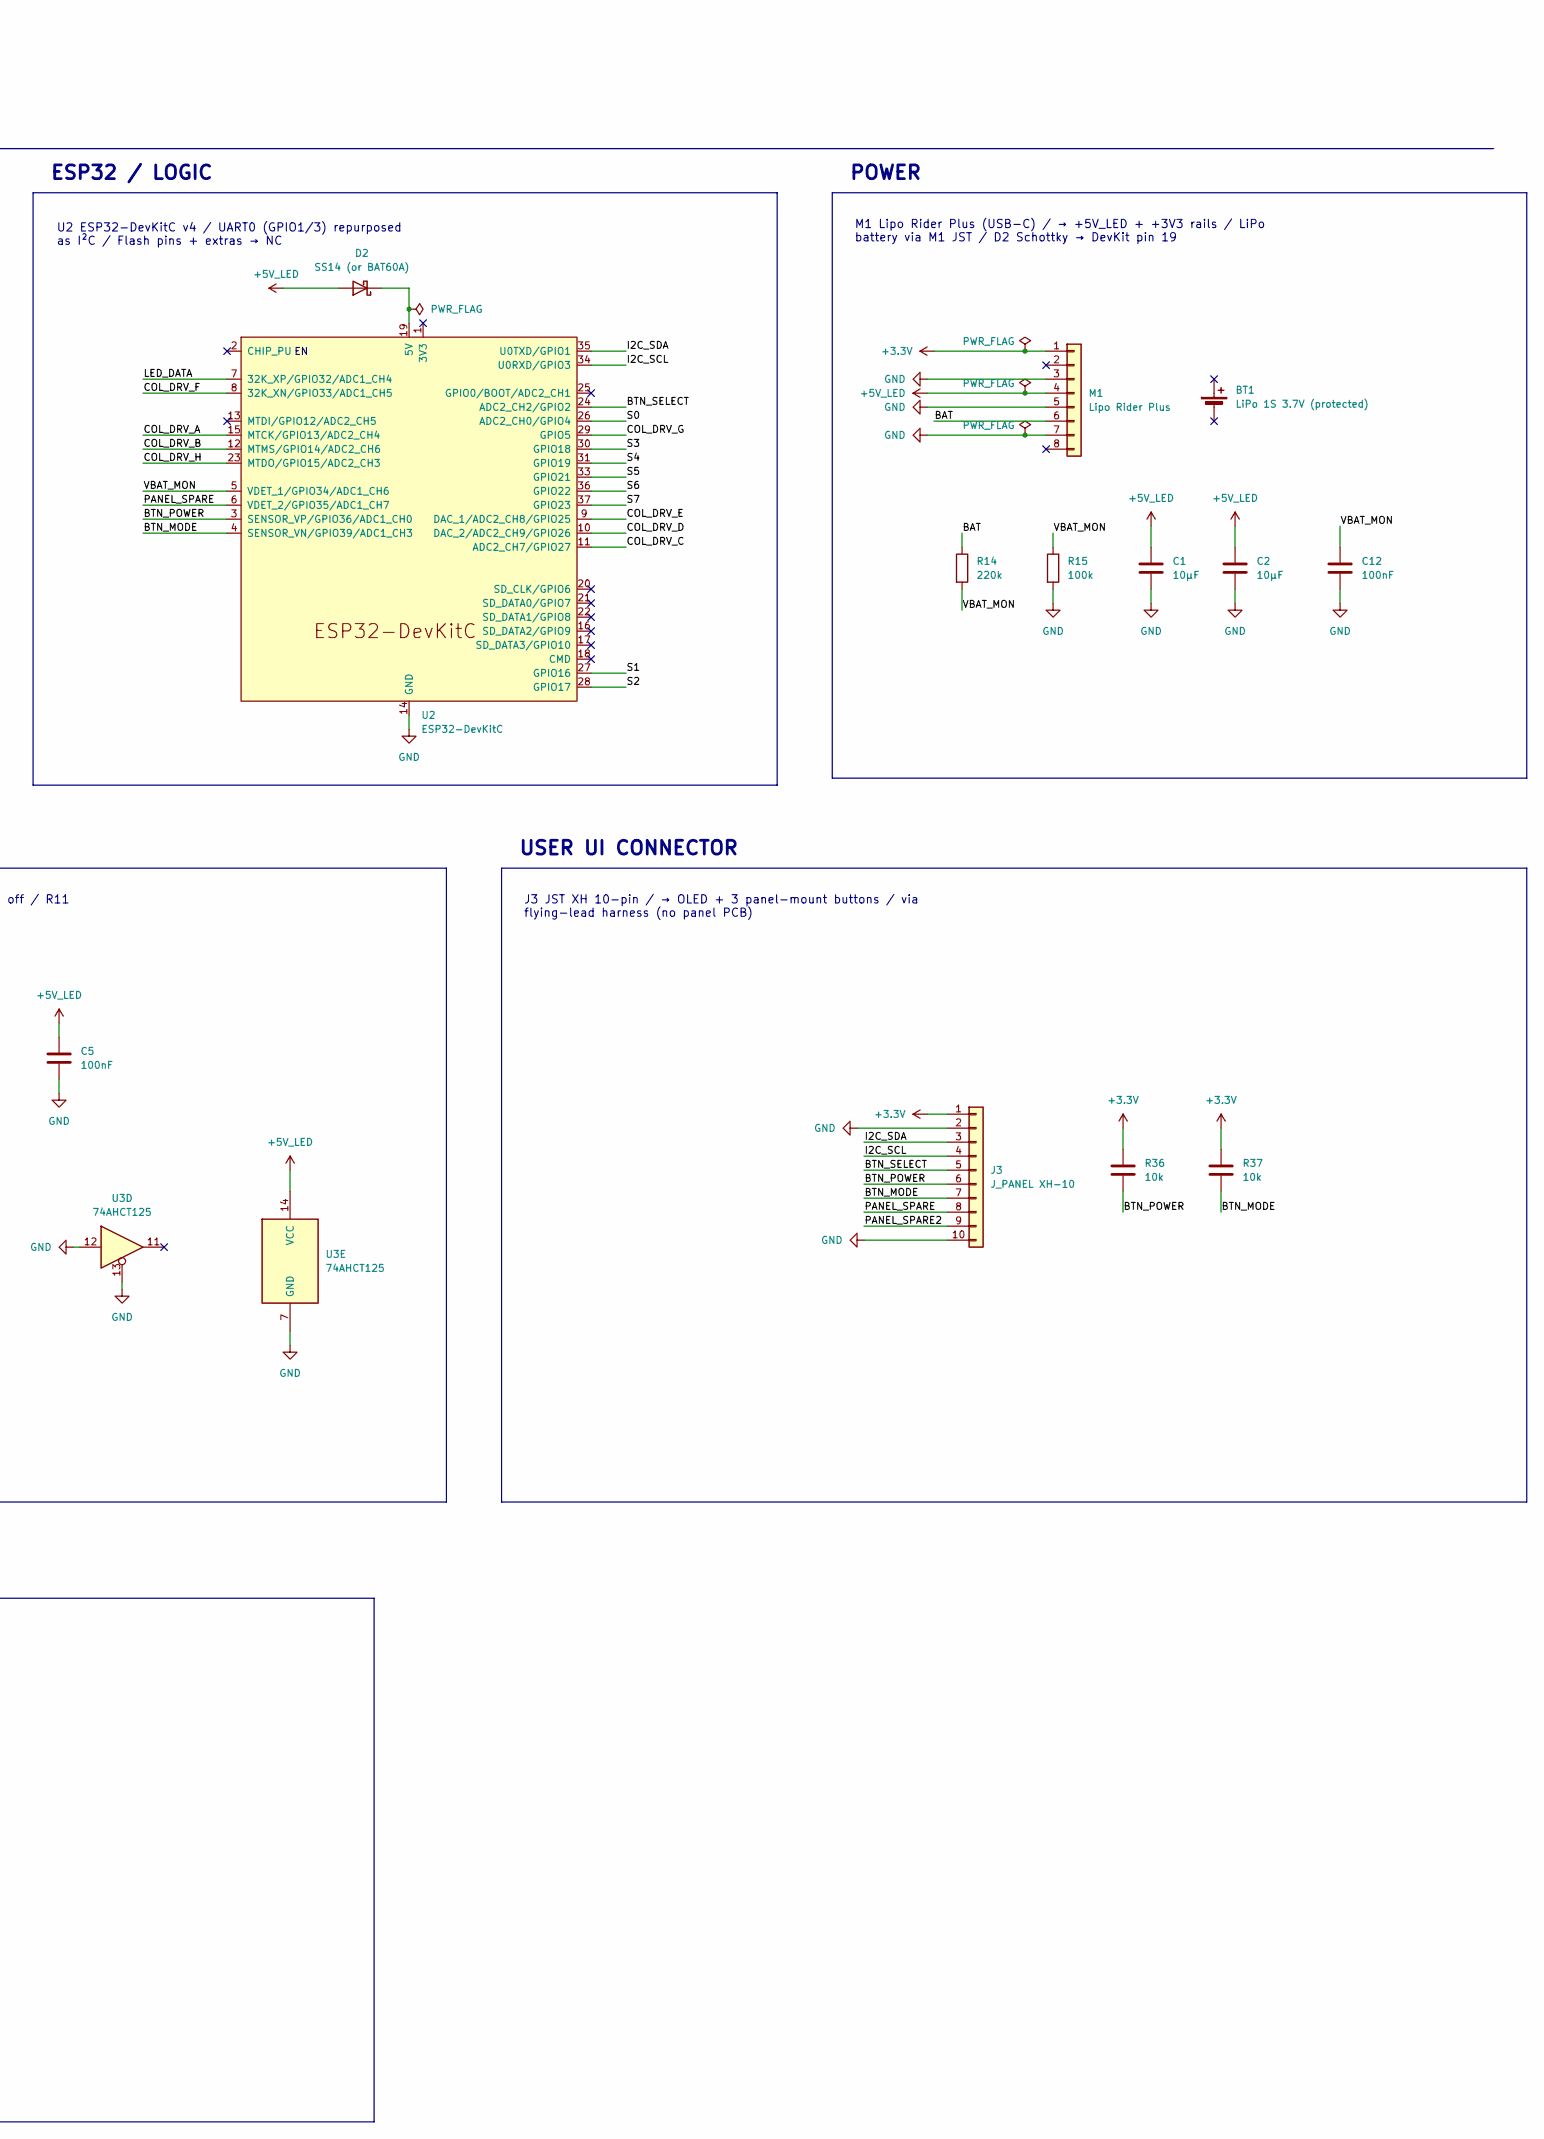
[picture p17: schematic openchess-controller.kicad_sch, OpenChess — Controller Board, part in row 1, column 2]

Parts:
BT1: LiPo 1S 3.7V (protected)
C1, C2: 10µF; C_0805_2012Metric
C5: 100nF; C_0805_2012Metric
C11, C12: 100nF; C_0603_1608Metric
D2: SS14 (or BAT60A); D_SMA
FID1, FID2, FID3, FID4: Fiducial; Fiducial_1mm_Mask2mm
J1: Conn_02x13; PinHeader_2x13_P2.54mm_Vertical
J3: J_PANEL XH-10; PinHeader_1x10_P2.54mm_Vertical
M1: Lipo Rider Plus; PinSocket_1x08_P2.54mm_Vertical
R1, R2, R3, R4, R5, R6, R7, R8: 10k; R_0805_2012Metric
R11: 33Ω; R_0603_1608Metric
R14: 220k; R_0603_1608Metric
R15: 100k; R_0603_1608Metric
R36, R37: 10k; R_0603_1608Metric
U2: ESP32-DevKitC
U3: 74AHCT125; SOIC-14_3.9x8.7mm_P1.27mm
U6: TBD62783A; DIP-18_W7.62mm

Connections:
+3.3V: J3.1, M1.1, R1.1, R2.1, R3.1, R4.1, R5.1, R6.1, R7.1, R8.1, R36.1, R37.1
+5V_LED: C1.1, C2.1, C5.1, C11.1, D2.2 (A), J1.1, J1.3, J1.5, J1.25, M1.4, U3.14 (VCC), U6.9 (VCC)
/BAT: M1.6, R14.1
/BTN_MODE: J3.7, R37.2, U2.4 (SENSOR_VN/GPIO39/ADC1_CH3)
/BTN_POWER: J3.6, R36.2, U2.3 (SENSOR_VP/GPIO36/ADC1_CH0)
/BTN_SELECT: J3.5, U2.24 (ADC2_CH2/GPIO2)
/CA_PWR: J1.17, U6.18 (O1)
/CB_PWR: J1.18, U6.17 (O2)
/CC_PWR: J1.19, U6.16 (O3)
/CD_PWR: J1.20, U6.15 (O4)
/CE_PWR: J1.21, U6.14 (O5)
/CF_PWR: J1.22, U6.13 (O6)
/CG_PWR: J1.23, U6.12 (O7)
/CH_PWR: J1.24, U6.11 (O8)
/COL_DRV_A: U2.15 (MTCK/GPIO13/ADC2_CH4), U6.1 (I1)
/COL_DRV_B: U2.12 (MTMS/GPIO14/ADC2_CH6), U6.2 (I2)
/COL_DRV_C: U2.11 (ADC2_CH7/GPIO27), U6.3 (I3)
/COL_DRV_D: U2.10 (DAC_2/ADC2_CH9/GPIO26), U6.4 (I4)
/COL_DRV_E: U2.9 (DAC_1/ADC2_CH8/GPIO25), U6.5 (I5)
/COL_DRV_F: U2.8 (32K_XN/GPIO33/ADC1_CH5), U6.6 (I6)
/COL_DRV_G: U2.29 (GPIO5), U6.7 (I7)
/COL_DRV_H: U2.23 (MTDO/GPIO15/ADC2_CH3), U6.8 (I8)
/I2C_SCL: J3.4, U2.34 (U0RXD/GPIO3)
/I2C_SDA: J3.3, U2.35 (U0TXD/GPIO1)
/LED_DATA: U2.7 (32K_XP/GPIO32/ADC1_CH4), U3.2
/LED_DATA_5V: J1.7, R11.2
/PANEL_SPARE: J3.8, U2.6 (VDET_2/GPIO35/ADC1_CH7)
/PANEL_SPARE2: J3.9
/S0: J1.9, R1.2, U2.26 (ADC2_CH0/GPIO4)
/S1: J1.10, R2.2, U2.27 (GPIO16)
/S2: J1.11, R3.2, U2.28 (GPIO17)
/S3: J1.12, R4.2, U2.30 (GPIO18)
/S4: J1.13, R5.2, U2.31 (GPIO19)
/S5: J1.14, R6.2, U2.33 (GPIO21)
/S6: J1.15, R7.2, U2.36 (GPIO22)
/S7: J1.16, R8.2, U2.37 (GPIO23)
/VBAT_MON: C12.1, R14.2, R15.1, U2.5 (VDET_1/GPIO34/ADC1_CH6)
GND: C1.2, C2.2, C5.2, C11.2, C12.2, J1.2, J1.4, J1.6, J1.8, J1.26, J3.2, J3.10, M1.3, M1.5, M1.7, R15.2, U2.14 (GND), U2.32 (GND), U2.38 (GND), U3.1, U3.4, U3.5, U3.7 (GND), U3.9, U3.10, U3.12, U3.13, U6.10 (GND)
unnamed: D2.1 (K), U2.19 (5V)
unnamed: R11.1, U3.3

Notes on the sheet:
OpenChess — Controller Board
Controller PCB: power, ESP32, row pullups, column drivers, LED data, user UI
J_MAIN — MATRIX CONNECTOR
2x13 connector matching matrix J_CTRL +5V_LED, GND, S0..S7, CA..CH_PWR, LED_DATA_5V
ROW PULLUPS
R1..R8 — 10k S0..S7 pulled to +3.3V on controller Hall outputs are open-collector
ESP32 / LOGIC
U2 ESP32-DevKitC v4 / UART0 (GPIO1/3) repurposed as I²C / Flash pins + extras → NC
POWER
M1 Lipo Rider Plus (USB-C) / → +5V_LED + +3V3 rails / LiPo battery via M1 JST / D2 Schottky → DevKit pin 19
COLUMN DRIVERS
U6 TBD62783A 8-channel / high-side P-MOSFET driver IC / COL_DRV_A..H → CA..CH_PWR
LED DATA LEVEL SHIFT
U3 74AHCT125 quad buffer / Gate A active, B/C/D tied off / R11 33Ω series on output
USER UI CONNECTOR
J3 JST XH 10-pin / → OLED + 3 panel-mount buttons / via flying-lead harness (no panel PCB)
TEST + MECHANICAL
Testpoints for rails, matrix connector nets, drivers 4x M3 mounting holes 3x fiducials for assembly

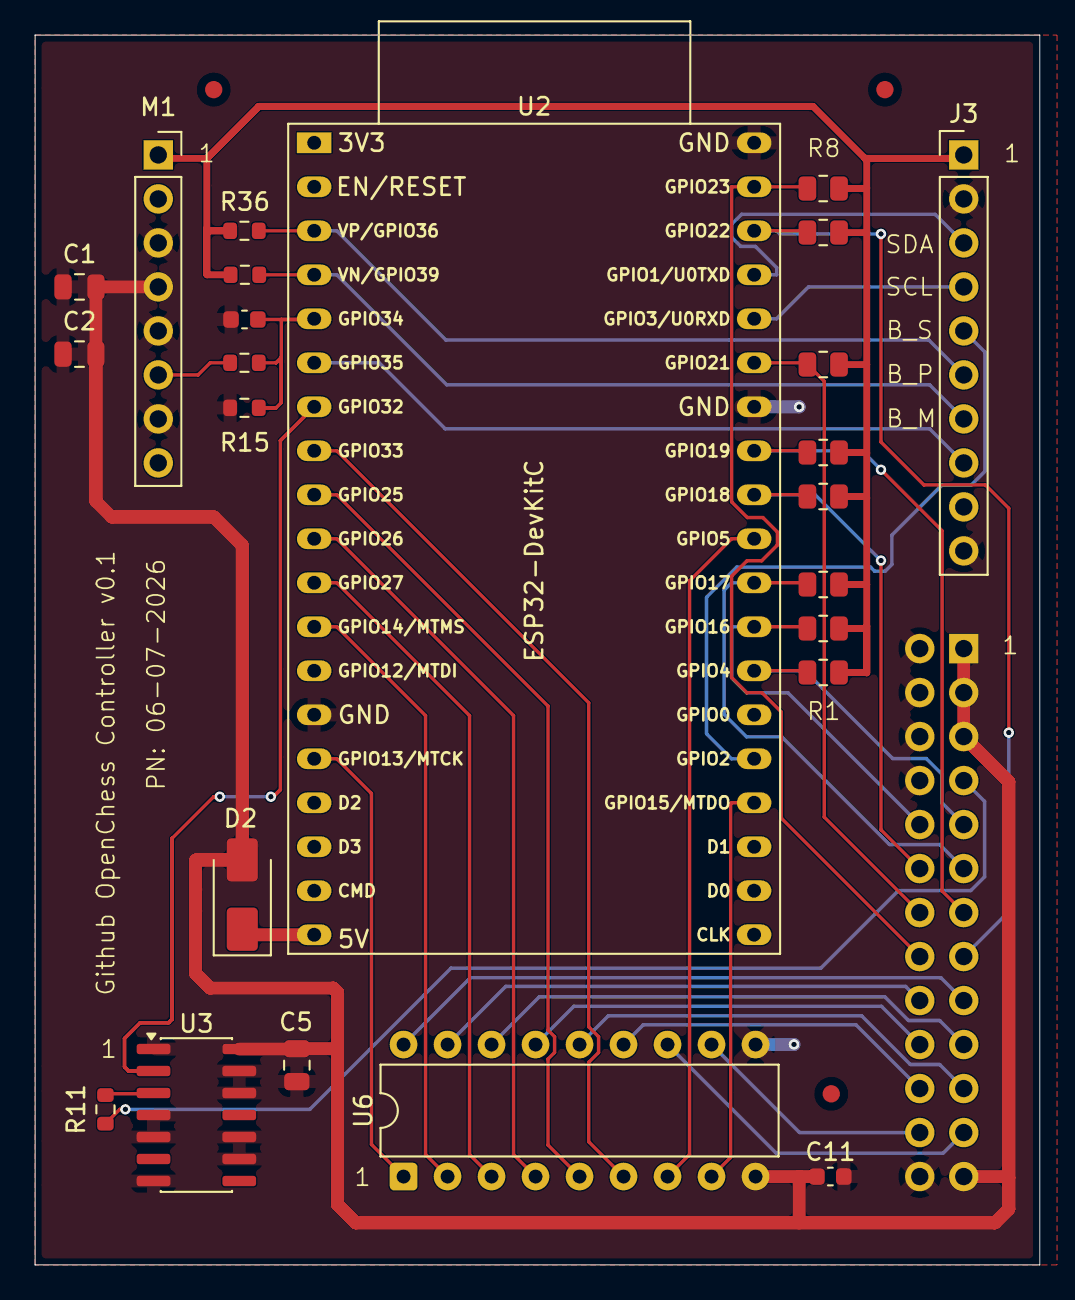
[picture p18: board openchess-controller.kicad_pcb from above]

Board: 2 copper layers, 58.0 x 71.0 mm, 28 parts (1 on the bottom side), 39 nets.

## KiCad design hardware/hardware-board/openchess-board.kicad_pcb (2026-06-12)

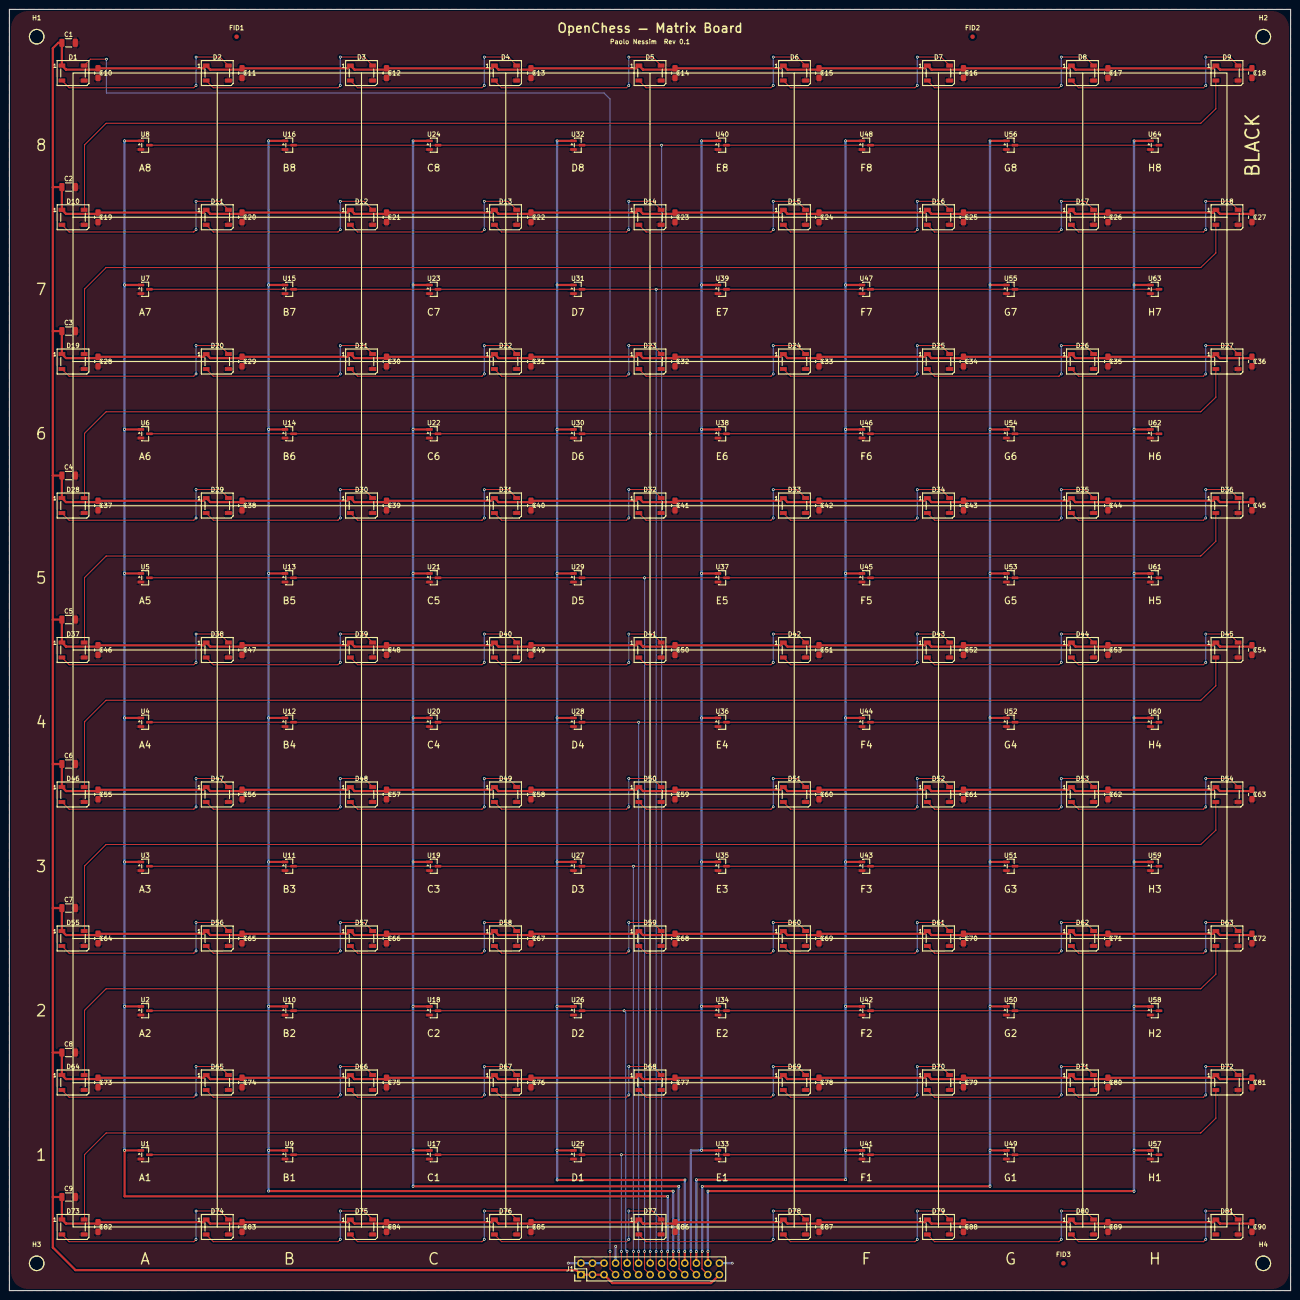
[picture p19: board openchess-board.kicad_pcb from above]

Board: 2 copper layers, 282.0 x 282.0 mm, 243 parts (1 on the bottom side), 99 nets.

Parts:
C1, C2, C3, C4, C5, C6, C7, C8, C9: 47uF; C_1206_3216Metric
C10, C11, C12, C13, C14, C15, C16, C17, C18, C19, C20, C21, C22, C23, C24, C25, C26, C27, C28, C29, C30, C31, C32, C33, C34, C35, C36, C37, C38, C39, C40, C41, C42, C43, C44, C45, C46, C47, C48, C49, C50, C51, C52, C53, C54, C55, C56, C57, C58, C59, C60, C61, C62, C63, C64, C65, C66, C67, C68, C69, C70, C71, C72, C73, C74, C75, C76, C77, C78, C79, C80, C81, C82, C83, C84, C85, C86, C87, C88, C89, C90: 100nF; C_0805_2012Metric_Pad1.18x1.45mm_HandSolder
D1, D2, D3, D4, D5, D6, D7, D8, D9, D10, D11, D12, D13, D14, D15, D16, D17, D18, D19, D20, D21, D22, D23, D24, D25, D26, D27, D28, D29, D30, D31, D32, D33, D34, D35, D36, D37, D38, D39, D40, D41, D42, D43, D44, D45, D46, D47, D48, D49, D50, D51, D52, D53, D54, D55, D56, D57, D58, D59, D60, D61, D62, D63, D64, D65, D66, D67, D68, D69, D70, D71, D72, D73, D74, D75, D76, D77, D78, D79, D80, D81: WS2812B; LED_WS2812B_PLCC4_5.0x5.0mm_P3.2mm
FID1, FID2, FID3: Fiducial; Fiducial_1mm_Mask2mm
H1, H2, H3, H4: MountingHole; MountingHole_3.2mm_M3
J1: Conn_02x13; PinHeader_2x13_P2.54mm_Vertical
U1, U2, U3, U4, U5, U6, U7, U8, U9, U10, U11, U12, U13, U14, U15, U16, U17, U18, U19, U20, U21, U22, U23, U24, U25, U26, U27, U28, U29, U30, U31, U32, U33, U34, U35, U36, U37, U38, U39, U40, U41, U42, U43, U44, U45, U46, U47, U48, U49, U50, U51, U52, U53, U54, U55, U56, U57, U58, U59, U60, U61, U62, U63, U64: DRV5032FC; SOT-23

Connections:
+5V_LED: C1.1, C2.1, C3.1, C4.1, C5.1, C6.1, C7.1, C8.1, C9.1, C10.1, C11.1, C12.1, C13.1, C14.1, C15.1, C16.1, C17.1, C18.1, C19.1, C20.1, C21.1, C22.1, C23.1, C24.1, C25.1, C26.1, C27.1, C28.1, C29.1, C30.1, C31.1, C32.1, C33.1, C34.1, C35.1, C36.1, C37.1, C38.1, C39.1, C40.1, C41.1, C42.1, C43.1, C44.1, C45.1, C46.1, C47.1, C48.1, C49.1, C50.1, C51.1, C52.1, C53.1, C54.1, C55.1, C56.1, C57.1, C58.1, C59.1, C60.1, C61.1, C62.1, C63.1, C64.1, C65.1, C66.1, C67.1, C68.1, C69.1, C70.1, C71.1, C72.1, C73.1, C74.1, C75.1, C76.1, C77.1, C78.1, C79.1, C80.1, C81.1, C82.1, C83.1, C84.1, C85.1, C86.1, C87.1, C88.1, C89.1, C90.1, D1.1 (VDD), D2.1 (VDD), D3.1 (VDD), D4.1 (VDD), D5.1 (VDD), D6.1 (VDD), D7.1 (VDD), D8.1 (VDD), D9.1 (VDD), D10.1 (VDD), D11.1 (VDD), D12.1 (VDD), D13.1 (VDD), D14.1 (VDD), D15.1 (VDD), D16.1 (VDD), D17.1 (VDD), D18.1 (VDD), D19.1 (VDD), D20.1 (VDD), D21.1 (VDD), D22.1 (VDD), D23.1 (VDD), D24.1 (VDD), D25.1 (VDD), D26.1 (VDD), D27.1 (VDD), D28.1 (VDD), D29.1 (VDD), D30.1 (VDD), D31.1 (VDD), D32.1 (VDD), D33.1 (VDD), D34.1 (VDD), D35.1 (VDD), D36.1 (VDD), D37.1 (VDD), D38.1 (VDD), D39.1 (VDD), D40.1 (VDD), D41.1 (VDD), D42.1 (VDD), D43.1 (VDD), D44.1 (VDD), D45.1 (VDD), D46.1 (VDD), D47.1 (VDD), D48.1 (VDD), D49.1 (VDD), D50.1 (VDD), D51.1 (VDD), D52.1 (VDD), D53.1 (VDD), D54.1 (VDD), D55.1 (VDD), D56.1 (VDD), D57.1 (VDD), D58.1 (VDD), D59.1 (VDD), D60.1 (VDD), D61.1 (VDD), D62.1 (VDD), D63.1 (VDD), D64.1 (VDD), D65.1 (VDD), D66.1 (VDD), D67.1 (VDD), D68.1 (VDD), D69.1 (VDD), D70.1 (VDD), D71.1 (VDD), D72.1 (VDD), D73.1 (VDD), D74.1 (VDD), D75.1 (VDD), D76.1 (VDD), D77.1 (VDD), D78.1 (VDD), D79.1 (VDD), D80.1 (VDD), D81.1 (VDD), J1.1, J1.3, J1.5, J1.25
/CA_PWR: J1.17, U1.1 (VCC), U2.1 (VCC), U3.1 (VCC), U4.1 (VCC), U5.1 (VCC), U6.1 (VCC), U7.1 (VCC), U8.1 (VCC)
/CB_PWR: J1.18, U9.1 (VCC), U10.1 (VCC), U11.1 (VCC), U12.1 (VCC), U13.1 (VCC), U14.1 (VCC), U15.1 (VCC), U16.1 (VCC)
/CC_PWR: J1.19, U17.1 (VCC), U18.1 (VCC), U19.1 (VCC), U20.1 (VCC), U21.1 (VCC), U22.1 (VCC), U23.1 (VCC), U24.1 (VCC)
/CD_PWR: J1.20, U25.1 (VCC), U26.1 (VCC), U27.1 (VCC), U28.1 (VCC), U29.1 (VCC), U30.1 (VCC), U31.1 (VCC), U32.1 (VCC)
/CE_PWR: J1.21, U33.1 (VCC), U34.1 (VCC), U35.1 (VCC), U36.1 (VCC), U37.1 (VCC), U38.1 (VCC), U39.1 (VCC), U40.1 (VCC)
/CF_PWR: J1.22, U41.1 (VCC), U42.1 (VCC), U43.1 (VCC), U44.1 (VCC), U45.1 (VCC), U46.1 (VCC), U47.1 (VCC), U48.1 (VCC)
/CG_PWR: J1.23, U49.1 (VCC), U50.1 (VCC), U51.1 (VCC), U52.1 (VCC), U53.1 (VCC), U54.1 (VCC), U55.1 (VCC), U56.1 (VCC)
/CH_PWR: J1.24, U57.1 (VCC), U58.1 (VCC), U59.1 (VCC), U60.1 (VCC), U61.1 (VCC), U62.1 (VCC), U63.1 (VCC), U64.1 (VCC)
/L9: D9.2 (DOUT), D10.4 (DIN)
/L18: D18.2 (DOUT), D19.4 (DIN)
/L27: D27.2 (DOUT), D28.4 (DIN)
/L36: D36.2 (DOUT), D37.4 (DIN)
/L45: D45.2 (DOUT), D46.4 (DIN)
/L54: D54.2 (DOUT), D55.4 (DIN)
/L63: D63.2 (DOUT), D64.4 (DIN)
/L72: D72.2 (DOUT), D73.4 (DIN)
/LED_DATA_5V: D1.4 (DIN), J1.7
/S0: J1.9, U1.3 (OUT), U9.3 (OUT), U17.3 (OUT), U25.3 (OUT), U33.3 (OUT), U41.3 (OUT), U49.3 (OUT), U57.3 (OUT)
/S1: J1.10, U2.3 (OUT), U10.3 (OUT), U18.3 (OUT), U26.3 (OUT), U34.3 (OUT), U42.3 (OUT), U50.3 (OUT), U58.3 (OUT)
/S2: J1.11, U3.3 (OUT), U11.3 (OUT), U19.3 (OUT), U27.3 (OUT), U35.3 (OUT), U43.3 (OUT), U51.3 (OUT), U59.3 (OUT)
/S3: J1.12, U4.3 (OUT), U12.3 (OUT), U20.3 (OUT), U28.3 (OUT), U36.3 (OUT), U44.3 (OUT), U52.3 (OUT), U60.3 (OUT)
/S4: J1.13, U5.3 (OUT), U13.3 (OUT), U21.3 (OUT), U29.3 (OUT), U37.3 (OUT), U45.3 (OUT), U53.3 (OUT), U61.3 (OUT)
/S5: J1.14, U6.3 (OUT), U14.3 (OUT), U22.3 (OUT), U30.3 (OUT), U38.3 (OUT), U46.3 (OUT), U54.3 (OUT), U62.3 (OUT)
/S6: J1.15, U7.3 (OUT), U15.3 (OUT), U23.3 (OUT), U31.3 (OUT), U39.3 (OUT), U47.3 (OUT), U55.3 (OUT), U63.3 (OUT)
/S7: J1.16, U8.3 (OUT), U16.3 (OUT), U24.3 (OUT), U32.3 (OUT), U40.3 (OUT), U48.3 (OUT), U56.3 (OUT), U64.3 (OUT)
GND: C1.2, C2.2, C3.2, C4.2, C5.2, C6.2, C7.2, C8.2, C9.2, C10.2, C11.2, C12.2, C13.2, C14.2, C15.2, C16.2, C17.2, C18.2, C19.2, C20.2, C21.2, C22.2, C23.2, C24.2, C25.2, C26.2, C27.2, C28.2, C29.2, C30.2, C31.2, C32.2, C33.2, C34.2, C35.2, C36.2, C37.2, C38.2, C39.2, C40.2, C41.2, C42.2, C43.2, C44.2, C45.2, C46.2, C47.2, C48.2, C49.2, C50.2, C51.2, C52.2, C53.2, C54.2, C55.2, C56.2, C57.2, C58.2, C59.2, C60.2, C61.2, C62.2, C63.2, C64.2, C65.2, C66.2, C67.2, C68.2, C69.2, C70.2, C71.2, C72.2, C73.2, C74.2, C75.2, C76.2, C77.2, C78.2, C79.2, C80.2, C81.2, C82.2, C83.2, C84.2, C85.2, C86.2, C87.2, C88.2, C89.2, C90.2, D1.3 (VSS), D2.3 (VSS), D3.3 (VSS), D4.3 (VSS), D5.3 (VSS), D6.3 (VSS), D7.3 (VSS), D8.3 (VSS), D9.3 (VSS), D10.3 (VSS), D11.3 (VSS), D12.3 (VSS), D13.3 (VSS), D14.3 (VSS), D15.3 (VSS), D16.3 (VSS), D17.3 (VSS), D18.3 (VSS), D19.3 (VSS), D20.3 (VSS), D21.3 (VSS), D22.3 (VSS), D23.3 (VSS), D24.3 (VSS), D25.3 (VSS), D26.3 (VSS), D27.3 (VSS), D28.3 (VSS), D29.3 (VSS), D30.3 (VSS), D31.3 (VSS), D32.3 (VSS), D33.3 (VSS), D34.3 (VSS), D35.3 (VSS), D36.3 (VSS), D37.3 (VSS), D38.3 (VSS), D39.3 (VSS), D40.3 (VSS), D41.3 (VSS), D42.3 (VSS), D43.3 (VSS), D44.3 (VSS), D45.3 (VSS), D46.3 (VSS), D47.3 (VSS), D48.3 (VSS), D49.3 (VSS), D50.3 (VSS), D51.3 (VSS), D52.3 (VSS), D53.3 (VSS), D54.3 (VSS), D55.3 (VSS), D56.3 (VSS), D57.3 (VSS), D58.3 (VSS), D59.3 (VSS), D60.3 (VSS), D61.3 (VSS), D62.3 (VSS), D63.3 (VSS), D64.3 (VSS), D65.3 (VSS), D66.3 (VSS), D67.3 (VSS), D68.3 (VSS), D69.3 (VSS), D70.3 (VSS), D71.3 (VSS), D72.3 (VSS), D73.3 (VSS), D74.3 (VSS), D75.3 (VSS), D76.3 (VSS), D77.3 (VSS), D78.3 (VSS), D79.3 (VSS), D80.3 (VSS), D81.3 (VSS), J1.2, J1.4, J1.6, J1.8, J1.26, U1.2 (GND), U2.2 (GND), U3.2 (GND), U4.2 (GND), U5.2 (GND), U6.2 (GND), U7.2 (GND), U8.2 (GND), U9.2 (GND), U10.2 (GND), U11.2 (GND), U12.2 (GND), U13.2 (GND), U14.2 (GND), U15.2 (GND), U16.2 (GND), U17.2 (GND), U18.2 (GND), U19.2 (GND), U20.2 (GND), U21.2 (GND), U22.2 (GND), U23.2 (GND), U24.2 (GND), U25.2 (GND), U26.2 (GND), U27.2 (GND), U28.2 (GND), U29.2 (GND), U30.2 (GND), U31.2 (GND), U32.2 (GND), U33.2 (GND), U34.2 (GND), U35.2 (GND), U36.2 (GND), U37.2 (GND), U38.2 (GND), U39.2 (GND), U40.2 (GND), U41.2 (GND), U42.2 (GND), U43.2 (GND), U44.2 (GND), U45.2 (GND), U46.2 (GND), U47.2 (GND), U48.2 (GND), U49.2 (GND), U50.2 (GND), U51.2 (GND), U52.2 (GND), U53.2 (GND), U54.2 (GND), U55.2 (GND), U56.2 (GND), U57.2 (GND), U58.2 (GND), U59.2 (GND), U60.2 (GND), U61.2 (GND), U62.2 (GND), U63.2 (GND), U64.2 (GND)
unnamed: D1.2 (DOUT), D2.4 (DIN)
unnamed: D2.2 (DOUT), D3.4 (DIN)
unnamed: D3.2 (DOUT), D4.4 (DIN)
unnamed: D4.2 (DOUT), D5.4 (DIN)
unnamed: D5.2 (DOUT), D6.4 (DIN)
unnamed: D6.2 (DOUT), D7.4 (DIN)
unnamed: D7.2 (DOUT), D8.4 (DIN)
unnamed: D8.2 (DOUT), D9.4 (DIN)
unnamed: D10.2 (DOUT), D11.4 (DIN)
unnamed: D11.2 (DOUT), D12.4 (DIN)
unnamed: D12.2 (DOUT), D13.4 (DIN)
unnamed: D13.2 (DOUT), D14.4 (DIN)
unnamed: D14.2 (DOUT), D15.4 (DIN)
unnamed: D15.2 (DOUT), D16.4 (DIN)
unnamed: D16.2 (DOUT), D17.4 (DIN)
unnamed: D17.2 (DOUT), D18.4 (DIN)
unnamed: D19.2 (DOUT), D20.4 (DIN)
unnamed: D20.2 (DOUT), D21.4 (DIN)
unnamed: D21.2 (DOUT), D22.4 (DIN)
unnamed: D22.2 (DOUT), D23.4 (DIN)
unnamed: D23.2 (DOUT), D24.4 (DIN)
unnamed: D24.2 (DOUT), D25.4 (DIN)
unnamed: D25.2 (DOUT), D26.4 (DIN)
unnamed: D26.2 (DOUT), D27.4 (DIN)
unnamed: D28.2 (DOUT), D29.4 (DIN)
unnamed: D29.2 (DOUT), D30.4 (DIN)
unnamed: D30.2 (DOUT), D31.4 (DIN)
unnamed: D31.2 (DOUT), D32.4 (DIN)
unnamed: D32.2 (DOUT), D33.4 (DIN)
unnamed: D33.2 (DOUT), D34.4 (DIN)
unnamed: D34.2 (DOUT), D35.4 (DIN)
unnamed: D35.2 (DOUT), D36.4 (DIN)
unnamed: D37.2 (DOUT), D38.4 (DIN)
unnamed: D38.2 (DOUT), D39.4 (DIN)
unnamed: D39.2 (DOUT), D40.4 (DIN)
unnamed: D40.2 (DOUT), D41.4 (DIN)
unnamed: D41.2 (DOUT), D42.4 (DIN)
unnamed: D42.2 (DOUT), D43.4 (DIN)
unnamed: D43.2 (DOUT), D44.4 (DIN)
unnamed: D44.2 (DOUT), D45.4 (DIN)
unnamed: D46.2 (DOUT), D47.4 (DIN)
unnamed: D47.2 (DOUT), D48.4 (DIN)
unnamed: D48.2 (DOUT), D49.4 (DIN)
unnamed: D49.2 (DOUT), D50.4 (DIN)
unnamed: D50.2 (DOUT), D51.4 (DIN)
unnamed: D51.2 (DOUT), D52.4 (DIN)
unnamed: D52.2 (DOUT), D53.4 (DIN)
unnamed: D53.2 (DOUT), D54.4 (DIN)
unnamed: D55.2 (DOUT), D56.4 (DIN)
unnamed: D56.2 (DOUT), D57.4 (DIN)
unnamed: D57.2 (DOUT), D58.4 (DIN)
unnamed: D58.2 (DOUT), D59.4 (DIN)
unnamed: D59.2 (DOUT), D60.4 (DIN)
unnamed: D60.2 (DOUT), D61.4 (DIN)
unnamed: D61.2 (DOUT), D62.4 (DIN)
unnamed: D62.2 (DOUT), D63.4 (DIN)
unnamed: D64.2 (DOUT), D65.4 (DIN)
unnamed: D65.2 (DOUT), D66.4 (DIN)
unnamed: D66.2 (DOUT), D67.4 (DIN)
unnamed: D67.2 (DOUT), D68.4 (DIN)
unnamed: D68.2 (DOUT), D69.4 (DIN)
unnamed: D69.2 (DOUT), D70.4 (DIN)
unnamed: D70.2 (DOUT), D71.4 (DIN)
unnamed: D71.2 (DOUT), D72.4 (DIN)
unnamed: D73.2 (DOUT), D74.4 (DIN)
unnamed: D74.2 (DOUT), D75.4 (DIN)
unnamed: D75.2 (DOUT), D76.4 (DIN)
unnamed: D76.2 (DOUT), D77.4 (DIN)
unnamed: D77.2 (DOUT), D78.4 (DIN)
unnamed: D78.2 (DOUT), D79.4 (DIN)
unnamed: D79.2 (DOUT), D80.4 (DIN)
unnamed: D80.2 (DOUT), D81.4 (DIN)

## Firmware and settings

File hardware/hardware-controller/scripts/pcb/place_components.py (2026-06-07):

"""
OpenChess controller — PCB component placement script.

Gives you a clean, compact starting layout for the controller board. You
edit the LAYOUT dict at the top, re-run, see the result, repeat.

HOW TO RUN
----------

Option A — inside KiCad (recommended while iterating):

    1. Open hardware/hardware-controller/openchess-controller.kicad_pcb
       in KiCad's PCB Editor.
    2. Tools → Scripting Console (or press the terminal icon).
    3. In the console:
         exec(open('/Users/paolonessim/Projects/openchess/hardware/hardware-controller/scripts/pcb/place_components.py').read())
    4. Components snap to their new positions. Inspect, then File → Save
       if you like it.

Option B — standalone (one-shot):

    cd hardware/hardware-controller
    python3 scripts/pcb/place_components.py
    # the script writes openchess-controller.kicad_pcb in place.

LAYOUT PHILOSOPHY
-----------------

Board is 80 × 95 mm, organized into 4 horizontal zones:

    y = 0  ┌──────────────────────────────────────────┐
           │ MH1                                  MH2 │
    y = 8  ├──────────────────────────────────────────┤
           │ POWER ZONE                               │
           │   M1 (Lipo Rider Plus)  USB-C at left    │
           │   C1 C2 bulk caps · D2 Schottky          │
           │   R14 R15 C12 (battery monitor divider)  │
    y = 40 ├──────────────────────────────────────────┤
           │ CPU ZONE                                 │
           │   U2 (ESP32-DevKitC socket, horizontal)  │
           │   µUSB end at right edge for programming │
    y = 72 ├──────────────────────────────────────────┤
           │ INTERFACE ZONE                           │
           │   U6 (col driver) U3 (level shifter)     │
           │   R1..R8 row pullups · R11               │
           │   R36 R37 button pullups · J3 (JST XH)   │
    y = 87 ├──────────────────────────────────────────┤
           │ MH3                                  MH4 │
    y = 95 └──────────────────────────────────────────┘

    J1 (J_MAIN, 2×13 IDC) lives on the BOTTOM layer, centered under the
    CPU zone, so it mates with J_CTRL on the matrix PCB sitting above.

Each component's (x, y) is its CENTER in mm. Tweak any number, re-run.
Components that aren't in LAYOUT keep their current position.
"""

import os
import sys

try:
    import pcbnew
except ImportError:
    sys.exit("pcbnew module not found — run inside KiCad's Scripting Console "
             "or with the python that ships with KiCad.")


# ============================================================================
# CONFIG
# ============================================================================

# Path to the controller board. Used only in standalone mode (Option B).
# In KiCad console mode the currently open board is used.
HERE = os.path.dirname(os.path.abspath(__file__))
BOARD_PATH = os.path.normpath(os.path.join(HERE, "..", "..", "openchess-controller.kicad_pcb"))

# Board outline (mm). Drawn automatically on Edge.Cuts if DRAW_OUTLINE = True.
# Sized for the ESP32-DevKitC (~54 mm wide when horizontal), M1 (~46×26 mm),
# J_MAIN (~34 mm horizontal) and J_PANEL (~26 mm horizontal).
BOARD_W = 95.0
BOARD_H = 105.0
DRAW_OUTLINE = True

# If True, each (x, y) is interpreted as the desired CENTER of the footprint's
# bounding box. We compensate for the footprint's anchor (usually pin 1) by
# measuring the post-rotation bbox and shifting the anchor so the body center
# lands at the target. Leave True — it's what makes the layout sensible.
CENTER_ON_BBOX = True


# ============================================================================
# LAYOUT
# ============================================================================
#
# Each entry: refdes → { pos: (x_mm, y_mm), rot: deg, side: "top" | "bottom" }
#
# (x, y) is the component CENTER. Origin (0, 0) is top-left of the board.
# rot is degrees CCW. side flips the footprint to the bottom copper layer.

LAYOUT = {
    # ----------------- MOUNTING (corners, M3) ----------------------------
    "MH1": {"pos": (5,         5),         "rot": 0,   "side": "top"},
    "MH2": {"pos": (BOARD_W-5, 5),         "rot": 0,   "side": "top"},
    "MH3": {"pos": (5,         BOARD_H-5), "rot": 0,   "side": "top"},
    "MH4": {"pos": (BOARD_W-5, BOARD_H-5), "rot": 0,   "side": "top"},

    # ----------------- POWER ZONE (y = 12 .. 42) -------------------------
    # M1 Lipo Rider Plus (~46 × 26 mm). Long axis horizontal. USB-C on
    # the left short edge → faces the LEFT side of the board so the
    # panel-mount extension cable can reach the enclosure wall.
    "M1":  {"pos": (28, 28),  "rot": 0,   "side": "top"},

    # Bulk caps on +5V_LED, just to the right of M1's 5 V output.
    "C1":  {"pos": (58, 18),  "rot": 0,   "side": "top"},
    "C2":  {"pos": (63, 18),  "rot": 0,   "side": "top"},

    # D2 SS14 Schottky: anode on +5V_LED, cathode to DevKit pin 19.
    "D2":  {"pos": (70, 22),  "rot": 0,   "side": "top"},

    # Battery monitor divider on M1 pin 6 (BAT) → VBAT_MON → GPIO34.
    "R14": {"pos": (58, 33),  "rot": 0,   "side": "top"},
    "R15": {"pos": (63, 33),  "rot": 0,   "side": "top"},
    "C12": {"pos": (70, 33),  "rot": 0,   "side": "top"},

    # ----------------- CPU ZONE (y = 48 .. 76) ---------------------------
    # ESP32-DevKitC v4 in a 2 × 19 socket pair. The footprint is naturally
    # tall (28.5 × 54 mm), so we rotate 90° → 54 × 28.5 mm horizontal.
    # µUSB end is at one of the short edges; tweak rot (90 vs 270) if it
    # comes out facing the wrong way.
    "U2":  {"pos": (45, 62),  "rot": 90,  "side": "top"},

    # ----------------- INTERFACE ZONE (y = 80 .. 100) --------------------
    # J1 (J_MAIN, 2 × 13 keyed IDC) on the BOTTOM layer, rotated horizontal
    # so its 34 mm long axis lies along X. Mates with J_CTRL on the matrix
    # PCB sitting above (board-to-board stack).
    "J1":  {"pos": (45, 81),  "rot": 90,  "side": "bottom"},

    # U6 TBD62783A column driver — DIP-18, naturally ~23 mm tall. Rotate
    # 90° so it lies horizontal. Outputs drop straight down into J1 below.
    "U6":  {"pos": (16, 90),  "rot": 90,  "side": "top"},
    "C11": {"pos": (16, 99),  "rot": 0,   "side": "top"},

    # U3 74AHCT125 level shifter — small enough to leave at rot 0.
    "U3":  {"pos": (33, 89),  "rot": 0,   "side": "top"},
    "C5":  {"pos": (33, 96),  "rot": 0,   "side": "top"},
    "R11": {"pos": (39, 89),  "rot": 0,   "side": "top"},

    # R1..R8 row pullups — tight 2 × 4 grid, between U3 and J_PANEL pullups.
    "R1":  {"pos": (44, 86),  "rot": 0,   "side": "top"},
    "R2":  {"pos": (44, 89),  "rot": 0,   "side": "top"},
    "R3":  {"pos": (44, 92),  "rot": 0,   "side": "top"},
    "R4":  {"pos": (44, 95),  "rot": 0,   "side": "top"},
    "R5":  {"pos": (47, 86),  "rot": 0,   "side": "top"},
    "R6":  {"pos": (47, 89),  "rot": 0,   "side": "top"},
    "R7":  {"pos": (47, 92),  "rot": 0,   "side": "top"},
    "R8":  {"pos": (47, 95),  "rot": 0,   "side": "top"},

    # Button pullups close to J_PANEL.
    "R36": {"pos": (51, 87),  "rot": 0,   "side": "top"},
    "R37": {"pos": (51, 93),  "rot": 0,   "side": "top"},

    # J3 (J_PANEL, JST XH 10) — horizontal (rot 90 because this footprint's
    # natural orientation is vertical). Centered so it clears MH4 in x.
    # Harness exits toward the enclosure side wall.
    "J3":  {"pos": (68, 90),  "rot": 90,  "side": "top"},
}


# ============================================================================
# IMPLEMENTATION
# ============================================================================

def mm(x, y):
    """Convert (x_mm, y_mm) → KiCad internal VECTOR2I."""
    return pcbnew.VECTOR2I(pcbnew.FromMM(float(x)), pcbnew.FromMM(float(y)))


def place(board, ref, x, y, rot_deg, side):
    fp = board.FindFootprintByReference(ref)
    if fp is None:
        print(f"  WARN: {ref:5s} not found in board — skipped")
        return False

    # 1. flip to the target side first (so bbox reflects final geometry)
    on_back = fp.GetLayer() == pcbnew.B_Cu
    want_back = (side == "bottom")
    if on_back != want_back:
        fp.Flip(fp.GetPosition(), False)  # mirror around Y axis (X flip)

    # 2. rotate
    fp.SetOrientationDegrees(float(rot_deg))

    # 3. move anchor to the requested target, then adjust so the BODY CENTER
    #    (not the pin-1 anchor) lands at the target. Use the footprint's
    #    bounding box for "body center".
    target = mm(x, y)
    fp.SetPosition(target)

    if CENTER_ON_BBOX:
        bbox = fp.GetBoundingBox(False, False)  # exclude text
        bbox_center = bbox.GetCenter()
        anchor = fp.GetPosition()
        # Body is currently centered at bbox_center, anchor is at `target`.
        # Shift anchor by (target - bbox_center) so body center reaches target.
        dx = target.x - bbox_center.x
        dy = target.y - bbox_center.y
        fp.SetPosition(pcbnew.VECTOR2I(anchor.x + dx, anchor.y + dy))

    # actual final body-center, for the log line
    final_bbox = fp.GetBoundingBox(False, False)
    fc = final_bbox.GetCenter()
    fcx_mm = pcbnew.ToMM(fc.x)
    fcy_mm = pcbnew.ToMM(fc.y)
    w_mm = pcbnew.ToMM(final_bbox.GetWidth())
    h_mm = pcbnew.ToMM(final_bbox.GetHeight())

    print(f"  OK   {ref:5s}  body center ({fcx_mm:5.1f}, {fcy_mm:5.1f})  "
          f"size {w_mm:4.1f}×{h_mm:4.1f}  rot {rot_deg:>3}°  {side}")
    return True


def draw_outline(board, w, h):
    """Replace any existing Edge.Cuts segments with a clean W×H rectangle."""
    edge_layer = pcbnew.Edge_Cuts
    to_remove = []
    for drawing in board.GetDrawings():
        if drawing.GetLayer() == edge_layer:
            to_remove.append(drawing)
    for d in to_remove:
        board.Remove(d)

    corners = [(0, 0), (w, 0), (w, h), (0, h), (0, 0)]
    for (x1, y1), (x2, y2) in zip(corners, corners[1:]):
        seg = pcbnew.PCB_SHAPE(board)
        seg.SetShape(pcbnew.SHAPE_T_SEGMENT)
        seg.SetStart(mm(x1, y1))
        seg.SetEnd(mm(x2, y2))
        seg.SetLayer(edge_layer)
        seg.SetWidth(pcbnew.FromMM(0.15))
        board.Add(seg)
    print(f"  Edge.Cuts rectangle drawn: {w} × {h} mm")


def main():
    running_in_kicad = (pcbnew.GetBoard() is not None
                        and pcbnew.GetBoard().GetFileName() != "")

    if running_in_kicad:
        board = pcbnew.GetBoard()
        print(f"Using open board: {board.GetFileName()}")
    else:
        print(f"Loading board from disk: {BOARD_PATH}")
        if not os.path.isfile(BOARD_PATH):
            sys.exit(f"  board file not found: {BOARD_PATH}")
        board = pcbnew.LoadBoard(BOARD_PATH)

    print()
    if DRAW_OUTLINE:
        print("Drawing board outline:")
        draw_outline(board, BOARD_W, BOARD_H)
        print()

    print("Placing components:")
    placed = 0
    for ref, conf in LAYOUT.items():
        x, y = conf["pos"]
        if place(board, ref, x, y, conf["rot"], conf["side"]):
            placed += 1
    print(f"\n{placed}/{len(LAYOUT)} components placed.")

    if running_in_kicad:
        pcbnew.Refresh()
        print("\nDone. Review in KiCad and File → Save when happy.")
    else:
        pcbnew.SaveBoard(BOARD_PATH, board)
        print(f"\nBoard saved: {BOARD_PATH}")


if __name__ == "__main__" or True:
    main()

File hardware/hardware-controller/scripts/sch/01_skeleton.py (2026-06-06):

#!/usr/bin/env python3
"""01_skeleton.py — page setup, title block, embedded symbols, and boxes."""
from __future__ import annotations
import sys
from pathlib import Path

sys.path.insert(0, str(Path(__file__).resolve().parent))
from _lib import emit_polyline, emit_rectangle, emit_text, assemble, uid, write_chunk, load_symbol_def, PFX_DECOR

EMBEDDED_STOCK_SYMBOLS = [
    "Device:R",
    "Device:C",
    "Connector_Generic:Conn_02x13_Odd_Even",
    "Connector:TestPoint",
    "Connector:USB_C_Receptacle_USB2.0_16P",
    "Regulator_Linear:AP2204K-1.5",   # base symbol — pins live here
    "Regulator_Linear:AP2112K-3.3",   # extends AP2204K-1.5
    "Mechanical:MountingHole",
    "Mechanical:Fiducial",
    "power:PWR_FLAG",
]

TB_TITLE = "OpenChess — Controller Board"
TB_DATE = "2026-06-04"
TB_REV = "0.1"
TB_COMPANY = "Paolo Nessim"
TB_C1 = "ESP32 controller + power + matrix scan drivers"
TB_C2 = "J_MAIN mates to matrix-board J_CTRL"

HEAD_X, HEAD_Y = 30, 28
TAGLINE_TEXT = "Controller PCB: power, ESP32, row pullups, column drivers, LED data, user UI"
BOX_TITLE_SIZE = 2.5
BOX_BODY_SIZE = 1.5

BOXES = [
    (28, 50, 135, 150, "J_MAIN — MATRIX CONNECTOR",
     "2x13 connector matching matrix J_CTRL\n+5V_LED, GND, S0..S7, CA..CH_PWR, LED_DATA_5V"),
    (145, 50, 285, 150, "ROW PULLUPS",
     "R1..R8 — 10k\nS0..S7 pulled to +3V3 on controller\nHall outputs are open-collector"),
    (295, 50, 430, 150, "ESP32 / LOGIC",
     "ESP32 module/devkit placeholder\nGPIO assignment to be locked before placement\n+3V3 logic rail"),
    (440, 50, 566, 150, "POWER",
     "USB-C 5V → +5V_LED rail\n+3V3 LDO (AP2112K-3.3, 600 mA)\nNo battery on prototype #1"),
    (28, 170, 210, 285, "COLUMN DRIVERS",
     "CA_PWR..CH_PWR switched 5V column rails\nImplementation pending: direct GPIO vs 74HC595 + transistors"),
    (220, 170, 370, 285, "LED DATA LEVEL SHIFT",
     "ESP32 data -> 5V WS2812 data\nTarget net: LED_DATA_5V\nPart choice pending"),
    (380, 170, 566, 285, "USER UI CONNECTOR",
     "Cable-mounted side controls\nStatus LEDs and buttons live off-board\nPinout pending"),
    (28, 305, 566, 400, "TEST + MECHANICAL",
     "Testpoints for rails, matrix connector nets, drivers\n4x M3 mounting holes\n3x fiducials for assembly"),
]


def main() -> int:
    out: list[str] = []
    out.append('\t(paper "A2")')
    out.append('\t(title_block')
    out.append(f'\t\t(title "{TB_TITLE}")')
    out.append(f'\t\t(date "{TB_DATE}")')
    out.append(f'\t\t(rev "{TB_REV}")')
    out.append(f'\t\t(company "{TB_COMPANY}")')
    out.append(f'\t\t(comment 1 "{TB_C1}")')
    out.append(f'\t\t(comment 2 "{TB_C2}")')
    out.append('\t)')

    out.append('\t(lib_symbols')
    for lib_id in EMBEDDED_STOCK_SYMBOLS:
        out.append(load_symbol_def(lib_id))
    out.append('\t)')

    emit_text(out, TB_TITLE, HEAD_X, HEAD_Y, 6.0, "left bottom", uid(PFX_DECOR, 1), bold=True)
    emit_text(out, TAGLINE_TEXT, HEAD_X, 37, 2.0, "left bottom", uid(PFX_DECOR, 2), italic=True)
    emit_polyline(out, 30, 42, 560, 42, uid(PFX_DECOR, 3))

    for i, (x1, y1, x2, y2, title, body) in enumerate(BOXES):
        emit_rectangle(out, x1, y1, x2, y2, uid(PFX_DECOR, 10 + i * 3))
        emit_text(out, title, x1 + 3, y1 - 2, BOX_TITLE_SIZE, "left bottom", uid(PFX_DECOR, 11 + i * 3), bold=True)
        emit_text(out, body.replace("\n", "\\n"), x1 + 4, y1 + 5, BOX_BODY_SIZE, "left top", uid(PFX_DECOR, 12 + i * 3))

    write_chunk("01_skeleton", out)
    assemble()
    return 0


if __name__ == "__main__":
    sys.exit(main())

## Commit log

2026-06-03 Initial commit: openchess board (chessboard-v2 rebuild)
    Physical chess board playing online via Lichess + offline vs Stockfish.
    ESP32 + 64 hall sensors + 81 WS2812 LEDs on a single ~280x280mm PCB.
    Firmware will fork from joojoooo/OpenChess.
    Repo follows the standard open-hardware layout (hardware/ + firmware/ +
    mechanical/ + docs/) with per-domain licenses (CERN-OHL-S v2 / upstream /
    CC-BY-4.0) and Olivier Mercier's v1 design cloned into references/.
    [freerouting.dsn, led_chain.kicad_sch, openchess.kicad_pcb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]
2026-06-05 Add scripts for PCB layout and routing: grid placement, LED chain routing, and power planes
2026-06-06 Refactor code structure for improved readability and maintainability
    [freerouting.dsn, led_chain.kicad_sch, openchess-board.kicad_sch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]
2026-06-06 Add new mechanical and power symbols for schematic integration
    - Introduced new symbols: TestPoint, Fiducial, MountingHole, +3V3, and GND.
    - Each symbol includes properties for reference, value, footprint, datasheet, description, keywords, and filters.
    - Implemented a Python script to merge test/mech snippets into the main schematic, ensuring backup and validation of parens.
    - The script adds missing symbol definitions and integrates component instances, labels, wires, and power ports.
    [openchess-board.kicad_sch, openchess-control-panel.kicad_sch, openchess-controller.kicad_pcb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]
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2026-06-07 Controller PCB: hand-routed power rails before autoroute
    [openchess-controller.kicad_pcb]
2026-06-07 Add PCB layout and schematic guides for OpenChess controller
    - Introduced `controller-PCB_LAYOUT_GUIDE.planning.md` detailing PCB layout constraints, component placement zones, net classes, routing priorities, and mechanical verification for the OpenChess cont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
    - Added `controller-SCHEMATIC_GUIDE.planning.md` providing a comprehensive schematic specification, including reference designators, net lists, component details, and validation rules for the OpenChe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
    [Sample-BOM_JLCSMT.xlsx, copy.kicad_sch, openchess-board-3x3.kicad_pcb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]
2026-06-07 Remove obsolete files and backups from hardware-controller project
    - Deleted the .history directory and its contents.
    - Removed all KiNotes markdown files and their backups.
    - Cleared settings, todos, and version log JSON files.
    - Eliminated the BOM CSV file for the openchess-controller.
    [openchess-board-3x3.kicad_pcb, openchess-board-3x3.kicad_sch, openchess-controller-bom.csv]
2026-06-09 Add initial files for openchess board project
    - Created Gerber job file for openchess board with specifications and material stackup.
    - Added backup of the KiCad PCB file before modifications.
    - Introduced STEP files for the 3x3 chess board and the main chess controller.
    - Initialized notes file for project documentation.
    [copy.kicad_sch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]
2026-06-09 Add scripts to merge and tile PDF layers for KiCad projects
    - Implemented `merge_pdf_layers.py` to overlay multiple single-page PDFs into one page, allowing for easy printing of layered designs.
    - Created `tile_pdf_to_a4.py` to split large PDFs into A4-sized tiles with configurable overlap, facilitating printing on standard home printers.
    - Both scripts require the `pypdf` library for PDF manipulation.
    [openchess-board-3x3.kicad_pcb, openchess-board-3x3.kicad_sch, openchess-board.kicad_pcb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]
2026-06-09 chore: update code structure and remove redundant sections
    [openchess-board-3x3.kicad_pcb]
2026-06-12 Add JLCPCB BOM and CPL generation scripts for OpenChess board
    - Created openchess-board-jlc-bom.csv to define unique components with their specifications for JLCPCB.
    - Created openchess-board-jlc-cpl.csv to specify the placement of components on the board.
    - Implemented make_jlc_assembly.py script to automate the generation of BOM and CPL from KiCad's exported all-pos.csv.
    - The script handles Y-axis flipping and formats output according to JLCPCB requirements.
    - Excluded mechanical components from assembly files as per JLCPCB guidelines.
    [freerouting.dsn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]
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2026-06-21 Add initial positions CSV for hardware components
    This commit introduces a new CSV file containing the designator, midpoints, rotation, and layer information for various hardware components used in the project. The data includes positions for capaci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
2026-07-06 feat(app): scaffold Expo companion app foundation
    - Expo SDK 57 + expo-router (file-based), TypeScript
    - Design tokens (theme/), Hanken Grotesk + IBM Plex Mono fonts
    - UI primitives: Screen, Text, Button, Card/DarkCard, BoardGrid, icons
    - Board transport interface + MockBoard + BoardProvider
    - chess.js board-rendering helpers
    - Welcome screen implemented; remaining 9 screens stubbed
2026-07-06 feat(app): implement all 10 companion screens against mock board
    Pair, Wi-Fi, Home, New game, Live game, Settings, Setup board,
    Game over, Analysis — built from the Claude Design source, wired with
    expo-router navigation and the MockBoard transport. Typechecks and
    bundles clean.
2026-07-06 feat(app): real BLE transport (BleBoard) matching firmware GATT
    - BleBoard implements BoardTransport over react-native-ble-plx against the
    firmware GATT service (6f00c0de-...): scan/connect/setLEDs/scanWifi/
    provisionWifi + status/move/wifiList notifications
    - bleCodec: pure JSON codec mirroring firmware ble_board.cpp (+12 unit tests)
    - createBoard selects BleBoard on dev builds, MockBoard in Expo Go/web
    - pair screen now scans + connects to a real discovered board
    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
2026-07-06 feat(app): make Wi-Fi an optional, honest skippable step
    Wi-Fi provisioning only serves online play (Lichess/Chess.com) + OTA, none
    of which exists yet, and the app runs on BLE. Drop the fake password field
    and hardcoded SSID; show the board's best-effort live scan; 'Skip for now'
    -> Home. Documents the deferred work + the iOS notification-truncation fix
    (firmware must chunk wifiList) in the BLE spec.
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2026-07-28 docs: v2 plan/spec — XH battery connector, PWR LED, adopt existing v2 dir
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2026-07-28 docs(hw): controller v2 part sourcing and power design values
    Adds SOURCING.md for hardware-controller-v2 with verified LCSC C-numbers
    (checked 2026-07-27), JLC Basic/Extended classification, stock and unit
    price for all 16 parts in the BOM, plus BQ24074 and TPS61022 design
    formulas (R_ISET, R_ILIM, EN strapping, TS disable, FB divider, inductor,
    capacitors). Dowstream schematic tasks 5–9 must read values from this file.
2026-07-28 docs(hw): controller v2 part sourcing and power design values
    - Correct R_ILIM K constant to 1610 AΩ TYP (SLUS810N Table 8.5)
    - Fix CHG LED pull-up to OUT pin per datasheet §10.2.2.4 (was SYS)
    - Upgrade red LED to C2286 KT-0603R (Basic, 5M+ stock) from Extended
    - Upgrade green LED to C12624 KT-0603G (matched maker, lower cost)
    - Clarify R_ISET: no confirmed Basic E96 C#; document 910Ω E24 fallback
    - Extended setup fee count: 12 parts (~$36/order)
2026-07-28 docs(hw): fix R_ILIM to in-spec 1.1k and correct BQ24074 doc ID
    - R_ILIM: 1.0k was below the datasheet's 1.1k valid-range minimum;
    switch to 1.1k (C22764, 0603WAF1101T5E, Basic) -> I_LIM = 1.46A
    - Update all occurrences: formula block, EN1/EN2 note, passives table,
    additional-resistors table, Basic summary
    - Fix BQ24074 header doc ID: SLUS934 -> SLUS810N Rev. N
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2026-07-28 feat(hw): v2 WROOM core schematic snippet + paste instructions
    Standalone KiCad 9 snippet (wroom_core.kicad_sch) containing the complete
    Task 5 WROOM-32E core block: U2 ESP32-WROOM-32E with +3.3V/GND power,
    C13/C14 decoupling, EN pullup (R20)+filter (C15)+button (SW_EN), IO0 boot
    button (SW_BOOT), and global labels for all 24 v2 GPIO-mapped signals.
    Verified: kicad-cli ERC parses (100 fragment warnings, EXIT 0); netlist
    exports with all 8 key nets confirmed on correct U2 pins.
2026-07-28 fix(hw): connect floating SW_EN/SW_BOOT pins in WROOM core snippet
    SW_Push pins sit at +/-5.08mm from symbol origin; switches placed at
    integer x put pins 0.08mm off the wire endpoints, leaving both boot-
    critical buttons electrically floating (zero net memberships).
    Moved SW_EN to (68.08,88) and SW_BOOT to (133.08,84) so pin 1 lands
    exactly on the existing wire; shifted each pin-2 GND stub and power
    symbol to the true pin-2 x (73.16 / 138.16). Verified: netlist now has
    SW_EN in {EN,GND}, SW_BOOT in {IO0,GND}; systematic pin-vs-wire sweep
    of all 59 pins across every symbol passes; ERC violations 100 -> 91.
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2026-07-28 fix(roarm): lazy-attach gripper servo so it stays limp at boot (no stall buzz)
2026-07-28 fix(roarm): drive gripper via core LEDC instead of ESP32Servo (timer clash caused violent jitter)
2026-07-28 fix(roarm): widen gripper pulse band to 500-2500us for MS18 full travel
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2026-07-29 feat(hw): task 6 USB/CH340C wiring guide + contract check
    Adds beginner-friendly GUI wiring guide (task6_usb_wiring.md) covering
    USB-C receptacle J4, CH340C U7, DevKitC-style auto-program Q1/Q2/R23/R24,
    and optional USBLC6-2SC6 ESD protection. Includes ASCII sketches, exact
    pin maps grepped from installed KiCad 10 libraries, and explicit TXD/RXD
    crossover warning. Adds check_task6.py (45 assertions) that exports the
    netlist and verifies the full Task 6 net contract; pre-wiring run reports
    11/45 OK (WROOM core nets present) and 34/45 FAIL (Task 6 parts not yet
    placed — expected baseline).
2026-07-29 fix(hw): task 6 guide — remove leaked working-notes, fix sketch and pin table
    Review fixes to task6_usb_wiring.md:
    - Deleted the incorrect initial Q1 placement block ("Wait — re-read the
    task brief" self-correction) that showed Q1 emitter on the DTR rail;
    the correct Steps section is now the only Q1/Q2 instruction.
    - Deleted the first auto-program ASCII sketch whose arrows contradicted
    its comments; the exact-wire-connections diagram remains as the single
    sketch.
    - Fixed SS8050 header: inherits Q_NPN_BEC (not Q_NPN_EBC), and reworded
    the pin-map intro without working-notes phrasing.
    - Corrected CH340C pin table: pins 10/11/12 (~DSR/~RI/~DCD) and 15 (R232)
    are input type per t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
2026-07-29 feat(hw): v2 sch — power chain hand-wired (80/80); checker refs adjudicated to as-built
    R28/R29 and C17/C18 reference names landed swapped vs the guide; values sit on
    the correct nets (1.1k=ILIM, 910R=ISET, 10uF on both LDO rails). As-built names
    accepted; checker updated to match.
2026-07-29 fix(hw): v2 sch — FB divider values 750k/100k; checker now asserts component values
    R31/R32 were both 10k (boost would regulate to 1.2V, not 5V) — caught by Paolo
    visually; checker gap closed with value assertions for all power components.
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2026-07-29 feat(hw): v2 sch — ERC zero errors (PWR_FLAG on GND); schematic wiring complete
2026-07-29 feat(hw): v2 footprints and LCSC fields; docs updated to as-built panel/buttons
    - Assign footprints to all v2 symbols: ESP32-WROOM-32E (RF_Module), CH340C
    (SOIC-16), USB-C (HRO TYPE-C-31-M-12), USBLC6-2SC6 (SOT-23-6), BQ24074
    (VQFN-16-1EP 3x3mm ThermalVias), TPS61022 (Texas RWU VQFN-7 2x2mm),
    AMS1117-3.3 (SOT-223-3_TabPin2), TBD62783A (SOP-18), Q1/Q2 SS8050 (SOT-23),
    L1 APH0420T (L_APV_APH0420), D4/D5 (LED_0603), SW1 MSK12C02, SW_EN1/BOOT1
    TS-1187A, J5/J7/J8/J9 (JST XH B2B-XH-A), J6 (JST XH B4B-XH-A), new 0603 R
    and C values throughout
    - Fix U2 footprint: replace PCM_Espressif:ESP32-WROOM-32E with standard
    RF_Module:ESP32-WROOM-32E (removes ERC footprint library warning)
    - Add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
2026-07-29 fix(hw): v2 review fixes — R1-R8 LCSC to 0805 part C17414, R11 C23140, BTN_OK rename
    - R1-R8 (10k, 0805 footprints) LCSC changed C25804 -> C17414, the 0805-body
    10k from the v1 production BOM (physically validated); C25804 (0603) now
    only on R20/R23/R24/R30/R36/R37
    - R11 (33Ω 0603): add LCSC C23140 (v1-proven part)
    - docs/gpio-map.md v2 section: rename two leftover BTN_SELECT occurrences
    to BTN_OK (design-rules prose + v2 pin table, J9 noted); v1 untouched
    - ERC 0 violations; check_task6 45/45; check_task7 89/89
2026-07-29 feat(hw): task 11 placement guide + placement validator
    Adds two files for the v2 controller PCB placement task:
    - scripts/guides/task11_placement.md: step-by-step placement guide with
    ASCII floor plan, per-cluster placement rules (U2 antenna overhang,
    USB cluster, boost/charger/LDO clusters, panel connectors), KiCad
    mini-how-to, and a full placement checklist.
    - scripts/check_task11.py: placement validator that parses the saved
    .kicad_pcb s-expression and asserts proximity rules, edge distances,
    SMD layer, boundary containment, and runs kicad-cli DRC. Baseline
    test against the pre-placement PCB: 3 pass, 14 fail, 11 warn (expected).
    Board area math: 1868mm² courtyard / 4118mm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
2026-07-29 fix(hw): task 11 guide/validator — J1 stays on B.Cu, exact outline assert
    Corrections verified against the built v1 PCB:
    - J1 is DELIBERATELY on B.Cu at (103.6125, 85.418666) rot 180 (matrix
    cable plugs from the back). Guide no longer says to flip it; instead
    gives exact restore coordinates (schematic update had moved it to the
    dump clump at (122.11, 103.8) rot 90).
    - check_task11.py: new (d2) check asserts J1 position ±1mm, rot 180,
    layer B.Cu; SMD-on-F.Cu rule now applies to SMD footprints only.
    - Guide Step 0 added: draw Edge.Cuts rect with exact numbers
    (50,50)→(108,121), corner radius 3mm. Script asserts outline bounds
    ±0.5mm and FAILs explicitly when the outline is m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
2026-07-29 fix(hw): task 11 review — depth-walk outline parser, aligned thresholds
    Review fixes (1 Critical + 3 Important + 4 Minor):
    - CRITICAL: _parse_board_outline used a non-greedy regex that stopped at
    the first ')', truncating gr_rect blocks before the layer token — the
    outline was never parsed. Replaced with _extract_sexpr_blocks(), a
    paren-depth walker; gr_line fallback fixed the same way. Verified
    against the v1 PCB: returns (50,50)-(108,121).
    - J4 edge threshold 3mm → 5mm (flush edge-mount USB-C centroid sits
    ~4mm inboard); guide target (68,117) now passes.
    - Guide L1↔U10 table now "≤8mm (target: 6)" matching the script assert.
    - WROOM_HALF_H=13.3 renamed WROOM_BODY_HALF_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
2026-07-29 feat(hw): v2 net classes — POWER_FAT 1.5mm (5V_LED/VSYS/VBAT), fix stale +3V3 pattern
2026-07-29 fix(hw): task 11 validator — outline-relative checks, big-package thresholds
2026-07-29 fix(hw): task 7 checker — correct L1 boost topology contract (VSYS<->SW per TPS61022 datasheet)
    The original plan text (and thus schematic + checker) wired L1 between SW and
    +5V_LED — wrong for a boost; would have made the 5V rail dead. Checker now
    fails until the schematic fix lands.
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2026-08-11 feat(mech): front panel v3 — buttons pulled to ~7mm from screen, pins flipped away
2026-08-11 feat(mech): button holes to Ø8.4 for print tolerance
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2026-08-12 fix(mech): back cover feet pads removed (flush screws via groove later)
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2026-08-12 fix(mech): hex-nut slots opened to 6.2x3.0 for print tolerance; corner test v3
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2026-08-12 fix(mech): sandwich-screw remnants removed — solid PCB posts, plate holes filled
2026-08-12 feat(mech): PCB posts get anti-melt insert bosses (Ø4x8 pilot + Ø5.2x0.8 relief)
2026-08-12 feat(mech): USB-C held by hidden retainer blocks — clean wall, pocket fixed to fit 12mm body; corner v6
2026-08-12 fix(mech): drop USB retainer blocks — flange glued directly (snug pocket)
2026-08-12 fix(mech): USB skin re-poured clean — single port slot only; corner v7
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
